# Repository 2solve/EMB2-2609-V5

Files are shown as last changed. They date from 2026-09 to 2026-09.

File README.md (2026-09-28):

# IC2S Extension Board EBM2 V5 — 6 entradas 4-20 mA

Placa de extensão da família IC2S (2Solve), código **IC2S-EBM2-2609-V5.0**. Seis entradas analógicas de 4-20 mA
para a Universal Baseboard; **substituição directa da EBM2 V4.1** (contorno 60 × 60 mm, furação e pinagem de
`P1`/`P2` congelados). Projecto em **KiCad 10**.

## Estado (2026-09-28)

| Fase | Estado |
|---|---|
| F0/F1 — escopo e planeamento | fechadas |
| F2 — esquemático, diagrama, BOM preliminar, mapa de pinos | **Portão 1 aprovado** (pacote congelado em `Portao1_aprovado_2026-09-25`) |
| F3 — layout | contorno e placement inicial feitos (DRC 0, paridade 0); falta o Portão 3 e o roteamento |

**Alteração posterior ao Portão 1 (2026-09-28)**, trazida da revisão da EBM7 V2.3: ramo único de 24 V (saem F1, D3 e
R3), 100 nF a 50 V fora do 24 V e um só MPN de 1 µF. Detalhe em
`Documentos_…/00-Especificações_Técnicas_…/alteracoes_reuniao_2026-09-28.md` e na folha 2, notas 3, 11, 13 e 14. Também a 28-09: **U5 MCP1824ST (SOT-223) → MCP1824T-3302E/OT (SOT-23-5)**, o mesmo MPN do U4; C10 (entrada) 1 µF → 10 µF 1206, o datasheet pede 1-10 µF
(`alteracao_LDO_3V3_lado_PLC_2026-09-28.md`). O
pacote congelado do Portão 1 não foi tocado; a BOM preliminar foi regenerada (42 linhas, 123 peças montadas).

## Organização (modelo de pastas de Produtos)

```
Desenvolvimento_IC2S-EBM2-2609-V5.0/
  Arquivos_Fabricação_IC2S-EBM2-2609-V5.0/
    00-Gerbers_…            (vazio até à F3)
    01-BOM_List_…           BOM preliminar (.md/.csv) e respostas cruas da API Mouser (2026-09-25)
    02-Pick-and-Place_…     (vazio até à F3)
    03-Stencil_…            (vazio até à F3)
  Documentos_IC2S-EBM2-2609-V5.0/
    00-Especificações_Técnicas_…   escopo, intenção, planeamento, relatórios, verificações da F2, Portão 1, F3
    01-Esquemáticos_…              PDF de revisão da F2 (esquemático + diagrama + mapa de pinos), PNG e SVG por folha
    02-Pinout_…                    mapa de pinos de P1/P2/U6/U7 e regras para o firmware
    03-Diagrama_Blocos_…           diagrama de blocos (SVG)
  Projeto_IC2S-EBM2-2609-V5.0/
    IC2S_Extension_Board-EBM2_V5.kicad_pro/.kicad_sch/.kicad_pcb e as 7 folhas
    symbols/, footprints/   bibliotecas próprias do projecto (sym-lib-table e fp-lib-table relativas)
    Ferramentas/            scripts Python de geração e verificação (ERC, netlist contra a intenção, BOM, PDF, F3)
    Documentos_de_Referência-IC2S-EBM2-2609-V5.0/   lista dos datasheets usados (nome e md5)
```

## O que não está neste repositório, e porquê

- **Datasheets dos fabricantes**: não se redistribuem num repositório público. `LISTA_datasheets.md` dá o nome e o
  md5 de cada ficheiro usado.
- Backups intermédios (`.antes_*`), netlists e relatórios ERC de passos intermédios, estado local do KiCad
  (`.kicad_prl`, `.history`).
- Ficheiros da V4.1 (Gerbers de origem usados para conferir o contorno): são de outro produto.

## Notas

- Os ficheiros KiCad mantêm o nome `IC2S_Extension_Board-EBM2_V5`: renomear o projecto partiria as instâncias
  dos símbolos nas folhas.
- Referências R1, R2… desde 2026-09-25; uma referência de três dígitos num documento é da numeração antiga
  (tabela em `tabela_correspondencia_refs_EBM2_V5.md`).
- Os scripts em `Ferramentas/` usam os caminhos locais de desenvolvimento (`C:\hw\hw-ebm2-v5`); a consulta à
  Mouser lê a chave de `MOUSER_API_KEY` e nunca a grava.

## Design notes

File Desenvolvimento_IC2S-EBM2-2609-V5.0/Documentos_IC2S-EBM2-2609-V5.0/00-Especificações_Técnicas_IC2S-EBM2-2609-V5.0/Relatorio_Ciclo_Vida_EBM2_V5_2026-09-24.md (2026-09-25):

# Ciclo de vida dos componentes — EBM2 V5

Data: 2026-09-24 · F2, antes da BOM preliminar · 30 MPN distintos no esquemático (mais 11
posições ainda sem MPN, que se fecham na BOM).

**Fontes, por ordem de uso:**
1. BOM da EBM7 V2.3 de 2026-09-14 (`bom_EBM7_V23_2026-09-14.csv`), com o estado da DigiKey e da
   Mouser: cobre 18 dos 30.
2. Páginas da DigiKey consultadas hoje: cobrem mais 11.
3. Datasheets dos fabricantes, para confirmar que os substitutos são equivalentes.

A ferramenta de stock do servidor KiCad (`jlcsearch`) **não serve para isto**. No controlo
positivo devolveu stock e preço do `LG Q396-PS-35`, que está obsoleto, sem dizer nada do ciclo
de vida.

## 1 · Obsoletos ou sem stock — substituídos

| Peça | Posições | Estado | Substituto | Porque este |
|---|---|---|---|---|
| `LG Q396-PS-35` (LED verde 0603) | `D203`, `D204`, `D630` | **Obsoleto** (DigiKey, última compra 2026-07-02; datasheet ams OSRAM v1.9 «Discontinued») | **`KG EELP41.22-PHRH-35-A8J8-20-R18`** | É o que a EBM7 V2.3 já adoptou (2026-09-15), com o brilho conferido pelo revisor (mínimo +16 % face ao Q396). Datasheet v1.4 de 2026-08-07: 0603, cátodo marcado, −40 a +105 °C, I_F mín. 0,5 mA (usamos ~1,4-1,5 mA). DigiKey «Active», 186 041 em stock. **Mesma pegada `0603LED`, mesmas resistências** |
| `GRM188R71E104KA01D` (100 nF X7R 25 V 0603) | `C401`, `C403`, `C500`, `C502`, `C601`-`C606`, `C700` (11) | **Obsoleto** (DigiKey: «Obsolete and no longer manufactured») | **`GRM188R72A104KA35D`** | Substituto indicado pela DigiKey: 100 nF X7R 0603, 100 V, −55 a +125 °C, «Active», 862 866 em stock. **Atenção:** o `GRM188R71H104KA93D` (50 V), a alternativa óbvia, **também está obsoleto** |
| `BAT46W-E3-08` (Vishay, SOD-123) | `D641`-`D646` | «Active», mas **0 em stock até 2027-01-11** | **`BAT46W-7-F`** (Diodes Inc.) | DS30044 rev. 20 (2023-11): 100 V, V_F máx. 0,25 V a 0,1 mA, 0,45 V a 10 mA e 1,0 V a 250 mA, SOD123 com banda de cátodo. **Os mesmos máximos do Vishay**, que fica como alternativa. DigiKey «Active», em stock |

Nenhuma das três substituições muda pegada, ligação nem valor eléctrico.

## 2 · Activos (verificado)

| MPN | Estado | Stock | Fonte |
|---|---|---|---|
| `TPS7A4001DGNR` | Activo | 1 901 D / 12 228 M | BOM EBM7 2026-09-14 |
| `SPX3819M5-L-3-3/TR` | Activo | — / 258 M | BOM EBM7 |
| `TL431BQDBZR` | Activo | — / 820 M | BOM EBM7 |
| `ISO7141CCDBQR` | Activo | **— / 0 M** | BOM EBM7 · **risco de abastecimento: sem stock na Mouser** |
| `MCP1824ST-3302E/DB` | Activo | 18 061 / 11 937 | BOM EBM7 |
| `MCP3208T-BI/SL` | Activo | 2 748 D | DigiKey 2026-09-24 |
| `AL5809-25P1-7` | Activo | 92 018 D | DigiKey 2026-09-24 |
| `BAV199LT1G` | Activo | 124 710 / 151 885 | BOM EBM7 |
| `MBR1H100SFT3G` | Activo | 453 867 D | DigiKey 2026-09-24 |
| `SMA6J33A-Q` | Activo | 15 395 / 11 149 | BOM EBM7 |
| `824520361` | Activo | **314 / 82** | BOM EBM7 · stock baixo (12 por placa) |
| `CC12H250MA-TR` | Activo | 4 159 D | DigiKey 2026-09-24 |
| `CC12H750MA-TR` | Activo | 6 448 / 5 070 | BOM EBM7 |
| `3413.0002.22` | Activo | 1 492 / 3 536 | BOM EBM7 |
| `BLM18PG471SN1D` | Activo | 575 844 / 164 993 | BOM EBM7 |
| `GRM32EC72A106ME05L` | Activo | 8 929 D | DigiKey 2026-09-24 |
| `ERA8AEB111V` | Activo | 8 398 D | DigiKey 2026-09-24 |
| `ERA3AEB5621V` | Activo | 19 939 D | DigiKey 2026-09-24 (prazo de fábrica 49 semanas) |
| `ERJ-3EKF1472V` | Activo | 49 140 D | DigiKey 2026-09-24 |
| `RC0603FR-072K2L`, `RC0603FR-073K3L`, `RC0603JR-070RL` | Activos | centenas de milhares | BOM EBM7 |
| `RC1206FR-07100RL` | Activo | 400 218 D | DigiKey 2026-09-24 |
| `NTCS0603E3103JLT` | Activo | 26 370 / 11 185 | BOM EBM7 |
| `M20-7822046`, `M20-7821446` | Activos | 2 598 / 1 297 e 815 / 566 | BOM EBM7 |

D = DigiKey, M = Mouser.

## 3 · Não fechado

- **`ADR4525BRZ`** (tubo): a DigiKey só mostrou explicitamente a versão em bobina
  **`ADR4525BRZ-R7`, «Active» e 0 em stock**; a página da Analog Devices deu erro de ligação duas
  vezes. **Estado do `ADR4525BRZ` por confirmar.** É peça única e crítica (a referência do ADC).
- **11 posições sem MPN** (`C200`, `C202`-`C208`, `C400`, `C402`, `C501`, `R201`-`R206`): fecham na
  BOM preliminar.
- Os números de stock são de datas diferentes e mudam: servem para avaliar risco, não como garantia.

## Fontes

- [DigiKey — KG EELP41.22-PHRH-35-A8J8-20-R18](https://www.digikey.com/en/products/detail/ams-osram-ag/KG-EELP41-22-PHRH-35-A8J8-20-R18/24765242)
- [ams OSRAM — KG EELP41.22 datasheet](https://look.ams-osram.com/m/6d0ff21a355ab5c9/original/KG-EELP41-22.pdf)
- [ams OSRAM — LG Q396 datasheet (Discontinued)](https://look.ams-osram.com/m/357e7fcde66d9629/original/LG-Q396.pdf)
- [Diodes Inc. — BAT46W datasheet DS30044](https://www.diodes.com/datasheet/download/BAT46W.pdf)
- [Vishay — BAT46W datasheet 86406](https://www.vishay.com/docs/86406/bat46w.pdf)
- Pesquisas DigiKey (2026-09-24): `GRM188R71E104KA01D`, `GRM188R71H104KA93D`, `GRM188R72A104KA35D`, `BAT46W-E3-08`, `BAT46W-7-F`, `AL5809-25P1-7`, `MCP3208T-BI/SL`, `MBR1H100SFT3G`, `CC12H250MA-TR`, `ERA-8AEB111V`, `ERA-3AEB5621V`, `ERJ-3EKF1472V`, `GRM32EC72A106ME05L`, `RC1206FR-07100RL`, `ADR4525BRZ-R7`.

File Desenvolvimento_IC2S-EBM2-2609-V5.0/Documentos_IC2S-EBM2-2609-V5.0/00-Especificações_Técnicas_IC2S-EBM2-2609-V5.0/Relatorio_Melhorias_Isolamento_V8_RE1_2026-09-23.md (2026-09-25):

# Melhorias propostas — isolamento, transmissor em curto (V8) e exactidão (RE1)

EBM2 V5 · 2026-09-23 · F2, antes do Portão 1

Contas reproduzíveis em `ferramentas/avalia_opcoes_V8_RE1.py`: cada número tem a fonte escrita
no próprio script, e as estimativas estão marcadas. **Nada disto foi medido**: são cálculos
sobre datasheets, a confirmar nas etapas 2.3b e na bancada.

---

## Adenda — envolvente de alimentação corrigido para 18–32 V (mesmo dia)

Os números deste relatório foram calculados com 20–28 V. O painel alimenta-se de rede,
bateria ou painel solar (decisão de 2026-08-31, `escopo_EBM7_respin.md` §7), e o `RA1`
passou a **18–32 V**. Com isso, na rev. 2.2 da intenção: TVS de canal `824520361` (36 V),
`R206` 33 Ω (margem de arranque 12,3× a 32 V) e série `R60x` 100 Ω. Valores actuais, de
`ferramentas/avalia_opcoes_V8_RE1.py`: a **18 V** o transmissor recebe **≥ 10,5 V**; em curto
a **32 V** o limitador dissipa **0,67 W** (Tj ≈ 140 °C com cobre alargado). **A opção 2 da
§2 (5 V / 4,096 V / 180 Ω) deixa só 9,1 V ao transmissor a 18 V e perde interesse.**

## 0 · Duas correcções antes de começar

Ao preparar esta análise encontrei dois erros em documentos que eu próprio escrevi.

1. **A `V8` não é uma regressão face à V4.1.** A intenção diz que os conversores isolados
   da V4.1 limitavam a corrente. O datasheet do `PDM2-S24-S24-S` (CUI, rev. 07/2024) diz
   o contrário: «short circuit protection: **1 s**», «the supply voltage must be discontinued
   at the end of the short circuit duration» e «the output circuit of this product has **no
   protection against overload**». Um transmissor em curto na V4.1 fazia passar ~65 mA
   (83 mA é a corrente nominal do conversor) e punha ~1,1 W numa resistência de 249 Ω 0603.
   **O defeito é herdado**; a V5 apenas o agrava um pouco (74 mA a 28 V, 1,4 W).
2. **Os seis laços da V4.1 não eram dois grupos flutuantes.** Na netlist da V4.1, as saídas
   de 0 V de `U1` e `U8` ligam as duas ao mesmo `GND_ADC`. Havia **um** domínio de campo,
   isolado do 24 V e alimentado por dois conversores. O que a V5 perde é esse isolamento
   entre o campo e a fonte de 24 V, e não um isolamento entre grupos.

Mais dois factos da V4.1 que pesam na decisão:
- o `PDM2-S24-S24-S` está **descontinuado** (histórico de revisões do datasheet, 06/2023);
- a entrada dele aceita **21,6 a 26,4 V**, e o `RA1` pede 20 a 28 V. A V4.1 já estava fora
  de especificação nos dois extremos.

---

## 1 · Transmissor em curto (`V8`) — **recomendação: limitador de corrente por canal**

### O problema, em números (28 V, máximo do `RA1`)

| | Corrente | Na série 249 Ω (0603, 0,1 W) | No burden (0603, 0,1 W) |
|---|---|---|---|
| V4.1 | 65,5 mA | 1,07 W | 0,69 W |
| V5 actual | 74,4 mA | **1,38 W** | **0,61 W** |

Nenhum fusível resolve: um fusível que conduz 22 mA em regime não abre de forma fiável a
65-75 mA. O de 50 mA actual só abre num curto franco à massa, que dá ~2,5 A. Um PTC também
não serve: os mais pequenos seguram 50 mA e disparam acima de 100 mA.

### A solução: um regulador de corrente de dois terminais, em série no retorno de cada canal

```
P2 AINk- --+-- [TVS D60x a GND_ADC] --+-- AL5809-25 (In→Out) --+-- R60x --+-- R61x (burden) -- GND_ADC
                                      |                        |          |
                                      +--|<|-- Schottky -------+          +-- 3,3 kΩ -- ADC
                                          (antiparalelo, protege o -0,3 V do AL5809)
```

- **Peça:** `AL5809-25P1-7` (Diodes, PowerDI123). Garante **23,75 a 26,25 mA de −40 a
  +125 °C**, aguenta 2,5 a 60 V (80 V de máximo absoluto) e tem θJA de 81,4 °C/W com cobre
  alargado (DS36625 rev. 5, pág. 4).
- **Porquê 25 mA:** o conversor satura a 22,7 mA, portanto não se perde nenhuma leitura. O
  alarme alto de 21 mA da NAMUR NE43 lê-se.
- **Porquê no retorno e não no `+`:** em série com o burden **não mexe na medida**, porque
  a corrente é a mesma. No retorno, um curto do `+` à massa não passa por ele: o fusível de
  50 mA abre como hoje. No `+`, esse curto punha os 24 V inteiros no limitador (0,6 W sem
  resistências a partilhar) e o fusível nunca abria. Assim fica também **explicada a razão
  do fusível de 50 mA**, que faltava escrever: abre no curto franco; o curto do transmissor
  é trabalho do limitador.
- **Schottky em antiparalelo:** o AL5809 só aguenta −0,3 V em inversão. Com o TVS
  unidireccional, o terminal pode ir a −0,7/−1 V. O díodo em paralelo não altera a medida
  (liga os mesmos dois nós). **Escolhido: `BAT46W-E3-08`** (Vishay 86406: 100 V; V_F máx.
  0,25 V a 0,1 mA e 0,45 V a 10 mA). A ~3 mA de falha inversa ficam ~0,40 V, acima dos
  −0,3 V do AL5809: **resíduo a confirmar na 2.3b**, com corrente de µA na junção interna.
- **A série de 249 Ω passa a 150 Ω em 1206.** Com o limitador, a função de protecção dela
  deixa de ser essencial, e a queda que sobra compensa a do limitador (ver tabela). O burden
  passa a 1206 (`ERA8AEB111V`: mesma família e tolerância, 47 Ω a 330 kΩ).

### Resultado calculado

| | Corrente de curto | P no limitador | Tj a 85 °C | P série / burden | Tensão para o transmissor (20 V, 20 mA) |
|---|---|---|---|---|---|
| V5 actual | 74,4 mA | — | — | 1,38 / 0,61 W ✗ | 12,04 V |
| **Proposta (A25)** | **26,2 mA** | 0,53 W | **128 °C** | 0,10 / 0,08 W ✓ | **11,52 V** |
| V4.1, para comparar | 65,5 mA | — | — | 1,07 / 0,69 W ✗ | 11,04 V |

**Ressalvas honestas:**
- 128 °C é o pior caso de tudo junto: 85 °C ambiente, 28 V e curto permanente. Fica abaixo
  dos 175 °C absolutos, mas acima dos 125 °C recomendados. Na F3 é preciso cobre (4 camadas,
  vias térmicas) para baixar o θJA para ≤ 75 °C/W.
- A queda do limitador a 20 mA usa o limite conservador de 2,5 V, o mínimo de regulação. O
  valor real a 20 mA, abaixo da corrente de regulação, deve ser menor e está por ler na curva
  ou medir.
- **O escopo não define a tensão mínima que os transmissores precisam.** É um gap. Os
  11,5 V ficam acima da V4.1, mas é preciso saber que transmissores estão instalados.
- Custo: 6 × (limitador + Schottky), ~12 peças pequenas. Não muda `P2` nem o firmware.

**Estudo completo do datasheet (DS36625 rev. 5-2, 16 págs., md5 7e46a75cc76e), 2026-09-23:**
- *Queda a 20 mA* — fig. 15 (25 °C): não conduz abaixo de ~1,4 V; a 20 mA fica em
  ~1,6-1,7 V. As contas usam 2,5 V (mínimo recomendado, págs. 4 e 5) porque a fig. 15 é
  só típica e só a 25 °C. A margem real para o transmissor deve ser ~0,8 V melhor.
- *Corrente em curto* — a tabela garante 23,75-26,25 mA a V_InOut = 3,5 V; a fig. 17
  mostra +1,5 a +2 % a 20 V. Máximo prático em curto ≈ **26,8 mA** (0,08 W no burden e
  0,11 W na série de 150 Ω: dentro de 1206).
- *Térmica* — o calor sai **pela ilha do pino OUT** (pág. 8: «additional vias between the
  pad of the OUT pin»), e `OUT` é a rede `AINk_LIM`, não a massa. Com a ilha mínima e
  10 × 10 mm de cobre (nota 4, θJA 148,6 °C/W), o pior caso (85 °C, 28 V, curto
  permanente, ~0,55 W) daria Tj ≈ 167 °C e o **corte térmico (165 °C, histerese 30 °C,
  fig. 18) entraria em ciclo**. Com cobre alargado (nota 5, 81,4 °C/W), Tj ≈ 130 °C. A
  fig. 10 (placa FR4 de 2 camadas) admite ~30 V a 85 °C para a versão de 25 mA, contra
  os ~20,8 V do nosso curto. **Na F3: cobre e vias na ilha OUT de cada U60x.** Mesmo com
  cobre insuficiente, a peça protege-se: corta, a leitura cai a 0 mA e recupera.
- As figuras térmicas do datasheet não são coerentes entre si (a fig. 10 a 25 °C pede
  1,25 W, mais do que a fig. 9 dá para FR4). Usa-se o caso pior e mede-se na bancada.
- Dois reguladores de corrente em série (o transmissor e o AL5809): abaixo de 23,75 mA
  o AL5809 está fora de regulação e não interage. Perto dos 24 mA os dois tentam
  regular; o ADC já saturou a 22,7 mA. **Ensaio de bancada:** transmissor forçado a
  alarme alto, a ver se há oscilação.

**Alternativa estudada e descartada:** o `NSI45030AZ` (onsemi) tem menos queda, mas a sua
corrente só está garantida a 25 °C (27-33 mA) e, no mesmo pior caso, chega a **152 °C
contra 150 °C de máximo**.

---

## 2 · Exactidão (`RE1`) — **recomendação: confirmar primeiro a rotina de calibração**

### O ponto de partida

| | Pior caso, constante comum |
|---|---|
| V4.1 | **1,43 %** (referência = LDO ±1 %, burden ±1 %, conversor grau -C) |
| V5 actual | **0,237 %** — seis vezes melhor, mas acima dos 0,2 % |

Na V5 domina o conversor: ganho 0,122 %, offset 0,166 %, INL 0,055 %.

### Opção 1 — a rotina de calibração do `RC4` (custo zero de hardware)

O próprio `RC4` diz: «a alteração de escala é absorvida pela **rotina de calibração
existente, executando a calibração de cada canal após a troca**». Duas consequências:

1. **A V5 já depende dessa rotina**, porque muda a escala face à V4.1 (burden de 160 para
   110 Ω, referência de 3,3 para 2,5 V). Sem ela, o firmware actual lê valores errados.
2. **Se a rotina calibra cada canal com uma corrente conhecida na instalação, o offset e o
   ganho desaparecem e o `RE1` fica em 0,055 %** (só o INL), com folga de 3,6×.

**Pergunta a fazer ao firmware:** a rotina mede cada canal contra correntes conhecidas, ou
só aplica um factor introduzido à mão? A resposta decide esta secção inteira.

### Opção 2 — subir o fundo de escala, mantendo o MCP3208 e o protocolo

`VDD` do conversor a 5 V (`+5V_ADC`, que já existe, 4,974 V), referência `ADR4540` de
4,096 V, e burden de 180 Ω.

| | V5 actual | Opção 2 |
|---|---|---|
| Fundo de escala a 20 mA | 2,200 V | 3,600 V |
| Offset (tensão fixa) | 0,166 % | 0,102 % |
| INL | 0,055 % | 0,034 % |
| **Pior caso** | **0,237 %** | **0,192 %** ✓ |
| Saturação | 22,7 mA | 22,8 mA |
| Resolução | 5,55 µA/LSB | 5,56 µA/LSB (igual) |
| Tensão para o transmissor (com o limitador da §1, série 100 Ω) | 11,52 V | 11,12 V |

**Correcção ao planejamento:** este cenário aparece lá como «0,201 %, reprova na mesma».
Esse cálculo usou o INL do grau **-C** (±2 LSB) num cenário que devia ser do grau -B. Com o
grau -B dá **0,192 %: passa**. A frase «não existe escolha de componente que feche `RE1`»
estava duplamente errada.

**Mas a margem é de 4 %**, e o custo é real:
- o `VDD` do ADC e o `VCC2` do isolador passam para `+5V_ADC`;
- os clamps `BAV199` têm de ir para um trilho acima de 4,1 V, com sumidouro (hoje o `TL431`
  grampeia `3V3_REF` a 3,6 V e começaria a cortar o sinal perto do fundo de escala);
- o `SPX3819` e o `3V3_REF` podem deixar de ser precisos;
- a folha 03 é refeita e o `+5V_ADC` precisa de margem para os 4,6 V que o `ADR4540` pede
  (4,974 V dá 0,37 V de folga);
- o divisor do NTC continua ratiométrico: o código lido não muda.

É uma opção sólida **só se a Opção 1 falhar**.

### Opção 3 — `AD7124-8` (o conversor da EBM7)

Cerca de 0,10 % no pior caso, com o burden a dominar, e ainda rejeição de 50/60 Hz e
diagnóstico de fio aberto. **Parte o `RC4`**: outro protocolo, firmware novo.

### Opção 4 — escopo

Declarar os 0,2 % como típico (0,139 %) e registar o pior caso.

---

## 3 · Isolamento — **recomendação: manter a decisão RI1-RI3, com duas salvaguardas baratas**

### O que se perdeu de facto

Na V4.1, o campo inteiro (`GND_ADC`) estava isolado da fonte de 24 V. Na V5, `GND_ADC` liga a
`GND_24V` pelo `R200`. A barreira com a Raspberry continua real: foi verificado que na
MainBoard `GND` e `GND_24V` são redes distintas.

**Quando isto importa:** só com fontes de campo ligadas à terra noutro ponto, tipicamente
transmissores de 4 fios com saída não isolada. Um transmissor de 2 fios alimentado pela placa
é flutuante e não cria laço de massa.

### Opções

| | O que é | Custo | Risco que resolve |
|---|---|---|---|
| **A (recomendada)** | Manter. Escrever no manual: 2 fios, ou 4 fios com saída isolada | Zero | Resolve por regra de instalação |
| A+ | A, mais uma **variante de montagem**: pegada para um módulo isolado e o `R200` como 0 Ω removível | Área de placa; o `RC1` fixa o contorno, mas a V4.1 cabia com três conversores | Permite isolar sem novo layout, se o campo o pedir |
| B | Um conversor isolado **regulado**, entrada 2:1 (cobre 20-28 V), saída 24 V, ≥ 5 W, a alimentar todo o campo; tirar o `R200` | Módulo, eficiência, EMI; o `RA5` (≤ 200 mA) fica justo a 20 V (~190 mA calculados); refazer o arranque e os fusíveis; revisão do RI1-RI3 no Portão 0 | Devolve o nível da V4.1, e com a gama de entrada certa |

**Pergunta a fazer ao campo:** há, nas instalações, transmissores de 4 fios com saída ligada
à terra? Se não houver, A basta. Se houver ou não se souber, A+ é o seguro barato.

---

## 4 · Resumo e ordem sugerida

| # | Acção | Custo | Efeito |
|---|---|---|---|
| 1 | Perguntar ao firmware como funciona a rotina de calibração do `RC4` | Zero | Pode fechar o `RE1` sem hardware |
| 2 | Limitador `AL5809-25` + Schottky por canal; série 150 Ω e burden em 1206 | ~12 peças pequenas | Fecha a `V8` |
| 3 | Perguntar ao campo pelos transmissores de 4 fios e pela tensão mínima deles | Zero | Decide o isolamento e fecha o gap de conformidade |
| 4 | Só se o 1 falhar: 5 V / 4,096 V / 180 Ω | Refazer a folha 03 | `RE1` 0,192 %, margem de 4 % |
| 5 | Só se o 3 o pedir: variante A+ ou opção B | Área / módulo | Isolamento campo ↔ 24 V |

## Fontes

- [CUI PDM2-S datasheet, rev. 07/22/2024](https://www.belfuse.com/media/datasheets/products/power-supplies/PDM2-S.pdf) — protecção de curto de 1 s, sem protecção de sobrecarga, entrada 21,6-26,4 V, modelo descontinuado.
- [Diodes AL5809, DS36625 rev. 5](https://www.diodes.com/assets/Datasheets/AL5809.pdf) — corrente sobre temperatura, 2,5-60 V, θJA, −0,3 V.
- [onsemi NSI45030AZ, rev. 3](https://www.onsemi.com/pdf/datasheet/nsi45030az-d.pdf) — 27-33 mA a 25 °C, 45 V, θJA.
- Microchip DS21298E (MCP3208), pág. 2 e figuras 2-2, 2-15 e 2-18 — na pasta de referência.
- Panasonic AOA0000C307, pág. 2 — gama do `ERA-xAEB`, conforme o planejamento §2.5.
- Netlist da V4.1, exportada em modo só leitura de `C:\hw\hw-ebm2-v4.1`.

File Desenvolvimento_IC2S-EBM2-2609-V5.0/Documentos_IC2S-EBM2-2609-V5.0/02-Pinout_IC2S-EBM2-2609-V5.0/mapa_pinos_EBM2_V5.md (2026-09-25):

# Mapa de pinos — EBM2 V5 (F2, etapa 2.4)

| | |
|---|---|
| Esquemático | intenção **rev. 2.5c**, netlist `EBM2_V5_P1R_final.net` |
| Gerado por | `ferramentas/gera_mapa_pinos.py` — a rede de cada pino **lê-se da netlist**; se discordar da intenção (§4, §8) o script recusa escrever |
| Datasheets | MCP3208 `DS21298E` (Microchip 2008); ISO7141CC `SLLSE83F` rev. F (TI 2015); pastas `Documentos/verificacao_2_3b_rev25/datasheets/` |
| Cruzamento com a 2.3 | Os pinos coincidem com `verificacao_2_3/verificacao_pinagem_EBM2_V5.md` (revisão humana, 16 grupos, sem divergências) |

Âmbito: os componentes de alta pinagem e as interfaces — conversor, isolador e os dois conectores. É também a
base do handoff de firmware (secção final).

## `U7` — MCP3208T-BI/SL — conversor 12 bits, SPI

| Pino | Rede (netlist) | Função | Direcção | Nível activo | Timing / observações |
|---|---|---|---|---|---|
| 1 | `AIN1_ADC` | CH0 — laço 1 (`P2.2`/`P2.3`) | entrada analógica | — | 0 a VREF = 2,5 V; 4 mA = 721, 20 mA = 3604, 22,7 mA = 4095 (110 Ω). Série `R28` 4k7 (rev. 2.5) |
| 2 | `AIN2_ADC` | CH1 — laço 2 | entrada analógica | — | idem, `R29` |
| 3 | `AIN3_ADC` | CH2 — laço 3 | entrada analógica | — | idem, `R30` |
| 4 | `AIN4_ADC` | CH3 — laço 4 | entrada analógica | — | idem, `R31` |
| 5 | `NTC_ADC` | CH4 — termístor da placa | entrada analógica | — | **Não lido pelo software actual** (Rodrigo 2026-09-24). Divisor de `+2V5_REF`, `C35` 100 nF no pino |
| 6 | `3V3_REF` | CH5 — preso ao trilho | entrada analógica | — | Lê sempre 4095 (3,3 V > VREF). Mapa congelado (`RC4`); não lido |
| 7 | `AIN5_ADC` | CH6 — laço 5 | entrada analógica | — | idem, `R32`. **O mapa não é sequencial**: laço 5 = CH6 |
| 8 | `AIN6_ADC` | CH7 — laço 6 | entrada analógica | — | idem, `R33` |
| 9 | `GND_ADC` | DGND | massa | — | Massa de campo |
| 10 | `CS_ADC_ISO` | ~CS/SHDN | entrada digital | **baixo** | Descida → 1.º flanco de subida de CLK ≥ 100 ns (t_SUCS); alto entre conversões ≥ 500 ns (t_CSH). Com CS alto, DOUT em alta impedância (DS21298E pág. 3) |
| 11 | `MOSI_ADC_ISO` | DIN | entrada digital | — | Bit de início (1.º «1» com CS baixo), SGL/DIFF, D2 D1 D0 (§5, pág. 19). Setup/hold ≥ 50 ns |
| 12 | `MISO_ADC_ISO` | DOUT | saída digital | — | Válido ≤ 200 ns após a descida de CLK (t_DO); bit nulo e depois B11…B0, MSB primeiro (pág. 20) |
| 13 | `CLK_ADC_ISO` | CLK | entrada digital | — | **≤ 1 MHz** (garantido a 2,7 V; 2 MHz só a 5 V, pág. 3). **≥ 10 kHz efectivos** (nota 3 pág. 3, §6.2). Real: 20 kHz. Modo SPI 0,0 ou 1,1 (§6.1, pág. 21). Amostra 1,5 ciclos a partir do 4.º flanco após o início (pág. 17) |
| 14 | `GND_ADC` | AGND | massa | — | Percurso próprio no layout, junto ao `DGND` |
| 15 | `+2V5_REF` | VREF | alimentação (referência) | — | ADR4525 2,5 V; `C14` 100 nF no pino, `C5` 2,2 µF na saída do ADR |
| 16 | `VDD_ADC` | VDD | alimentação | — | 3,3 V de `3V3_REF` pela ferrite `FB2`; `C15` 1 µF + `C16` 100 nF |

## `U6` — ISO7141CCDBQR — isolador digital 4 canais (3 → campo, 1 → barramento)

| Pino | Rede (netlist) | Função | Direcção | Nível activo | Timing / observações |
|---|---|---|---|---|---|
| 1 | `+3.3V_DIG` | VCC1 | alimentação | — | Lado do barramento, 3,3 V do `U5` MCP1824S (fecha o gap G2: MISO a 3,3 V para a Pi) |
| 2 | `DGND` | GND1 | massa | — | Massa do barramento |
| 3 | `MOSI` | INA → OUTA (pino 14) | entrada digital | — | Entradas TTL, toleram 5 V a VCC 3,3 V (SLLSE83F pág. 1). Atraso 15-45 ns a 3,3 V (§6.10, pág. 8) |
| 4 | `CLK` | INB → OUTB (pino 13) | entrada digital | — | idem |
| 5 | `CS_ADC` | INC → OUTC (pino 12) | entrada digital | **baixo** (atravessa sem inversão) | Entrada aberta ou lado 1 sem alimentação → OUTC **alto** (versão CC, tabela 3, pág. 19): o ADC fica desseleccionado |
| 6 | `MISO` | OUTD ← IND (pino 11) | saída digital | — | **Sempre activa** (EN1 fixo em VCC1, como na V4.1 e na EBM7 Legacy). Com o ADC desseleccionado, IND fica em alta impedância e OUTD vai a **alto** (tabela 3). Se o MISO da base board for partilhado com outro escravo SPI, há contenção: confirmar na cablagem (`V14`) |
| 7 | `+3.3V_DIG` | EN1 | entrada (fixa) | alto = activo | Fixo: OUTD nunca vai a alta impedância |
| 8 | `DGND` | GND1 | massa | — |  |
| 9 | `GND_ADC` | GND2 | massa | — | Massa de campo |
| 10 | `VCC2_ISO` | EN2 | entrada (fixa) | alto = activo | Fixo em VCC2: OUTA/B/C sempre activas |
| 11 | `MISO_ADC_ISO` | IND | entrada digital | — | De DOUT do `U7` |
| 12 | `CS_ADC_ISO` | OUTC | saída digital | baixo = ADC seleccionado | Para ~CS do `U7` |
| 13 | `CLK_ADC_ISO` | OUTB | saída digital | — | Para CLK do `U7` |
| 14 | `MOSI_ADC_ISO` | OUTA | saída digital | — | Para DIN do `U7` |
| 15 | `GND_ADC` | GND2 | massa | — |  |
| 16 | `VCC2_ISO` | VCC2 | alimentação | — | 3,3 V de `3V3_REF` pela ferrite `FB1`, `C13` 100 nF |

## `P1` — Harwin M20-7822046 — barramento para a base board (pinagem congelada, `RC2`)

| Pino | Rede (netlist) | Função | Direcção | Nível activo | Timing / observações |
|---|---|---|---|---|---|
| 1 | sem ligação | USB1 do barramento | NC | — | Não usado |
| 2 | sem ligação | USB2 do barramento | NC | — | Não usado |
| 3 | `DGND` | GND do barramento (GNDI na base board V2.3) | massa | — | O SPI na MainBoard vai referido a GNDI_3V3: união fora da placa (`V14`) |
| 4 | `MOSI` | MOSI | entrada digital | — | Da Raspberry Pi (mestre), 3,3 V |
| 5 | `CLK` | SCLK | entrada digital | — | 20 kHz no software actual |
| 6 | `MISO` | MISO | saída digital | — | 3,3 V; sempre accionada pelo isolador (ver `U6.6`) |
| 7 | sem ligação | CS_DAC | NC | — | Não há DAC nesta placa |
| 8 | sem ligação | LDAC_DAC | NC | — |  |
| 9 | `CS_ADC` | CS_ADC | entrada digital | **baixo** | Na base board V2.3 o P19.9 não tem cobre: chega por fio no painel (achado da EBM7) |
| 10 | sem ligação | CS4 | NC | — |  |
| 11 | sem ligação | ID1 | NC — **tem de continuar assim** | — | Provável identidade da placa perante a base board [EST]: copiado da V4.1 |
| 12 | `DGND` | GND | massa | — |  |
| 13 | sem ligação | ID3 | NC — **tem de continuar assim** | — | idem |
| 14 | sem ligação | SDA | NC | — |  |
| 15 | sem ligação | SCL | NC | — |  |
| 16 | `DGND` | GND | massa | — |  |
| 17 | `+5V` | +5V do barramento (+5V_IC) | alimentação | — | Para o `U5`. Na base board: borne P21 com TVS D53 (grampo 9,2 V) contra 6,5 V abs. max do MCP1824: **`V13` aberta** |
| 18 | sem ligação | — | NC | — | Não existe na V4.1 |
| 19 | `GND_24V` | 0 V do painel | massa | — | Unido a `GND_ADC` só por `R2` (net-tie). Sem cobre na base board: por fio |
| 20 | `+24V` | 18-32 V do painel | alimentação | — | Rede, bateria ou solar (`RA1`). D2 SMA6J33A-Q na entrada. Por fio |

## `P2` — Harwin M20-7821446 — campo, 6 laços 4-20 mA (pinagem congelada, `RC2`)

| Pino | Rede (netlist) | Função | Direcção | Nível activo | Timing / observações |
|---|---|---|---|---|---|
| 1 | sem ligação | — | NC | — | Como na V4.1 |
| 2 | `LOOP1_V+` | Alimentação do laço 1 | saída (alimentação) | — | `+24V_ADC` → `F3` 50 mA → pino; TVS `D12` 36 V no pino |
| 3 | `AIN1-` | Retorno do laço 1 | entrada (corrente) | — | → `U8` TPS26613 (IN) → burden 110 Ω. TVS `D6` 33 V. Em curto: 25-40 mA 100 ms, corta 800 ms (leitura alterna 4095 / ~0) |
| 4 | `LOOP2_V+` | Alimentação do laço 2 | saída (alimentação) | — | `+24V_ADC` → `F4` 50 mA → pino; TVS `D13` 36 V no pino |
| 5 | `AIN2-` | Retorno do laço 2 | entrada (corrente) | — | → `U9` TPS26613 (IN) → burden 110 Ω. TVS `D7` 33 V. Em curto: 25-40 mA 100 ms, corta 800 ms (leitura alterna 4095 / ~0) |
| 6 | `LOOP3_V+` | Alimentação do laço 3 | saída (alimentação) | — | `+24V_ADC` → `F5` 50 mA → pino; TVS `D14` 36 V no pino |
| 7 | `AIN3-` | Retorno do laço 3 | entrada (corrente) | — | → `U10` TPS26613 (IN) → burden 110 Ω. TVS `D8` 33 V. Em curto: 25-40 mA 100 ms, corta 800 ms (leitura alterna 4095 / ~0) |
| 8 | `LOOP4_V+` | Alimentação do laço 4 | saída (alimentação) | — | `+24V_ADC` → `F6` 50 mA → pino; TVS `D15` 36 V no pino |
| 9 | `AIN4-` | Retorno do laço 4 | entrada (corrente) | — | → `U11` TPS26613 (IN) → burden 110 Ω. TVS `D9` 33 V. Em curto: 25-40 mA 100 ms, corta 800 ms (leitura alterna 4095 / ~0) |
| 10 | `LOOP5_V+` | Alimentação do laço 5 | saída (alimentação) | — | `+24V_ADC` → `F7` 50 mA → pino; TVS `D16` 36 V no pino |
| 11 | `AIN5-` | Retorno do laço 5 | entrada (corrente) | — | → `U12` TPS26613 (IN) → burden 110 Ω. TVS `D10` 33 V. Em curto: 25-40 mA 100 ms, corta 800 ms (leitura alterna 4095 / ~0) |
| 12 | `LOOP6_V+` | Alimentação do laço 6 | saída (alimentação) | — | `+24V_ADC` → `F8` 50 mA → pino; TVS `D17` 36 V no pino |
| 13 | `AIN6-` | Retorno do laço 6 | entrada (corrente) | — | → `U13` TPS26613 (IN) → burden 110 Ω. TVS `D11` 33 V. Em curto: 25-40 mA 100 ms, corta 800 ms (leitura alterna 4095 / ~0) |
| 14 | `GND_ADC` | 0 V de campo | massa | — | Para transmissores de 4 fios / blindagem |

## Para o firmware (DeviceManager, `extensions/EBM2.js`)

| Tema | Regra | Fonte |
|---|---|---|
| Mapa de canais | Laço 1-4 = CH0-CH3; **laço 5 = CH6, laço 6 = CH7**; CH4 = NTC; CH5 = 4095 fixo | `U7` pinos 1-8; `RC4` |
| Escala | 12 bits sobre VREF 2,5 V e burden 110 Ω: **1 LSB = 5,55 µA**; 4 mA = 721; 20 mA = 3604; satura a 22,7 mA | intenção §8-§9 |
| Relógio SPI | **10 kHz ≤ f ≤ 1 MHz** (real: 20 kHz). Pela barreira: 45 ns por sentido (`U6`), 90 ns ida e volta mais t_DO 200 ns; folgado até 1 MHz | DS21298E pág. 3; SLLSE83F pág. 8 |
| Trama | 24 bits **atómicos** por canal (bit de início, SGL/DIFF, D2 D1 D0, bit nulo, B11…B0); CS alto ≥ 500 ns entre tramas | DS21298E págs. 19-20 |
| Curto do transmissor | A leitura **alterna** ~100 ms a 4095 e ~800 ms a ~0 mA (`"null"`). Com a média de 10 amostras / 500 ms vê-se sobretudo `"null"`: **`"null"` intermitente com picos a 4095 = curto, não laço aberto** | TPS26613 SLVSFE3C tabela 8-3 |
| Alarme NAMUR | ≥ 21 mA lê-se (código ≥ 3784) antes da saturação | NE43 |
| Troca de placa | **Recalibrar os seis canais ao instalar** (a V4.1 lia com outra escala: −9,3 %) | escopo `RC4` |
| MISO | Sempre accionado pelo isolador, nunca em alta impedância: não partilhar a linha com outro escravo SPI sem confirmar a cablagem | `U6.6`; `V14` |

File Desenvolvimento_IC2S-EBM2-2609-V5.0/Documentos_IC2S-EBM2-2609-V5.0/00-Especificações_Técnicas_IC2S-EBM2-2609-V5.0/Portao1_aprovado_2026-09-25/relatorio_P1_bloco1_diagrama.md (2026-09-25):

# Portão 1 — verificação independente do BLOCO 1 (diagrama de blocos), EBM2 V5

| | |
|---|---|
| Âmbito | Só o diagrama de blocos (`diagrama_blocos_EBM2_V5.svg`, também pág. 9 do `EBM2_V5_F2_revisao_2026-09-25.pdf`) contra `EBM2_V5.net` e `intencao_EBM2_V5.md` |
| Autor do material | Outro modelo (Claude Opus 5.5) |
| Verificador | Independente, sem participação no F2 |
| Método | SVG e PDF pág. 9 renderizados com PyMuPDF (`fitz`) a 2×, comparados pixel a pixel (idênticos); todo o texto do SVG lido como XML; cada afirmação do diagrama confrontada com `EBM2_V5.net` (grep por `ref`/`net`/`name`) |

## Veredicto do bloco: **APROVADO COM RESSALVAS**

Todas as afirmações verificáveis do diagrama (peças principais, valores, trilhos,
mapa de canais, barreira) batem com a netlist actual, incluindo os valores da
revisão mais recente do próprio dia (2.5c: `R206` 150 Ω, `R204` 4k12). Não há
nada desactualizado nem nenhuma peça ou rede inventada. As ressalvas são de
clareza de rótulo, não de erro eléctrico.

## Achados

| # | Onde | Achado | Evidência | Severidade |
|---|---|---|---|---|
| 1 | Caixas "Alimentacao" e "Seis lacos" | Os rótulos internos usam a tensão genérica ("24 V", "5 V") em vez do nome de rede exacto na entrada de cada regulador | `U200` (`TPS7A4001`, caixa "Alimentacao"): pinos `IN`/`EN` estão na rede `+24V_REG`, não `+24V` (net code 8, `EBM2_V5.net` ~L10413). `U201` (`MCP1824`, mesma caixa): pino `VIN` está em `+5V_ADC`, não `+5V` (net code 4, ~L10137). `U640` (`TPS7A4001`, caixa "Seis lacos", rótulo "+12V_TPS: U640 TPS7A4001 24->12V"): pinos `IN`/`EN` estão em `+24V_ADC`, não `+24V` (net code 7, ~L10336, confirmado nós `U640` pino 5 `EN` e pino 8 `IN`) | Média — é exactamente a confusão que `intencao_EBM2_V5.md` §1.2 já registou como incidente real ("se a folha 01 tivesse um porto `+5V`, as duas redes fundiam-se e a barreira ficava anulada sem mensagem de erro nenhuma"). A netlist em si está correcta (nets `+5V`/`+5V_ADC`/`+24V`/`+24V_ADC`/`+24V_REG` confirmadas distintas, sem merge), mas um diagrama que volta a escrever o rótulo curto reintroduz o mesmo risco de leitura para quem só vê o diagrama |
| 2 | Caixa "P1 Baseboard" e "P2 Campo" | Etiqueta de folha diz "conn" em vez de "01" (a folha 1 é "1 Conectores" na netlist, `Sheetfile` `01_conectores.kicad_sch`, confirmada para `P1`/`P2`) | `EBM2_V5.net`, propriedade `Sheetname`="1 Conectores" nos `comp` de `P1`/`P2` | Baixa — cosmético; inconsistente com a convenção numérica usada nas outras seis caixas (02-07), mas não induz em erro sobre a topologia |
| 3 | Caixa "Seis lacos" | A topologia por canal mostrada ("TVS 33V → TPS26613 → burden 110Ω → 3,3k+100nF → BAV199 → 4,7k") omite o fusível de canal `F60x`, o TVS de trilho `D611`-`D616` (36 V, `SMBJ36A`, no `LOOPk_V+`) e a ilha `R601` (0 Ω) | `intencao_EBM2_V5.md` §9; `EBM2_V5.net` confirma `F601`.. `D611`.. `R601` existentes nas folhas 06, não representados na caixa | Informativo — simplificação aceitável para um diagrama de blocos (o objectivo declarado do diagrama é o fluxo de sinal, não o esquemático completo); não é tratado como defeito |

## O que foi confirmado correcto (evidência)

- **Peças principais**: `U200`/`U640` = `TPS7A4001DGN`; `U201` = `MCP1824T-3302E/OT`; `U202` = `ADR4525WBRZ-R7`; `U203` = `TL431B` (MPN `TL431BQDBZR`); `U400` = `ISO7141CCDBQR`; `U401` = `MCP1824ST-3302E/DB`; `U500` = `MCP3208T-BI/SL`; `U601`-`U606` = `TPS26613DDFR`; `R206` = 150 Ω; TVS de retorno = `SMA6J33A-Q` (entrada) e `SMBJ33A` de 33 V nos laços — todos conferidos por grep directo na netlist.
- **Barreira**: confirmado por varrimento da netlist (nets `DGND` × `GND_ADC`) que **só `U400`** tem pinos nas duas redes de massa — nenhum outro componente atravessa. Bate com o texto do diagrama e com a regra do §3 do documento de intenção.
- **Trilhos**: as 11 redes citadas (`+24V`, `+24V_ADC`, `+24V_REG`, `+5V_ADC`, `+5V`, `3V3_REF`, `+2V5_REF`, `+12V_TPS`, `+3.3V_DIG`, `DGND`, `GND_ADC`) existem todas como redes distintas na netlist, sem fusão — o erro que a rev. 2 corrigiu na folha 03 não voltou.
- **Mapa de canais**: `U500` liga a `+2V5_REF` (VREF), `AIN1..6_ADC` (`CH0,1,2,3,6,7`), `NTC_ADC` (`CH4`) e `3V3_REF` (`CH5`) — exactamente como o diagrama e o §8 do documento de intenção descrevem.
- **`TL431` "grampo 3,52 V"**: valor batido por conta, não só por texto. Netlist confirma a topologia `3V3_REF —R204(4k12)— nó REF —R205(10k)— GND_ADC`, com `REF` no `U203`. Com `V_ref` típico 2,495 V: `2,495 × (1 + 4,12/10) = 3,523 V ≈ 3,52 V`. Bate com a revisão mais recente (2.5b, `R204` 4k12), não com o valor antigo (3,60 V, que usava `R204`=4k42) — prova de que o diagrama foi actualizado no mesmo dia que a última revisão da netlist.
- **Termístor**: `R700` (10k NTC) de `+2V5_REF` a `NTC_ADC`, `R701` (5k62) e `C700` (100 nF, novo) de `NTC_ADC` a `GND_ADC` — confirmado.
- **Conectores**: `P1` = `M20-7822046` (20 pinos, `HDR1X20_FEMALE`), `P2` = `M20-7821446` (14 pinos, `HDR1X14_FEMALE`); `P1.20`=`+24V`, `P1.17`=`+5V` — confirmado.
- **Render SVG vs. PDF pág. 9**: pixel a pixel idênticos (2376×1680 a 2×), sem sobreposição de texto, sem caixas cortadas, sem espaços vazios suspeitos.

## Limites desta verificação

- Não se verificou o esquemático (`.kicad_sch`) directamente, só a netlist exportada (`EBM2_V5.net`) — se a netlist não reflectir o `.kicad_sch` mais recente (ex.: gerada antes de um ERC ainda por limpar nas folhas 01/04/05/06/07, como o cabeçalho do documento de intenção adverte), esta verificação herda essa defasagem.
- Não se conferiu o `.kicad_sch` para a nota do §17 item 11 ("porto `DGND` do `P1.12` deslocado na folha 01... o triângulo tapava o `P1.13`") — é um achado de folha 01, fora do diagrama de blocos.
- Não se avaliaram os valores de engenharia por trás dos rótulos (dimensionamento térmico do `TPS26613`, I²t do fusível, etc.) — isso é âmbito da verificação de aplicação de datasheet (`V8`, `V9`, `V13`, `V14` já em aberto no próprio documento de intenção), não do diagrama de blocos.
- Não foi possível confirmar por netlist a afirmação "TTL" da caixa "Barreira" nem o "INL +-1 LSB" da caixa "Conversor A/D" — são especificações de datasheet, não topologia; aceites por conhecimento do MPN.

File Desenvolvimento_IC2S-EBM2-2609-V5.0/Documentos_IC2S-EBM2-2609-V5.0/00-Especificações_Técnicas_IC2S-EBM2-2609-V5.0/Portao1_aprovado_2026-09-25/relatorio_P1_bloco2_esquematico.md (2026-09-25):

# Relatório — Portão 1, Bloco 2 (esquemático + intenção) — EBM2 V5

**Verificador:** Claude Sonnet 5, sessão independente (sem histórico de autoria). Autor do esquemático: Claude Opus 5.5.
**Âmbito deste relatório:** só o **Bloco 2** (esquemático KiCad + documento de intenção), conforme pedido. Blocos 1 (diagrama) e 3 (BOM/mapa de pinos) **não** foram avaliados aqui.
**Data:** 2026-09-25. Netlist analisada: `EBM2_V5.net` (export 2026-09-25T07:10:38, o mais recente na pasta — inclui a correcção da tanda C do `C200`). ERC analisado: `erc.json` (mesmo timestamp).

## Veredicto do bloco: **APROVADO COM RESSALVAS**

Não encontrei nenhum bloqueante. Encontrei duas ressalvas de higiene/documentação (nenhuma altera um valor eléctrico) e algumas limitações de leitura de curvas que não pude confirmar ao pixel. Ver tabela de achados e limites abaixo.

---

## 1. ERC

**Resultado: 0 erros — confirmado duas vezes de forma independente.**

- `erc.json` do autor: `included_severities: ["error"]`, todas as 8 folhas com `"violations": []`. Erros = 0.
- Reproduzi com a ferramenta MCP do servidor KiCad (`run_erc`), conforme o hábito de dupla verificação. Na primeira tentativa obtive **54 erros falsos** (rótulos hierárquicos "não podem ligar a uma folha pai inexistente", `MOSI`/`CLK`/`CS_ADC`/`MISO`/`LOOPn_V+`/`AINn-`, etc.) — isto era um artefacto da **minha** configuração: o `kicad_set_project` tinha escolhido por omissão `01_conectores.kicad_sch` como ficheiro-raiz, quando a raiz real do projecto é `IC2S_Extension_Board-EBM2_V5.kicad_sch` (confirmado por `grep` nos `.kicad_sch`, que mostra as folhas filhas referenciadas a partir desse ficheiro). Corrigindo o `sch_file` para a raiz real, o `run_erc` do MCP devolveu **VERDICT: WARN, 0 erros, 292 avisos** — concorda com o `erc.json` do autor (que filtra avisos).
- Os 292 avisos são quase todos de resolução de bibliotecas (ver achado #2), não de conectividade.

**Conclusão: ERC limpo confirmado. Este ponto do Portão 1 está cumprido.**

## 2. Polaridade de díodos/TVS/LED e orientação de CI

Verifiquei por **render ampliado (PyMuPDF, 8-12×)** do PDF, símbolo a símbolo, contra a **netlist** (pino 1 = cátodo, convenção documentada na própria folha 02, nota 7: "Diodos: pino 1 = CATODO"):

| Peça(s) | Papel | Orientação esperada (netlist) | Confirmado no render | Nota |
|---|---|---|---|---|
| `D200` (SMA6J33A-Q) | TVS de entrada | K→`+24V`, A→`GND_24V` | ✔ barra no topo (+24V), triângulo para baixo (GND_24V) | grampo verificado, ver §3 |
| `D201`, `D202` (MBR1H100SF) | Schottky série (polaridade inversa) | K→trilho a jusante, A→lado do fusível | ✔ seta aponta fusível→trilho nos dois | consistente com §4/§8 da intenção |
| `D203`, `D204`, `D630` (KG EELP41.22, LED) | Indicadores | A→resistência/trilho, K→GND | ✔ nos três | ligações conferem com §11: `D203`="há entrada", `D204`="F201 e regulador bem", `D630`="F202 inteiro" |
| `D601`-`D606` (SMBJ33A) | TVS retorno (`AINn-`) | K→`AINn-`, A→`GND_ADC` | ✔ amostra `D601` | uniformidade das 6 instâncias confirmada por netlist (todas com o mesmo padrão de pino) |
| `D611`-`D616` (824520361/SMBJ36A) | TVS terminal (`LOOPn_V+`, depois do fusível) | K→`LOOPn_V+`, A→`GND_ADC` | ✔ amostra `D611` | idem; localização "depois do fusível, no lado do terminal" confirmada (D611 está no nó pin2 de `F601`, não em `+24V_ADC`) |
| `D621`-`D626` (BAV199) | Clamp duplo do sinal filtrado | COM(pino3)→sinal, A1(pino1)→`GND_ADC`, K2(pino2)→`3V3_REF` | ✔ amostra `D621` | **Confirmado contra a FIGURA da pág. 1 do datasheet onsemi `BAV199LT1/D`**: pino 1 = Anode, pino 2 = Cathode, pino 3 = nó comum Cathode/Anode. A aplicação usa o nó comum como sinal e os dois terminais como grampos para `GND_ADC` (baixo) e `3V3_REF` (alto) — topologia correcta para grampo duplo |
| `U400` (ISO7141CCDBQR) | Isolador digital | 16 pinos, canal D reverso (MISO) | ✔ | **16/16 pinos conferidos directamente contra a tabela da pág. 4 do datasheet TI `SLLSE83F` (coluna ISO7141)** — nome, direcção (`IND`=campo/entrada, `OUTD`=barramento/saída, é o único canal reverso) e rede batem certo com a netlist e com a intenção §7. A própria folha regista a armadilha do datasheet (pinos 5,6,11,12 trocam entre ISO7131/ISO7140/ISO7141) e usa a coluna certa |
| `U401` (MCP1824ST-3302E/DB) | LDO do lado do barramento | 4 pinos | ✔ | 4/4 pinos conferidos contra a intenção/netlist (VIN=+5V, GND=DGND, VOUT=+3.3V_DIG, patilha=DGND) |
| `U500` (MCP3208T-BI/SL) | ADC | 16 pinos | ✔ | **16/16 pinos conferidos contra a tabela §8 da intenção e a netlist** — mapa de canais não sequencial confirmado (`CH6`=`AIN5_ADC`, `CH7`=`AIN6_ADC`), rótulo "canal N → CHx" também presente no desenho da folha 06 |

Adicionalmente confirmei, por netlist, que **`R200` é a única ligação entre `GND_24V` e `GND_ADC`** (5 nós no total em `GND_24V`: `D200`, `D203`, `P1.19`, `R200.1`, `T202`) e que **`DGND` não tem nenhum nó em comum com `GND_ADC`** a não ser através do isolador `U400` — confirma a nota 6 da folha 02 e a "barreira funcional" desenhada na folha 04.

**Texto sobre símbolo / fora da moldura:** inspeccionei as 8 folhas (renders de página inteira) — nenhuma sobreposição de texto sobre símbolo nem texto fora da moldura em nenhuma das folhas.

**O que NÃO foi feito individualmente:** não renderizei cada uma das 18 instâncias das famílias D60x/D61x/D62x uma a uma — verifiquei uma amostra visual de cada família (`D601`, `D611`, `D621`) e confirmei por netlist que as restantes 15 instâncias têm exactamente o mesmo padrão de ligação por pino. Assumo que a geometria do símbolo (não só a rede) se repete de forma idêntica nas seis colunas — isto é plausível (a folha 06 mostra os seis blocos visualmente idênticos) mas não confirmei geometricamente cada um.

## 3. Tandas — contas refeitas

### `R206` 150 Ω / `RA2` do `F201` (rev. 2.5c)

Conferido contra `Eaton_fusible_lento.pdf` (Technical Data 4309, CC12H):
- **Pág. 2, tabela**: linha `CC12H250mA`: resistência DC a frio típ. **3500 mΩ = 3,5 Ω**; I²t de pré-arco típ. **0,00038 A²s = 3,8×10⁻⁴ A²s**; nota 3 "Typical pre-arcing I²t value is measured at 10In rated current" — **texto e tabela batem exactamente** com o que a intenção cita.
- Refiz a conta: `I_max = 32 V / (150 + 3,5) Ω = 32/153,5 = 0,2084 A` ✔ (bate com "0,21 A" citado).
  `∫I² ≤ I_max × Q_total = 0,2084 × (70+92)×10⁻⁶ = 3,376×10⁻⁵ A²s` ✔ (bate com "3,4×10⁻⁵" citado).
  `Razão = 3,8×10⁻⁴ / 3,4×10⁻⁵ = 11,18×` ✔ **bate exactamente** com o "11,2×" citado no §17.
  A 18 V, 7 mA de carga: `V_R206 = 0,007×150 = 1,05 V` ✔ bate exactamente.
- **Pág. 4, curva I²t vs. tempo**: a leitura da curva a 0,1-0,5 ms (~6×10⁻⁴ a 1,5×10⁻³ A²s) é **plausível pela forma/posição da curva de 250 mA**, mas não medi ao pixel — fica como limitação, não como confirmado.
- **Não reproduzi** de forma independente o cálculo dos 92 µC "a jusante" (soma de cargas de `C202`, trilho `3V3_REF` e `C207` — não abri todos os nós envolvidos) nem o valor "realista" de 14,3×. Fica como limitação.
- **Netlist confirma** o valor final: `R206` = `150R`, MPN `SG73P2ATTD1500F` (KOA), consistente com a decisão 2.5c.

### Grampo do `D200` = 53,3 V

Confirmado **exactamente** contra `SMA6J33A__Bourns_SMA6J33A-Q.pdf`, pág. 2, tabela: linha `SMA6J33A` (unidireccional, marcação `6JM`): `V_RWM` = 33 V, `V_BR` 36,7-40,6 V, **`V_RSM` (grampo máximo) = 53,3 V** a `I_RSM` = 11,3 A. A folha 02 do esquemático regista a auto-correcção (a versão anterior dizia 58,1 V, que era o valor do `SMA6J36A`, não do `33A`) — a versão actual está certa.

### `SG73P` (impulso de `R206`)

`SG73P.pdf` pág. 2 tem a curva "One-Pulse Limiting Electric Power" para o tamanho 0805 (`SG73P 1E-2A`). O valor citado (~26 W a 0,6 ms) é consistente com a ordem de grandeza da curva log-log nessa duração, mas **não medi ao pixel** — limitação.

### `C200` (2,2 µF / 100 V, X7R 1210, `C3225X7R2A225K230AB`)

`C3225X7R2A225K230AB.pdf` pág. 1: capacitância nominal 2,2 µF ±10 %, 100 V, X7R (±15 %) — confirmado. Pág. 2, curva "DC Bias Characteristic": a 30,4 V a curva está claramente na parte descendente inicial, valor lido compatível com a ordem de grandeza de ~1,5 µF citada (não medido ao pixel). A conta `1,54 × 0,90 × 0,85 = 1,178 ≈ 1,18 µF` está aritmeticamente certa e fica acima de 1 µF (mínimo do `TPS7A4001`) com folga. Netlist confirma `C200` = MPN `C3225X7R2A225K230AB`, footprint `C_1210_3225Metric`.

### Folha 01 — porto `DGND` do `P1.12`

Confirmado **legível**: no render ampliado, o triângulo `DGND` do pino 12 está agora deslocado para a direita/baixo e **não** sobrepõe o texto "13 ID3 — manter desligado" — a correcção da tanda "Textos 25c" está aplicada e visível.

## 4. Amostras da netlist contra as tabelas da intenção (§8, §9) — e além

Fiz mais do que as 3-5 amostras pedidas, dado que os pinos de CI de barramento largo (16 pinos) são fáceis de conferir por completo e valem mais do que uma amostra parcial:

1. **`U400` (ISO7141) — 16/16 pinos** conferidos contra §7 e a tabela do datasheet (ver secção 2 acima).
2. **`U500` (MCP3208) — 16/16 pinos** conferidos contra §8 (ver secção 2 acima); mapa de canais não sequencial confirmado.
3. **Canal 1 completo (§9)** conferido nó a nó: `+24V_ADC → F601 → LOOP1_V+` (`P2.2`) e `D611` cátodo no mesmo nó (depois do fusível, como diz a rev. 2.3); retorno `AIN1- → P2.3`, `D601` cátodo aqui, `U601` pino 4 (`IN`) aqui; `U601` pino 5 (`OUT`) → `AIN1_LIM` → `R601` (0 Ω) → `AIN1_MED` → `R611` (110 Ω, burden, a `GND_ADC`) e `R621` (3k3, antialias) → `AIN1_FILT` → `C601` (100 nF a `GND_ADC`) e `D621` (`COM`) → **`R661` (4k7) → `AIN1_ADC`**. Tudo bate, **excepto** que `R661` não está mencionado na prosa do §9 (ver achado #13).
4. **`U401` (MCP1824) — 4/4 pinos** conferidos.
5. Confirmei por netlist que os seis canais (`D601`-`D606`, `D611`-`D616`, `D621`-`D626`, `U601`-`U606`, `R60x`/`R61x`/`R62x`/`R66x`, `C60x`) têm **conectividade uniforme** entre si (mesmo padrão pino-a-rede, só muda o índice do canal) — consistente com a tabela §9 e com o render da folha 06 (seis blocos visualmente idênticos, cada um rotulado "canal N → CHx").

---

## Tabela de achados

| # | Onde | Achado | Evidência | Severidade |
|---|---|---|---|---|
| 1 | `sym-lib-table` do projecto KiCad | Aponta para 10 bibliotecas `EBM7_V23_proyectoN.kicad_sym` em `${KIPRJMOD}/symbols/`, mas **essa pasta não existe** no projecto EBM2_V5 (só existe `footprints/EBM2_V5.pretty`, com `fp-lib-table` correcto e auto-suficiente). Parece um `sym-lib-table` copiado do projecto EBM7 sem limpeza. Não gera erro de ERC porque o KiCad usa o cache de símbolos embebido no `.kicad_sch`, mas **numa sessão MCP limpa gerou 292 avisos de resolução de biblioteca**, e significa que o projecto não é portátil: abrir noutra máquina, ou usar "Update Symbol from Library", pode falhar ou substituir símbolos | `C:\hw\hw-ebm2-v5\KiCad_EBM2_V5\sym-lib-table`; ausência confirmada de `KiCad_EBM2_V5\symbols\`; `run_erc` via MCP (292 avisos, 0 erros) | Ressalva |
| 2 | `intencao_EBM2_V5.md` §5 (linha 185) | A prosa da folha 02 ainda diz "`R206` ... 33 Ω (rev. 2.2)", desactualizada — o valor final (rev. 2.5c, §17 linhas 647-648) é **150 Ω**, e é o que está no esquemático/netlist. Um leitor que só leia §5 fica com o valor errado | `intencao_EBM2_V5.md:185` vs. `:647-648`; netlist `R206`=`150R` | Ressalva (documentação; o esquemático está certo) |
| 3 | `intencao_EBM2_V5.md` §9 | A prosa "o outro terminal de `R621` forma `AIN1_ADC`" omite o resistor série `R661`-`R666` (4k7, introduzido na rev. 2.5, §17 linha 657, com justificação e cálculo próprios) que está realmente entre o nó do filtro e o pino do ADC. O componente está correcto e bem justificado noutro sítio do documento, só a narrativa do §9 não foi actualizada | `intencao_EBM2_V5.md:368` vs. `:657`; netlist confirma `R661`-`R666` presentes | Ressalva (documentação) |
| 4 | Curva pág. 4 do Eaton CC12H; curva pág. 2 do SG73P; curva "DC Bias" pág. 2 do TDK C3225X7R2A225K230AB | Os valores citados nas três curvas (I²t a 0,1-0,5 ms; potência de impulso a 0,6 ms; capacitância a 30,4 V) são plausíveis pela forma/posição das curvas, mas **não foram medidos ao pixel** — não posso confirmar a 2ª casa decimal | PDFs citados, pág. 4/2/2 respectivamente | Nota / limitação |
| 5 | `U202` (`ADR4525WBRZ-R7`), pinos `NIC`/`DNC` | Ligação (`VIN`=`3V3_REF`, `VOUT`=`+2V5_REF`, `GND`=`GND_ADC`, `NIC`/`DNC` sem ligação) é internamente consistente na netlist; **não fui ao datasheet do ADR4525 confirmar a figura de pinagem** nem à tabela 14/nota 2 (grau B vs. W) citada no §17 — isso é matéria de BOM/grau de peça (Bloco 3), fora do âmbito pedido para este relatório | netlist `U202` | Nota / fora de âmbito (Bloco 3) |
| 6 | Geometria dos símbolos `D602`-`D606`, `D612`-`D616`, `D622`-`D626` | Só verifiquei visualmente uma amostra por família (`D601`, `D611`, `D621`); as restantes 15 instâncias foram confirmadas só por netlist (conectividade), não por render individual da geometria do símbolo | render PDF + netlist | Nota / limitação |

**Nenhum achado bloqueante.**

---

## O que foi conferido e o que não foi (limites)

**Conferido:**
- ERC = 0 erros, duas vezes, com fontes independentes (autor + MCP, depois de eu corrigir a raiz do projecto).
- Polaridade de todas as famílias de díodo/TVS/LED por render ampliado + netlist; orientação completa (16/16, 16/16, 4/4 pinos) de `U400`, `U500`, `U401` contra os respectivos datasheets/intenção.
- Coordenação fusível/resistor `F201`/`R206` (rev. 2.5c) recalculada com os números exactos do datasheet Eaton.
- Grampo do `D200` (53,3 V) confirmado exactamente contra a tabela do datasheet Bourns.
- Legibilidade da folha 01 (porto `DGND` do `P1.12`).
- Isolamento de domínios de massa (`GND_24V`↔`GND_ADC` só por `R200`; `DGND` sem ligação directa a `GND_ADC`).
- Ausência de texto sobreposto ou fora da moldura nas 8 folhas.
- Canal 1 completo (§9) nó a nó.

**Não conferido / limitações:**
- Leitura ao pixel das curvas Eaton (I²t-tempo), KOA SG73P (potência de impulso) e TDK C3225 (DC bias) — só validado por ordem de grandeza e forma da curva.
- Cálculo independente completo dos "92 µC a jusante" do `R206`.
- Datasheet do ADR4525 (pinagem/grau) — matéria de BOM, fora do âmbito deste relatório de Bloco 2.
- Geometria de símbolo individual das 15 instâncias de TVS/clamp não amostradas (só a conectividade foi confirmada para todas).
- Blocos 1 e 3 (diagrama, BOM, mapa de pinos) — fora do âmbito pedido.

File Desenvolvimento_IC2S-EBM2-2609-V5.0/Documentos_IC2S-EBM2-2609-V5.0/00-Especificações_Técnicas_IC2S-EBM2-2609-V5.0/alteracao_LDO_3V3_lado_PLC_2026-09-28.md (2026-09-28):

# Regulador de 3,3 V do lado PLC — U5: MCP1824ST-3302E/DB → MCP1824T-3302E/OT (2026-09-28)

Da reunião de 25-09: «esse chip é mais caro… existe regulador menores». O U5 alimenta só o lado 1 do ISO7141 (+5V do P1 → 3,3 V, massa DGND).

## Comparação que decidiu (datasheets locais; preços da API Mouser gravados nos repositórios)

| | MCP1824ST-3302E/DB (saiu) | SPX3819M5-L-3-3/TR | MCP1824T-3302E/OT |
|---|---|---|---|
| Encapsulamento | SOT-223-3 | SOT-23-5 | SOT-23-5 |
| Entrada (operação / máx. absoluto) | 2,1-6,0 V / 6,5 V | 2,5-16 V / 20 V | 2,1-6,0 V / 6,5 V |
| Precisão em temperatura | ±2,5 % | ±2 % | ±2,5 % |
| Estável com cerâmico | sim, «Stable with 1.0 µF Ceramic» (DS22070A p.1) | **não especificado** («bench testing», SPX3819 rev. 2.0.5 p.7); provado em campo na V2.2 | sim (mesmo datasheet) |
| ESD HBM | ≥ 4 kV | 1 kV | ≥ 4 kV |
| Mouser 1 un. | 0,64 USD (25-09) | 0,51 USD (16-09) | 0,56 USD (25-09) |
| Stock Mouser | 11 898 (25-09) | **99** (16-09) | 14 500 (25-09) |

Carga real: só o lado 1 do ISO7141, ≤ 8 mA a 40 Mbps (TI SLLSE83F p.10). O ISO7141 pede VCC1 de 2,7 a 5,5 V
(p.5) e 0,1 µF a ≤ 2 mm do pino (p.22 e p.25): cumprido com qualquer um dos três (C a 1,9 mm).

**Critério da equipa (28-09-2026): menos MPN, mais peças do mesmo tipo.** Na EBM7 o SPX3819 já é o U3/U4 do
+3.3V_ANA; na EBM2 o MCP1824T já é o U4 do 3V3_REF. O MCP1824ST sai das três placas.

## O que mudou

- **U5 = MCP1824T-3302E/OT**, SOT-23-5. Ligações: 1 IN e 3 SHDN a +5V (SHDN alto ≥ 45 % VIN, DS22070A p.9), 2 GND a DGND, 4 PG aberto (dreno aberto), 5 OUT a +3.3V_DIG.
- Condensadores mantidos (os que já estavam na entrada e na saída).
- PCB: pegada EBM2_V5:SOT-23-5 no mesmo sitio (placa ainda sem pistas). Nota 3 da folha 4 actualizada.

## Verificação

- ERC 0 erros; DRC 0 erros, paridade 0; netlist: só mudam os pinos do U5.

## Riscos em aberto

- Nenhum eléctrico novo: mesmo datasheet e comportamento do MCP1824ST; só muda o encapsulamento.
- Preços e stock são das consultas gravadas (16 e 25-09), não de hoje: a web da Mouser bloqueia leitura automática.

## Complemento: circuito típico do datasheet (MCP1824, DS22070A, «Typical Applications — Fixed Output», p.3)

| Elemento | Datasheet | Na placa |
|---|---|---|
| Entrada C1 | 4,7 µF na figura; «1 µF to 10 µF should be sufficient» (p.17) | **C10 era 1 µF/50 V = 0,80 µF efectivos a 5 V (pior caso) ❌ → agora 10 µF/50 V** |
| Saída C2 | 1 µF («Stable with 1.0 µF Ceramic», p.1) | C11 2,2 µF ✅ |
| SHDN | On/Off; alto ≥ 45 % de VIN (p.9) | directo a +5V ✅ |
| PWRGD + R1 100 kΩ | só se o sinal for usado | aberto (dreno aberto) ✅ |

**C10 = C3216X5R1H106K160AB** (10 µF/50 V 1206, o mesmo MPN de C4/C8/C31/C32; curva TDK: 7,0 µF a 5 V no pior caso). PCB: clone da pegada do C4, a 3,5 mm do U5 (o 1206 não cabia no sítio do 0603). ERC 0; DRC 0 erros, paridade 0.

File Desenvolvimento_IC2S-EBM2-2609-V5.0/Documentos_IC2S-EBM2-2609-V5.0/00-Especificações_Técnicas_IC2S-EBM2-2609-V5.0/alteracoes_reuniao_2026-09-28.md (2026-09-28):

# Alterações de 2026-09-28 — decisões da revisão da EBM7 V2.3 trazidas para a EBM2 V5

Na reunião de 28-09 a equipa pediu, para a EBM7 V2.3: um só ramo de 24 V, rever o condensador de entrada da fonte,
baixar a tensão dos condensadores de 100 V do lado analógico e usar o mesmo MPN para a mesma função. Aqui aplicam-se
as mesmas decisões à EBM2 V5. **É uma alteração posterior ao Portão 1**: o pacote `Portao1_aprovado_2026-09-25`
fica como estava, e esta nota regista o desvio.

Notas no esquemático: **folha 2, notas 3, 11, 13 e 14**.

## 1. Ramo único de 24 V

**Antes:** depois do TVS D2 havia dois ramos:
- F1 (CC12H250MA) → D3 → R3 (150 Ω) → +24V_REG, que alimentava só o U1 (TPS7A4001, 5 V);
- F2 (CC12H750MA) → D4 → +24V_ADC, para os laços, o U14 (12 V) e o LED.

**Agora:** saem **F1, D3 e R3**. F2 → D4 → **+24V_ADC** alimenta tudo; o nome +24V_REG deixa de existir.

Na EBM7 ficou o ramo do conversor e saiu o dos laços. Aqui é ao contrário, e isto não é escolha:
- o F1 funde com 3,8e-4 A²s, e o arranque só do C2 (10 µF a 32 V) dá 6,4e-3 A²s (nota 2), ou seja, o F1 abriria ao
  ligar. Só o F2 (0,15 A²s) aguenta a placa inteira;
- o R3 existia apenas para limitar a corrente do F1 (nota 11: «sem R3 seria 1,2×»). Sem F1 perde a função e sai;
- o **C1 (2,2 µF / 100 V) fica**: é o Cin do U1, que o TPS7A4001 pede (> 1 µF, nota 10).

Contas:
- Corrente no F2 (750 mA) e no D4 (MBR1H100SF, 1 A): 125 mA dos laços e LEDs + ~7 mA do U1 = ~132 mA.
- I²t no arranque, a 32 V com R = 0,8 Ω (fórmula da nota 2): ~22 µF nominais a jusante (C2 + C30 + C1 + 100 nF) dão
  1,4e-2 A²s contra 0,15 A²s: **≥ 10× de margem**. A nota 2 dava 23,4× porque contava só o C2. Com a capacidade
  efectiva a 32 V, mais baixa, a margem real é maior. Estimativa, não medida.
- Perde-se a selectividade: um curto no +24V_ADC abre o F2 e desliga a placa toda.
- O requisito **RA2** do planeamento (margem do fusível do regulador, 11,3×) deixa de se aplicar como estava escrito:
  o regulador passa a depender do F2.
- **TP3** fica no mesmo sítio, à entrada do U1, agora em +24V_ADC (valor `TP_+24V_U1`).

PCB (sem pistas ainda): saíram as pegadas de F1, D3 e R3; os pads de C1, TP3 e U1 (5, 8) passaram a +24V_ADC.

## 2. Condensador de entrada da fonte

O U1 é um TPS7A4001, e não o R-78HB da EBM7. O C1 foi verificado na F2 (tanda C) contra o datasheet da TI e contra a
curva TDK: ~1,54 µF a 30,4 V, e 1,18 µF no pior caso, acima de 1 µF. **Sem alteração.**

## 3. Tensão dos 100 nF

Todos os 22 eram GRM188R72A104KA35D (100 V). Só o **C29**, em +24V_ADC (até 53,3 V no clamp), precisa de 100 V.

| Grupo | Tensão máxima | Peça |
|---|---|---|
| C29 em +24V_ADC | 53,3 V | fica GRM188R72A104KA35D, 100 V (`100nF/100V`) |
| C17-C22 (+Vs dos TPS26613) e C34 (VSNS), em +12V_TPS | 12 V; até ~32 V (Vin) se o U14 falhar | **TDK C1608X7R1H104K080AA, 50 V** |
| C3, C6, C9, C12-C14, C16, C23-C28, C35 (3,3 / 5 V, ADC, filtros) | ≤ 5 V | **TDK C1608X7R1H104K080AA, 50 V** |

25 V não serve, porque não cobre o caso do U14 em falha. Fonte: catálogo TDK *MLCC commercial general*, p.34. São 21
peças, com o valor escrito `100nF/50V`. Na intenção do projecto, C17-C22 estavam a 100 V só por herança dos
C26/C29/C31/C32 da EBM7 Legacy, que também passaram a 50 V.

## 4. Mesmo MPN para a mesma função

- **1 µF (C10, C15):** já tinham um só MPN (KEMET C0603C105K4RACTU, 16 V). Passam a **TDK C1608X7R1H105K080AB**
  (50 V, catálogo p.35), o mesmo da EBM7, para as duas placas usarem uma só peça. Valor `1uF/50V`.
- 10 µF / 50 V, 2,2 µF, 10 nF e 10 µF / 100 V: já tinham um MPN cada. Sem alteração.

## Verificação

- Netlist antes/depois: saem F1, D3, R3 e as redes `+24V_FUS_REG` e `+24V_DIO_REG`; C1, TP3 e U1 (pinos 5 e 8)
  passam de +24V_REG a +24V_ADC; 23 condensadores mudam de valor/MPN. Nenhuma outra ligação muda.
- ERC: 0 erros; os avisos são os de antes, menos os das três peças.
- DRC (`--severity-all --schematic-parity`): 0 violações, **paridade 0**; 286 ligações por fazer (placa sem roteamento).
- BOM preliminar regenerada com `Ferramentas/gera_bom_prelim.py` e os mesmos dados Mouser de 25-09: 42 linhas, 123
  peças montadas. Os dois TDK novos aparecem sem preço/stock (N/D), porque não foram consultados na Mouser.
- `01-Esquemáticos/esquematico_EBM2_V5.pdf` regenerado. O PDF de revisão da F2 (`EBM2_V5_F2_revisao_2026-09-25.pdf`)
  é do Portão 1 e não foi refeito.

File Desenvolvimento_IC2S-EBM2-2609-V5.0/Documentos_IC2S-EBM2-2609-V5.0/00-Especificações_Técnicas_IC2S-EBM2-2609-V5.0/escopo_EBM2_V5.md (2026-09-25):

---
documento: Escopo de hardware
projecto: IC2S Extension Board EBM2 V5 (6AI)
fase: F0
data: 2026-09-23
autor: gerado por 2shw-pcb:escopo
estado: APROVADO no Portão 0
portao_0:
  aprovado_por: Javier Rivadineira (projectista responsável)
  data: 2026-09-23
  registado_por: sessão Claude Code (a aprovação é do humano; esta sessão só a regista)
  bloqueantes_por_resolver: 0
  gaps_importantes_abertos: 2   # G5 e G7 fechados em 2026-09-23; G3 fechado na F1; resta G4 e G6
---

> ## ✅ PORTÃO 0 — APROVADO
>
> Aprovado por **Javier Rivadineira** em **2026-09-23**.
>
> **Os critérios de aceite da secção 2 ficam CONGELADOS a partir desta data.**
> Eram 23 na assinatura. `RD3` foi **retirado** em 2026-09-23 por falta de
> desenho do invólucro, e `RA3` foi **reescrito** no mesmo dia para tirar um
> nível de surto que a sessão tinha inventado. **Ficam 22.** Retirar e reescrever
> um critério depois da assinatura é alteração de escopo, e fica aqui à vista.
> É contra eles que a F6 valida a placa, e não se reescrevem.
>
> **Estado dos gaps na assinatura** (ver `escopo_EBM2_V5_gaps.md`):
>
> | | |
> |---|---|
> | Bloqueantes | **0** — G1 e G2 resolvidos em 2026-09-23 |
> | Importantes em aberto | **5** — G3 a G7. Assinado com eles abertos; **cada um precisa de dono e data antes do fim da F1** |
> | Menores em aberto | 5 — G8 a G12 |
> | Por confirmar | 2 — G1b e G1c |
>
> **O que esta assinatura NÃO cobre, e quem a ler tem de saber:**
>
> 1. **Não houve kick-off gravado.** O escopo deriva de material técnico e de
>    cinco respostas directas do projectista, não de uma reunião multidisciplinar.
> 2. **A revisão adversarial correu no mesmo modelo que redigiu o escopo.** A
>    skill pede um segundo modelo. Vale como pré-revisão.
> 3. **O contrato do bus de 14 pinos fica fora de âmbito** por decisão expressa.
>    O risco de plataforma está quantificado em `L3` e no resumo dos gaps, e
>    continua aberto depois desta assinatura.
> 4. **`G1c` fechou em 2026-09-23, e mexeu no orçamento de erro.** A calibração
>    é uma **constante comum a todas as placas**, não por unidade. Uma constante
>    comum não segue a dispersão de peça para peça, portanto a tolerância
>    inicial volta à conta, e os erros do próprio `MCP3208` passam a contar. O
>    orçamento refeito está em `planejamento_pcb_EBM2_V5.md` §2.5b, **em duas
>    contas separadas**, porque é assim que os critérios estão escritos: `RE1`
>    mede a 25 °C e `RE2`/`RB3` medem o erro adicional em temperatura.
>    **Actualizado em 2026-09-23 com o datasheet `DS21298E` do conversor:**
>    a deriva fica em **0,165 %** contra 0,2 % e cumpre, mas `RE1` fica em
>    **0,237 %** e **não cumpre**, porque os erros de offset e linearidade do
>    `MCP3208` são tensões fixas e a nossa referência de 2,5 V duplica-lhes o
>    peso relativo. Nenhuma troca de componente o resolve. Com calibração por
>    unidade de dois pontos, `RE1` cai para 0,055 %. **É a decisão que falta
>    tomar.**

---

# Escopo de hardware — IC2S Extension Board EBM2 V5 (6AI)

> **Este documento substitui** o `escopo_EBM2_V5.md` mínimo escrito à posteriori
> em 2026-09-23. Aquele era um registo de lacunas; este é a F0 a sério.

> **Ressalva de insumos.** Não houve reunião de kick-off gravada. O escopo
> deriva de: o projecto V4.1 convertido e auditado, os Gerbers originais, a
> placa irmã EBM7 V2.3 como referência, 68 datasheets, quatro análises
> anteriores, o histórico de avaria em campo da EBM7 V1.1, e **quatro requisitos
> de produto respondidos directamente pelo projectista em 2026-09-23**. Tudo o
> que não vem dessas fontes está marcado como especificação aberta, nunca como
> escolha implícita.

---

## 1 · Contexto e objectivo

A EBM2 é um shield de quadro PLC da família IC2S com **seis entradas analógicas
de 4-20 mA**. Monta sobre uma base board pelo conector `P1` de 20 pinos e liga ao
campo pelo `P2` de 14 pinos. A revisão em campo é a **V4.1, de 2024**.

**Objectivo da V5:** corrigir defeitos identificados na V4.1 — um deles é o
mesmo mecanismo que já queimou fusíveis em campo na placa irmã — portando a
arquitectura de alimentação e de protecção de entrada da EBM7 V2.3, **sem
quebrar a compatibilidade com os quadros instalados**.

Não é um produto novo. É uma revisão de correcção.

## 2 · Requisitos, com critérios de aceite mensuráveis

Estes critérios **congelam na aprovação do Portão 0** e são contra eles que a
F6 valida a placa. Não se reescrevem depois.

### 2.1 · Compatibilidade — decisão do projectista, 2026-09-23

| ID | Requisito | Critério de aceite |
|---|---|---|
| **RC1** | A V5 é **substituição directa** da V4.1 num quadro instalado | Contorno, furação de fixação e posição dos conectores idênticos aos Gerbers da V4.1, medidos com tolerância de 0,1 mm |
| **RC2** | Pinagem de `P1` (20 pinos) e `P2` (14 pinos) **inalterada** | Comparação nó a nó da netlist da V5 contra a da V4.1: zero diferenças nos pinos de `P1` e `P2` |
| **RC3** | A base board não distingue uma V5 de uma V4.1 | Mesma sequência SPI, mesmos níveis, mesma codificação de ID nos pinos `ID1`/`ID2`/`ID3` |
| **RC4** | O firmware existente continua a funcionar | A placa monta num quadro instalado e é lida pelo firmware actual **sem recompilar**. A alteração de escala é absorvida pela rotina de calibração existente, executando a calibração de cada canal após a troca |

> **RC4 — cumpre-se, com uma condição de processo (2026-09-24).** Não é preciso recompilar: a escala
> nova absorve-se recalibrando cada canal pela tela. **Mas nada obriga a recalibrar ao trocar a
> placa**, e a calibração da V4.1 continua aplicada. Se ninguém recalibrar, a V5 lê **−9,3 %** em
> todos os canais (20 mA → 18,15 mA), e **4 mA lê 3,63 mA, colado ao corte de 3,6 mA**: um
> transmissor a 3,9 mA passa a `"null"` (falso laço aberto). O ajuste em lote que o firmware
> propõe (×0,9074 nos pontos) só corrige a escala nominal: arrasta os erros próprios da V4.1
> (±1 % do LDO usado como referência, ±1 % do burden). **Regra: recalibrar os seis canais ao
> instalar a V5.**

### 2.2 · Medida

| ID | Requisito | Critério de aceite |
|---|---|---|
| **RM1** | Seis canais de entrada 4-20 mA, independentes | Injectar 4,000 e 20,000 mA em cada canal e ler os seis sem diafonia acima de 1 LSB |
| **RM2** | Alcance útil igual ao da EBM7 legacy | Fundo de escala **não inferior a 20,5 mA** |
| **RE1** ⚠ | **Exactidão de 0,1 a 0,2 % do fundo de escala, DEPOIS de calibrada** | Com fonte de corrente rastreável, erro máximo em 4, 12 e 20 mA dentro de ±0,2 % a 25 °C. **EM CONFLITO**: a calibração é uma **constante comum** (confirmado 2026-09-23) e com ela o pior caso calculado é **0,237 %**, típico 0,139 %. Nenhum componente o resolve. **Decisão de escopo pendente no Portão 0**: especificar pelo pior caso ou declarar 0,2 % como típico. Ver `planejamento_pcb_EBM2_V5.md` §2.7c |

> **RE1 — conflito resolvido em 2026-09-24 com a resposta do firmware.** O conflito existia porque
> se assumiu «constante comum». O sistema **calibra cada canal no campo em 6 pontos**: offset e
> ganho do ADC, da referência e do burden saem da calibração. Sobra, a 25 °C: INL residual ≤ 0,055 %
> (limite de 1 LSB do grau -B, sem descontar o efeito dos 5 trechos), ruído da amostra única da
> captura ~0,028 % (±1 LSB, estimativa) e a exactidão da fonte de corrente do campo (**por
> conhecer**). RSS sem a fonte: **~0,062 %**, contra o tecto de 0,2 %. **Cumpre, desde que a
> calibração seja feita e a fonte seja ≤ 0,1 %.** O projectista tinha dito «não calibramos unidade
> por unidade»: não há calibração de fábrica, mas há a de campo, por canal.

> **Resposta do firmware (Rodrigo, 2026-09-24), tirada do código do DeviceManager.** Na EBM2 não
> há firmware à parte: o backend Node (`extensions/EBM2.js`, `extensions/expander.js`) lê o ADC.
> - **Calibração por canal, no campo, em 6 pontos** (0, 4, 8, 12, 16, 20 mA), pela tela
>   Settings → mapa → Calibrar: 5 trechos lineares, ganho e offset por trecho, guardados no MongoDB
>   **ligados à variável, não à placa**. Sem calibração não há conversão para mA.
> - **Ao trocar a placa a calibração antiga continua aplicada** e nada obriga a recalibrar.
> - SPI a **20 kHz** fixos; média móvel de 10 amostras a cada 500 ms; a captura da calibração usa
>   **uma amostra instantânea**.
> - **CH4 (NTC) e CH5 não são lidos.** AI1-AI6 = CH0, CH1, CH2, CH3, CH6, CH7.
> - Acima de 20 mA não há limite nem aviso (satura em silêncio); abaixo de 3,6 mA a variável vira
>   `"null"` (laço aberto), **só com o canal calibrado**.
| **RE2** | **A exactidão mantém-se em toda a gama de `RB1`** | Repetir `RE1` a 0 e +70 °C sem recalibrar. Erro adicional ≤ 0,2 %. **É este o critério que decide as peças**: a calibração remove o erro inicial, não a deriva térmica |
| **RM3** | Filtro anti-aliasing por canal | Frequência de corte medida entre 400 e 550 Hz |

### 2.3 · Alimentação e protecção

| ID | Requisito | Critério de aceite |
|---|---|---|
| **RA1** | Entrada única de 24 V vinda da base board. **Envolvente 18–32 V** (corrigido em 2026-09-23): o painel alimenta-se de rede, bateria ou painel solar, com e sem controlador de carga — decisão do projectista de 2026-08-31, «opção B, alimentação genérica», `escopo_EBM7_respin.md` §7, cenários S1-S4. A primeira versão deste escopo tomou a DRC-100B como única fonte e escreveu 20–28 V | Funciona de **18 a 32 V** sem degradação de medida acima de 1 LSB. Dimensionamento: arranque e dissipação a **32 V**, tensão ao transmissor a **18 V** |
| **RA2** | **Os fusíveis não abrem no arranque** | Ligar e desligar a alimentação 100 vezes seguidas sem abrir nenhum fusível. Margem calculada de I²t do arranque contra o I²t de fusão ≥ 10× |
| **RA3** | TVS na entrada de 24 V | **REESCRITO em 2026-09-23, fecha `G5`.** Não existe requisito de imunidade escrito, confirmado pelo projectista. O nível de 1 kV que aqui constava foi inventado pela sessão e retira-se. O critério passa a ser de projecto: existe TVS na entrada, a sua tensão de grampeamento fica abaixo do menor absoluto máximo de todas as peças do trilho, e essa margem está calculada e documentada. Sem nível de ensaio declarado, não há ensaio de surto |
| **RA4** | Todo o caminho de clamp termina num sumidouro real | Injectar 30 V numa entrada de campo e medir `3V3_REF`: não pode subir acima de 3,7 V |
| **RA5** | Consumo total na entrada de 24 V | ≤ 200 mA com os seis canais a 20 mA |

### 2.4 · Ambiente — decisão do projectista, 2026-09-23

| ID | Requisito | Critério de aceite |
|---|---|---|
| **RB1** | Gama de operação **declarada e certificada: 0 a +65 °C**; **dimensionamento a +70 °C** (margem de projecto pedida pelo projectista, 2026-09-24). **Corrigido em 2026-09-24 pelo projectista: 0 a +70 °C.** O −40 a +85 °C anterior foi proposto pela sessão na F0 como «o habitual em quadro de PLC» e escolhido nessa pergunta; não corresponde a nenhum painel instalado. | Todos os critérios de medida cumpridos em câmara a 0, +25 e **+70 °C** (ensaiar no limite de projecto cobre os 65 °C certificados) |
| **RB2** | Todos os componentes especificados para a gama, sem excepção | Auditoria da BOM: zero peças com gama inferior. Electrolíticos com gama e vida declaradas, ou substituídos por cerâmicos |
| **RB3** | Deriva térmica dentro do orçamento de erro | Erro adicional entre 0 e +70 °C ≤ 0,2 % do fundo de escala, **medido em relação à temperatura a que se calibrou** (no campo não é 25 °C) |

### 2.5 · Isolamento — decisão do projectista, 2026-09-23

| ID | Requisito | Critério de aceite |
|---|---|---|
| **RI1** | **Nenhuma certificação formal de isolamento.** A barreira é funcional | Declarado no dossier. **Não se invoca IEC 60664-1 nem se declara tensão de isolamento** |
| **RI2** | Separação funcional entre o barramento digital e o campo | O `ISO7141` é a única barreira. Nenhum condutor a atravessa no esquemático nem no layout |
| **RI3** | União de massas num ponto único | Existe exactamente **um** caminho entre `GND_24V` e `GND_ADC`, e é uma resistência de 0 Ω identificável |

### 2.6 · DFT

| ID | Requisito | Critério de aceite |
|---|---|---|
| **RD1** | Ponto de prova em cada trilho de alimentação | `+24V`, `+24V_ADC`, `+24V_REG`, `+5V`, `3V3_REF`, referência, `GND_24V`, `GND_ADC`, `DGND` — todos acessíveis com ponta de prova |
| **RD2** | Fiduciais para montagem automática | ≥ 3 fiduciais na face com SMD |
| ~~**RD3**~~ | ~~Acesso mecânico aos pontos de prova com a placa montada no quadro~~ | **RETIRADO em 2026-09-23, fecha `G7`.** Não existe desenho do invólucro nem do quadro, confirmado pelo projectista. Um critério que ninguém consegue verificar não se congela. Volta ao escopo no dia em que houver desenho |

## 3 · Componentes críticos já decididos

Só entram aqui os que a equipa já decidiu. Todos vêm da EBM7 V2.3, já montados
e portanto sem qualificação nova.

| Função | Peça | Origem da decisão |
|---|---|---|
| Aislador digital | `ISO7141` | Herdado da V4.1, mantém-se |
| Conversor A/D | **`MCP3208T-BI/SL`** | Herdado da V4.1, que monta o grau `-CI`. **Muda para `-BI` em 2026-09-23**: mesmo encapsulamento, mesma pinagem, mesmo protocolo, INL de ±1 LSB em vez de ±2. `RC4` intacto |
| TVS de entrada | `SMA6J33A-Q` | EBM7 V2.3, `D200` |
| Fusíveis retardados | família Eaton `CC12H` | EBM7 V2.3. **MPN do valor baixo por fixar — ver G4** |
| Díodo de bloqueio | `MBR1H100SF` | EBM7 V2.3 |
| Regulador de entrada alta | `TPS7A4001` | EBM7 V2.3, `U12` |
| LDO de 3,3 V | `SPX3819M5-L-3-3` | Já na V4.1 como `U11` |
| Grampo activo | `TL431B` | EBM7 V2.3, `U4` |
| Clamps de baixa fuga | `BAV199` | EBM7 V2.3 |
| Conectores | `M20-7822046` e `M20-7821446` (Harwin) | Herdados da V4.1, congelados por RC2 |

## 4 · Especificações abertas — decidem-se na F1

1. **Referência de tensão do ADC. FECHADA em 2026-09-23 — e a premissa mudou.**
   O `G1c` fechou com «constante comum a todas», o que inverte o raciocínio
   anterior: uma constante comum não acompanha a dispersão de peça para peça,
   logo **a tolerância inicial NÃO é removida pela calibração**. O texto que
   aqui estava, dando-a por removida, estava errado. Especificação corrigida:
   coeficiente **≤ 5 ppm/°C** *e* tolerância inicial **≤ 0,1 %**. Peça escolhida
   **`ADR4525BRZ`**, que cumpre as duas com folga larga: 0,02 % inicial e
   **4 ppm/°C pelo método bowtie** — o datasheet dá também 2 ppm/°C pelo método
   box, mas o bowtie é o que responde ao afastamento a partir do ponto de
   calibração e é esse que entra na conta.
2. **Valor e tecnologia do burden. FECHADA em 2026-09-23.** O **valor** continua
   livre, porque a constante comum absorve o nominal. A **dispersão** não:
   tolerância inicial e deriva entram as duas na conta e juntas fazem do burden
   o termo dominante do orçamento. Alvo **≤ 25 ppm/°C** e tolerância **≤ 0,1 %**.
   Valor fixado em **110 Ω**, que coloca o fundo de escala em 22,7 mA e cumpre
   `RM2` com folga. Peça **`ERA3AEB111V`**. **Se o orçamento de `RE1` não
   fechar, o problema não tem solução dentro desta família.** A tabela de
   *Ratings* do datasheet Panasonic `AOA0000C307`, pág. 2, mostra que em 0603 o
   grau de ±10 ppm/°C só desce a 1 kΩ e o de ±15 ppm a 470 Ω. **A 110 Ω,
   `ERA3AEB` é o melhor que existe**, e apertar mais obriga a mudar de
   fabricante. O part number correcto é `ERA3AEB111V`: 110 Ω é valor E24 e a
   nota `*5` do datasheet impõe a codificação de três dígitos.
3. **MPN e valor exacto dos passivos** do bloco de alimentação.
4. ~~**Número de camadas e empilhamento.**~~ **FECHADA em 2026-09-23**: quatro
   camadas, igual à V4.1. Confirmado pelo projectista e coerente com a medição
   feita nos Gerbers originais.
5. **Estratégia de retorno de massa** com os seis laços a partilharem
   `GND_ADC`. Decide-se com o layout, mas a restrição fixa-se na F1: a
   resistência entre as massas dos burden e o `AGND` do ADC tem de ser
   **< 5 mΩ** para que a queda IR fique abaixo de 1 LSB com 120 mA.

## 5 · Restrições

**Mecânicas.** Contorno, furação e posição de conectores congelados pela V4.1
(RC1). Os Gerbers originais são a referência dimensional.

**Ambientais.** 0 a +65 °C certificado, dimensionado a +70 °C (RB1, corrigido em 2026-09-24). Sem requisito de IP declarado para a placa:
a protecção é do quadro. Vibração não declarada.

**Regulatórias.** **Nenhuma.** Sem rádio, logo sem Anatel. Sem área
classificada, logo sem ATEX. Sem certificação de isolamento (RI1).

**Custo.** Não declarado. Registado como lacuna menor: todas as peças que entram
já estão em BOM de outra placa da casa.

## 6 · Orçamento de energia

~~Não aplicável: a placa é alimentada pelo quadro, não por bateria.~~ **Corrigido em
2026-09-23:** o quadro pode estar em bateria ou painel solar (`RA1`, 18–32 V). A placa não
gere a bateria, mas o consumo pesa na autonomia do painel; está coberto por RA5.

| Consumidor | Corrente a 24 V |
|---|---|
| Seis laços a 20 mA | 120 mA |
| Três LED indicadores | 4,5 mA |
| Electrónica (ADC, isolador, referência, NTC) | ~5 mA |
| **Total** | **~130 mA** |

## 7 · Interfaces externas

| Interface | Descrição | Estado |
|---|---|---|
| `P1`, 20 pinos | Barramento à base board: SPI, IDs, I2C, +5 V, 24 V e retornos | **Congelado** por RC2 |
| `P2`, 14 pinos | Campo: seis pares de alimentação e retorno de laço, mais `GND_ADC` | **Congelado** por RC2 |

**Aviso de plataforma.** O mesmo conector físico de 14 pinos tem **três
definições mutuamente incompatíveis** entre a MainBoard V5.1, a EBM2 e a EBM7
(fonte: `EBM2_vs_EBM7_Comparacion.md`, 2026-08-11). Escrever o contrato do bus
ficou **fora do âmbito** desta revisão por decisão do projectista em
2026-09-23. Regista-se como **risco de plataforma aberto**: cada modelo novo de
extensão vai continuar a chocar de maneira diferente.

## 8 · Fora de escopo, explicitamente

- Escrever ou auditar o contrato do bus de 14 pinos (decisão de 2026-09-23).
- Alterar o conversor A/D, o aislador ou os conectores.
- Alterar a pinagem de `P1` ou `P2`.
- Certificação de isolamento de qualquer tipo.
- Firmware. Esta placa não traz MCU; o firmware vive na base board.
- Invólucro novo.

## 9 · Defeitos da V4.1 que esta revisão corrige

Medidos nesta sessão, com a conta à vista. São a justificação da revisão.

| # | Defeito | Medida |
|---|---|---|
| D1 | **Mecanismo de avaria de fusíveis presente** | `F7`/`F9` são `3413.0008.22`, I²t de fusão **0,0015 A²s** (datasheet Schurter, confirmado na F1). Arranque dos 10 µF a 24 V = 0,00565 A²s com R=0,51 Ω, ou 0,00169 A²s com R=1,7 Ω. **Acima nos dois casos, em três ramas.** As unidades foram corrigidas de mA²s para A²s em 2026-09-23; os rácios e a conclusão não mudam |
| D2 | **Sem sumidouro em `3V3_REF`** | Seis clamps injectam ~4,5 mA cada num rail com um LDO que não absorve e 2,3 µF |
| D3 | **Zener de 2,45 V classe µA em série na entrada** | A conduzir os ~130 mA de toda a placa |
| D4 | **Sem TVS na entrada de 24 V** | A rede `+24V` tem só o zener e três fusíveis |
| D5 | **Díodo de bloqueio de 60 V** | Contra o grampo do TVS: ~~58,1 V, 1,9 V de margem~~ **53,3 V, 6,7 V de margem** (SMA6J33A, Bourns pág. 2; corrigido 2026-09-25). Resolvido com o MBR1H100SF de 100 V |
| D6 | **Bulk de 50 V** | ~~8,1 V abaixo do clamp de 58,1 V~~ **3,3 V abaixo do grampo de 53,3 V** (corrigido 2026-09-25): continua a não servir. Resolvido com cerâmico de 100 V |
| D7 | **Referência do ADC = saída do LDO** | ±1 % de tolerância vira erro de ganho directo |
| D8 | **Satura a 20,4 mA** | Não lê o alarme alto de 21 mA da NAMUR NE43 |
| D9 | **Zero pontos de prova e zero fiduciais** | |
| D10 | **`R34` com pinos trocados** entre esquemático e placa | No projecto original; inócuo mas prova dessincronização |

```yaml
evidencia:
  skill: 2shw-pcb:escopo
  artefatos: [escopo_EBM2_V5.md, escopo_EBM2_V5_gaps.md, plano_teste_EBM2_V5_esqueleto.md]
  criterios_aceite_definidos: 22   # 23 na assinatura; RD3 retirado em 2026-09-23
  gaps_bloqueantes: 1
  gaps_resolvidos: 1
  kick_off_gravado: nao
  requisitos_respondidos_pelo_projectista: 5
  avanco_escopo_pct: 85
  blocos_biblioteca_usados: []
```

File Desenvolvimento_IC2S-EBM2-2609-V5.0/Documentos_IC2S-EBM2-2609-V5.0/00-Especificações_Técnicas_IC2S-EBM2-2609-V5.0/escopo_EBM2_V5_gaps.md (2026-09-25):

---
documento: Revisão adversarial do escopo
projecto: IC2S Extension Board EBM2 V5 (6AI)
fase: F0, etapa 2
data: 2026-09-23
alvo: escopo_EBM2_V5.md
---

# Revisão adversarial — escopo da EBM2 V5

> **Limitação declarada.** A skill pede que esta revisão corra num **segundo
> modelo**. Não correu: foi feita em passada separada pelo mesmo modelo que
> redigiu o escopo. Vale como pré-revisão. Antes do Portão 0 devia correr uma
> passada independente — é a única forma de apanhar o que o autor não vê por ser
> autor.

Cada achado é uma **pergunta directa ao responsável**, não uma afirmação.

---

## ✅ RESOLVIDO

### G1 — RESOLVIDO em 2026-09-23 pelo projectista, e o raciocínio muda

**Resposta:** *"el firmware hace la conversion para calibrar primeramente, pero
no lo realiza en las células de carga"*.

O firmware **calibra** os canais de 4-20 mA. Logo `RC4` e `RE1` **não estão em
conflito**: mudar `VREF` e o burden é absorvido pela calibração, e o firmware
existente continua a funcionar sem recompilar.

Mas a resposta obriga a refazer a justificação da referência, e o resultado é
melhor do que o anterior:

> **A calibração remove o erro INICIAL. Não remove a deriva térmica.**

Com `RB1` fixado em **−40 a +85 °C**, o que decide `RE1` deixa de ser a
tolerância de fábrica e passa a ser o **coeficiente de temperatura**. Excursão
máxima a partir dos 25 °C de calibração: 60 °C.

| Configuração | Deriva da referência | Deriva do burden | Total (RSS) | Cumpre `RE1`? |
|---|---|---|---|---|
| Actual: `SPX3819` + `CRCW` 1 % | 57 ppm/°C × 60 = 0,342 % | 100 ppm/°C × 60 = 0,600 % | **0,69 %** | **Não**, 3,5× acima |
| Só apertar o burden a `ERA-3AEB` | 0,342 % | 25 ppm/°C × 60 = 0,150 % | 0,37 % | **Não** |
| `ADR4525` + `ERA-3AEB` | 2 ppm/°C × 60 = 0,012 % | 0,150 % | **0,15 %** | **Sim** |

**Conclusões que mudam a selecção de peças:**

1. A referência de precisão **continua a ser necessária**, mas o critério de
   escolha é o **coeficiente de temperatura**, não a exactidão inicial. Isto
   abre a porta a referências de tolerância inicial folgada e bom TC, que são
   mais baratas. Mantém-se o `ADR4525` porque já está em BOM da casa, mas a
   razão escrita tem de ser 2 ppm/°C e não ±0,02 %.
2. O **burden domina** o orçamento depois da calibração. Passar de `CRCW`
   (100 ppm/°C) a `ERA-3AEB` (25 ppm/°C) vale mais do que qualquer outra
   alteração isolada.
3. O **valor** do burden fica livre: a calibração absorve-o. Logo 110 Ω passa a
   ser escolha livre, e resolve `RM2` sem custo.

> **Duas correcções a esta secção, feitas na F1 de 2026-09-23.** A tabela acima
> e as três conclusões continuam a apontar para as mesmas peças, mas duas
> premissas mudaram:
>
> - A excursão correcta a partir dos 25 °C é **65 °C**, não 60, porque o extremo
>   frio de `RB1` está a −40 °C. Os números da tabela sobem cerca de 8 %, e
>   nenhuma linha muda de veredito.
> - A conclusão 3 dizia que o valor do burden era livre «porque a calibração o
>   absorve». Com **constante comum**, a calibração absorve o nominal mas **não**
>   a dispersão. O valor continua livre; a tolerância inicial deixou de estar.
>   Ver `planejamento_pcb_EBM2_V5.md` §2.5b.

**Ressalva por confirmar (G1b):** o coeficiente de 57 ppm/°C do `SPX3819` foi
lido de uma linha de tabela que a extracção de texto devolveu **desordenada**
(`1016_SPX3819.pdf`, tabela de características eléctricas). Confirmar a olho no
PDF antes de congelar. Não muda a conclusão — muda só quanto se falha na opção
que se rejeita.

**Ressalva por confirmar (G1c):** a calibração é **por unidade**, feita em
produção a cada placa, ou é uma constante de fábrica igual para todas? Só a
primeira remove a tolerância de fábrica. Se for constante comum, o erro inicial
do LDO volta ao orçamento e o `ADR4525` passa a ser necessário também pela
exactidão inicial, não só pelo TC.

**Nota do projectista sobre a EBM7:** *"creo que por eso no lo tomamos en cuenta
en la ebm7"*. Faz sentido: a EBM7 tem célula de carga, e uma ponte é
intrinsecamente **ratiométrica** — o sinal é proporcional à excitação, portanto
o erro da referência cancela-se sozinho se a mesma referência alimentar as duas
coisas. Nos canais de 4-20 mA isso não acontece: ali a referência entra directa
no erro de ganho.

---

## 🔴 BLOQUEANTE

### G1-histórico — o conflito, tal como foi levantado (mantido como registo)

**`RC4` diz que o firmware existente continua a funcionar. `RE1` diz que a
exactidão absoluta passa a 0,1-0,2 %. São incompatíveis.**

O firmware converte contagens do ADC em miliamperes com a referência e o burden:

```
I = (contagem / 4096) x VREF / R_burden
```

Hoje: `VREF` = 3,3 V (saída do LDO) e `R_burden` = 160 Ω. Chegar a 0,1-0,2 %
obriga a uma referência de precisão, e **nenhum caminho mantém a constante**:

| Caminho | Constante muda? | Porquê não serve |
|---|---|---|
| Referência de 2,5 V | **Sim** | `VREF` passa de 3,3 para 2,5 V |
| Referência de 3,0 V | **Sim** | Idem |
| Referência de 3,3 V | Não | **Não cabe**: o `MCP3208` exige `VREF ≤ VDD`, e `VDD` vem do `SPX3819` a ±1 %, ou seja pode estar em 3,267 V |
| Só apertar o burden a 0,1 % | Não | Fica em **~±1,0 %**, porque o ±1 % do LDO continua lá. Não cumpre `RE1` |

E há uma terceira perna: `RM2` pede fundo de escala ≥ 20,5 mA. Com 160 Ω e
`VREF` de 3,3 V a −1 %, o fundo de escala é **20,42 mA**. Também não cumpre.

**Pergunta ao responsável, e é a que desbloqueia tudo:**
o firmware da base board converte com uma **constante compilada** ou com um
**parâmetro de calibração** que se pode alterar por configuração? Se for
parâmetro, `RC4` sobrevive com uma nova constante e não há conflito. Se for
constante compilada, é preciso escolher: **ou `RC4` ou `RE1`**, e o escopo tem
de dizer qual cai.

**Não se avança para a F1 sem esta resposta.** Toda a secção de medida depende
dela, e o trabalho já feito nas folhas `02_entrada` e `03_alimentacao` assumiu
`RE1`.

### G2 — RESOLVIDO em 2026-09-23 lendo os projectos da Base Board e da MainBoard

**Evidência.** O projectista deu acesso a `Main_Board-Hachacthon` e
`Base_Board-Hachathon`. Traçou-se o caminho completo pelas netlists das duas.

**O mestre SPI é uma Raspberry Pi, ligada directamente.** Na MainBoard, `J1` é um
conector de 200 posições a 0,6 mm (`1565917-4`) para módulo Raspberry. O SPI sai
dos seus GPIO e vai ao conector de extensão **sem nenhum adaptador de nível**:

| Sinal | Pino da Pi | Vai a |
|---|---|---|
| MOSI | `J1.33` GPIO10 / SPI0_MOSI | `J2B.18` |
| CLK | `J1.35` GPIO11 / SPI0_SCLK | `J2B.19` |
| MISO | `J1.29` GPIO9 / SPI0_MISO | `J2B.20` |
| CS_ADC | `J1.23` GPIO7 / SPI0_CE1_N | `J2B.23` |

O GPIO de uma Raspberry trabalha a **3,3 V** e não é tolerante a 5 V.

**Sentido de ida (Pi → isolador): NÃO há problema. O achado anterior era falso.**

O `ISO7141` tem **limiares TTL**, não CMOS: *"have TTL input thresholds"*
(`TI_ISO7141CC.pdf`, pág. 1), com **VIH mínimo de 2,0 V** independente do `VCC`.
Os 3,3 V da Pi entram com 1,3 V de margem mesmo com `VCC1` a 5 V.

> **Correcção a um documento anterior.** O `EBM2_vs_EBM7_Comparacion.md` de
> 2026-08-11 dá isto como achado crítico, calculando *"V_IH = 3,5 V não
> atingido"*. Esses 3,5 V vêm de assumir limiar CMOS de 0,7 × VCC. **O ISO7141 é
> TTL.** O achado é um falso positivo e deve ser retirado desse documento.

**Sentido de volta (isolador → Pi): É AQUI que está o problema, e é real.**

O `OUTD` do `ISO7141` está do lado 1, alimentado por `VCC1` = 5 V. O datasheet
dá `VOH` = `VCCO` − 0,1 a IOH = −4 mA, ou seja **~4,9 V**. Esse nível sai por
`P1.6` em direcção ao GPIO9 da Pi.

A Base Board tem protecção: `D54`, um díodo duplo de comutação com ânodo em
`GNDI_3V3` e cátodo em `+3.3V_IC`, com o ponto comum em `MISO`. É um grampo de
duplo rail a 3,3 V, e existe igual em todas as linhas do bus (`D55` MOSI, `D57`
SCK, `D56` CS, `D29` SDA, `D30` SCL).

Mas o grampo fixa a linha em **3,3 + 0,7 ≈ 4,0 V**, e:

1. O absoluto máximo de um GPIO da Pi é ~3,8 V. **4,0 V fica acima.**
2. Não há resistência em série: o `ISO7141` a 5 V empurra contra o grampo
   **em cada bit alto**, com os seus 4 mA de capacidade.
3. A 4,0 V os díodos de ESD internos da própria Pi também começam a conduzir.

Ou seja: não é um circuito que não funciona — funciona, e está instalado. É um
circuito que **opera fora de especificação de forma contínua**, a stressar o
grampo da Base Board e as protecções da Pi em cada transacção SPI.

**A EBM7 já resolveu isto**, e é o que se porta: acrescentou um LDO de 3,3 V
dedicado ao lado 1 do isolador (`U8`, `MCP1824ST-3302E`). Com `VCC1` a 3,3 V o
`VOH` passa a ~3,2 V e o problema desaparece por inteiro, nos dois sentidos.

**Acção para a V5:** portar o LDO de 3,3 V para alimentar `VCC1` e `EN1` do
`ISO7141`, em vez dos +5 V do barramento. Custo: um LDO e dois condensadores,
peça já em BOM da casa. **Isto entra no âmbito da revisão.**

### G2-histórico — como a questão foi levantada (mantido como registo)

O `ISO7141` tem `VCC1` alimentado pelos **+5 V** do barramento (`P1.17`), e os
sinais `MOSI`, `CLK` e `CS_ADC` entram da base board. Se o mestre trabalha a
**3,3 V**, o limiar de entrada de um isolador alimentado a 5 V pode não ser
atingido.

Isto vem da V4.1 e **nunca foi medido**. O documento
`EBM2_vs_EBM7_Comparacion.md` de 2026-08-11 já o levantava, e a EBM7 resolveu-o
acrescentando um LDO de 3,3 V dedicado ao lado 1 do isolador (`U8`,
`MCP1824ST-3302E`). **A EBM2 não tem esse LDO.**

**Perguntas:** qual é a tensão de alimentação do mestre SPI na base board? E se
for 3,3 V, porta-se também o LDO da EBM7 para o lado 1 do isolador, ou fica como
desvio declarado?

Nota: se a placa funciona hoje em campo, isso é evidência de que o limiar se
atinge — mas evidência de funcionamento não é margem. Pode estar a funcionar
sem margem nenhuma e a falhar em temperatura.

---

## 🟠 IMPORTANTE

### G3 — `RB1` (−40 a +85 °C) contra os electrolíticos da V4.1

A V4.1 monta `C12` e `C28`, `ESL107M050AGMAA`, electrolíticos de 100 µF/50 V.
A −40 °C um electrolítico perde capacidade e a sua ESR sobe muito. `RB2` exige
gama declarada ou substituição.

**Pergunta:** confirma-se a substituição por cerâmicos de 100 V, que já era
necessária por `D6` (a tensão de clamp), e que resolve a gama de uma vez?

> **FECHADO na F1, 2026-09-23.** Sim. Os electrolíticos saem e entram cerâmicos
> `GRM32EC72A106ME05L` de 10 µF/100 V em 1210, X7R, gama −55 a +125 °C.
> Consequência secundária: depois desta troca as **únicas peças THT da placa são
> os dois conectores**, o que fecha também o `G9`. Dono: projectista.

### G4 — O critério `RA2` não se pode verificar: falta o datasheet do fusível

`RA2` exige margem de I²t ≥ 10×. Para a rama dos laços há o número
(`CC12H750MA-TR`, 0,15 A²s, confirmado no datasheet na F1). Para a rama do regulador,
onde se propôs **100 mA retardado**, não há: a tabela de selecção Eaton `CC12H`
**não está na pasta de referência**, e o ficheiro que tem esse nome contém, no
conteúdo, o datasheet do `ADR4525`.

**Pergunta:** consegue-se o datasheet da série? Sem ele, ou se mantém 750 mA nas
duas ramas — que não protege a rama de 5 mA — ou o critério `RA2` fica sem
verificação nessa rama.

> **FECHADO na F1, 2026-09-23 — e a premissa deste gap era FALSA.**
>
> A tabela Eaton **está na pasta desde sempre**, com o nome
> `Eaton_fusible_lento.pdf`. Este gap nasceu de procurar por nome de ficheiro e
> ler o silêncio como ausência. O erro e o seu custo estão em
> `planejamento_pcb_EBM2_V5.md` §9.
>
> O que a tabela diz, e que muda o projecto:
>
> 1. **A série `CC12H` não tem 100 mA.** Começa em 250 mA. O `F1` que se tinha
>    especificado não é encomendável.
> 2. Com `CC12H250mA` (I²t de fusão 0,000 38 A²s, 3 500 mΩ a frio) e os 2,2 µF
>    de `C1`, a margem de arranque é **2,1×**, e `RA2` exige 10×. **Reprovava.**
> 3. Nenhuma outra peça da série resolve: 375 mA dá os mesmos 2,1× e 500 mA dá
>    2,9×, porque o I²t e a resistência movem-se em sentidos opostos.
> 4. **Resolve-se com uma peça nova**, a resistência `R3` de 22 Ω em 0805 em
>    série na rama, que leva a margem a **15,3×** ao custo de 0,26 V de queda e
>    3,2 mW. Dimensionamento completo em `planejamento_pcb_EBM2_V5.md` §2.6.
>
> **Sem abrir este ficheiro, a placa teria ido para fabrico com um part number
> inexistente e, depois de o corrigir para o mais próximo, com um fusível que
> abre no arranque** — exactamente a avaria que esta revisão existe para curar.

### G5 — `RA3` inventa um nível de surto que ninguém especificou

Escrevi *"surto de 1 kV segundo IEC 61000-4-5"*. **Esse número é meu, não vem de
nenhum requisito nem de nenhum documento.** O TVS escolhido é o mesmo da EBM7,
mas o nível de imunidade exigido ao produto nunca foi declarado.

**Pergunta:** existe requisito de imunidade a surto para esta família? Se não
existe, `RA3` tem de ser reescrito como *"o TVS existe e está dimensionado para
o rail"*, sem número, ou o número tem de vir de alguém.

> **FECHADO na F1, 2026-09-23.** Resposta do projectista: **não há requisito
> escrito**. O número saiu do escopo e `RA3` foi reescrito como critério de
> projecto, sem nível de ensaio. Sem nível declarado não há ensaio de surto, e o
> item `T11` do plano de teste fica sem objecto. Dono: projectista.

### G6 — `RA4` fixa 3,7 V sem derivar o limite das peças

`RA4` diz que `3V3_REF` não pode passar de 3,7 V. Esse valor sai do ponto de
grampeamento do `TL431` (3,60 V) mais margem, não de um absoluto máximo. O
correcto é derivá-lo: listar **todos** os pinos ligados a `3V3_REF` e o seu
absoluto máximo **com as notas de rodapé**, e fixar o critério pelo mais
restritivo.

**Pergunta:** aceita-se que este critério fique provisório até à etapa 2.3b, que
é onde a tabela de aplicação se faz?

> **ADIADO por decisão, não por esquecimento. Dono: esta sessão. Data-limite:
> etapa 2.3b da F2.** A tabela de aplicação é o artefacto que deriva o limite, e
> derivá-lo antes de a tabela existir seria repetir exactamente o erro que o
> `G5` acabou de expor: escrever um número sem fonte.

### G7 — `RD3` não é verificável com o que existe

`RD3` exige acesso mecânico aos pontos de prova com a placa montada no quadro.
Não há desenho de invólucro nem descrição do quadro no material disponível.

**Pergunta:** existe desenho do quadro ou fotografia da placa instalada? Sem
isso o critério não se pode fechar e devia sair do escopo ou passar a
especificação aberta.

> **FECHADO na F1, 2026-09-23.** Resposta do projectista: **não há plano**. O
> critério `RD3` foi retirado do escopo e o item `T22` do plano de teste fica
> sem objecto. Volta no dia em que houver desenho. Dono: projectista.

---

## 🟡 MENOR

### G8 — Custo-alvo não declarado
Nenhuma peça nova entra: todas já estão em BOM de outra placa da casa. Mas o
escopo devia dizer "sem custo-alvo declarado" em vez de omitir.

### G9 — Vibração e choque não declarados
Quadro industrial. Provavelmente irrelevante para SMD pequeno, mas os dois
electrolíticos THT de 8×11 mm são a peça com mais massa da placa. Se se passarem
a cerâmicos por G3, o ponto desaparece sozinho.

### G10 — `RM3` pode mover-se se o burden mudar
O corte de 482 Hz sai de 3,3 kΩ com 100 nF. Se G1 se resolver a favor de mudar o
burden, o corte quase não se move, mas a impedância de fonte vista pelo ADC sim.
Revisitar na 2.3b.

> **FECHADO na F1, 2026-09-23.** O burden ficou nos 110 Ω, portanto o corte não
> se move. E a impedância de fonte ficou quantificada contra o datasheet do
> conversor em `planejamento_pcb_EBM2_V5.md` §2.7d: os 3,3 kΩ custam menos de
> 1 LSB abaixo de 4 kHz por canal, **desde que o condensador de 100 nF fique
> encostado ao pino**. Essa condição passou a requisito de layout da F3.

### G11 — Os três LED indicadores não foram reavaliados
Na V4.1 penduram dos rails de laço com 14,7 kΩ. Ao fundirem-se os dois rails de
laço num só, a contagem de LED e a sua corrente devem ser reconfirmadas. Entram
nos 4,5 mA de `RA5` mas ninguém verificou a queda directa a −40 °C.

### G12 — Número de camadas assumido, não confirmado
O escopo assume 4 camadas por `RC1`. A V4.1 é de 4 camadas, medido nos Gerbers.
Mas `RC1` congela o contorno, não o empilhamento. Confirmar na F1.

> **FECHADO na F1, 2026-09-23.** Quatro camadas, confirmado pelo projectista.
> A medição nos Gerbers e a resposta coincidem.

### G13 — NOVO, aberto na F1: falta o datasheet do `MCP3208`

Levantado em 2026-09-23, depois de o `G1c` fechar com «constante comum a todas».

O `MCP3208` é o componente central da placa e **o seu datasheet não existe em
nenhuma pasta do projecto**. Procurou-se em todo o OneDrive, em `C:\hw` e nas
Descargas: aparecem o `MCP3201` e o `mcp3202`, da mesma família, mas **não são a
mesma peça** e nenhum serve como substituto.

Enquanto se pensou que a calibração era por unidade, isto não incomodava: a
calibração removeria os erros de ganho e offset do conversor. **Com constante
comum, não remove.** Os erros próprios do `MCP3208` entram no orçamento de
`RE1`, e os termos já conhecidos somam **0,182 %** contra um tecto de 0,2 %.
Sobram 0,018 % para o conversor, e um erro de ganho de ±1,5 LSB num ADC de
12 bits vale sozinho 0,037 %.

**Pergunta:** fornece-se o PDF, ou autoriza-se a busca na internet? A F1 só
procura datasheets online com autorização explícita, por isso a sessão **não
procurou**.

> ## FECHADO em 2026-09-23: o datasheet chegou, e o resultado é pior do que o alarme
>
> O projectista forneceu o `DS21298E`. **As duas estimativas anteriores desta
> secção estavam erradas, em sentidos opostos**, e a verdade está em
> `planejamento_pcb_EBM2_V5.md` §2.7.
>
> O que o datasheet mostra, e que nenhuma estimativa podia adivinhar: **os erros
> de offset e de linearidade do `MCP3208` são tensões fixas, não fracções.**
> As figuras 2-18 e 2-2 mostram o erro em LSB a duplicar quando `VREF` desce de
> 5 V para 2,5 V, ou seja a tensão de erro fica igual. Como a nossa referência é
> de 2,5 V, o sinal é metade e o erro relativo é o dobro.
>
> | Cenário, limites máximos | `RE1` | Veredito |
> |---|---|---|
> | Grau `-C` (o que estava desenhado), constante comum | 0,256 % | reprova |
> | Grau `-B`, constante comum | 0,237 % | reprova |
> | Trilho de 5 V, referência 4,096 V, burden 180 Ω, constante comum | 0,201 % | reprova |
> | **Grau `-B`, calibração por unidade de dois pontos** | **0,055 %** | **cumpre** |
>
> **Com constante comum não há escolha de componente que feche `RE1`.** Isto
> deixa de ser um gap e passa a ser uma decisão de produto, registada como tal
> no planeamento. O gap fecha-se porque a incerteza acabou.
>
> Três achados adicionais do mesmo datasheet, todos sobre coisas **herdadas da
> V4.1 e nunca verificadas**: o mapa de canais não é sequencial (campo em
> `CH0`-`CH3`, `CH6`, `CH7`), o divisor do termístor saturaria a 70 °C com a
> referência nova, e o desacoplamento do `VDD` é de 100 nF quando a §6.4 pede
> 1 µF.
>
> ---
>
> **Registo da estimativa anterior, que ficou por baixo do valor real.** O
> parágrafo acima somava num só número as tolerâncias iniciais e as derivas. **São dois
> orçamentos separados**, porque o escopo os separa: `RE1` mede a 25 °C, onde só
> contam as tolerâncias iniciais, e `RE2`/`RB3` medem o erro **adicional** em
> temperatura, onde só contam as derivas. Refeita a conta:
>
> | Critério | Termos conhecidos | Tecto | Espaço para o `MCP3208` |
> |---|---|---|---|
> | `RE1`, a 25 °C | 0,102 % | 0,2 % | **0,172 %** |
> | `RE2` e `RB3`, em temperatura | 0,163 % | 0,2 % | **0,116 %** |
>
> Os dois passam. O datasheet continua a fazer falta, mas para **confirmar** um
> termo com folga, não para descobrir se a placa cumpre.
>
> **E o travão que este gap propunha não existe.** A tabela de *Ratings* do
> datasheet Panasonic `AOA0000C307`, pág. 2, mostra que em 0603 o grau de
> ±10 ppm/°C só começa em **1 kΩ** e o de ±15 ppm em **470 Ω**. A 110 Ω, o
> `ERA3AEB` de ±0,1 % e ±25 ppm/°C **é o melhor que a família oferece**. Se
> algum dia for preciso apertar, terá de ser noutro fabricante, e isso é uma
> decisão de sourcing, não uma troca de sufixo.

---
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

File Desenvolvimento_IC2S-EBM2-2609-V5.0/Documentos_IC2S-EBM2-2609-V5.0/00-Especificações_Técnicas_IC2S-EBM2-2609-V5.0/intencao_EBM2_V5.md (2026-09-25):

# Documento de intenção — IC2S Extension Board EBM2 V5 (6AI)

| | |
|---|---|
| Projecto | IC2S Extension Board EBM2, 6 entradas 4-20 mA |
| Revisão do documento | **2** — reescrita em 2026-09-23 depois da F0, da F1 e do datasheet do `MCP3208`. **Rev. 2.4 (2026-09-24): limitador `AL5809` → `TPS26613`, copiado da EBM7 V2.3 Legacy (§9)**. **Rev. 2.5 (2026-09-24): correcções da 2.3b rev. 2.4 (§17)** |
| Fase | F2, etapa 2.2a |
| Autoridade | **Este documento manda até ao primeiro ERC limpo.** A partir daí manda o `.kicad_sch` e este texto congela como registo de intenção. O ERC ainda não está limpo: faltam as folhas 01, 04, 05, 06 e 07 |
| Base | `planejamento_pcb_EBM2_V5.md` rev. 3 e a V4.1 convertida e auditada, copiada antes de inventar |
| Histórico | A revisão 1 está em `intencao_EBM2_V5_rev1_historico.md`. Ficou superada em oito pontos |

> ## ✅ APROVADO pelo projectista em 2026-09-23
>
> Javier Rivadineira aprovou esta revisão 2 em 2026-09-23 («documento aprobado»).
> A aprovação cobre a especificação das folhas 01, 04, 05, 06 e 07, a proposta de
> LED da §11 e o diagrama de blocos da etapa 2.1. **Não cobre**, porque são
> decisões à parte e continuam abertas: a `V8` (transmissor em curto, antes do
> Portão 1) e o critério `RE1` (pior caso ou típico, Portão 0). A 2.2b desenha-se
> com o que está especificado; se a `V8` pedir peças novas, entram depois.

> **Para o projectista rever antes de se desenhar qualquer folha nova.** A
> skill exige esta aprovação entre a 2.2a e a 2.2b. As folhas 02 e 03 já estão
> desenhadas e verificadas; as secções delas descrevem o que está no CAD. As
> folhas 01, 04, 05, 06 e 07 **ainda não existem**, e é sobre elas que esta
> revisão pede aprovação.

---

## 1 · O que este documento decide, em poucas linhas
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

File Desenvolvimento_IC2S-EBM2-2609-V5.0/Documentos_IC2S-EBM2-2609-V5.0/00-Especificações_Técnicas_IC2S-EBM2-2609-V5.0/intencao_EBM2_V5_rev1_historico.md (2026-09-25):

# Documento de intenção — IC2S Extension Board EBM2 V5 (6AI)

> # ⚠ SUPERADO EM OITO PONTOS — 2026-09-23
>
> Este texto foi escrito **antes** de existir F0 e F1. As duas fases correram
> depois, no mesmo dia, e **`planejamento_pcb_EBM2_V5.md` manda sobre este
> documento** em tudo o que se contradiga. Os quatro pontos conhecidos:
>
> 1. **O fusível da rama do regulador não pode ser de 100 mA.** A série Eaton
>    `CC12H` não tem essa corrente: começa em 250 mA. Passa a `CC12H250MA-TR`.
> 2. **Falta uma peça:** a resistência `R206` de 22 Ω em 0805, em série na rama
>    do regulador. Sem ela a margem de I²t é 2,1× e o critério `RA2`, que exige
>    10×, reprova. Com ela são 15,3×.
> 3. **As unidades de I²t deste documento estão erradas por um factor de 10⁶.**
>    Onde se lê mA²s deve ler-se A²s. Os rácios e as conclusões não mudam.
> 4. **A calibração é uma constante comum a todas as placas**, não por unidade.
>    A tolerância inicial de cada peça, por isso, **não** se calibra. O orçamento
>    de erro refez-se em duas contas separadas, a de 25 °C e a de temperatura, e
>    ambas passam.
>
> **Mais quatro pontos, depois de o datasheet `DS21298E` do conversor chegar:**
>
> 5. **O mapa de canais do ADC não é sequencial.** Os seis canais de campo estão
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

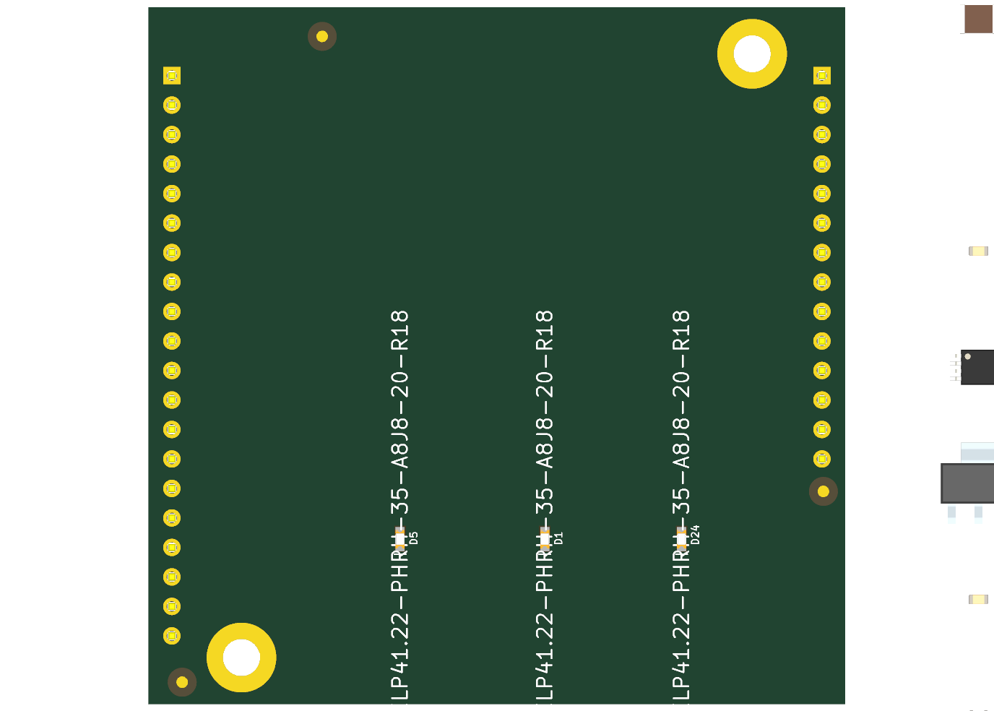
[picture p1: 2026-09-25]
Desenvolvimento_IC2S-EBM2-2609-V5.0/Documentos_IC2S-EBM2-2609-V5.0/00-Especificações_Técnicas_IC2S-EBM2-2609-V5.0/F3_Layout/F3_contorno_top.png

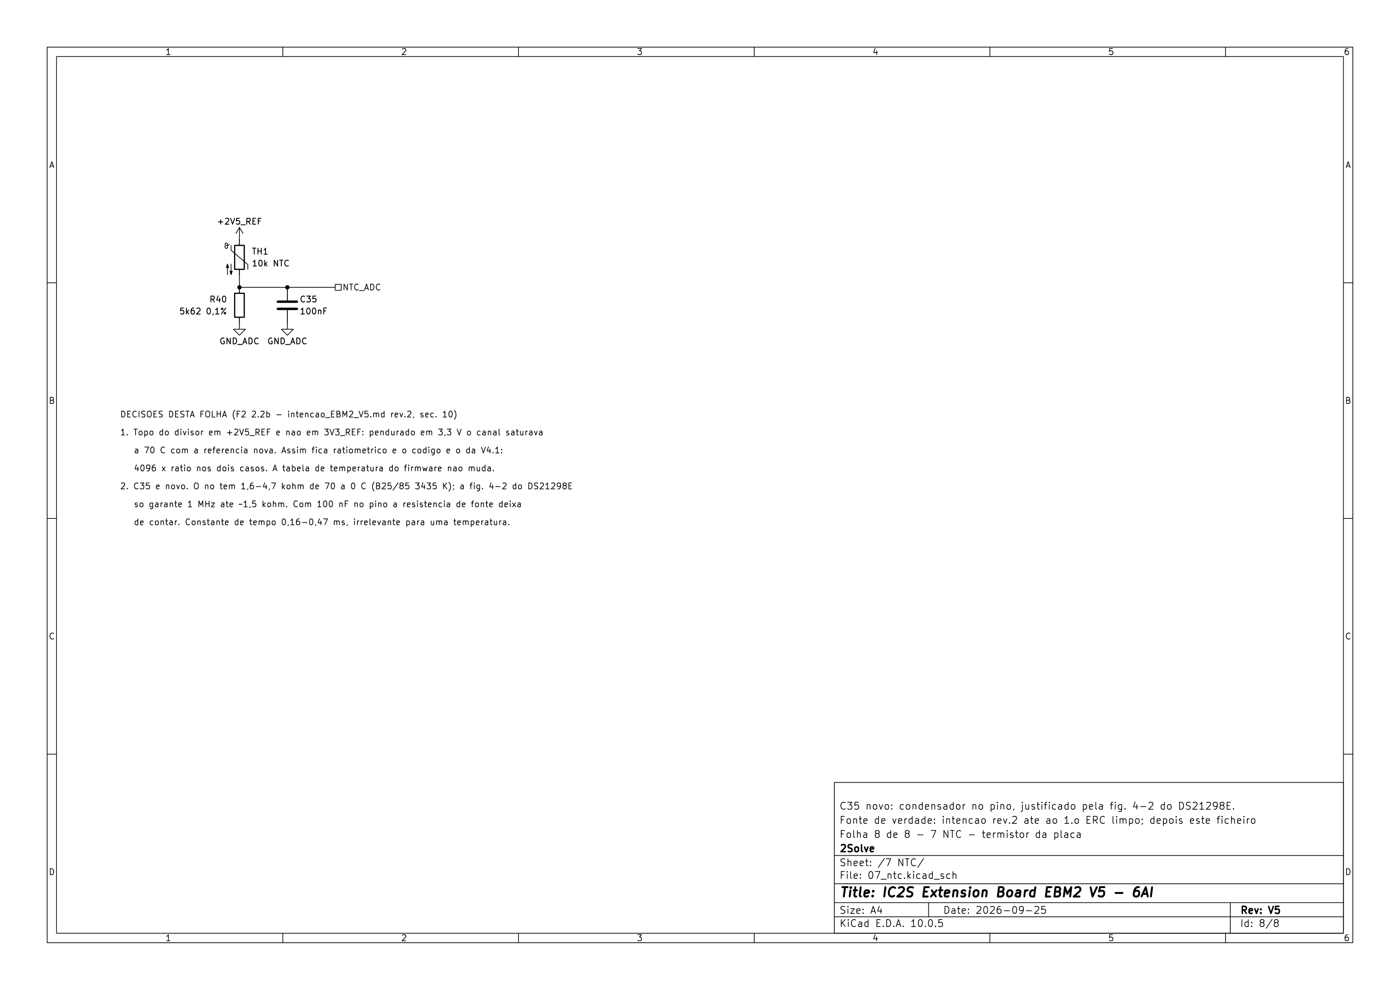
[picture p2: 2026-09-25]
Desenvolvimento_IC2S-EBM2-2609-V5.0/Documentos_IC2S-EBM2-2609-V5.0/01-Esquemáticos_IC2S-EBM2-2609-V5.0/png/IC2S_Extension_Board-EBM2_V5-7 NTC.png

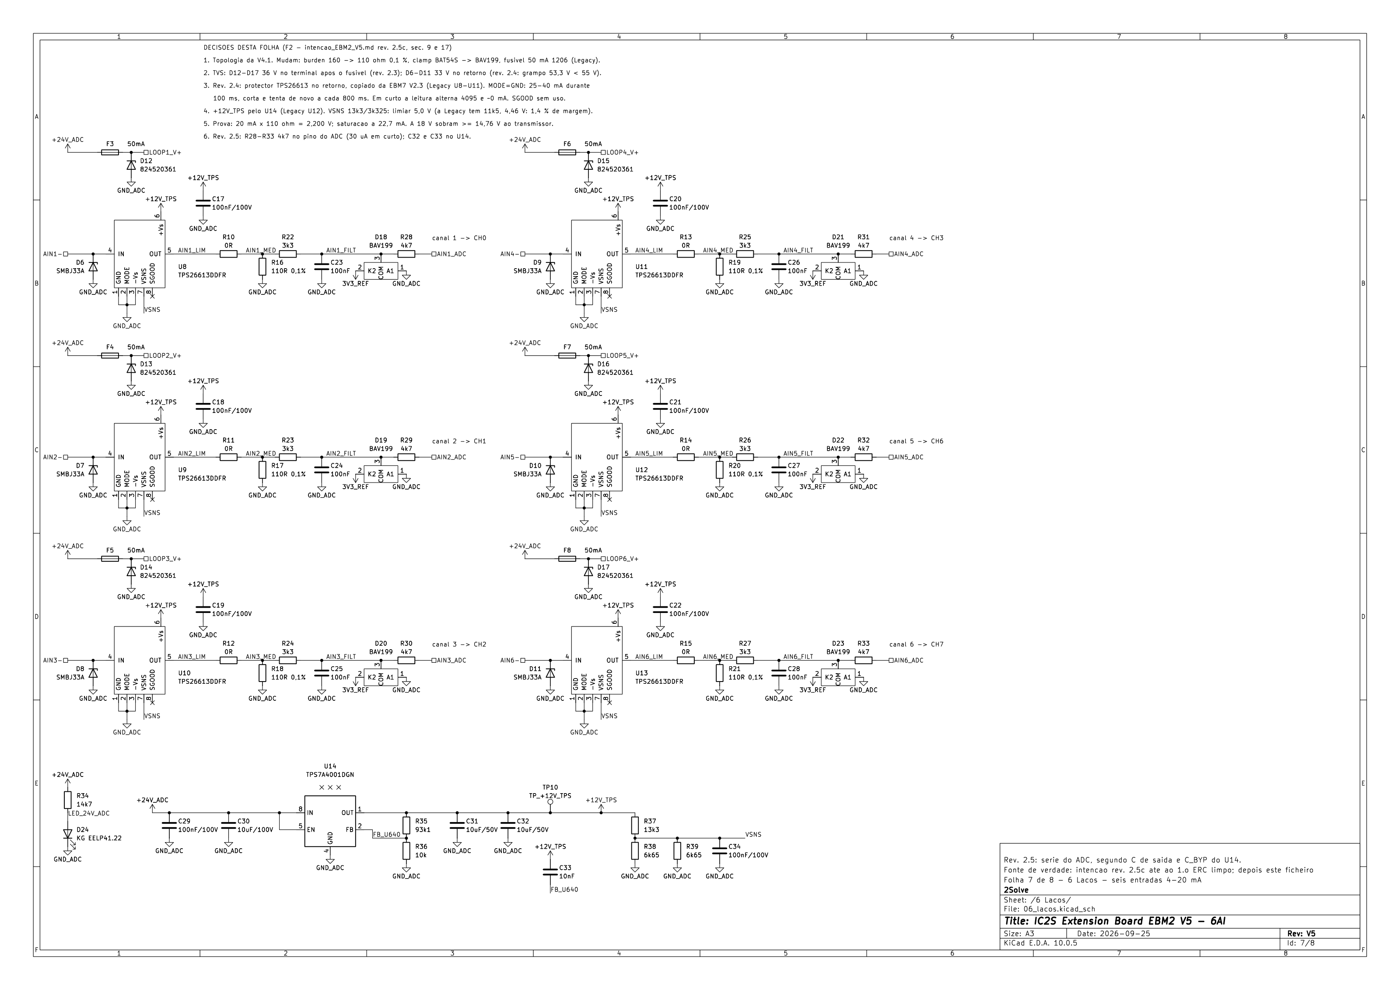
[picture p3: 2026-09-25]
Desenvolvimento_IC2S-EBM2-2609-V5.0/Documentos_IC2S-EBM2-2609-V5.0/01-Esquemáticos_IC2S-EBM2-2609-V5.0/png/IC2S_Extension_Board-EBM2_V5-6 Lacos.png

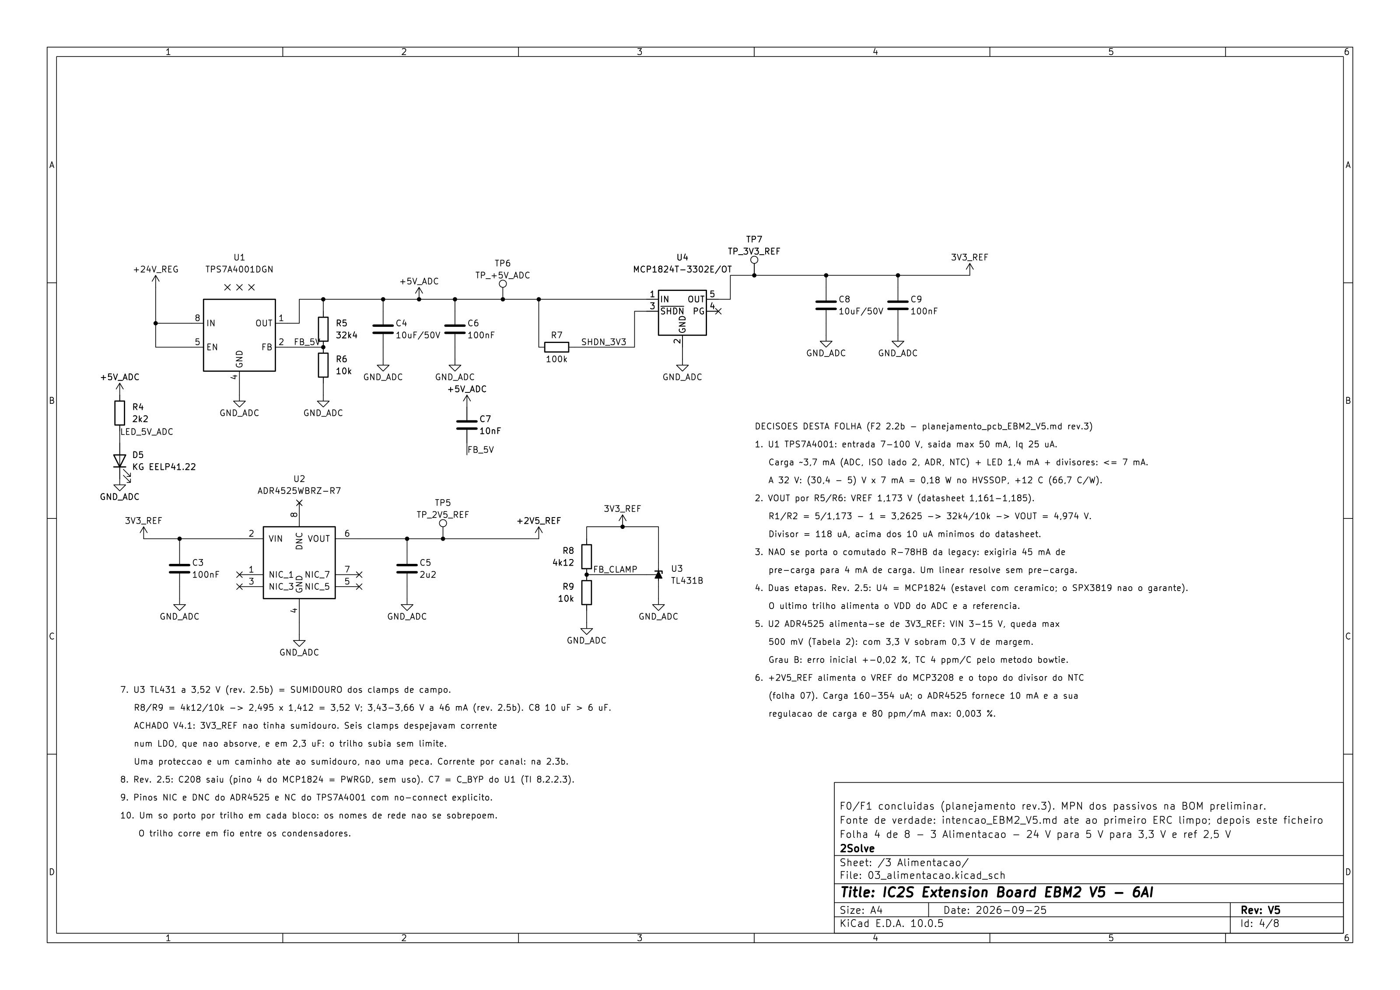
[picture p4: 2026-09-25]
Desenvolvimento_IC2S-EBM2-2609-V5.0/Documentos_IC2S-EBM2-2609-V5.0/01-Esquemáticos_IC2S-EBM2-2609-V5.0/png/IC2S_Extension_Board-EBM2_V5-3 Alimentacao.png

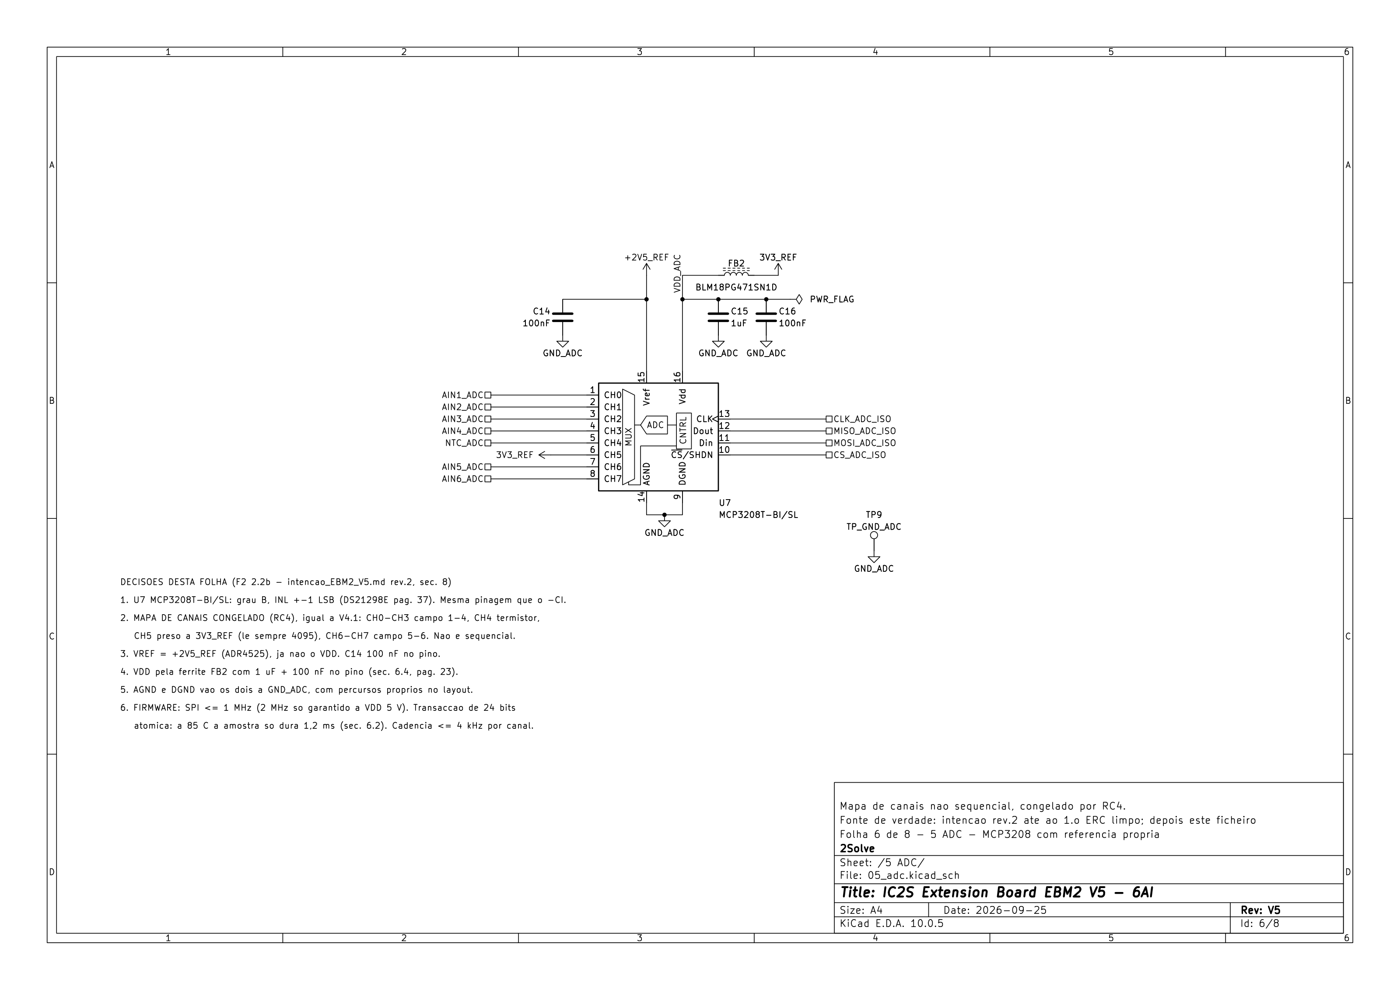
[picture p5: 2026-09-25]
Desenvolvimento_IC2S-EBM2-2609-V5.0/Documentos_IC2S-EBM2-2609-V5.0/01-Esquemáticos_IC2S-EBM2-2609-V5.0/png/IC2S_Extension_Board-EBM2_V5-5 ADC.png

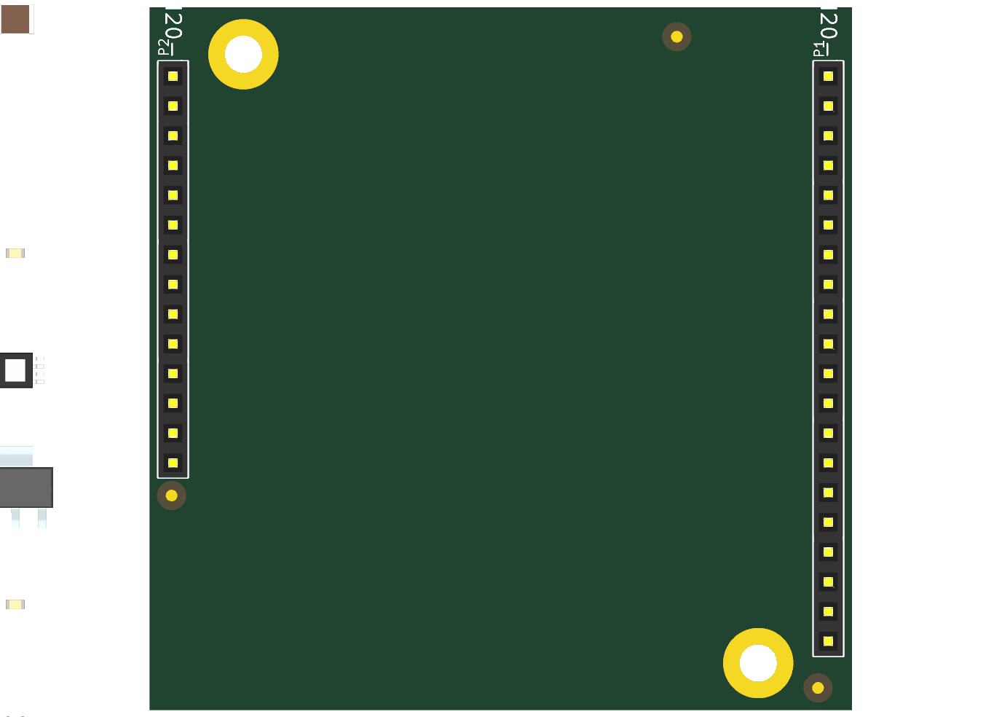
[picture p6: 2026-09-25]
Desenvolvimento_IC2S-EBM2-2609-V5.0/Documentos_IC2S-EBM2-2609-V5.0/00-Especificações_Técnicas_IC2S-EBM2-2609-V5.0/F3_Layout/F3_contorno_bottom.png

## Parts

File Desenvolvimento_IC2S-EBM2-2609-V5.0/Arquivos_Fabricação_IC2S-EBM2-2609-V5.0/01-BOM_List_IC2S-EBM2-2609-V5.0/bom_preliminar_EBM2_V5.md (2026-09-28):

---
projeto: IC2S Extension Board EBM2 V5 (6AI 4-20 mA)
etapa: BOM preliminar (2shw-pcb:bom, modo preliminar)
netlist: EBM2_V5_2026-09-28.net
fonte_dados: Mouser Search API, consulta de 2026-09-25T06:09 + reconsulta 2026-09-25T06:10 + reconsulta 2026-09-25T06:38 + reconsulta 2026-09-25T07:09
moeda: USD
---

# BOM preliminar — EBM2 V5

**Só se liberta a Suprimentos com o Portão 1 assinado. Hardware não compra.**

Fonte dos dados comerciais: Mouser Search API, consulta de 2026-09-25T06:09 + reconsulta 2026-09-25T06:10 + reconsulta 2026-09-25T06:38 + reconsulta 2026-09-25T07:09. Ciclo de vida só com fonte e data; sem fonte é `N/D`, nunca «activo» por omissão.

## 1 · Alertas

- **Ciclo de vida fora de «activo»:** ADR4525WBRZ-R7 — Restricted Availability (Mouser 2026-09-25)
- **Sem dado Mouser:** 2 MPN.
- **Stock Mouser abaixo de 10 placas:**
  - KG EELP41.22-PHRH-35-A8J8-20-R18 (D1, D5, D24): 0 em stock para 3 por placa; alternativa verificada Q65113A7469: 15898 em stock
  - 3413.0002.22 (F3, F4, F5, F6, F7, F8): 0 em stock para 6 por placa; alternativa verificada 3413.0002.11: 8838 em stock
  - ISO7141CCDBQR (U6): 0 em stock para 1 por placa; alternativa verificada ISO7141CCDBQ: 0 em stock

### Alternativas verificadas (mesma peça eléctrica, conferida no datasheet)

| Principal | Alternativa | Stock Mouser | Evidência |
|---|---|---:|---|
| `ADR4525WBRZ-R7` | `ADR4525BRZ` | N/D | O MPN original: mesmo grau B em tubo de 98; na Mouser sem preço nem stock e «Restricted Availability» (2026-09-25). A WBRZ-R7 entrou na tanda B por isso (ADR45xx Rev. G, tabela 14 pág. 40, nota 2 pág. 41) |
| `3413.0002.22` | `3413.0002.11` | 8838 | Mesma linha eléctrica (50 mA, 63 VDC, 9200 mΩ, 0,0002 A²s); só muda a embalagem: 100 un. em fita (Schurter USFF, págs. 3-4) |
| `KG EELP41.22-PHRH-35-A8J8-20-R18` | `Q65113A7469` | 15898 | Código de encomenda OSRAM do mesmo tipo e bin, KG EELP41.22-PHRH-35-A8J8 (datasheet v1.4 pág. 3) |
| `ISO7141CCDBQR` | `ISO7141CCDBQ` | 0 | Mesma peça, tubo de 75 em vez de bobina de 2500 (TI, package option addendum pág. 27) |

## 2 · Linhas (41, 123 componentes montados)

| Refs | Qtd | Valor | Pegada | Fabricante | MPN | Mouser | Stock | Unit. lote 1 | Unit. lote 10 | Unit. lote 100 | Ciclo de vida | Origem | Notas |
|---|---:|---|---|---|---|---|---|---:|---:|---:|---|---|---|
| C1 | 1 | 2u2/100V | C_1210_3225Metric | N/D | `C3225X7R2A225K230AB` | 810-C3225X7R2A225K | 30005 | 0.7800 | 0.4880 | 0.3380 | Production (ficha TDK 2026-09-25) | NOVO | C1: curva TDK ~1,54 uF a 30,4 V; pior caso 1,18 uF > 1 uF (TPS7A4001); RA2 11,3x. X7S 1206 descartado (0,89 uF) |
| C2, C30 | 2 | 10uF/100V | C_1210_3225Metric | Murata | `GRM32EC72A106ME05L` | 81-GRM32EC72A106ME5L | 35196 | 1.1800 | 0.7580 | 0.5420 | Activo (DigiKey 2026-09-24) | biblioteca 2Solve |  |
| C3, C6, C9, C12, C13, C14, C16, C17, C18, C19, C20, C21, C22, C23, C24, C25, C26, C27, C28, C34, C35 | 21 | 100nF/50V | 0603C | TDK | `C1608X7R1H104K080AA` | N/D | N/D | N/D | N/D | N/D | N/D | biblioteca 2Solve |  |
| C4, C8, C10, C31, C32 | 5 | 10uF/50V | C_1206_3216Metric | TDK | `C3216X5R1H106K160AB` | 810-C3216X5R1H106K | 124920 | 1.8500 | 0.9910 | 0.7820 | Production (ficha TDK 2026-09-24) | biblioteca 2Solve | Curva TDK conferida: C4 7,0 µF a 5 V, C8 7,2 µF a 3,3 V, C31+C32 8,9 µF a 12,6 V (pior caso) |
| C5, C11 | 2 | 2u2 | 0603C | TDK | `C1608X5R1E225K080AB` | 810-C1608X5R1E225K | 15300 | 0.2700 | 0.1610 | 0.0980 | Production (ficha TDK 2026-09-24) | biblioteca 2Solve | Curva TDK conferida (ficha 2026-09-24): pior caso 1,44 µF a 2,5 V (C5) e 1,26 µF a 3,3 V (C11), ≥ 1 µF |
| C7, C33 | 2 | 10nF | 0603C | Murata | `GCM188R71H103KA37J` | 81-GCM188R71H103KA7J | 3509127 | 0.1200 | 0.0680 | 0.0410 | N/D | biblioteca 2Solve |  |
| C15 | 1 | 1uF/50V | 0603C | TDK | `C1608X7R1H105K080AB` | N/D | N/D | N/D | N/D | N/D | N/D | biblioteca 2Solve |  |
| C29 | 1 | 100nF/100V | 0603C | Murata | `GRM188R72A104KA35D` | 81-GRM188R72A104KA35 | 1344731 | 0.1600 | 0.0870 | 0.0540 | Activo (substituto do GRM188R71E104KA01D obsoleto, relatório 2026-09-24) | biblioteca 2Solve |  |
| D1, D5, D24 | 3 | KG EELP41.22 | 0603LED | ams OSRAM | `KG EELP41.22-PHRH-35-A8J8-20-R18` | 720-P4122PHRH35A8J82 | 0 | 0.1600 | 0.1090 | 0.0760 | Activo (substituto do LG Q396 obsoleto, relatório 2026-09-24) | biblioteca 2Solve |  |
| D2 | 1 | SMA6J33A-Q | DO-214 | Bourns | `SMA6J33A-Q` | 652-SMA6J33A-Q | 11149 | 0.5800 | 0.2760 | 0.2270 | Activo (BOM EBM7 2026-09-14) | biblioteca 2Solve |  |
| D4 | 1 | MBR1H100SF | SOD123 | onsemi | `MBR1H100SFT3G` | 863-MBR1H100SFT3G | 106816 | 0.6600 | 0.2970 | 0.2610 | Activo (DigiKey 2026-09-24) | biblioteca 2Solve |  |
| D6, D7, D8, D9, D10, D11 | 6 | SMBJ33A | DO-214AA | Diodes Inc. | `SMBJ33A-13-F` | 621-SMBJ33A-13-F | 89868 | 0.5700 | 0.2710 | 0.1900 | N/D | NOVO | Novo na rev. 2.4 (DS19002 conferido) |
| D12, D13, D14, D15, D16, D17 | 6 | 824520361 | DO-214AA | Würth Elektronik | `824520361` | 710-824520361 | 82 | 0.3500 | 0.3200 | 0.2370 | Activo (BOM EBM7 2026-09-14) | biblioteca 2Solve | Stock baixo (314 D / 82 M) para 6 por placa |
| D18, D19, D20, D21, D22, D23 | 6 | BAV199 | SOT23-3 | onsemi | `BAV199LT1G` | 863-BAV199LT1G | 136104 | 0.1600 | 0.0720 | 0.0450 | Activo (BOM EBM7 2026-09-14) | biblioteca 2Solve |  |
| F2 | 1 | CC12H750MA-TR | 1206F | Eaton | `CC12H750MA-TR` | 504-CC12H750MA-TR | 5070 | 1.1600 | 1.0700 | 0.8160 | Activo (BOM EBM7 2026-09-14) | biblioteca 2Solve |  |
| F3, F4, F5, F6, F7, F8 | 6 | 50mA | 1206F | Schurter | `3413.0002.22` | 693-3413.0002.22 | 0 | 2.4100 | 1.8200 | 1.3700 | Activo (BOM EBM7 2026-09-14) | biblioteca 2Solve |  |
| FB1, FB2 | 2 | BLM18PG471SN1D | 0603FB | Murata | `BLM18PG471SN1D` | 81-BLM18PG471SN1D | 443559 | 0.1000 | 0.0620 | 0.0440 | Activo (BOM EBM7 2026-09-14) | biblioteca 2Solve |  |
| P1 | 1 | M20-7822046 | HDR1X20_FEMALE | Harwin | `M20-7822046` | 855-M20-7822046 | 1287 | 2.2400 | 2.2400 | 1.8600 | Activo (BOM EBM7 2026-09-14) | biblioteca 2Solve |  |
| P2 | 1 | M20-7821446 | HDR1X14_FEMALE | Harwin | `M20-7821446` | 855-M20-7821446 | 562 | 1.7500 | 1.4400 | 1.4300 | Activo (BOM EBM7 2026-09-14) | biblioteca 2Solve |  |
| R1, R34 | 2 | 14k7 | 0603R | Panasonic | `ERJ-3EKF1472V` | 667-ERJ-3EKF1472V | 66735 | 0.1000 | 0.0240 | 0.0200 | Activo (DigiKey 2026-09-24) | NOVO |  |
| R2, R10, R11, R12, R13, R14, R15 | 7 | 0R | 0603R | Yageo | `RC0603JR-070RL` | 603-RC0603JR-070RL | 5980483 | 0.1000 | 0.0080 | 0.0050 | Activo (BOM EBM7 2026-09-14) | biblioteca 2Solve |  |
| R4 | 1 | 2k2 | 0603R | Yageo | `RC0603FR-072K2L` | 603-RC0603FR-072K2L | 557666 | 0.1000 | 0.0140 | 0.0080 | Activo (BOM EBM7 2026-09-14) | biblioteca 2Solve |  |
| R5 | 1 | 32k4 | 0603R | Yageo | `RC0603FR-0732K4L` | 603-RC0603FR-0732K4L | 221 | 0.1100 | 0.0140 | 0.0090 | N/D | NOVO |  |
| R6, R9, R36 | 3 | 10k | 0603R | Yageo | `RC0603FR-0710KL` | 603-RC0603FR-0710KL | 2811281 | 0.1000 | 0.0140 | 0.0080 | N/D | biblioteca 2Solve |  |
| R7 | 1 | 100k | 0603R | Yageo | `RC0603FR-07100KL` | 603-RC0603FR-07100KL | 5080704 | 0.1000 | 0.0140 | 0.0080 | N/D | biblioteca 2Solve |  |
| R8 | 1 | 4k12 | 0603R | Yageo | `RC0603FR-074K12L` | 603-RC0603FR-074K12L | 16714 | 0.1000 | 0.0140 | 0.0080 | N/D | NOVO |  |
| R16, R17, R18, R19, R20, R21 | 6 | 110R 0,1% | 1206R | Panasonic | `ERA8AEB111V` | 667-ERA-8AEB111V | 7280 | 0.2700 | 0.1970 | 0.1640 | Activo (DigiKey 2026-09-24) | NOVO |  |
| R22, R23, R24, R25, R26, R27 | 6 | 3k3 | 0603R | Yageo | `RC0603FR-073K3L` | 603-RC0603FR-073K3L | 588651 | 0.1200 | 0.0140 | 0.0100 | Activo (BOM EBM7 2026-09-14) | biblioteca 2Solve |  |
| R28, R29, R30, R31, R32, R33 | 6 | 4k7 | 0603R | Yageo | `RC0603FR-074K7L` | 603-RC0603FR-074K7L | 2124140 | 0.1000 | 0.0140 | 0.0080 | N/D | NOVO |  |
| R35 | 1 | 93k1 | 0603R | Stackpole | `RMCF0603FT93K1` | 708-RMCF0603FT93K1 | 87588 | 0.1000 | 0.0120 | 0.0100 | N/D | biblioteca 2Solve |  |
| R37 | 1 | 13k3 | 0603R | Yageo | `RC0603FR-0713K3L` | 603-RC0603FR-0713K3L | 420840 | 0.1000 | 0.0140 | 0.0080 | N/D | NOVO |  |
| R38, R39 | 2 | 6k65 | 0603R | Yageo | `RC0603FR-076K65L` | 603-RC0603FR-076K65L | 879514 | 0.1000 | 0.0140 | 0.0080 | N/D | biblioteca 2Solve |  |
| R40 | 1 | 5k62 0,1% | 0603R | Panasonic | `ERA3AEB5621V` | 667-ERA-3AEB5621V | 8540 | 0.1000 | 0.0640 | 0.0610 | Activo (DigiKey 2026-09-24) | NOVO | Prazo de fábrica 49 semanas (DigiKey 2026-09-24) |
| TH1 | 1 | 10k NTC | 0603R | Vishay | `NTCS0603E3103JLT` | 594-NTCS0603E3103JLT | 11185 | 0.2300 | 0.2140 | 0.1750 | Activo (BOM EBM7 2026-09-14) | biblioteca 2Solve |  |
| U1, U14 | 2 | TPS7A4001DGN | HVSSOP-8-1EP | Texas Instruments | `TPS7A4001DGNR` | 595-TPS7A4001DGNR | 11204 | 3.5300 | 2.6500 | 2.1800 | Activo (BOM EBM7 2026-09-14) | biblioteca 2Solve |  |
| U2 | 1 | ADR4525WBRZ-R7 | SOIC8 | Analog Devices | `ADR4525WBRZ-R7` | 584-ADR4525WBRZ-R7 | 2147 | 14.8000 | 11.5900 | 9.9100 | Restricted Availability (Mouser 2026-09-25) | NOVO | Família «Restricted Availability» na Mouser: comprar cedo |
| U3 | 1 | TL431B | SOT23-3 | Texas Instruments | `TL431BQDBZR` | 595-TL431BQDBZR | 820 | 0.4400 | 0.3060 | 0.2360 | Activo (BOM EBM7 2026-09-14) | biblioteca 2Solve |  |
| U4, U5 | 2 | MCP1824T-3302E/OT | SOT-23-5 | Microchip | `MCP1824T-3302E/OT` | 579-MCP1824T-3302EOT | 14500 | 0.5600 | 0.5600 | 0.4750 | N/D | NOVO | Novo na rev. 2.5 (U4) |
| U6 | 1 | ISO7141CCDBQR | SSOP16-4.9x3.9mm | Texas Instruments | `ISO7141CCDBQR` | 595-ISO7141CCDBQR | 0 | 10.9400 | 8.5600 | 7.3000 | Activo (BOM EBM7 2026-09-14) | biblioteca 2Solve | **0 em stock na Mouser** (BOM EBM7 2026-09-14): risco de abastecimento |
| U7 | 1 | MCP3208T-BI/SL | SOIC16 | Microchip | `MCP3208T-BI/SL` | 579-MCP3208T-BI/SL | 3893 | 5.7600 | 5.7600 | 4.6400 | Activo (DigiKey 2026-09-24) | NOVO |  |
| U8, U9, U10, U11, U12, U13 | 6 | TPS26613DDFR | SOT-23-8 | Texas Instruments | `TPS26613DDFR` | 595-TPS26613DDFR | 3238 | 1.8000 | 1.2100 | 0.9720 | N/D | biblioteca 2Solve | Novo na rev. 2.4 (protector de laço) |

## 3 · Totais da placa (USD)

| Lote | Total | Por placa |
|---:|---:|---:|
| 1 | parcial 97.54 (faltam 2 linhas) | parcial 97.54 |
| 10 | parcial 699.56 (faltam 2 linhas) | parcial 69.96 |
| 100 | parcial 5634.80 (faltam 2 linhas) | parcial 56.35 |

Linhas sem preço (fora do parcial): C3, C6, C9, C12, C13, C14, C16, C17, C18, C19, C20, C21, C22, C23, C24, C25, C26, C27, C28, C34, C35; C15.

Preço no escalão que a quantidade do lote atinge (qtd por placa × placas); mínimos e múltiplos de embalagem não somados — Suprimentos confirma no carrinho.

### Cenário comprável hoje na Mouser

Principal quando há stock para o lote; senão a alternativa verificada com stock. As linhas em «sem stock» entram a preço de lista mas **não se compram hoje** na Mouser.

| Lote | Total | Por placa | Sem stock para o lote |
|---:|---:|---:|---|
| 1 | 102.13 | 102.13 | `C1608X7R1H104K080AA`, `C1608X7R1H105K080AB`, `ISO7141CCDBQR` |
| 10 | 732.08 | 73.21 | `C1608X7R1H104K080AA`, `C1608X7R1H105K080AB`, `ISO7141CCDBQR` |
| 100 | 5823.80 | 58.24 | `824520361`, `C1608X7R1H104K080AA`, `C1608X7R1H105K080AB`, `ISO7141CCDBQR` |

## 4 · Compra antecipada (críticos / long-lead) e acções

| Peça | Porquê | Acção sugerida |
|---|---|---|
| `ISO7141CCDBQR` (U6) | **0 em stock na Mouser em todas as variantes** (DBQR, DBQ, DBQRG4; 2026-09-25); prazo 112 dias (DBQR) / 63 dias (DBQ, tubo). Única peça que atravessa a barreira; a versão F (saída por defeito baixa) **não serve**: deixava o ADC seleccionado com o barramento desligado | Encomendar `ISO7141CCDBQ` à fábrica logo após o Portão 1, ou outro distribuidor autorizado |
| `3413.0002.22` (F3-F8, 6 por placa) | 0 em stock, **prazo 269 dias** | Protótipo com `3413.0002.11` (mesma peça, 100 un. em fita; 8838 em stock) |
| `ADR4525WBRZ-R7` (U2) | Família inteira **«Restricted Availability»** na Mouser (a BRZ original sem preço nem stock; trocada na tanda B) | Comprar com o protótipo (2147 em stock). Grau A **não** serve: 8 ppm/°C bowtie contra 4 |
| `ADR4525WBRZ-R7` (U2): grau W | A pág. 41 do ADR45xx Rev. G avisa que o modelo automóvel «may have specifications that differ from the commercial models». Conferido (2026-09-25): as tabelas 1-2 (págs. 3-5) só têm os graus A, B, C e D, **sem coluna W**; a guia de encomenda (pág. 40) dá o WBRZ-R7 como grau B, −40…+125 °C, SOIC-8. O datasheet **não publica** nenhuma especificação própria do W; se existir, só a ADI a dá | Decisão mantida (U2 = WBRZ-R7, fechada pelo projectista). Pedir à ADI, com a compra, a confirmação de que o WBRZ cumpre a tabela 2 do grau B (ou o relatório Automotive Reliability) |
| LED `KG EELP41.22` (3) | 0 em stock pelo código comprido | Pedir por `Q65113A7469` (mesmo tipo e bin; 15898 em stock) |
| `824520361` (D12-D17, 6 por placa) | 82 em stock: chega para 13 placas; prazo 154 dias | Reservar para o protótipo |
| `ERA3AEB5621V`, `ERA8AEB111V` | Prazo de fábrica 343 dias (Mouser); stock 8540 / 7280 | Comprar com o protótipo |
| `C1` | **Fechado na tanda C:** TDK `C3225X7R2A225K230AB` em 1210 (pior caso 1,18 µF a 30,4 V). Descartados: TDK X7S 1206 (0,89 µF) e Murata GRM31CR72A225KA73L / GRM32ER72A225KA35L (obsoleto / fim de vida) | Land pattern TDK (PA 2,0-2,4 mm) contra a pegada IPC do projecto (1,8 mm): conferir na F3 |
| `R3` | **Fechado na tanda B:** KOA `SG73P2ATTD1500F`, pulso conferido (~4x) | — |
| `C5`, `C11` | **Conferido:** curva TDK dá ≥ 1,26 µF no pior caso | — |

```yaml
evidencia:
  skill: 2shw-pcb:bom
  modo: preliminar
  artefatos: [bom_preliminar_EBM2_V5.md, bom_preliminar_EBM2_V5.csv]
  itens: 41
  alertas_ciclo_vida: 1
  itens_nd: 2
  total_1un: N/D
  total_100un: N/D
  fonte_dados: wrapper(2026-09-25T06:09 + reconsulta 2026-09-25T06:10 + reconsulta 2026-09-25T06:38 + reconsulta 2026-09-25T07:09)
```

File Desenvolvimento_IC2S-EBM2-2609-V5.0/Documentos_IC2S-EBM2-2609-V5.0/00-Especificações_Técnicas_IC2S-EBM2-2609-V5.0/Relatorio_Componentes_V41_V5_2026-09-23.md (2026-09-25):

# Componentes: V4.1 → V5 — EBM2 V5 (6AI 4-20 mA)

Data: 2026-09-23. Estado: esquemático da F2, etapa 2.2b.

Gerado por `ferramentas/gera_lista_componentes.py` a partir das duas netlists exportadas pelo
KiCad: a da V4.1 (`C:\hw\hw-ebm2-v4.1`, só leitura) e a da V5 actual. A correspondência
entre designadores é a da `intencao_EBM2_V5.md` rev. 2, §2; as justificações citam o
`planejamento_pcb_EBM2_V5.md` rev. 3 e a intenção. Os part numbers não foram escritos à mão.

## 1 · Peças que continuam, com o designador novo

| Função | V4.1 | V5 | Muda? | Porquê |
|---|---|---|---|---|
| Conector do barramento | `M20-7822046` P1 | `M20-7822046` P1 | não | Pinagem congelada (RC2). |
| Conector de campo | `M20-7821446` P2 | `M20-7821446` P2 | não | Pinagem congelada (RC2). |
| Isolador digital | `ISO7141CCDBQR` U4 | `ISO7141CCDBQR` U400 | não | Mesma peça. VCC1 passa a 3,3 V pelo U401 novo (fecha G2). Símbolo da EBM7 Legacy. |
| Conversor A/D | `MCP3208T-CI/SL` U5 | `MCP3208T-BI/SL` U500 | **sim** | Grau -CI → -BI: mesmo encapsulamento e pinagem, INL ±1 LSB em vez de ±2 (planejamento 2.1, 2.7b). |
| LDO 3,3 V do ADC | `SPX3819-3.3` U11 | `SPX3819M5-L-3-3/TR` U201 | não | Mesma peça; o MPN completo passa a constar. |
| Ferrite do VCC2 do isolador | `BLM18PG471SN1D` FB2 | `BLM18PG471SN1D` FB400 | não | — |
| Ferrite do VDD do conversor | `BLM18PG471SN1D` FB3 | `BLM18PG471SN1D` FB500 | não | — |
| Desacoplamento VCC1 do isolador | `GRM188R71E104KA01D` C7 | `GRM188R72A104KA35D` C401 | **sim** | — |
| Desacoplamento VCC2 do isolador | `GRM188R71E104KA01D` C8 | `GRM188R72A104KA35D` C403 | **sim** | — |
| Desacoplamento VDD do conversor | `GRM188R71E104KA01D` C10 | `GRM188R72A104KA35D` C502 | **sim** | Mantém-se; acresce o C501 de 1 µF que o datasheet pede (§ 6.4, pág. 23). |
| Termístor de placa | `NTCS0603E3103JLT` R5 | `NTCS0603E3103JLT` R700 | não | Mesma peça. Topo em +2V5_REF em vez de 3V3_REF (planejamento 2.7e); símbolo de NTC. |
| Divisor do termistor | `ERA-3AEB5621V` R8 | `ERA3AEB5621V` R701 | não | — |
| Pull-up do EN do SPX3819 | `CRCW0603100KFKEA` R34 | 100k *(sem MPN)* R203 | MPN por fixar | — |
| Canais 1-6: fusível | `F0603G0R10FNTR` F1, F2, F3, F4, F5, F6 | `3413.0002.22` F601, F602, F603, F604, F605, F606 | **sim** | 100 mA 0603 → 50 mA 1206, a peça da EBM7 Legacy. Rev. 2.1: abre só no curto franco à massa (~2,5 A); o curto do transmissor é do limitador U60x. |
| Canais 1-6: TVS no retorno | `824500301` D4, D7, D13, D22, D2, D12 | `824520361` D601, D602, D603, D604, D605, D606 | **sim** | 30 V SMA → 36 V SMB 600 W (rev. 2.2): envolvente 18–32 V; em curto o retorno sobe ao trilho (31,4 V). |
| Canais 1-6: TVS no trilho | `824500301` D3, D6, D10, D1, D11, D21 | `824520361` D611, D612, D613, D614, D615, D616 | **sim** | Mantidos os seis, num trilho único (+24V_ADC). 30 V → 36 V (rev. 2.2): a 32 V o trilho chega a 31,4 V. É o da EBM7. |
| Canais 1-6: série de protecção | `RC0603FR-07249RL` R6, R11, R18, R15, R1, R4 | `RC1206FR-07100RL` R601, R602, R603, R604, R605, R606 | **sim** | 249 Ω 0603 → 100 Ω 1206 (rev. 2.1/2.2): o curto passa a ser do limitador; 100 Ω para a tensão ao transmissor a 18 V. |
| Canais 1-6: burden | `CRCW0603160RFKEA` R9, R13, R21, R17, R3, R14 | `ERA8AEB111V` R611, R612, R613, R614, R615, R616 | **sim** | 160 Ω 1 % → 110 Ω 0,1 % 25 ppm/°C: com VREF 2,5 V, 20 mA x 110 Ω = 2,2 V (planejamento 2.5). Em 1206 desde a rev. 2.1. |
| Canais 1-6: antialias 3,3 kΩ | `RC0603FR-073K3L` R7, R12, R19, R16, R2, R10 | `RC0603FR-073K3L` R621, R622, R623, R624, R625, R626 | não | — |
| Canais 1-6: condensador do filtro | `GRM188R71E104KA01D` C9, C13, C18, C3, C1, C2 | `GRM188R72A104KA35D` C601, C602, C603, C604, C605, C606 | **sim** | — |
| Canais 1-6: clamp | `BAT54S` D5, D8, D14, D23, D9, D20 | `BAV199LT1G` D621, D622, D623, D624, D625, D626 | **sim** | BAT54S → BAV199 (EBM7): fuga de 5 nA a 25 °C contra µA do Schottky (planejamento 2.1). |
| LED do 5 V | `LG Q396-PS-35` D18 | `KG EELP41.22-PHRH-35-A8J8-20-R18` D204 | **sim** | Passa a indicar +5V_ADC (intenção § 11). |
| LED de trilho de laço | `LG Q396-PS-35` D19 | `KG EELP41.22-PHRH-35-A8J8-20-R18` D630 | **sim** | Passa a indicar +24V_ADC, o F202 inteiro. |
| LED de trilho de laço | `LG Q396-PS-35` D25 | `KG EELP41.22-PHRH-35-A8J8-20-R18` D203 | **sim** | Passa a indicar a entrada de +24V. |
| Resistência do LED do 5 V | `RC0603FR-072K2L` R24 | `RC0603FR-072K2L` R208 | não | — |
| Resistência do LED | `ERJ-3EKF1472V` R25 | `ERJ-3EKF1472V` R630 | não | — |
| Resistência do LED | `ERJ-3EKF1472V` R26 | `ERJ-3EKF1472V` R207 | não | — |

## 2 · Peças da V4.1 que saem

| V4.1 | Porquê |
|---|---|
| `PDM2-S24-S24-S` U1, U8<br>`CRE1S2405SC` U7 | Conversores isolados: a V5 alimenta o campo a partir do 24 V, sem isolamento de potência (folhas 02 e 03). |
| `PMEG6010CEH,115` D15, D16, D24 | PMEG6010CEH de 60 V: curto contra o grampo de 58,1 V do D200; substituídos pelo MBR1H100SF de 100 V. |
| `ZMM5234B` D17 | Sai (lista da intenção § 2). **Motivo individual não escrito.** |
| `BZT52H-B2V4,115` D26 | Zener de 2,45 V em serie na entrada: conduzia ~130 mA de uma peça de classe µA (notas da folha 02). |
| `3413.0008.22` F7, F9 | I²t de fusão 1,5e-3 A²s contra 5,65e-3 A²s de arranque dos 10 µF: avaria medida na V4.1 (notas da folha 02). Substituidos por CC12H (Eaton). |
| `0466.125NR` F8 | Sai com a entrada antiga (lista da intenção § 2). **Motivo individual não escrito.** |
| `ESL107M050AGMAA` C12, C28 | Electrolíticos de 50 V ficavam 8,1 V abaixo do grampo; substituídos pelo cerâmico C201 de 100 V. |
| `BLM18PG471SN1D` FB4 | Sai (lista da intenção § 2). **Motivo individual não escrito.** |
| `C1206C102KGRACTU` C4, C16, C19, C21, C31, C32<br>`C1206C104M5RAC` C5, C22<br>`UMK316BBJ106ML-T` C11, C15, C27, C29, C30<br>`GRM188R71E104KA01D` C20, C53, C54<br>`GRM188R61C106KAALD` C25<br>`GRM32ER61A107ME20K` C26<br>`GRM188R61C225KE15J` C51, C52 | Condensadores sem correspondente na V5: a intenção (§2) di-los ao serviço dos conversores que saem. **Não se conferiu um a um.** |

## 3 · Peças novas na V5

| V5 | Porquê |
|---|---|
| 2u2/100V *(sem MPN)* C200 | Entrada do regulador 2,2 µF/100 V 1206. **MPN por fixar (V6).** |
| `GRM32EC72A106ME05L` C201 | Bulk dos laços 10 µF/100 V, no lugar dos electrolíticos. |
| 10uF/25V *(sem MPN)* C202 | Saída do U200. |
| 100nF *(sem MPN)* C203 | Saída do U200. |
| 2u2 *(sem MPN)* C204 | Saída do SPX3819. |
| 100nF *(sem MPN)* C205 | Saída do SPX3819. |
| 100nF *(sem MPN)* C206 | Entrada do ADR4525. |
| 1uF *(sem MPN)* C207 | Saída do ADR4525. |
| 10nF *(sem MPN)* C208 | BP do SPX3819: baixo ruído. |
| 1uF *(sem MPN)* C400 | Entrada do U401. |
| 1uF *(sem MPN)* C402 | Saída do U401. |
| `GRM188R72A104KA35D` C500 | VREF no pino do ADC. |
| 1uF *(sem MPN)* C501 | 1 µF no VDD, pedido pelo datasheet. |
| `GRM188R72A104KA35D` C700 | 100 nF no canal do NTC (fig. 4-2 do DS21298E). |
| `SMA6J33A-Q` D200 | TVS de entrada 33 V: a V4.1 não tem nenhum (planejamento 2.2). |
| `MBR1H100SFT3G` D201 | Bloqueio 100 V da rama do regulador. |
| `MBR1H100SFT3G` D202 | Bloqueio 100 V da rama dos laços. |
| `BAT46W-7-F` D641 | Schottky antiparalelo ao U601: o AL5809 só aguenta −0,3 V em inversão. |
| `BAT46W-7-F` D642 | Idem, canal 2. |
| `BAT46W-7-F` D643 | Idem, canal 3. |
| `BAT46W-7-F` D644 | Idem, canal 4. |
| `BAT46W-7-F` D645 | Idem, canal 5. |
| `BAT46W-7-F` D646 | Idem, canal 6. |
| `CC12H250MA-TR` F201 | Fusível da rama do regulador, CC12H 250 mA (a série não tem 100 mA). |
| `CC12H750MA-TR` F202 | Fusível da rama dos laços, CC12H 750 mA: margem de arranque 41,7× (planejamento 2.6). |
| `RC0603JR-070RL` R200 | Net-tie 0 Ω, único caminho GND_24V ↔ GND_ADC. |
| 32k4 *(sem MPN)* R201 | Divisor do U200. |
| 10k *(sem MPN)* R202 | Divisor do U200. |
| 4k42 *(sem MPN)* R204 | Divisor do TL431. |
| 10k *(sem MPN)* R205 | Divisor do TL431. |
| 33R *(sem MPN)* R206 | Limitador de arranque 33 Ω (rev. 2.2, margem 12,3× a 32 V): sem ele o F201 não cumpre RA2. **MPN por fixar (V5).** |
| `TPS7A4001DGNR` U200 | Regulador 24 → 4,974 V (EBM7). |
| `ADR4525BRZ` U202 | Referência 2,5 V ±0,02 % (EBM7): VREF deixa de ser o VDD. |
| `TL431BQDBZR` U203 | TL431 a 3,6 V: sumidouro dos clamps; a V4.1 não tem nenhum. |
| `MCP1824ST-3302E/DB` U401 | LDO 3,3 V para o VCC1 do isolador: fecha G2. |
| `AL5809-25P1-7` U601 | Limitador de corrente 23,75-26,25 mA no retorno (rev. 2.1): fecha a V8, herdada da V4.1. |
| `AL5809-25P1-7` U602 | Idem, canal 2. |
| `AL5809-25P1-7` U603 | Idem, canal 3. |
| `AL5809-25P1-7` U604 | Idem, canal 4. |
| `AL5809-25P1-7` U605 | Idem, canal 5. |
| `AL5809-25P1-7` U606 | Idem, canal 6. |
| `T201`, `T202`, `T203`, `T204`, `T205`, `T206`, `T207`, `T400`, `T500` | Pontos de prova: a V4.1 tem zero (RD1). |
| `FID101`, `FID102`, `FID103` | Fiduciais: a V4.1 tem zero (RD2). |

## 4 · Contagem

| | Peças |
|---|---|
| V4.1 | 101 |
| V5 | 120 |
| Continuam (§1) | 67 na V4.1 → 67 na V5, em 27 linhas: 12 iguais, 14 mudam de peça, 1 com MPN por fixar na V5 |
| Peças da V5 ainda sem MPN no esquemático | 17: C200, C202, C203, C204, C205, C206, C207, C208, C400, C402, C501, R201, R202, R203, R204, R205, R206 |
| Saem (§2) | 34 |
| Novas (§3) | 53 |

Em aberto: os MPN em falta (fecham na BOM preliminar da F2; `R206` é a `V5` e `C200` a `V6`
da intenção) e três saídas sem motivo individual escrito (`D17`, `F8`, `FB4`).

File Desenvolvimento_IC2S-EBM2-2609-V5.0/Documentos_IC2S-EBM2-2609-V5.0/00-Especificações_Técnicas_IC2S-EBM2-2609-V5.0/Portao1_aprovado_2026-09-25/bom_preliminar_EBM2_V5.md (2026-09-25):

---
projeto: IC2S Extension Board EBM2 V5 (6AI 4-20 mA)
etapa: BOM preliminar (2shw-pcb:bom, modo preliminar)
netlist: EBM2_V5_P1R_final.net
fonte_dados: Mouser Search API, consulta de 2026-09-25T06:09 + reconsulta 2026-09-25T06:10 + reconsulta 2026-09-25T06:38 + reconsulta 2026-09-25T07:09
moeda: USD
---

# BOM preliminar — EBM2 V5

**Só se liberta a Suprimentos com o Portão 1 assinado. Hardware não compra.**

Fonte dos dados comerciais: Mouser Search API, consulta de 2026-09-25T06:09 + reconsulta 2026-09-25T06:10 + reconsulta 2026-09-25T06:38 + reconsulta 2026-09-25T07:09. Ciclo de vida só com fonte e data; sem fonte é `N/D`, nunca «activo» por omissão.

## 1 · Alertas

- **Ciclo de vida fora de «activo»:** ADR4525WBRZ-R7 — Restricted Availability (Mouser 2026-09-25)
- **Stock Mouser abaixo de 10 placas:**
  - KG EELP41.22-PHRH-35-A8J8-20-R18 (D1, D5, D24): 0 em stock para 3 por placa; alternativa verificada Q65113A7469: 15898 em stock
  - 3413.0002.22 (F3, F4, F5, F6, F7, F8): 0 em stock para 6 por placa; alternativa verificada 3413.0002.11: 8838 em stock
  - ISO7141CCDBQR (U6): 0 em stock para 1 por placa; alternativa verificada ISO7141CCDBQ: 0 em stock

### Alternativas verificadas (mesma peça eléctrica, conferida no datasheet)

| Principal | Alternativa | Stock Mouser | Evidência |
|---|---|---:|---|
| `ADR4525WBRZ-R7` | `ADR4525BRZ` | N/D | O MPN original: mesmo grau B em tubo de 98; na Mouser sem preço nem stock e «Restricted Availability» (2026-09-25). A WBRZ-R7 entrou na tanda B por isso (ADR45xx Rev. G, tabela 14 pág. 40, nota 2 pág. 41) |
| `3413.0002.22` | `3413.0002.11` | 8838 | Mesma linha eléctrica (50 mA, 63 VDC, 9200 mΩ, 0,0002 A²s); só muda a embalagem: 100 un. em fita (Schurter USFF, págs. 3-4) |
| `KG EELP41.22-PHRH-35-A8J8-20-R18` | `Q65113A7469` | 15898 | Código de encomenda OSRAM do mesmo tipo e bin, KG EELP41.22-PHRH-35-A8J8 (datasheet v1.4 pág. 3) |
| `ISO7141CCDBQR` | `ISO7141CCDBQ` | 0 | Mesma peça, tubo de 75 em vez de bobina de 2500 (TI, package option addendum pág. 27) |

## 2 · Linhas (43, 126 componentes montados)

| Refs | Qtd | Valor | Pegada | Fabricante | MPN | Mouser | Stock | Unit. lote 1 | Unit. lote 10 | Unit. lote 100 | Ciclo de vida | Origem | Notas |
|---|---:|---|---|---|---|---|---|---:|---:|---:|---|---|---|
| C1 | 1 | 2u2/100V | C_1210_3225Metric | N/D | `C3225X7R2A225K230AB` | 810-C3225X7R2A225K | 30005 | 0.7800 | 0.4880 | 0.3380 | Production (ficha TDK 2026-09-25) | NOVO | C1: curva TDK ~1,54 uF a 30,4 V; pior caso 1,18 uF > 1 uF (TPS7A4001); RA2 11,3x. X7S 1206 descartado (0,89 uF) |
| C2, C30 | 2 | 10uF/100V | C_1210_3225Metric | Murata | `GRM32EC72A106ME05L` | 81-GRM32EC72A106ME5L | 35196 | 1.1800 | 0.7580 | 0.5420 | Activo (DigiKey 2026-09-24) | biblioteca 2Solve |  |
| C3, C6, C9, C12, C13, C14, C16, C17, C18, C19, C20, C21, C22, C23, C24, C25, C26, C27, C28, C29, C34, C35 | 22 | 100nF / 100nF/100V | 0603C | Murata | `GRM188R72A104KA35D` | 81-GRM188R72A104KA35 | 1344731 | 0.0870 | 0.0540 | 0.0400 | Activo (substituto do GRM188R71E104KA01D obsoleto, relatório 2026-09-24) | biblioteca 2Solve |  |
| C4, C8, C31, C32 | 4 | 10uF/50V | C_1206_3216Metric | TDK | `C3216X5R1H106K160AB` | 810-C3216X5R1H106K | 124920 | 1.8500 | 1.2500 | 0.9130 | Production (ficha TDK 2026-09-24) | biblioteca 2Solve | Curva TDK conferida: C4 7,0 µF a 5 V, C8 7,2 µF a 3,3 V, C31+C32 8,9 µF a 12,6 V (pior caso) |
| C5, C11 | 2 | 2u2 | 0603C | TDK | `C1608X5R1E225K080AB` | 810-C1608X5R1E225K | 15300 | 0.2700 | 0.1610 | 0.0980 | Production (ficha TDK 2026-09-24) | biblioteca 2Solve | Curva TDK conferida (ficha 2026-09-24): pior caso 1,44 µF a 2,5 V (C5) e 1,26 µF a 3,3 V (C11), ≥ 1 µF |
| C7, C33 | 2 | 10nF | 0603C | Murata | `GCM188R71H103KA37J` | 81-GCM188R71H103KA7J | 3509127 | 0.1200 | 0.0680 | 0.0410 | N/D | biblioteca 2Solve |  |
| C10, C15 | 2 | 1uF | 0603C | KEMET | `C0603C105K4RACTU` | 80-C0603C105K4R | 185891 | 0.1400 | 0.0780 | 0.0450 | N/D | biblioteca 2Solve |  |
| D1, D5, D24 | 3 | KG EELP41.22 | 0603LED | ams OSRAM | `KG EELP41.22-PHRH-35-A8J8-20-R18` | 720-P4122PHRH35A8J82 | 0 | 0.1600 | 0.1090 | 0.0760 | Activo (substituto do LG Q396 obsoleto, relatório 2026-09-24) | biblioteca 2Solve |  |
| D2 | 1 | SMA6J33A-Q | DO-214 | Bourns | `SMA6J33A-Q` | 652-SMA6J33A-Q | 11149 | 0.5800 | 0.2760 | 0.2270 | Activo (BOM EBM7 2026-09-14) | biblioteca 2Solve |  |
| D3, D4 | 2 | MBR1H100SF | SOD123 | onsemi | `MBR1H100SFT3G` | 863-MBR1H100SFT3G | 106816 | 0.6600 | 0.2970 | 0.2610 | Activo (DigiKey 2026-09-24) | biblioteca 2Solve |  |
| D6, D7, D8, D9, D10, D11 | 6 | SMBJ33A | DO-214AA | Diodes Inc. | `SMBJ33A-13-F` | 621-SMBJ33A-13-F | 89868 | 0.5700 | 0.2710 | 0.1900 | N/D | NOVO | Novo na rev. 2.4 (DS19002 conferido) |
| D12, D13, D14, D15, D16, D17 | 6 | 824520361 | DO-214AA | Würth Elektronik | `824520361` | 710-824520361 | 82 | 0.3500 | 0.3200 | 0.2370 | Activo (BOM EBM7 2026-09-14) | biblioteca 2Solve | Stock baixo (314 D / 82 M) para 6 por placa |
| D18, D19, D20, D21, D22, D23 | 6 | BAV199 | SOT23-3 | onsemi | `BAV199LT1G` | 863-BAV199LT1G | 136104 | 0.1600 | 0.0720 | 0.0450 | Activo (BOM EBM7 2026-09-14) | biblioteca 2Solve |  |
| F1 | 1 | CC12H250MA-TR | 1206F | Eaton | `CC12H250MA-TR` | 504-CC12H250MA-TR | 151 | 1.0300 | 0.9440 | 0.7230 | Activo (DigiKey 2026-09-24) | NOVO |  |
| F2 | 1 | CC12H750MA-TR | 1206F | Eaton | `CC12H750MA-TR` | 504-CC12H750MA-TR | 5070 | 1.1600 | 1.0700 | 0.8160 | Activo (BOM EBM7 2026-09-14) | biblioteca 2Solve |  |
| F3, F4, F5, F6, F7, F8 | 6 | 50mA | 1206F | Schurter | `3413.0002.22` | 693-3413.0002.22 | 0 | 2.4100 | 1.8200 | 1.3700 | Activo (BOM EBM7 2026-09-14) | biblioteca 2Solve |  |
| FB1, FB2 | 2 | BLM18PG471SN1D | 0603FB | Murata | `BLM18PG471SN1D` | 81-BLM18PG471SN1D | 443559 | 0.1000 | 0.0620 | 0.0440 | Activo (BOM EBM7 2026-09-14) | biblioteca 2Solve |  |
| P1 | 1 | M20-7822046 | HDR1X20_FEMALE | Harwin | `M20-7822046` | 855-M20-7822046 | 1287 | 2.2400 | 2.2400 | 1.8600 | Activo (BOM EBM7 2026-09-14) | biblioteca 2Solve |  |
| P2 | 1 | M20-7821446 | HDR1X14_FEMALE | Harwin | `M20-7821446` | 855-M20-7821446 | 562 | 1.7500 | 1.4400 | 1.4300 | Activo (BOM EBM7 2026-09-14) | biblioteca 2Solve |  |
| R1, R34 | 2 | 14k7 | 0603R | Panasonic | `ERJ-3EKF1472V` | 667-ERJ-3EKF1472V | 66735 | 0.1000 | 0.0240 | 0.0200 | Activo (DigiKey 2026-09-24) | NOVO |  |
| R2, R10, R11, R12, R13, R14, R15 | 7 | 0R | 0603R | Yageo | `RC0603JR-070RL` | 603-RC0603JR-070RL | 5980483 | 0.1000 | 0.0080 | 0.0050 | Activo (BOM EBM7 2026-09-14) | biblioteca 2Solve |  |
| R3 | 1 | 150R | 0805R | N/D | `SG73P2ATTD1500F` | 660-SG73P2ATTD1500F | 14366 | 0.1700 | 0.0540 | 0.0400 | N/D | NOVO | R3: pulso de arranque 6,6 W / 0,6 ms contra ~26 W da curva 2A (KOA SG73P pág. 2): ~4x |
| R4 | 1 | 2k2 | 0603R | Yageo | `RC0603FR-072K2L` | 603-RC0603FR-072K2L | 557666 | 0.1000 | 0.0140 | 0.0080 | Activo (BOM EBM7 2026-09-14) | biblioteca 2Solve |  |
| R5 | 1 | 32k4 | 0603R | Yageo | `RC0603FR-0732K4L` | 603-RC0603FR-0732K4L | 221 | 0.1100 | 0.0140 | 0.0090 | N/D | NOVO |  |
| R6, R9, R36 | 3 | 10k | 0603R | Yageo | `RC0603FR-0710KL` | 603-RC0603FR-0710KL | 2811281 | 0.1000 | 0.0140 | 0.0080 | N/D | biblioteca 2Solve |  |
| R7 | 1 | 100k | 0603R | Yageo | `RC0603FR-07100KL` | 603-RC0603FR-07100KL | 5080704 | 0.1000 | 0.0140 | 0.0080 | N/D | biblioteca 2Solve |  |
| R8 | 1 | 4k12 | 0603R | Yageo | `RC0603FR-074K12L` | 603-RC0603FR-074K12L | 16714 | 0.1000 | 0.0140 | 0.0080 | N/D | NOVO |  |
| R16, R17, R18, R19, R20, R21 | 6 | 110R 0,1% | 1206R | Panasonic | `ERA8AEB111V` | 667-ERA-8AEB111V | 7280 | 0.2700 | 0.1970 | 0.1640 | Activo (DigiKey 2026-09-24) | NOVO |  |
| R22, R23, R24, R25, R26, R27 | 6 | 3k3 | 0603R | Yageo | `RC0603FR-073K3L` | 603-RC0603FR-073K3L | 588651 | 0.1200 | 0.0140 | 0.0100 | Activo (BOM EBM7 2026-09-14) | biblioteca 2Solve |  |
| R28, R29, R30, R31, R32, R33 | 6 | 4k7 | 0603R | Yageo | `RC0603FR-074K7L` | 603-RC0603FR-074K7L | 2124140 | 0.1000 | 0.0140 | 0.0080 | N/D | NOVO |  |
| R35 | 1 | 93k1 | 0603R | Stackpole | `RMCF0603FT93K1` | 708-RMCF0603FT93K1 | 87588 | 0.1000 | 0.0120 | 0.0100 | N/D | biblioteca 2Solve |  |
| R37 | 1 | 13k3 | 0603R | Yageo | `RC0603FR-0713K3L` | 603-RC0603FR-0713K3L | 420840 | 0.1000 | 0.0140 | 0.0080 | N/D | NOVO |  |
| R38, R39 | 2 | 6k65 | 0603R | Yageo | `RC0603FR-076K65L` | 603-RC0603FR-076K65L | 879514 | 0.1000 | 0.0140 | 0.0080 | N/D | biblioteca 2Solve |  |
| R40 | 1 | 5k62 0,1% | 0603R | Panasonic | `ERA3AEB5621V` | 667-ERA-3AEB5621V | 8540 | 0.1000 | 0.0640 | 0.0610 | Activo (DigiKey 2026-09-24) | NOVO | Prazo de fábrica 49 semanas (DigiKey 2026-09-24) |
| TH1 | 1 | 10k NTC | 0603R | Vishay | `NTCS0603E3103JLT` | 594-NTCS0603E3103JLT | 11185 | 0.2300 | 0.2140 | 0.1750 | Activo (BOM EBM7 2026-09-14) | biblioteca 2Solve |  |
| U1, U14 | 2 | TPS7A4001DGN | HVSSOP-8-1EP | Texas Instruments | `TPS7A4001DGNR` | 595-TPS7A4001DGNR | 11204 | 3.5300 | 2.6500 | 2.1800 | Activo (BOM EBM7 2026-09-14) | biblioteca 2Solve |  |
| U2 | 1 | ADR4525WBRZ-R7 | SOIC8 | Analog Devices | `ADR4525WBRZ-R7` | 584-ADR4525WBRZ-R7 | 2147 | 14.8000 | 11.5900 | 9.9100 | Restricted Availability (Mouser 2026-09-25) | NOVO | Família «Restricted Availability» na Mouser: comprar cedo |
| U3 | 1 | TL431B | SOT23-3 | Texas Instruments | `TL431BQDBZR` | 595-TL431BQDBZR | 820 | 0.4400 | 0.3060 | 0.2360 | Activo (BOM EBM7 2026-09-14) | biblioteca 2Solve |  |
| U4 | 1 | MCP1824T-3302E/OT | SOT-23-5 | Microchip | `MCP1824T-3302E/OT` | 579-MCP1824T-3302EOT | 14500 | 0.5600 | 0.5600 | 0.4750 | N/D | NOVO | Novo na rev. 2.5 (U4) |
| U5 | 1 | MCP1824ST-3302E/DB | SOT-223-3 | Microchip | `MCP1824ST-3302E/DB` | 579-MCP1824ST3302EDB | 11898 | 0.6400 | 0.6400 | 0.5400 | Activo (BOM EBM7 2026-09-14) | biblioteca 2Solve |  |
| U6 | 1 | ISO7141CCDBQR | SSOP16-4.9x3.9mm | Texas Instruments | `ISO7141CCDBQR` | 595-ISO7141CCDBQR | 0 | 10.9400 | 8.5600 | 7.3000 | Activo (BOM EBM7 2026-09-14) | biblioteca 2Solve | **0 em stock na Mouser** (BOM EBM7 2026-09-14): risco de abastecimento |
| U7 | 1 | MCP3208T-BI/SL | SOIC16 | Microchip | `MCP3208T-BI/SL` | 579-MCP3208T-BI/SL | 3893 | 5.7600 | 5.7600 | 4.6400 | Activo (DigiKey 2026-09-24) | NOVO |  |
| U8, U9, U10, U11, U12, U13 | 6 | TPS26613DDFR | SOT-23-8 | Texas Instruments | `TPS26613DDFR` | 595-TPS26613DDFR | 3238 | 1.8000 | 1.2100 | 0.9720 | N/D | biblioteca 2Solve | Novo na rev. 2.4 (protector de laço) |

## 3 · Totais da placa (USD)

| Lote | Total | Por placa |
|---:|---:|---:|
| 1 | 99.66 | 99.66 |
| 10 | 726.33 | 72.63 |
| 100 | 5809.50 | 58.10 |

Preço no escalão que a quantidade do lote atinge (qtd por placa × placas); mínimos e múltiplos de embalagem não somados — Suprimentos confirma no carrinho.

### Cenário comprável hoje na Mouser

Principal quando há stock para o lote; senão a alternativa verificada com stock. As linhas em «sem stock» entram a preço de lista mas **não se compram hoje** na Mouser.

| Lote | Total | Por placa | Sem stock para o lote |
|---:|---:|---:|---|
| 1 | 104.25 | 104.25 | `ISO7141CCDBQR` |
| 10 | 758.85 | 75.88 | `ISO7141CCDBQR` |
| 100 | 5998.50 | 59.99 | `824520361`, `ISO7141CCDBQR` |

## 4 · Compra antecipada (críticos / long-lead) e acções

| Peça | Porquê | Acção sugerida |
|---|---|---|
| `ISO7141CCDBQR` (U6) | **0 em stock na Mouser em todas as variantes** (DBQR, DBQ, DBQRG4; 2026-09-25); prazo 112 dias (DBQR) / 63 dias (DBQ, tubo). Única peça que atravessa a barreira; a versão F (saída por defeito baixa) **não serve**: deixava o ADC seleccionado com o barramento desligado | Encomendar `ISO7141CCDBQ` à fábrica logo após o Portão 1, ou outro distribuidor autorizado |
| `3413.0002.22` (F3-F8, 6 por placa) | 0 em stock, **prazo 269 dias** | Protótipo com `3413.0002.11` (mesma peça, 100 un. em fita; 8838 em stock) |
| `ADR4525WBRZ-R7` (U2) | Família inteira **«Restricted Availability»** na Mouser (a BRZ original sem preço nem stock; trocada na tanda B) | Comprar com o protótipo (2147 em stock). Grau A **não** serve: 8 ppm/°C bowtie contra 4 |
| `ADR4525WBRZ-R7` (U2): grau W | A pág. 41 do ADR45xx Rev. G avisa que o modelo automóvel «may have specifications that differ from the commercial models». Conferido (2026-09-25): as tabelas 1-2 (págs. 3-5) só têm os graus A, B, C e D, **sem coluna W**; a guia de encomenda (pág. 40) dá o WBRZ-R7 como grau B, −40…+125 °C, SOIC-8. O datasheet **não publica** nenhuma especificação própria do W; se existir, só a ADI a dá | Decisão mantida (U2 = WBRZ-R7, fechada pelo projectista). Pedir à ADI, com a compra, a confirmação de que o WBRZ cumpre a tabela 2 do grau B (ou o relatório Automotive Reliability) |
| LED `KG EELP41.22` (3) | 0 em stock pelo código comprido | Pedir por `Q65113A7469` (mesmo tipo e bin; 15898 em stock) |
| `824520361` (D12-D17, 6 por placa) | 82 em stock: chega para 13 placas; prazo 154 dias | Reservar para o protótipo |
| `ERA3AEB5621V`, `ERA8AEB111V` | Prazo de fábrica 343 dias (Mouser); stock 8540 / 7280 | Comprar com o protótipo |
| `C1` | **Fechado na tanda C:** TDK `C3225X7R2A225K230AB` em 1210 (pior caso 1,18 µF a 30,4 V). Descartados: TDK X7S 1206 (0,89 µF) e Murata GRM31CR72A225KA73L / GRM32ER72A225KA35L (obsoleto / fim de vida) | Land pattern TDK (PA 2,0-2,4 mm) contra a pegada IPC do projecto (1,8 mm): conferir na F3 |
| `R3` | **Fechado na tanda B:** KOA `SG73P2ATTD1500F`, pulso conferido (~4x) | — |
| `C5`, `C11` | **Conferido:** curva TDK dá ≥ 1,26 µF no pior caso | — |

```yaml
evidencia:
  skill: 2shw-pcb:bom
  modo: preliminar
  artefatos: [bom_preliminar_EBM2_V5.md, bom_preliminar_EBM2_V5.csv]
  itens: 43
  alertas_ciclo_vida: 1
  itens_nd: 0
  total_1un: 99.66
  total_100un: 5809.50
  fonte_dados: wrapper(2026-09-25T06:09 + reconsulta 2026-09-25T06:10 + reconsulta 2026-09-25T06:38 + reconsulta 2026-09-25T07:09)
```

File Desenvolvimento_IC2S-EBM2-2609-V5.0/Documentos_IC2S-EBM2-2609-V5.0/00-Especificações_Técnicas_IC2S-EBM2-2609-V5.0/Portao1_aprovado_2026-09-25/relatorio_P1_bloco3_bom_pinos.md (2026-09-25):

---
verificador: agente independente (Claude Sonnet 5), Portão 1 — Bloco 3 (BOM preliminar + mapa de pinos)
autor_original: outro modelo (Claude Opus 5.5)
data: 2026-09-25
âmbito: só o Bloco 3 — não cobre esquemático, layout, ERC/DRC nem os outros blocos do Portão 1
método: recálculo independente (parsing próprio da netlist kicadsexpr, não confio nas ferramentas do autor), render pixel-a-pixel das curvas dos datasheets (PyMuPDF a 6-8x, calibração dos eixos por gridline/rótulo, leitura do traço), comparação directa com os JSON crus da Mouser
---

# Relatório de verificação — Portão 1, Bloco 3 (BOM preliminar e mapa de pinos) — EBM2 V5

## Veredicto do bloco

**Aprovado, sem bloqueadores.** Não encontrei nenhuma divergência entre BOM, netlist e mapa de pinos, nem nenhum valor comercial fabricado. As contas de pior caso dos condensadores e a curva de impulso do R206 foram re-obtidas de forma independente (leitura de pixel sobre o datasheet renderizado, não confiando na leitura do autor) e batem com o que a BOM/intenção afirmam, dentro da precisão de leitura de uma curva. Há **2 achados de severidade baixa/média**, nenhum impede a assinatura, mas o achado #1 merece uma nota no processo antes de travar o `ADR4525WBRZ-R7` como peça de produção.

## 1 · BOM vs netlist (referências, quantidade, valor, pegada, MPN)

Parsing próprio do `EBM2_V5.net` (formato kicadsexpr, `Value`/`Footprint`/`MPN` em blocos multi-linha — parsing por profundidade de parênteses, não por regex de uma linha).

- Netlist: 139 `(comp ...)` no total; 13 têm a propriedade `exclude_from_bom` (3 `FID10x` fiduciais + 10 `Txxx` pontos de teste) → **126 componentes elegíveis para BOM**.
- BOM preliminar (csv+md): 43 linhas, refs expandidas = **126, todas únicas** (zero duplicados).
- Conjunto de referências: **netlist == BOM, exactamente** — 0 em falta, 0 a mais.
- Por cada uma das 126 referências: **Pegada, MPN e Valor da BOM == netlist**, sem excepção (comparação campo a campo, não amostragem).
- Quantidade por linha (`Qtd` vs contagem de refs expandidas): 0 divergências nas 43 linhas.
- As 13 posições `exclude_from_bom` (fiduciais + `T2xx`/`T4xx`/`T5xx`/`T640`) ficam fora da BOM correctamente — nenhuma aparece nela.

**Conclusão do item 1: match perfeito, 126/126.**

## 2 · Peças mudadas nas tandas — MPN contra datasheet e contas de pior caso

Refeitas de forma independente, sem usar os números do autor como ponto de partida — render do datasheet a 6-8x, calibração dos eixos pelos próprios gridlines/rótulos (não pela legenda), leitura do traço vermelho por varrimento de pixels.

### C200 — TDK `C3225X7R2A225K230AB` (2,2 µF/100 V, X7R ±15 %, 1210)
- Datasheet pág. 1: 2,2 µF ±10 %, 100 VDC, X7R(±15 %) — confirmado texto.
- Curva DC Bias (pág. 2, figura "DC Bias Characteristic"): leitura própria por pixel a 30,4 V → **1,543 µF** (a BOM diz "~1,54 µF"; bate).
- Pior caso = 1,543 × 0,90 (tolerância −10 %) × 0,85 (X7R −15 %) = **1,178 µF**. A BOM diz 1,18 µF — bate.
- Requisito: C200 está no net `+24V_REG`, que confirmei no netlist ser o **pino 8 (IN, power_in) do U200/U640 (TPS7A4001)** — é o capacitor de **entrada**. TI TPS7A4001 datasheet (SBVS162B, secção 8.2.2.2, pág. 11): *"...achieves stability with a minimum output capacitance of 4.7 µF and **input capacitance of 1 µF**"*. 1,178 µF > 1 µF do requisito de **entrada** — correcto, a BOM não confundiu entrada com saída.
- Alternativa X7S 1206 (`C3216X7S2A225K160AB`) descartada: reli a curva a 30,4 V → 1,277 µF × 0,90 × 0,78 (X7S −22 %) = **0,896 µF** (BOM diz 0,89 µF — bate) — correctamente abaixo de 1 µF, correctamente descartada.

### C202/C204/C642/C644 — TDK `C3216X5R1H106K160AB` (10 µF/50 V, X5R ±15 %, 1206)
- Datasheet pág. 1: 10 µF ±10 %, 50 VDC, X5R(±15 %) — confirmado.
- Releitura própria da curva DC Bias (pág. 2): a 5 V → 9,20 µF; a 3,3 V → 9,74 µF; a 12,6 V → 5,78 µF.
- Pior caso (×0,90×0,85): **C202 a 5 V → 7,03 µF** (BOM: 7,0 — bate); **C204 a 3,3 V → 7,45 µF** (BOM: 7,2 — diferença de leitura ~3 %, na direcção conservadora: o valor real é *melhor* que o citado, não pior); **C642 ou C644 sozinho a 12,6 V → 4,42 µF**, os dois em paralelo → **8,84 µF** (BOM: 8,9 — bate).
- Requisito: confirmei no netlist que C202 está no net `+5V_ADC` = **pino 1 (OUT) do U200**, e C642+C644 no net `+12V_TPS` = **pino 1 (OUT) do U640** — são capacitores de **saída** do mesmo TPS7A4001, cujo mínimo de estabilidade é **4,7 µF** (não 1 µF). C202 (7,03) e a dupla C642+C644 (8,84) folgam esse limite. **Um só** dos dois capacitores de U640 (4,42 µF) ficaria *abaixo* dos 4,7 µF — mas isto já está documentado pelo próprio autor em `intencao_EBM2_V5.md` linha 656 ("uma peça dá 4,4 µF < 4,7 µF... Duas: 8,9 µF"), não é um achado novo, é redundância por desenho.
- C204 está no net `3V3_REF`, alimentado pelo **U201 (MCP1824)**, não pelo TPS7A4001 — a BOM não afirma um limiar numérico para C204 (só reporta a leitura da curva), o que está correcto.

### C207/C402 — TDK `C1608X5R1E225K080AB` (2,2 µF/25 V, X5R ±15 %, 0603)
- Releitura própria: a 2,5 V → 1,833 µF; a 3,3 V → 1,617 µF.
- Pior caso: **C207 a 2,5 V → 1,40 µF** (BOM: 1,44 — próximo); **C402 a 3,3 V → 1,24 µF** (BOM: 1,26 — próximo). Ambos ≥ 1 µF (entrada do ADR4525 / MCP1824).

### R206 — KOA `SG73P2ATTD1500F` (150 Ω, 0805, série anti-surto "2A")
- Confirmei no datasheet (pág. 2, tabela "applications and ratings") que a designação de tamanho da peça é **"2A"** (0,75 W) — usei o gráfico certo ("SG73P 1E-2A", curva rotulada "2A", não a "2B-2E" que é para outro tamanho).
- Releitura própria da curva "One-Pulse Limiting Electric Power" por calibração de eixos log-log (gridlines/rótulos "1000/100/10/1/0,1 W" e "0,001…1000 ms") e varrimento de pixel a 0,6 ms: **26,3 W**. A BOM diz "~26 W" — bate.
- Contra o pulso citado de 6,6 W/0,6 ms: margem = 26,3/6,6 = **3,98×** ≈ "~4×" da BOM — bate.
- **Limitação:** não re-derivei o próprio valor do pulso (6,6 W / 0,6 ms); essa conta pertence à análise do transiente de arranque (F2/esquemático), documentada em `intencao_EBM2_V5.md` linha 648, fora do âmbito deste Bloco 3.

### U202 — Analog Devices `ADR4525WBRZ-R7` (referência 2,5 V, SOIC-8)
- Tabela 14 (Ordering Guide, pág. 40): `ADR4525WBRZ-R7` existe, -40 a +125 °C, SOIC 8-lead, pacote R-8, reel 1000 — confirmado texto e tabela.
- Nomenclatura confirmada: "W" = automóvel, "B" = grau (nota 2, pág. 41); logo `ADR4525WBRZ-R7` é grau **B**, o mesmo grau da `ADR4525BRZ` original (descontinuada/Restricted Availability) — a afirmação "mesmo grau B" está correcta.
- Tabela 2 (Electrical Characteristics, pág. 4): Grau B, TCV −40…+125 °C = 2 ppm/°C (box) / **4 ppm/°C (bowtie)**; Grau A = 4/**8 ppm/°C (bowtie)** — confirma "grau A não serve: 8 ppm/°C bowtie contra 4".
- **Achado #1 (severidade média):** a pág. 41 traz a nota "AUTOMOTIVE PRODUCTS": *"...this automotive model **may have specifications that differ** from the commercial models; therefore, designers should **review the Specifications section... carefully**"*. A BOM e a intenção citam a nota 2 (que só define "W = automóvel") mas não respondem a este aviso explícito. Verifiquei eu mesmo as págs. 3-4 (tabelas 1-2) e **não há uma coluna/tabela separada para o grau W-automóvel** — os números publicados são os mesmos da tabela de graus A/B/C/D comercial, o que sustenta a substituição. Mas a documentação do Portão 1 devia registar esta verificação explicitamente (ou o contacto recomendado à Analog Devices), em vez de citar só a definição de "W" sem tratar o aviso.

## 3 · Dados comerciais (preço/stock com fonte e data; alternativas verificadas)

- Todas as 43 linhas da BOM têm `Ciclo_vida` ou "N/D" ou uma fonte+data entre parênteses — **nenhuma célula com valor "estimado"** (busca de texto no CSV: 0 ocorrências).
- Verifiquei os JSON crus da Mouser (`bom_dados_mouser_2026-09-25.json`, consulta 2026-09-25T06:09-07:09) contra a BOM, por amostragem dirigida às peças críticas: `ADR4525WBRZ-R7` (14,80/11,59/9,91 USD, stock 2147, "Restricted Availability"), `TPS7A4001DGNR` (3,53/2,65/2,18), `MCP3208T-BI/SL` (5,76/5,76/4,64 — sem quebra de preço em 10, correctamente usa o preço da quebra de 1), `ISO7141CCDBQR` (10,94/8,56/7,30, stock 0) — **todos batem exactamente** com o JSON, nenhum valor fabricado.
- `ADR4525BRZ` (peça original, citada como alternativa/motivo da troca): confirmei no JSON principal (não no ficheiro de alternativas) — stock `null`, `PriceBreaks: []`, `LifecycleStatus: "Restricted Availability"` — bate exactamente com a afirmação da BOM.
- **Schurter `3413.0002.11` vs `.22`** (`Schurter_USFF1206_3413.pdf`, págs. 3-4): confirmado — mesma linha eléctrica (0,05 A / 63 VDC / 9200 mΩ / I²t 0,0002 A²s / marcação "e"), os códigos `.11/.22/.24/.26` só diferem na embalagem (100 un. saco ESD / 1000 un. bobina 18 cm / 5000 / 10000). **Correcto.**
- **LED `Q65113A7469`** (datasheet OSRAM `KG_EELP41.22`, pág. 3, "Ordering Information"): a linha `KG EELP41.22-PHRH-35-A8J8` lista o código de encomenda **`Q65113A7469`** — correspondência exacta ao MPN original (sem o sufixo de embalagem `-20-R18`). **Correcto.**
- **`ISO7141CCDBQ` vs `ISO7141CCDBQR`** (TI, "Package Option Addendum", pág. 27): ambos "Active"/"Production", SSOP (DBQ) 16 pinos, mesma marcação "7141CC", mesmo MSL/acabamento; só mudam `75 | TUBE` vs `2500 | LARGE T&R`. **Correcto.**

## 4 · Mapa de pinos vs netlist

Pedido: amostragem de 5-10 pinos. Fiz a verificação **completa** dos 4 componentes de maior pinagem do mapa (66 pinos no total), comparando `mapa_pinos_EBM2_V5.md` contra o net-para-pino extraído por mim da `EBM2_V5.net` final (a mesma usada na BOM, `tandaC`, 2026-09-25T07:10:38):

- `U500` (MCP3208, 16 pinos): 16/16 batem.
- `U400` (ISO7141CCDBQR, 16 pinos): 16/16 batem.
- `P1` (Harwin M20-7822046, 20 pinos, incl. os "sem ligação"): 20/20 batem — os pinos NC do mapa correspondem exactamente às redes `unconnected-(P1-Pin_N-PadN)` do netlist.
- `P2` (Harwin M20-7821446, 14 pinos): 14/14 batem.

**Zero divergências em 66/66 pinos.**

- **Achado #2 (severidade baixa):** o cabeçalho de `mapa_pinos_EBM2_V5.md` cita a netlist `EBM2_V5_rev25c.net`, mas a BOM/Portão 1 final usa `EBM2_V5.net` (tanda C, gerada depois, 07:10). Verifiquei que isto **não causou nenhuma divergência real** — as rondas B/C só mudaram MPN/pegada de componentes (C200, C202, R206, U202), nenhuma rede foi alterada entre essas revisões. É uma nota de higiene documental (referência desactualizada no cabeçalho), não um erro de conteúdo.
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

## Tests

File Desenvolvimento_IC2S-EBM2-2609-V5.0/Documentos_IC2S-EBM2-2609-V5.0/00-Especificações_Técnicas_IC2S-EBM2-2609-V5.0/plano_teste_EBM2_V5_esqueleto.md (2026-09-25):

---
documento: Esqueleto do plano de teste
projecto: IC2S Extension Board EBM2 V5 (6AI)
fase: F0, etapa 3
data: 2026-09-23
dono: **Testes e Qualidade**
origem: derivado de escopo_EBM2_V5.md
---

# Esqueleto do plano de teste — EBM2 V5

> **A partir daqui este documento pertence a Testes e Qualidade.** A F0 entrega
> o esqueleto: um item por critério de aceite, com método sugerido de bancada.
> Quem o completa, valida e assina é a T&Q.

> **Aviso, actualizado em 2026-09-23 no fim da F1.** Os dois gaps bloqueantes
> `G1` e `G2` fecharam, e com eles `T4` e `T7` deixaram de estar travados.
> Em contrapartida **`T11` e `T22` ficaram sem objecto**: os critérios que
> verificavam foram reescrito e retirado do escopo. E `T7` ganhou uma condição
> nova que não tinha: ver a nota abaixo da tabela da secção 2.

---

## 1 · Compatibilidade

| # | Critério | Método sugerido | Equipamento |
|---|---|---|---|
| T1 | `RC1` contorno e furação idênticos | Sobrepor os Gerbers da V5 aos da V4.1 e medir o desvio máximo | Comparação de Gerber por script; paquímetro na placa física |
| T2 | `RC2` pinagem de `P1` e `P2` inalterada | Comparação nó a nó das duas netlists | Script; **já disponível** e usado nesta sessão |
| T3 | `RC3` a base board não distingue as duas | Montar V4.1 e V5 no mesmo quadro e comparar leituras da base board | Quadro de ensaio com base board |
| T4 | `RC4` firmware existente funciona | **DESTRAVADO.** Montar a V5 num quadro com firmware actual, correr a calibração de fábrica e comparar leituras contra padrão em 4, 12 e 20 mA | Quadro de ensaio, fonte de corrente calibrada |
| **T4b** | `RC4` troca de placa (2026-09-24) | (a) Instalar a V5 num quadro com a calibração da V4.1 ainda activa e registar o erro (esperado ≈ −9,3 %) e os `"null"` perto de 4 mA; (b) recalibrar os seis canais pela tela (6 pontos) e repetir T7. Confirma a regra «recalibrar ao instalar» | Quadro de ensaio, fonte de corrente rastreável |

## 2 · Medida

| # | Critério | Método sugerido | Equipamento |
|---|---|---|---|
| T5 | `RM1` seis canais independentes | Injectar 4,000 e 20,000 mA num canal de cada vez e ler os seis. Diafonia < 1 LSB | Fonte de corrente calibrada, 4 dígitos e meio |
| T6 | `RM2` fundo de escala ≥ 20,5 mA | Rampa de corrente até saturação e registar o ponto onde a leitura deixa de subir | Fonte de corrente programável |
| T7 | `RE1` exactidão de 0,1 a 0,2 % | Três pontos (4, 12, 20 mA) em cada canal, contra padrão rastreável, **com a constante de calibração comum de fábrica, nunca uma por unidade** | Fonte de corrente rastreável |
| | *Nota 2026-09-24* | A calibração real é por canal, em campo, em 6 pontos (resposta do firmware). **T7 faz-se depois dessa calibração**, com uma fonte diferente da usada para calibrar, em pontos intermédios (6, 10, 14, 18 mA) além de 4, 12 e 20. Registar a exactidão da fonte | |
| T8 | `RM3` corte entre 400 e 550 Hz | Injectar corrente com componente alterna e varrer a frequência; achar o ponto de −3 dB | Gerador de corrente alterna sobre a média |

## 3 · Alimentação e protecção

| # | Critério | Método sugerido | Equipamento |
|---|---|---|---|
| T9 | `RA1` funciona de **18 a 32 V** (corrigido em 2026-09-23) | Varrer a alimentação e verificar que a medida não desvia mais de 1 LSB | Fonte de bancada |
| T10 | `RA2` **os fusíveis não abrem no arranque** | **100 ciclos de ligar e desligar** com os seis canais carregados. Nenhum fusível abre. Margens de I²t **a 32 V** (rev. 2.2) contra a tabela Eaton: **23,4×** na rama dos laços e **12,3×** na do regulador, com `R3` de **33 Ω**. **Com os 22 Ω anteriores eram 8,6× a 32 V e o critério reprovava; sem `R3`, 1,2×.** Fazer os 100 ciclos a 32 V | Comutador temporizado; osciloscópio na corrente de entrada com pinça |
| ~~T11~~ | ~~`RA3` surto na entrada~~ | **SEM OBJECTO a partir de 2026-09-23.** Não há requisito de imunidade escrito, e o nível de 1 kV que o escopo citava tinha sido inventado. `RA3` passou a critério de projecto e verifica-se na revisão documental, não em bancada | — |
| T12 | `RA4` clamp com sumidouro real | Injectar 30 V numa entrada de campo com a placa alimentada e medir `3V3_REF` com osciloscópio | Fonte de bancada, osciloscópio, ponta no ponto de prova de `3V3_REF` |
| T13 | `RA5` consumo ≤ 200 mA | Medir a corrente em `P1.20` com os seis canais a 20 mA | Multímetro em série, ou shunt no ponto de prova de `+24V` |
| **T26** | `V8` transmissor em curto (rev. 2.1) | Curto franco entre `LOOPk_V+` e `AINk-`, alimentação a **32 V**, câmara a **+70 °C**, **1 h** por canal e depois os seis ao mesmo tempo. Corrente entre 23,75 e 26,8 mA; limitador a ~25,5 V e ~0,68 W; nenhuma resistência acima da nominal (termografia); se o `U8-U13` entrar em corte térmico, registar o ciclo e recuperar sem dano. Repetir a −40 °C | Câmara, fonte de bancada, câmara térmica, multímetro em série |
| **T27** | Limitador não interfere com a medida nem oscila (rev. 2.1) | (a) T7 com e sem o `U8-U13` em ponte: diferença < 1 LSB. (b) Transmissor real forçado a alarme alto (≥ 22,5 mA) e a 3,6 mA: osciloscópio no nó `AINk_LIM`, sem oscilação. (c) Tensão em `U8-U13` a 20 mA a −40, +25 e +85 °C (a fig. 15 do datasheet só dá 25 °C) | Fonte de corrente, transmissor 2 fios, osciloscópio, câmara |

**T10 e T12 são os dois ensaios que fecham os defeitos que motivaram a
revisão.** Se algum deles falhar, a revisão não cumpriu o seu objectivo.

## 4 · Ambiente

| # | Critério | Método sugerido | Equipamento |
|---|---|---|---|
| T14 | `RB1` medida correcta a 0, +25 e +70 °C | Repetir T5, T6 e T7 dentro da câmara, com estabilização de 30 min por patamar | Câmara climática |
| T15 | `RB2` BOM sem peças fora de gama | Auditoria documental da BOM contra os datasheets | Revisão de documentos, não bancada |
| T16 | `RB3` deriva ≤ 0,2 % entre 0 e +70 °C (calibrar a 0 °C e medir a +70 °C, o pior caso) | Diferença entre os extremos de T14 | Câmara climática |

## 5 · Isolamento

| # | Critério | Método sugerido | Equipamento |
|---|---|---|---|
| T17 | `RI1` nada se declara | Verificação documental: o dossier **não** invoca IEC 60664-1 nem declara tensão de isolamento | Revisão de documentos |
| T18 | `RI2` nenhum condutor atravessa a barreira | Medição segmento a segmento da distância mínima entre os dois domínios, em todas as camadas, incluindo ilhas e vias | Script sobre o `.kicad_pcb`; **já existe**, usado nesta sessão na EBM7 |
| T19 | `RI3` união de massas num ponto único | Continuidade entre `GND_24V` e `GND_ADC` com o 0 Ω montado e com ele removido | Multímetro; e o mesmo script de T18 |

**T18 não é opcional.** Na placa irmã este ensaio destapou uma barreira de
0,3005 mm onde o relatório anunciava 1,2 mm, porque a medição original só tinha
olhado para o cobre roteado e não para o enchimento das zonas.

## 6 · DFT

| # | Critério | Método sugerido |
|---|---|---|
| T20 | `RD1` ponto de prova em cada trilho | Contagem e acesso com ponta de prova em cada um dos nove |
| T21 | `RD2` ≥ 3 fiduciais | Inspecção visual da face SMD |
| ~~T22~~ | ~~`RD3` acesso mecânico no quadro~~ | **SEM OBJECTO a partir de 2026-09-23**: `RD3` saiu do escopo por não haver desenho do quadro |

---

## Requisitos de DFT que a placa TEM de incorporar

Isto não é ensaio: é o que o esquemático tem de desenhar para que os ensaios
acima sejam possíveis. Vai para a F2 como requisito, não como sugestão.

1. **Ponto de prova em cada trilho de alimentação**, nove ao todo: `+24V`,
   `+24V_ADC`, `+24V_REG`, `+5V`, `3V3_REF`, a referência do ADC, `GND_24V`,
   `GND_ADC` e `DGND`.
2. **Ponto de prova do lado seguro da barreira.** O ponto de `DGND` fica no lado
   do barramento. Sonda no lado de campo com a placa ligada atravessa a
   separação pela massa do osciloscópio.
3. **Provisão para medir a corrente de entrada** sem cortar pista: o ponto de
   prova de `+24V` mais o retorno permitem pinça, ou prevê-se um shunt.
4. **Consolidar pontos no mesmo nó eléctrico.** Dois pads na mesma rede não
   medem nada diferente e custam área.
5. **≥ 3 fiduciais** na face com SMD.
6. ~~**Acesso mecânico** aos pontos com a placa montada~~ — **retirado** com o `RD3`.

## Cobertura

| | |
|---|---|
| Critérios de aceite no escopo, depois da F1 | 22 |
| Itens de teste derivados | 22 |
| Itens sem objecto, critério retirado ou reescrito | 2 — `T11` e `T22` |
| Itens destravados na F1 | 2 — `T4` e `T7` |
| Itens novos, abertos pelo datasheet do conversor | 3 — `T23`, `T24`, `T25` |
| **Itens prontos a escrever** | **23** |
| Itens que o cálculo já reprova | 1 — `T7`, se a calibração ficar comum |

**O Portão 0 foi assinado em 2026-09-23** e os critérios congelaram nesse
momento. É contra eles que a F6 valida, e a T&Q pode começar a escrever.

**Duas ressalvas que a T&Q tem de conhecer antes de começar:**

1. **`T10` e `T12` continuam a ser os dois ensaios que justificam esta revisão.**
   Se algum falhar, a V5 não corrigiu o que se propôs corrigir.
2. **`T7` reprova por cálculo no pior caso.** A calibração é uma **constante
   comum** (confirmado pelo projectista em 2026-09-23) e com ela o pior caso de
   `RE1` é **0,237 %** contra 0,2 %; o típico é 0,139 %. Enquanto o escopo não
   decidir se `RE1` é pior caso ou típico, **o critério de aprovação de `T7` não
   está definido**, e a T&Q não o deve escrever.
3. Uma nota para quando `T7` se escrever: a medição em 4, 12 e 20 mA contra
   padrão rastreável é a mesma que serviria para calibrar por unidade. A decisão
   de não o fazer é do produto; o custo de ensaio seria zero.
4. **`T14` e `T16` cumprem, mas com 83 % do orçamento gasto**, e quase tudo no
   burden. Se reprovarem não há troca fácil: a 110 Ω o grau de ±25 ppm/°C é o
   melhor que a família Panasonic ERA oferece, porque os graus finos só começam
   em 470 Ω e 1 kΩ. Apertar exige mudar de fabricante.
5. **Três ensaios novos que o datasheet do conversor obriga a acrescentar**, e
   que a T&Q tem de escrever:
   - **`T23`** — o canal 4 (termístor) lê correctamente a **+70 °C**. Com o
     divisor herdado da V4.1 saturaria a 70 °C. Corre dentro da câmara, junto
     com `T14`.
   - **`T24`** — mapa de canais. Injectar uma corrente distinta em cada um dos
     seis canais de campo e confirmar que o firmware os lê em `CH0`, `CH1`,
     `CH2`, `CH3`, `CH6` e `CH7`. **Uma troca aqui não dá erro nenhum**, só dois
     valores errados.
   - **`T25`** — integridade da transacção SPI. Com a placa a +70 °C, confirmar
     que a leitura não degrada sob carga do sistema operativo do mestre. O
     conversor só garante a carga do condensador de amostra durante 1,2 ms
     depois do fim da amostragem, e uma transacção partida pelo escalonador dá
     erro de linearidade sem qualquer indicação.

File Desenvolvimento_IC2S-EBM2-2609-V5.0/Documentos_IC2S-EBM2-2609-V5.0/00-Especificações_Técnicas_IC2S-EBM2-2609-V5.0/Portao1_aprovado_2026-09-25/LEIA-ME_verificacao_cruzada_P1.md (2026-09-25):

# Portão 1 — verificação cruzada · EBM2 V5 (6AI 4-20 mA)

**Quem desenhou não valida.** O autor é o Claude Opus 5.5. Esta verificação corre numa **sessão nova, com modelo
diferente**, sem o histórico da conversa de autoria. O objectivo é **encontrar o que impede a assinatura**, não
confirmar o que o autor escreveu.

## O que o Portão 1 aprova (skill `2shw-pcb:fluxo`, portão P1)

Os **três blocos da F2**: (1) diagrama de blocos; (2) **esquemático KiCad com ERC limpo** + documento de intenção;
(3) **BOM preliminar e mapa de pinos**. Assinado o P1 liberta-se a compra antecipada (Suprimentos) e a F3 (layout).

## Material (nesta pasta; só leitura fora dela)

| Ficheiro | Bloco |
|---|---|
| `diagrama_blocos_EBM2_V5.svg` | 1 |
| `EBM2_V5_F2_revisao_2026-09-25.pdf` (esquemático do KiCad + diagrama + mapa de pinos) | 1, 2, 3 |
| `EBM2_V5.net` (netlist exportada agora), `erc.json` | 2 |
| `intencao_EBM2_V5.md` (ver §9, §17), `escopo_EBM2_V5.md` (critérios `RA`, `RB`, `RC`, `RE`) | 2 |
| `LEIA-ME_F2_2.5.md` (portas e achados da etapa 2.5) | 2 |
| `bom_preliminar_EBM2_V5.md/.csv`, `bom_dados_mouser_*.json` (resposta crua da Mouser, 2026-09-25) | 3 |
| `mapa_pinos_EBM2_V5.md` | 3 |
| `datasheets/` (`LISTA.md` com md5) | todos |

O projecto KiCad (`C:\hw\hw-ebm2-v5\KiCad_EBM2_V5\`) e as verificações anteriores
(`C:\hw\hw-ebm2-v5\Documentos\verificacao_2_3b*`) podem ser **lidos, nunca editados**.

## Onde está o risco (prioridade da revisão)

A última revisão independente foi a 2.3b da rev. 2.5b. **Depois dela entraram tandas que só passaram portas
automáticas** — e a skill `2shw-pcb:esquematico` diz que uma tanda é esquemático novo e precisa de revisão
independente (na EBM7, dez correcções passaram todas as portas e criaram dois bloqueantes novos):

| Tanda | O que mudou | O que conferir |
|---|---|---|
| rev. 2.5c | `R3` 68 → **150 Ω** | `RA2` do `F1` (Eaton 4309 pág. 2 e curva pág. 4); arranque a 18 V (VIN mín. do `U1`); o `R3` num curto de `+24V_REG` |
| Textos 25c | Notas de 5 folhas; grampo do `D2` corrigido para 53,3 V | Que o novo número está certo (Bourns SMA6J33A pág. 2) e que nenhuma decisão dependia do antigo |
| BOM tanda A | 14 MPN; **`C4` em 1206** `C3216X5R1H106K160AB`; pontos de prova fora da BOM | Cada MPN contra o valor, a tensão e a pegada da netlist; a pegada nova do `C4` |
| BOM tanda B | `U2` → **`ADR4525WBRZ-R7`**; `R3` = **KOA `SG73P2ATTD1500F`**; porto DGND do `P1.12` na folha 01 | Equivalência de grau e pinagem do ADR (tabela 14 pág. 40); curva de impulso do SG73P (pág. 2); a folha 01 ampliada |
| `C1` | (ver `intencao` §17 linha 11) | ≥ 1 µF efectivo a 32 V e ≤ 2,2 µF (`RA2`) |

## O que fazer

1. **Bloco 2 — esquemático.** ERC (erros = 0, sem ignorar avisos que sejam achados). Netlist contra as tabelas da
   intenção (§4, §8, §9, §17). **Polaridade de cada díodo, TVS, LED e CI por render ampliado**, peça a peça, contra
   a netlist — a skill diz que nenhuma ferramenta substitui isto. Texto sobre símbolo ou fora da moldura.
2. **Bloco 3 — BOM e pinos.** Cada linha da BOM contra a netlist (refs, quantidades, MPN, pegada); cada MPN contra
   o seu datasheet (valor, tensão, dieléctrico, encapsulamento); dados comerciais com data e fonte (nada estimado);
   alternativas «verificadas» realmente equivalentes. O mapa de pinos contra a netlist.
3. **Bloco 1 — diagrama.** Coerente com o esquemático actual (peças, trilhos, barreira).
4. **As tandas da tabela acima**, uma a uma, com a conta refeita e a página citada (texto E figura).
5. Tudo o que a revisão não conseguiu verificar entra como limitação, não como «ok».

## Saída pedida

`relatorio_verificacao_cruzada_P1_EBM2_V5.md` nesta pasta, em **português**, com:
- veredicto por bloco: **aprovado / aprovado com ressalvas / reprovado**, e o veredicto do portão;
- tabela de achados: `# | bloco | onde | achado | evidência (ficheiro, página) | severidade (bloqueante / ressalva / nota)`;
- o que foi conferido e o que não foi (limites).

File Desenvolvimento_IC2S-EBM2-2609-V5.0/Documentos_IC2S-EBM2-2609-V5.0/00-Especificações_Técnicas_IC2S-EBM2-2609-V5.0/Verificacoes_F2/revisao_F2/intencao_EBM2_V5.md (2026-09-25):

# Documento de intenção — IC2S Extension Board EBM2 V5 (6AI)

| | |
|---|---|
| Projecto | IC2S Extension Board EBM2, 6 entradas 4-20 mA |
| Revisão do documento | **2** — reescrita em 2026-09-23 depois da F0, da F1 e do datasheet do `MCP3208` |
| Fase | F2, etapa 2.2a |
| Autoridade | **Este documento manda até ao primeiro ERC limpo.** A partir daí manda o `.kicad_sch` e este texto congela como registo de intenção. O ERC ainda não está limpo: faltam as folhas 01, 04, 05, 06 e 07 |
| Base | `planejamento_pcb_EBM2_V5.md` rev. 3 e a V4.1 convertida e auditada, copiada antes de inventar |
| Histórico | A revisão 1 está em `intencao_EBM2_V5_rev1_historico.md`. Ficou superada em oito pontos |

> ## ✅ APROVADO pelo projectista em 2026-09-23
>
> Javier Rivadineira aprovou esta revisão 2 em 2026-09-23 («documento aprobado»).
> A aprovação cobre a especificação das folhas 01, 04, 05, 06 e 07, a proposta de
> LED da §11 e o diagrama de blocos da etapa 2.1. **Não cobre**, porque são
> decisões à parte e continuam abertas: a `V8` (transmissor em curto, antes do
> Portão 1) e o critério `RE1` (pior caso ou típico, Portão 0). A 2.2b desenha-se
> com o que está especificado; se a `V8` pedir peças novas, entram depois.

> **Para o projectista rever antes de se desenhar qualquer folha nova.** A
> skill exige esta aprovação entre a 2.2a e a 2.2b. As folhas 02 e 03 já estão
> desenhadas e verificadas; as secções delas descrevem o que está no CAD. As
> folhas 01, 04, 05, 06 e 07 **ainda não existem**, e é sobre elas que esta
> revisão pede aprovação.

---

## 1 · O que este documento decide, em poucas linhas

1. **O mapa de canais do conversor fica congelado como na V4.1**: campo em
   `CH0`-`CH3`, `CH6` e `CH7`; `CH4` é o termístor; `CH5` fica preso ao trilho.
2. **O 5 V do barramento chama-se `+5V` e o 5 V de campo chama-se `+5V_ADC`**,
   como na V4.1. Já se corrigiu a folha 03, que chamava `+5V` ao trilho de
   campo: se a folha 01 tivesse um porto `+5V`, as duas redes fundiam-se e a
   barreira ficava anulada sem mensagem de erro nenhuma.
3. **O isolador passa a ter `VCC1` a 3,3 V** por um `MCP1824S`, que fecha o gap
   `G2`: o pino `MISO` deixa de levar 5 V à Raspberry Pi.
4. **O termístor ganha um condensador de 100 nF no pino**, que a V4.1 não tinha.
   Sem ele, a figura 4-2 do `DS21298E` põe o canal fora de especificação a
   1 MHz de relógio.
5. **Duas verificações novas que não são pormenor**: com os 24 V sem isolamento
   e sem limite de corrente, um transmissor em curto deixa passar ~64 mA
   sustentados, que o fusível de 50 mA não abre e que queimam a resistência
   série de 249 Ω. ~~É uma regressão face à V4.1~~ **Correcção de 2026-09-23: não é
   regressão.** O `PDM2-S24-S24-S` da V4.1 só aguenta curto durante 1 s e não tem
   protecção de sobrecarga (datasheet CUI); a V4.1 fazia passar ~65 mA no mesmo caso.
   O defeito é herdado e precisa de decisão (`V8`); proposta no
   `Relatorio_Melhorias_Isolamento_V8_RE1_2026-09-23.md`.
   E a tensão que sobra ao transmissor a 20 V de entrada é ~11 V (`V9`).

## 2 · Estrutura de folhas e designadores

| Folha | Bloco | Designadores | Estado |
|---|---|---|---|
| 01 | Conectores `P1`, `P2`, fiduciais | `P1`, `P2`, `FID101`-`FID103` | **por desenhar** |
| 02 | Entrada de 24 V e protecção | série 200 | desenhada e verificada |
| 03 | Alimentação | série 200, portos `#PWR3xx` | desenhada e verificada |
| 04 | Barreira: `ISO7141` e o seu LDO | série 400 | **por desenhar** |
| 05 | Conversor `MCP3208` | série 500 | **por desenhar** |
| 06 | Seis laços 4-20 mA | série 600 | **por desenhar** |
| 07 | Termístor da placa | série 700 | **por desenhar** |

**Regra de designador**: prefixo mais número, sem sufixos de letra. As folhas
02 e 03 partilham a série 200 porque foram desenhadas antes desta regra; não se
renumeram, porque renumerar parte a rastreabilidade com a netlist já conferida.
A partir daqui, cada folha nova usa a sua centena.

### Correspondência V4.1 → V5 das peças herdadas

A comparação final nó a nó contra a V4.1 é por topologia, não por nome. Esta
tabela é o que permite lê-la.

| Função | V4.1 | V5 |
|---|---|---|
| Isolador | `U4` | `U400` |
| Conversor | `U5` | `U500` |
| LDO 3,3 V | `U11` | `U201` |
| Ferrite do `VCC2` do isolador | `FB2` | `FB400` |
| Ferrite do `VDD` do conversor | `FB3` | `FB500` |
| Desacoplamento `VCC1` / `VCC2` | `C7` / `C8` | `C401` / `C403` |
| Desacoplamento `VDD` do conversor | `C10` | `C502`, mais `C501` novo |
| Termístor e o seu divisor | `R5` / `R8` | `R700` / `R701` |
| Pull-up do `EN` do SPX3819 | `R34` | `R203` |
| Canais 1 a 6: fusível | `F1`-`F6` | `F601`-`F606` |
| Canais 1 a 6: TVS no retorno | `D4`,`D7`,`D13`,`D22`,`D2`,`D12` | `D601`-`D606` |
| Canais 1 a 6: TVS no trilho | `D3`,`D6`,`D10`,`D1`,`D11`,`D21` | `D611`-`D616` |
| Canais 1 a 6: série 249 Ω | `R6`,`R11`,`R18`,`R15`,`R1`,`R4` | `R601`-`R606` |
| Canais 1 a 6: burden | `R9`,`R13`,`R21`,`R17`,`R3`,`R14` | `R611`-`R616` |
| Canais 1 a 6: antialias 3,3 kΩ | `R7`,`R12`,`R19`,`R16`,`R2`,`R10` | `R621`-`R626` |
| Canais 1 a 6: condensador do filtro | `C9`,`C13`,`C18`,`C3`,`C1`,`C2` | `C601`-`C606` |
| Canais 1 a 6: clamp | `D5`,`D8`,`D14`,`D23`,`D9`,`D20` | `D621`-`D626` |
| LED | `D18` / `D19` / `D25` | `D204` / `D630` / `D203` |
| Resistência do LED | `R24` / `R25` / `R26` | `R208` / `R630` / `R207` |

**Saem da V4.1, e é essa a revisão**: os conversores isolados `U1`, `U7`, `U8`;
os díodos `D15`, `D16`, `D24`, `D17` e o zener em série `D26`; os fusíveis `F7`,
`F8`, `F9`; os electrolíticos `C12`, `C28`; a ferrite `FB4`; e os condensadores
que só serviam os conversores. O que os substitui está nas folhas 02 e 03.

## 3 · Trilhos e domínios

| Rede | Domínio | Origem | Quem a usa |
|---|---|---|---|
| `+24V` | campo, sem isolamento | `P1.20` | folha 02 |
| `GND_24V` | campo | `P1.19` | folha 02, unida a `GND_ADC` por `R200` |
| `+24V_ADC` | campo | `F202` → `D202` | folha 06, laços |
| `+24V_REG` | campo | `F201` → `D201` → `R206` | folha 03 |
| `+5V_ADC` | campo | `TPS7A4001` | folha 03 |
| `3V3_REF` | campo | `SPX3819`, grampo `TL431` | folhas 03, 04 (`VCC2`), 05, 06 (clamps) |
| `+2V5_REF` | campo | `ADR4525` | folhas 05 (`VREF`) e 07 (topo do divisor) |
| `GND_ADC` | campo | — | todas as de campo |
| `+5V` | **barramento** | `P1.17` | folha 04, entrada do `MCP1824S` |
| `+3.3V_DIG` | **barramento** | `MCP1824S` | folha 04, `VCC1` e `EN1` do isolador |
| `DGND` | **barramento** | `P1.3`, `P1.12`, `P1.16` | folha 04 |

**Só o `ISO7141` atravessa a barreira.** Nenhuma rede do barramento pode ter
pinos do lado de campo, nem o contrário. Depois de desenhar as folhas 01 e 04,
isso confere-se na netlist: nenhuma rede pode conter pinos de `DGND` e de
`GND_ADC` ao mesmo tempo, nem os dois lados do isolador.

## 4 · Folha 01 — conectores

### Ligações, como especificação

`P1` é o `Harwin M20-7822046`, 20 pinos, pegada `HDR1X20_FEMALE`. `P2` é o
`M20-7821446`, 14 pinos, `HDR1X14_FEMALE`. **A pinagem das duas está congelada
por `RC2` e copia-se da V4.1 pino a pino.**

| `P1` | Rede | Nota |
|---|---|---|
| 1, 2 | não ligado | `USB1`, `USB2` do barramento: esta placa não os usa |
| 3, 12, 16 | `DGND` | |
| 4 | `MOSI` | para o isolador, folha 04 |
| 5 | `CLK` | idem |
| 6 | `MISO` | do isolador |
| 7, 8 | não ligado | `CS_DAC`, `LDAC_DAC`: não há DAC nesta placa |
| 9 | `CS_ADC` | para o isolador, activo baixo |
| 10 | não ligado | `CS4` |
| 11, 13 | **não ligado, e tem de continuar assim** | `ID1`, `ID3`: ver abaixo |
| 14, 15 | não ligado | `SDA`, `SCL` |
| 17 | `+5V` | barramento, para o `MCP1824S` |
| 18 | não ligado | não existe na V4.1 |
| 19 | `GND_24V` | |
| 20 | `+24V` | |

| `P2` | Rede | Nota |
|---|---|---|
| 1 | não ligado | como na V4.1 |
| 2, 4, 6, 8, 10, 12 | `LOOP1_V+` … `LOOP6_V+` | alimentação de cada laço, saída do seu fusível na folha 06 |
| 3, 5, 7, 9, 11, 13 | `AIN1-` … `AIN6-` | retorno de cada laço, para a folha 06 |
| 14 | `GND_ADC` | |

As redes de sinal saem da folha por rótulo hierárquico. Os trilhos saem por
porto global com o nome exacto da tabela da §3.

### Porquê

- **Os pinos não usados levam no-connect explícito**, com a função do barramento
  escrita numa nota ao lado. Na V4.1 levavam rótulos soltos de um só pino; um
  no-connect diz o mesmo sem deixar ao ERC a dúvida de ser um fio esquecido.
- **`ID1` e `ID3` ficam desligados porque são, muito provavelmente, a identidade
  da placa perante a base board.** Na V4.1 estão desligados; se a V5 os ligasse,
  o firmware poderia deixar de a reconhecer, e isso parte `RC4`. `[EST]`: a
  função dos pinos ID não está documentada nos projectos da base board que se
  estudaram, por isso a regra é a mais segura — copiar o original.
- **`PWR_FLAG` em `+24V` e `GND_24V` é legítimo aqui**: o conector é uma fonte
  real e passiva. É isto que fecha os dois erros estruturais de ERC que ficaram
  pendentes desde a folha 02.

### DFT

Três fiduciais `FID101`-`FID103`, pegada `Fiducial_Point_Top-Bot`, como na
Legacy. São símbolos sem rede; vivem nesta folha porque são mecânicos.

## 5 · Folha 02 — entrada de 24 V *(desenhada)*

Está no CAD e verificada: netlist conferida nó a nó, ERC, zero sobreposições no
PDF. O dimensionamento completo está em `planejamento_pcb_EBM2_V5.md` §2.6 e nas
notas da própria folha. Resumo das ligações:

`+24V` → `T201` e TVS `D200` a `GND_24V`. Dois ramos: `F202` → `D202` →
`+24V_ADC` com `C201` 10 µF/100 V; e `F201` → `D201` → `+24V_DIO_REG` → `R206`
~~22 Ω~~ **33 Ω (rev. 2.2: margem de arranque a 32 V)** → `+24V_REG` com `C200` 2,2 µF/100 V. `GND_24V` → `R200` 0 Ω → `GND_ADC`.

**Acrescenta-se nesta folha**, por DFT e por LED (§11):

| Peça | Ligação | Porquê |
|---|---|---|
| `T206` | ponto de prova em `+24V_ADC` | `RD1` pede-o e ainda não existe |
| `T207` | ponto de prova em `+24V_REG` | idem |
| `D203` + `R207` 14,7 kΩ | LED de `+24V` a `GND_24V` | substitui `D25`; diz que há entrada |

**Desenhado em 2026-09-23** (`ferramentas/aplica_leds_tps_F2.py`): netlist idêntica ao diff
declarado (4 peças, 6 pinos). MPN `R207` = `ERJ-3EKF1472V` e LED `LG Q396-PS-35`, os da V4.1.

## 6 · Folha 03 — alimentação *(desenhada)*

Está no CAD, redesenhada em 2026-09-23 porque a primeira versão tinha dezenas de
textos encimados que nunca se tinham medido no PDF. Netlist conferida idêntica
antes e depois do redesenho. Ligações:

`+24V_REG` → `TPS7A4001` (`IN` e `EN` juntos) → `+5V_ADC` 4,974 V pelo divisor
32k4/10k → `SPX3819` (`EN` por `R203` 100 kΩ, `BP` com `C208` 10 nF) →
`3V3_REF` → `ADR4525` → `+2V5_REF`. `TL431` com `R204`/`R205` grampeia
`3V3_REF` a 3,60 V: é o sumidouro dos clamps de campo.

**Acrescenta-se nesta folha**: `D204` + `R208` 2,2 kΩ, LED de `+5V_ADC` a
`GND_ADC`, que substitui `D18` (§11).

**Desenhado em 2026-09-23**: netlist idêntica ao diff declarado (2 peças, 4 pinos).
MPN `R208` = `RC0603FR-072K2L`, o da V4.1 (`R24`).

## 7 · Folha 04 — barreira

### Ligações, como especificação

**Isolador `U400`, `ISO7141CCDBQR`**, pegada `SSOP16-4.9x3.9mm`. Pinagem
`[HERDADO]` da V4.1 auditada, a conferir contra o datasheet na etapa 2.3:

| Pino | Função | Lado | Rede |
|---|---|---|---|
| 1 | `VCC1` | barramento | `+3.3V_DIG` |
| 2, 8 | `GND1` | barramento | `DGND` |
| 3 | `INA` | barramento | `MOSI` |
| 4 | `INB` | barramento | `CLK` |
| 5 | `INC` | barramento | `CS_ADC` |
| 6 | `OUTD` | barramento | `MISO` |
| 7 | `EN1` | barramento | `+3.3V_DIG` |
| 9, 15 | `GND2` | campo | `GND_ADC` |
| 10 | `EN2` | campo | `VCC2_ISO` |
| 11 | `IND` | campo | `MISO_ADC_ISO` |
| 12 | `OUTC` | campo | `CS_ADC_ISO` |
| 13 | `OUTB` | campo | `CLK_ADC_ISO` |
| 14 | `OUTA` | campo | `MOSI_ADC_ISO` |
| 16 | `VCC2` | campo | `VCC2_ISO` |

`VCC2_ISO` vem de `3V3_REF` pela ferrite `FB400` (`BLM18PG471SN1D`), como na
V4.1, com `C403` 100 nF a `GND_ADC` no pino. `VCC1` leva `C401` 100 nF a `DGND`
no pino.

**LDO `U401`, `MCP1824ST-3302E/DB`**, pegada SOT-223-3 copiada da Legacy.
Pinagem lida na **figura** da pág. 2 do `DS22070A`: 1 `VIN`, 2 `GND`, 3 `VOUT`,
4 (patilha) `GND`. `VIN` em `+5V` com `C400` 1 µF a `DGND`; `VOUT` forma
`+3.3V_DIG` com `C402` 1 µF a `DGND`.

`T400`, ponto de prova em `DGND`, **deste lado da barreira**.

A barreira desenha-se como linha tracejada vertical que atravessa o `U400`, com
o texto «BARREIRA FUNCIONAL — DGND | GND_ADC». Nenhum fio a cruza.

### Porquê

- **`VCC1` a 3,3 V e não a 5 V fecha o `G2`.** Com `VCC1` a 5 V, o `OUTD` põe
  ~4,9 V no `GPIO9` da Raspberry Pi, e o clamp da base board a +3,3V_IC deixa-o
  em ~4,0 V, acima do máximo da Pi, sem resistência série. A 3,3 V o problema
  desaparece na origem. As entradas continuam a ser atacadas pela Pi a 3,3 V.
- **Não há pino de enable no `MCP1824S`**: o S de SOT-223-3 não tem `SHDN`.
  O «EN1» do planeamento é o pino de enable do isolador, ligado ao seu `VCC1`.
- **`VCC2` fica pela ferrite a partir de `3V3_REF`**, como na V4.1: é a única
  carga digital do lado de campo e a ferrite impede que o seu ruído de comutação
  chegue ao trilho da referência.

### Dimensionamento

- `MCP1824S`: entrada 2,1-6,0 V (pág. 1), portanto os 5 V do barramento cabem
  com folga de 1 V. Estável com 1,0 µF cerâmico à saída (pág. 1). Carga: o lado 1
  do isolador, alguns mA contra 300 mA de capacidade.
- Desacoplamento do isolador: 100 nF por lado, no pino, como na V4.1. A nota de
  layout do datasheet do isolador confere-se na etapa 2.3b.

### Lógica activa

`CS_ADC` activo baixo. `EN1` e `EN2` presos a alto: o isolador está sempre
activo. Modo SPI 0,0 ou 1,1 (`DS21298E` §6.1).

## 8 · Folha 05 — conversor

### Ligações, como especificação

**`U500`, `MCP3208T-BI/SL`**, SOIC-16. Pinagem lida na figura da pág. 1 do
`DS21298E`:

| Pino | Função | Rede |
|---|---|---|
| 1 | `CH0` | `AIN1_ADC` |
| 2 | `CH1` | `AIN2_ADC` |
| 3 | `CH2` | `AIN3_ADC` |
| 4 | `CH3` | `AIN4_ADC` |
| 5 | `CH4` | `NTC_ADC` |
| 6 | `CH5` | `3V3_REF`, antes da ferrite, como na V4.1 |
| 7 | `CH6` | `AIN5_ADC` |
| 8 | `CH7` | `AIN6_ADC` |
| 9 | `DGND` | `GND_ADC` |
| 10 | `CS/SHDN` | `CS_ADC_ISO` |
| 11 | `DIN` | `MOSI_ADC_ISO` |
| 12 | `DOUT` | `MISO_ADC_ISO` |
| 13 | `CLK` | `CLK_ADC_ISO` |
| 14 | `AGND` | `GND_ADC` |
| 15 | `VREF` | `+2V5_REF`, com `C500` 100 nF no pino |
| 16 | `VDD` | `VDD_ADC`, de `3V3_REF` pela ferrite `FB500` |

`VDD_ADC` leva `C501` 1 µF **e** `C502` 100 nF a `GND_ADC`, os dois no pino.
`T500`, ponto de prova em `GND_ADC`.

### Porquê

- **O mapa de canais não é sequencial e fica congelado** (`RC4`). Pôr os seis
  canais em sequência faria o firmware ler o termístor como canal 5 e um valor
  saturado como canal 6, sem erro nenhum.
- **`CH5` preso a `3V3_REF` lê sempre 4095.** Não traz informação, mas o firmware
  existente pode verificá-lo; mudá-lo arriscaria `RC4`. Fica como está.
- **1 µF no `VDD` e não 100 nF**: é o que a §6.4, pág. 23, recomenda. A V4.1 tinha
  só 100 nF.
- **100 nF no pino de `VREF`** para o desacoplamento de alta frequência junto ao
  conversor. O 1 µF da figura 6-3 já existe como `C207`, à saída do `ADR4525`.
- **`AGND` e `DGND` são pinos distintos e vão os dois a `GND_ADC`**, com
  percursos próprios no layout.

### Restrições que o firmware tem de cumprir

1. Relógio SPI **≤ 1 MHz**: os 2 MHz só estão garantidos a `VDD` = 5 V.
2. Transacção de 24 bits **atómica** por canal: a 85 °C a carga do condensador de
   amostra só se garante 1,2 ms depois da amostragem (§6.2). Partida pelo
   escalonador do Linux, dá erro de linearidade sem aviso.
3. Cadência por canal **abaixo de 4 kHz**, para os 3,3 kΩ custarem menos de 1 LSB.
4. **Estado real (Rodrigo, 2026-09-24):** SPI a **20 kHz**. Os 12-13 bits levam ~0,65 ms, dentro
   dos 1,2 ms da §6.2 (relógio efectivo mínimo de 10 kHz), com margem de ~1,8×: **não baixar mais**.
   A amostragem dura 1,5 ciclos = 75 µs, bem acima do que a fig. 4-2 pede para a fonte de 3,3 kΩ.
5. **O CH4 (NTC) e o CH5 não são lidos pelo software actual.** O divisor do termístor (`R700`,
   `R701`, `C700`) fica montado: são três peças baratas, mantêm o mapa de canais da V4.1 e deixam a
   compensação de temperatura possível no futuro. **Não se justifica nenhuma decisão de projecto
   com «o firmware lê o NTC».**
6. **Satura em silêncio acima de 20 mA.** Com o limitador (`V8`), um transmissor em curto dá o
   código 4095 (~22,7 mA). Pedido ao firmware: tratar 4095 como falha (curto ou alarme alto NE43).

> **Resposta do firmware (Rodrigo, 2026-09-24), tirada do código do DeviceManager.** Na EBM2 não
> há firmware à parte: o backend Node (`extensions/EBM2.js`, `extensions/expander.js`) lê o ADC.
> - **Calibração por canal, no campo, em 6 pontos** (0, 4, 8, 12, 16, 20 mA), pela tela
>   Settings → mapa → Calibrar: 5 trechos lineares, ganho e offset por trecho, guardados no MongoDB
>   **ligados à variável, não à placa**. Sem calibração não há conversão para mA.
> - **Ao trocar a placa a calibração antiga continua aplicada** e nada obriga a recalibrar.
> - SPI a **20 kHz** fixos; média móvel de 10 amostras a cada 500 ms; a captura da calibração usa
>   **uma amostra instantânea**.
> - **CH4 (NTC) e CH5 não são lidos.** AI1-AI6 = CH0, CH1, CH2, CH3, CH6, CH7.
> - Acima de 20 mA não há limite nem aviso (satura em silêncio); abaixo de 3,6 mA a variável vira
>   `"null"` (laço aberto), **só com o canal calibrado**.

## 9 · Folha 06 — seis laços

### Ligações, como especificação

Por canal *k*, de 1 a 6. Exemplo do canal 1:

`+24V_ADC` → fusível `F601` → `LOOP1_V+`, que vai ao pino 2 de `P2` e alimenta o
transmissor. O retorno chega por `AIN1-`, pino 3 de `P2`. Desse nó sai o TVS
`D601` (cátodo no nó, ânodo a `GND_ADC`) e o **limitador de corrente `U601`
`AL5809-25P1-7`** (pino 1 `In` no nó `AIN1-`, pino 2 `Out` em `AIN1_LIM`), com o
Schottky **`D641` `BAT46W`** em antiparalelo (cátodo em `AIN1-`, ânodo em
`AIN1_LIM`). De `AIN1_LIM` sai a série `R601` **100 Ω 1206** (rev. 2.2). O outro terminal
de `R601` é o nó de medida: burden `R611` 110 Ω a `GND_ADC` e antialias `R621`
3,3 kΩ. O outro terminal de `R621` forma `AIN1_ADC`, com `C601` 100 nF a
`GND_ADC` e o clamp `D621` `BAV199`: pino 3 no sinal, pino 1 a `GND_ADC`, pino 2
a `3V3_REF` (figura da pág. 1 do `BAV199LT1/D`). O TVS `D611` fica entre
~~`+24V_ADC`~~ **`LOOP1_V+`, depois do fusível `F601`, no lado do terminal** (rev. 2.3), e `GND_ADC`.

| Canal | Alimentação | Retorno | Rede no ADC | Canal ADC |
|---|---|---|---|---|
| 1 | `P2.2` | `P2.3` | `AIN1_ADC` | `CH0` |
| 2 | `P2.4` | `P2.5` | `AIN2_ADC` | `CH1` |
| 3 | `P2.6` | `P2.7` | `AIN3_ADC` | `CH2` |
| 4 | `P2.8` | `P2.9` | `AIN4_ADC` | `CH3` |
| 5 | `P2.10` | `P2.11` | `AIN5_ADC` | `CH6` |
| 6 | `P2.12` | `P2.13` | `AIN6_ADC` | `CH7` |

| Peça | Valor | Part number | Pegada | Origem |
|---|---|---|---|---|
| Fusível | 50 mA | `3413.0002.22` | 1206 | Legacy |
| TVS retorno e trilho | ~~30 V~~ **36 V** | ~~`824500301`~~ **`824520361`** (SMBJ36A, 600 W) | **DO-214AA** | **rev. 2.2**: a 32 V o trilho chega a 31,4 V, acima dos 30 V de standoff do anterior. É o da EBM7 |
| Limitador de corrente | 23,75-26,25 mA | `AL5809-25P1-7` | PowerDI123 Type B | **rev. 2.1, fecha `V8`** |
| Schottky antiparalelo | 100 V | `BAT46W-E3-08` | SOD-123 | **rev. 2.1** |
| Série | ~~249 Ω 0603~~ ~~150 Ω~~ **100 Ω** | `RC1206FR-07100RL` | **1206** | **rev. 2.2**: tensão ao transmissor a 18 V |
| Burden | 110 Ω 0,1 % 25 ppm | ~~`ERA3AEB111V`~~ **`ERA8AEB111V`** | **1206** | F1 §2.5; **rev. 2.1** |
| Antialias | 3,3 kΩ | `RC0603FR-073K3L` | 0603 | V4.1 |
| Filtro | 100 nF | como V4.1 | 0603 | V4.1 |
| Clamp | — | `BAV199LT1G` | SOT23-3 | Legacy |

`D630` + `R630` 14,7 kΩ: LED de `+24V_ADC` a `GND_ADC`, substitui `D19` (§11).

### Porquê

- **Topologia copiada da V4.1**, com três valores mudados e já justificados na
  F1: burden 110 Ω, clamp `BAV199`, fusível de 50 mA.
- **Rev. 2.3 (2026-09-23): os seis TVS de laço passam para depois do fusível de canal, no
  terminal `LOOPk_V+`** — como na EBM7 Legacy (`D9`/`D10`/`D12`/`D13` em `+24V_AINk`). Um TVS em
  curto abre só o fusível do seu canal, em vez do `F202` e dos seis canais; um surto do campo
  descarrega no terminal sem atravessar o fusível (resta ~2,9 A de pico entre o grampo de
  58 V e o trilho de 31 V: aguenta 8/20 µs, pode abrir em 10/1000 µs); os surtos da fonte
  ficam só com o `D200` (simplifica a `V7`). Custo: uma fonte externa > 36 V ligada a um
  `LOOPk_V+` leva o TVS desse canal, e só desse. Sem efeito na medida.
- ~~**Os seis TVS de trilho ficam, agora num trilho só.**~~ *(texto da rev. 2, ultrapassado)* Na V4.1 havia dois
  trilhos isolados com três TVS cada. Com um trilho, seis é redundante, mas
  mantém um TVS junto de cada par de pinos de `P2`, que é onde a sobretensão
  entra. A interacção com o `D200` analisa-se na 2.3b (`V7`).
- **O fusível de canal passa a 1206**, porque a peça da Legacy é 1206. O da V4.1
  era 0603. O layout desta zona muda de qualquer forma.
- **Rev. 2.1 (2026-09-23, decidida pelo projectista): limitador por canal, fecha a
  `V8`.** Um transmissor em curto fazia passar 74 mA a 28 V e punha 1,4 W na série
  0603 — defeito herdado da V4.1, cujos `PDM2` não limitavam (curto 1 s, sem
  protecção de sobrecarga). O `AL5809-25` garante 23,75-26,25 mA de −40 a +125 °C
  (DS36625 rev. 5, pág. 4): acima dos 22,7 mA de saturação, logo não se perde
  leitura, e o alarme de 21 mA da NE43 lê-se. **No retorno**, em série com o burden,
  não altera a medida; um curto do `+` à massa não passa por ele e continua a abrir
  o fusível de 50 mA (é essa a razão do fusível, que faltava escrever). O `BAT46W`
  (100 V; V_F máx. 0,25 V a 0,1 mA e 0,45 V a 10 mA, Vishay 86406) protege o −0,3 V
  do `AL5809`; a ~3 mA de falha inversa ficam ~0,40 V, **acima dos −0,3 V: resíduo
  a confirmar na 2.3b**. Série a 150 Ω e burden em 1206 para aguentarem os 26 mA.
  Contas em `ferramentas/avalia_opcoes_V8_RE1.py` e no
  `Relatorio_Melhorias_Isolamento_V8_RE1_2026-09-23.md`. **Pegada do AL5809: Type B,
  duas ilhas iguais — não o PowerDI-123 do KiCad.**

  **Estudo completo do datasheet (DS36625 rev. 5-2, 16 págs., md5 7e46a75cc76e), 2026-09-23:**
  - *Queda a 20 mA* — fig. 15 (25 °C): não conduz abaixo de ~1,4 V; a 20 mA fica em
    ~1,6-1,7 V. As contas usam 2,5 V (mínimo recomendado, págs. 4 e 5) porque a fig. 15 é
    só típica e só a 25 °C. A margem real para o transmissor deve ser ~0,8 V melhor.
  - *Corrente em curto* — a tabela garante 23,75-26,25 mA a V_InOut = 3,5 V; a fig. 17
    mostra +1,5 a +2 % a 20 V. Máximo prático em curto ≈ **26,8 mA** (0,08 W no burden e
    0,11 W na série de 150 Ω: dentro de 1206).
  - *Térmica* — o calor sai **pela ilha do pino OUT** (pág. 8: «additional vias between the
    pad of the OUT pin»), e `OUT` é a rede `AINk_LIM`, não a massa. Com a ilha mínima e
    *[2026-09-24: `RB1` passou a 0-70 °C. A 70 °C, 32 V e curto permanente (0,68 W): Tj ≈ 125 °C com
    cobre alargado (nota 5), no limite recomendado; ≈ 171 °C com a ilha mínima (nota 4), em corte térmico.
    O cobre na ilha OUT continua obrigatório. Texto original abaixo:]*
    10 × 10 mm de cobre (nota 4, θJA 148,6 °C/W), o pior caso (85 °C, 28 V, curto
    permanente, ~0,55 W) daria Tj ≈ 167 °C e o **corte térmico (165 °C, histerese 30 °C,
    fig. 18) entraria em ciclo**. Com cobre alargado (nota 5, 81,4 °C/W), Tj ≈ 130 °C. A
    fig. 10 (placa FR4 de 2 camadas) admite ~30 V a 85 °C para a versão de 25 mA, contra
    os ~20,8 V do nosso curto. **Na F3: cobre e vias na ilha OUT de cada U60x.** Mesmo com
    cobre insuficiente, a peça protege-se: corta, a leitura cai a 0 mA e recupera.
  - As figuras térmicas do datasheet não são coerentes entre si (a fig. 10 a 25 °C pede
    1,25 W, mais do que a fig. 9 dá para FR4). Usa-se o caso pior e mede-se na bancada.
  - Dois reguladores de corrente em série (o transmissor e o AL5809): abaixo de 23,75 mA
    o AL5809 está fora de regulação e não interage. Perto dos 24 mA os dois tentam
    regular; o ADC já saturou a 22,7 mA. **Ensaio de bancada:** transmissor forçado a
    alarme alto, a ver se há oscilação.
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

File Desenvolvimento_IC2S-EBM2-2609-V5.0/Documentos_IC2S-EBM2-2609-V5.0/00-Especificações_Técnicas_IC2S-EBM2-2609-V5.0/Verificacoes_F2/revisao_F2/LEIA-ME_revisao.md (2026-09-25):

# Pacote de revisão — EBM2 V5, F2

Data: 2026-09-23. Projecto KiCad: `C:\hw\hw-ebm2-v5\KiCad_EBM2_V5\`.

## O que se pede a quem revê

**Quem escreveu não valida.** Este pacote é para uma revisão independente, noutra
sessão, sem o histórico de autoria.

| # | Revisar | Ficheiro | Contra o quê |
|---|---|---|---|
| 1 | Diagrama de blocos, etapa 2.1 | `diagrama_blocos_EBM2_V5.svg` | `planejamento_pcb_EBM2_V5.md` rev. 3 |
| 2 | Esquemático completo, etapa 2.2b: as 8 páginas | `esquematico_EBM2_V5_2026-09-23_folhas_completas.pdf` | `intencao_EBM2_V5.md` rev. 2 (aprovada em 2026-09-23), V4.1 auditada e datasheets da pasta de referência |

Páginas do PDF: 1 raiz, 2 conectores, 3 entrada, 4 alimentação, 5 barreira digital,
6 ADC, 7 laços, 8 NTC. Cada folha traz em azul as decisões que tomou e a fonte.

## Onde olhar primeiro
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

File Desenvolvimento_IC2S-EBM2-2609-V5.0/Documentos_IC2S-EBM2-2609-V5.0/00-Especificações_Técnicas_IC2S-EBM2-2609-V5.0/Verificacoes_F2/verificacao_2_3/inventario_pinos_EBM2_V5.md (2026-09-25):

# Inventário de pinagem — EBM2 V5 (entrada da etapa 2.3)

Gerado por `ferramentas/prepara_pacote_2_3.py` a partir da netlist exportada agora (`EBM2_V5.net`),
das pegadas do projecto e dos datasheets desta pasta. **Não contém conclusões da sessão que desenhou.**

Colunas por pino: número no símbolo → nome do pino no símbolo → tipo → rede. A verificação é conferir
cada linha contra o datasheet (número, nome, função, direcção, nível) e a pegada contra o desenho do
encapsulamento (ilha 1, marca de polaridade).
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

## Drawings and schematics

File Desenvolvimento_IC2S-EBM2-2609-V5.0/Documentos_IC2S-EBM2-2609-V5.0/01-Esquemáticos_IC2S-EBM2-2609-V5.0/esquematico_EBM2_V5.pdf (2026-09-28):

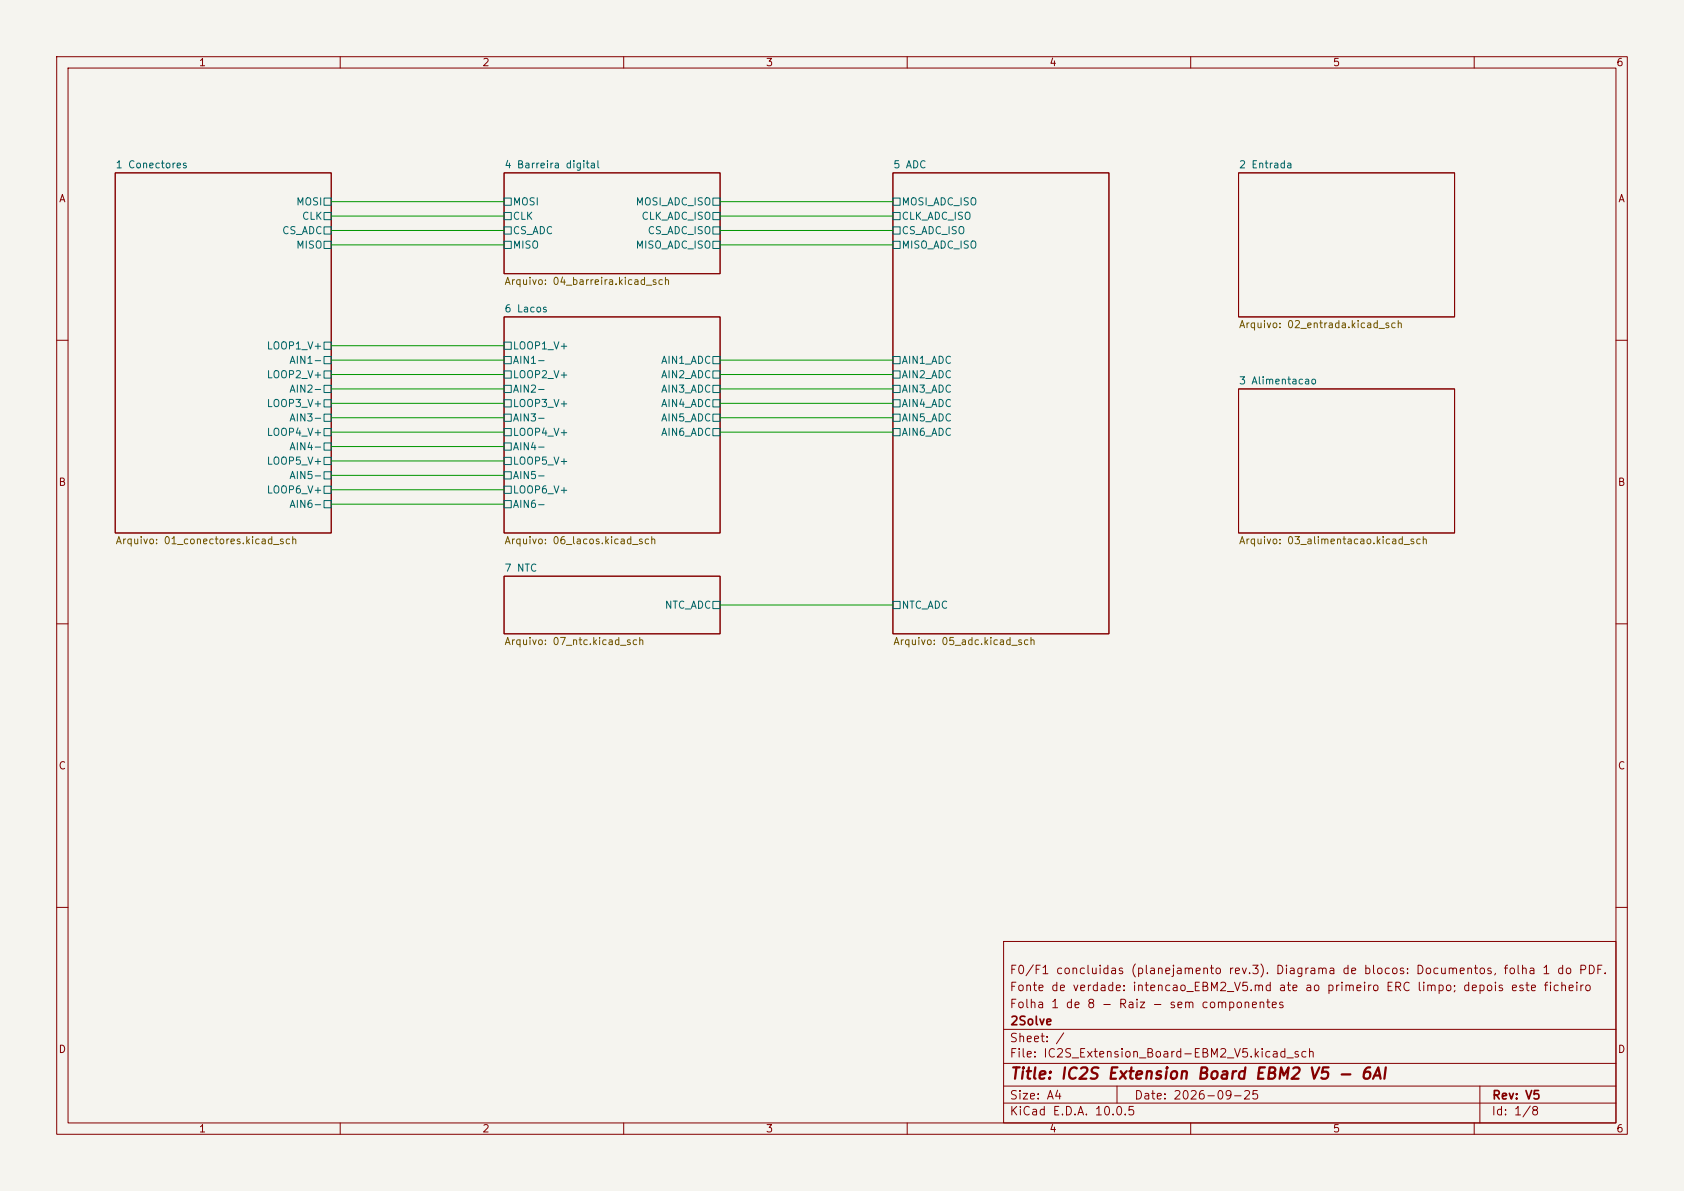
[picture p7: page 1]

1 Conectores Arquivo: 01_conectores.kicad_sch
6 Lacos Arquivo: 06_lacos.kicad_sch MOSI CLK

F0/F1 concluidas (planejamento rev.3). Diagrama de blocos: Documentos, folha 1 do PDF. NTC_ADC

Fonte de verdade: intencao_EBM2_V5.md ate ao primeiro ERC limpo; depois este ficheiro
Folha 1 de 8 - Raiz - sem componentes
2Solve
Sheet: /
File: IC2S_Extension_Board-EBM2_V5.kicad_sch
Title: IC2S Extension Board EBM2 V5 - 6AI

Size: A4 | Rev: V5
KiCad E.D.A. 10.0.5 | Id: 1/8

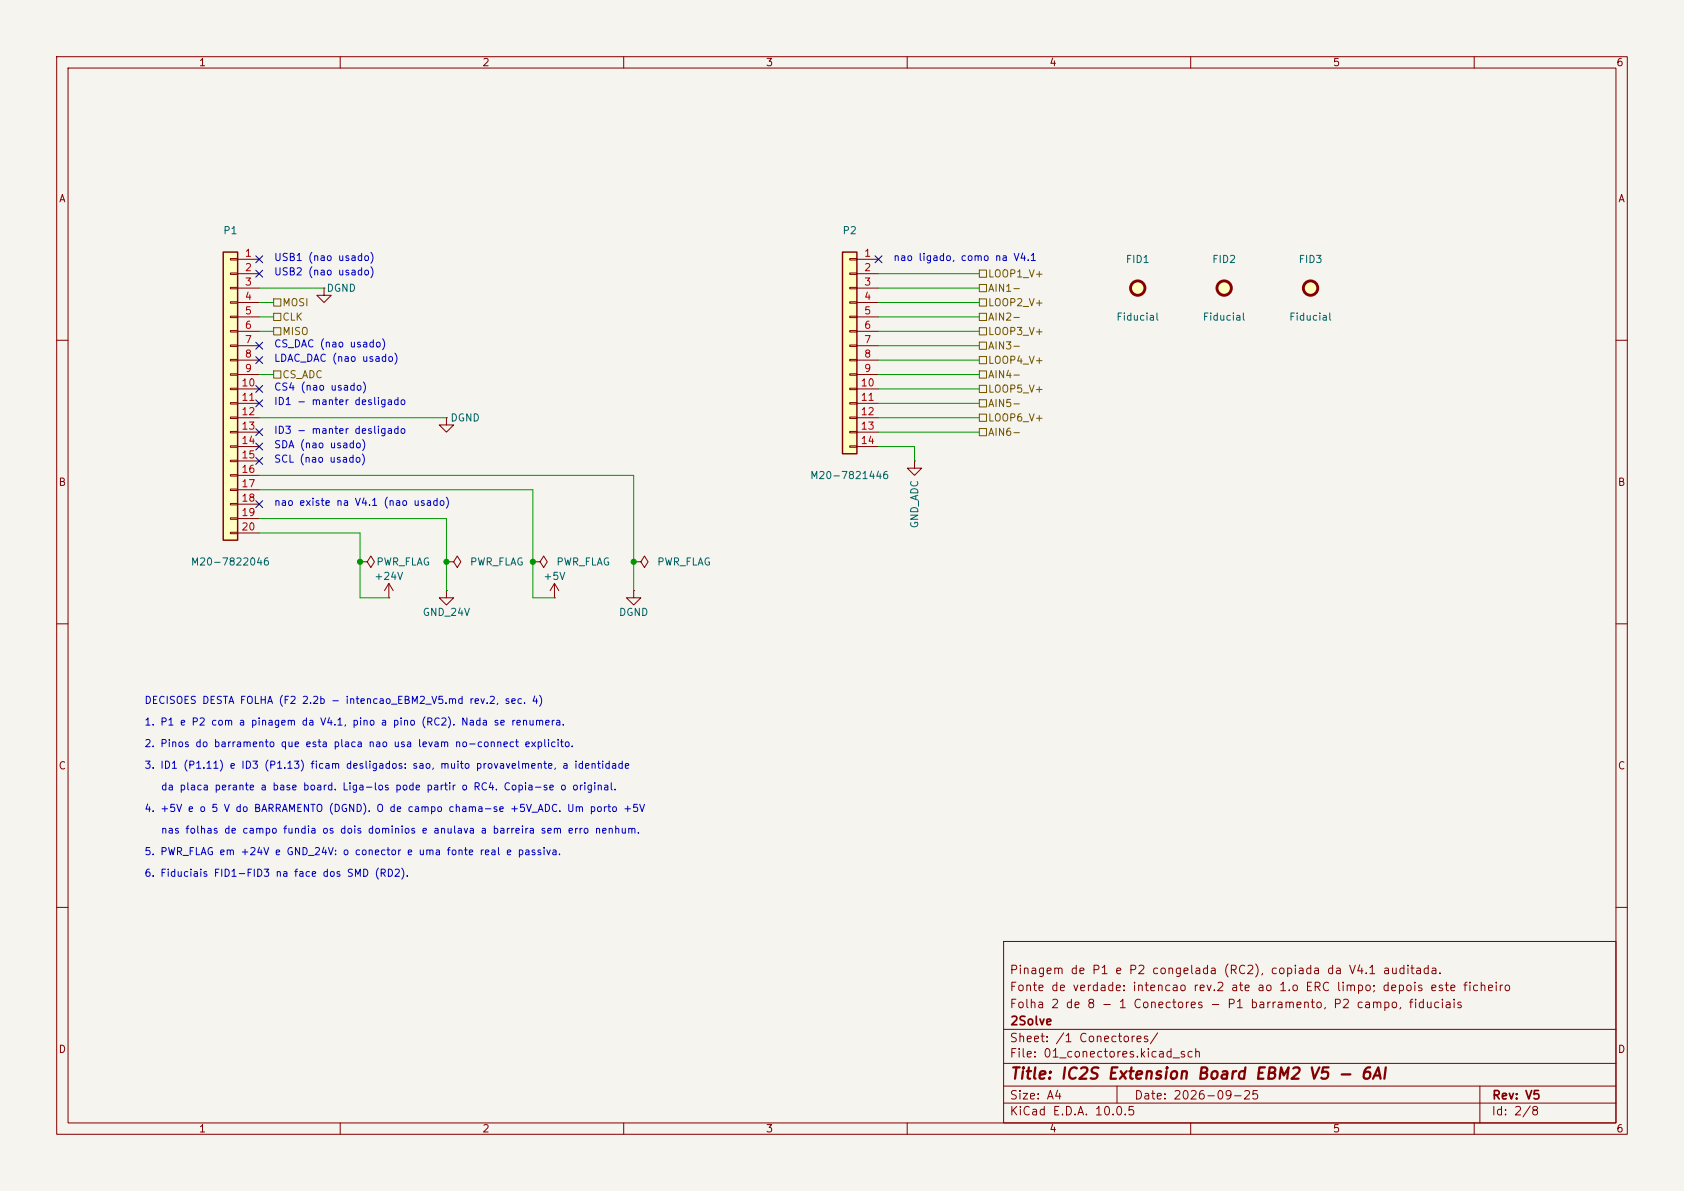
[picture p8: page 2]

ID3 - manter desligado 3. ID1 (P1.11) e ID3 (P1.13) ficam desligados: sao, muito provavelmente, a identidade DECISOES DESTA FOLHA (F2 2.2b - intencao_EBM2_V5.md rev.2, sec. 4) 1. P1 e P2 com a pinagem da V4.1, pino a pino (RC2). Nada se renumera. 2. Pinos do barramento que esta placa nao usa levam no-connect explicito. 6. Fiduciais FID1-FID3 na face dos SMD (RD2). 4. +5V e o 5 V do BARRAMENTO (DGND). O de campo chama-se +5V_ADC. Um porto +5V

5. PWR_FLAG em +24V e GND_24V: o conector e uma fonte real e passiva. da placa perante a base board. Liga-los pode partir o RC4. Copia-se o original. nas folhas de campo fundia os dois dominios e anulava a barreira sem erro nenhum.

Pinagem de P1 e P2 congelada (RC2), copiada da V4.1 auditada.
Fonte de verdade: intencao rev.2 ate ao 1.o ERC limpo; depois este ficheiro
Folha 2 de 8 - 1 Conectores - P1 barramento, P2 campo, fiduciais
2Solve
Sheet: /1 Conectores/
File: 01_conectores.kicad_sch
Title: IC2S Extension Board EBM2 V5 - 6AI

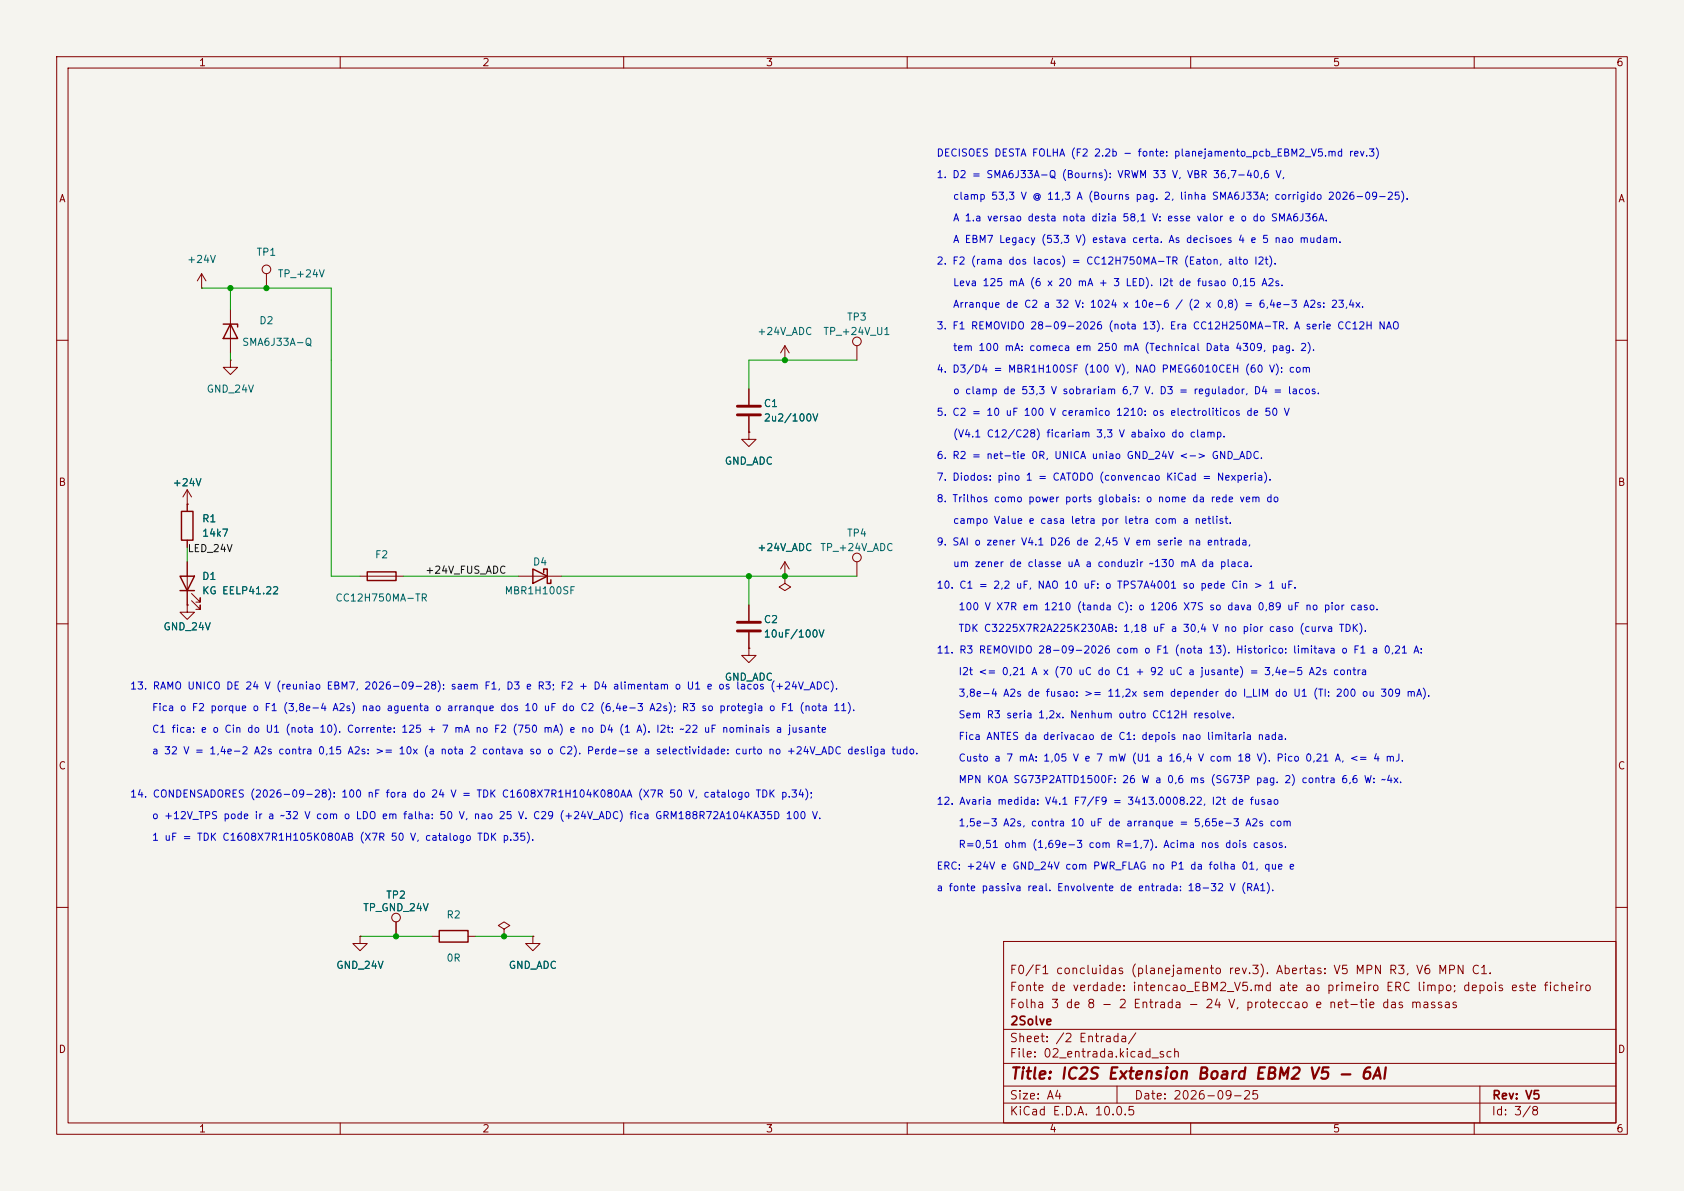
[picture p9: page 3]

DECISOES DESTA FOLHA (F2 2.2b - fonte: planejamento_pcb_EBM2_V5.md rev.3) 3. F1 REMOVIDO 28-09-2026 (nota 13). Era CC12H250MA-TR. A serie CC12H NAO

clamp 53,3 V @ 11,3 A (Bourns pag. 2, linha SMA6J33A; corrigido 2026-09-25). a 32 V = 1,4e-2 A2s contra 0,15 A2s: >= 10x (a nota 2 contava so o C2). Perde-se a selectividade: curto no +24V_ADC desliga tudo. 14. CONDENSADORES (2026-09-28): 100 nF fora do 24 V = TDK C1608X7R1H104K080AA (X7R 50 V, catalogo TDK p.34); o +12V_TPS pode ir a ~32 V com o LDO em falha: 50 V, nao 25 V. C29 (+24V_ADC) fica GRM188R72A104KA35D 100 V. 1 uF = TDK C1608X7R1H105K080AB (X7R 50 V, catalogo TDK p.35).

A 1.a versao desta nota dizia 58,1 V: esse valor e o do SMA6J36A. 2. F2 (rama dos lacos) = CC12H750MA-TR (Eaton, alto I2t). C1 fica: e o Cin do U1 (nota 10). Corrente: 125 + 7 mA no F2 (750 mA) e no D4 (1 A). I2t: ~22 uF nominais a jusante

A EBM7 Legacy (53,3 V) estava certa. As decisoes 4 e 5 nao mudam. Arranque de C2 a 32 V: 1024 x 10e-6 / (2 x 0,8) = 6,4e-3 A2s: 23,4x. tem 100 mA: comeca em 250 mA (Technical Data 4309, pag. 2). 4. D3/D4 = MBR1H100SF (100 V), NAO PMEG6010CEH (60 V): com

o clamp de 53,3 V sobrariam 6,7 V. D3 = regulador, D4 = lacos. 13. RAMO UNICO DE 24 V (reuniao EBM7, 2026-09-28): saem F1, D3 e R3; F2 + D4 alimentam o U1 e os lacos (+24V_ADC). Fica o F2 porque o F1 (3,8e-4 A2s) nao aguenta o arranque dos 10 uF do C2 (6,4e-3 A2s); R3 so protegia o F1 (nota 11).
14k7 GND_24V +24V

Fica ANTES da derivacao de C1: depois nao limitaria nada. TDK C3225X7R2A225K230AB: 1,18 uF a 30,4 V no pior caso (curva TDK). 100 V X7R em 1210 (tanda C): o 1206 X7S so dava 0,89 uF no pior caso. 10. C1 = 2,2 uF, NAO 10 uF: o TPS7A4001 so pede Cin > 1 uF. 9. SAI o zener V4.1 D26 de 2,45 V em serie na entrada, 5. C2 = 10 uF 100 V ceramico 1210: os electroliticos de 50 V 8. Trilhos como power ports globais: o nome da rede vem do 7. Diodos: pino 1 = CATODO (convencao KiCad = Nexperia).
(V4.1 C12/C28) ficariam 3,3 V abaixo do clamp. 6. R2 = net-tie 0R, UNICA uniao GND_24V <-> GND_ADC. campo Value e casa letra por letra com a netlist. um zener de classe uA a conduzir ~130 mA da placa.

I2t <= 0,21 A x (70 uC do C1 + 92 uC a jusante) = 3,4e-5 A2s contra 1,5e-3 A2s, contra 10 uF de arranque = 5,65e-3 A2s com

Sem R3 seria 1,2x. Nenhum outro CC12H resolve. a fonte passiva real. Envolvente de entrada: 18-32 V (RA1). 12. Avaria medida: V4.1 F7/F9 = 3413.0008.22, I2t de fusao

R=0,51 ohm (1,69e-3 com R=1,7). Acima nos dois casos.

ERC: +24V e GND_24V com PWR_FLAG no P1 da folha 01, que e

F0/F1 concluidas (planejamento rev.3). Abertas: V5 MPN R3, V6 MPN C1.
Folha 3 de 8 - 2 Entrada - 24 V, proteccao e net-tie das massas Fonte de verdade: intencao_EBM2_V5.md ate ao primeiro ERC limpo; depois este ficheiro

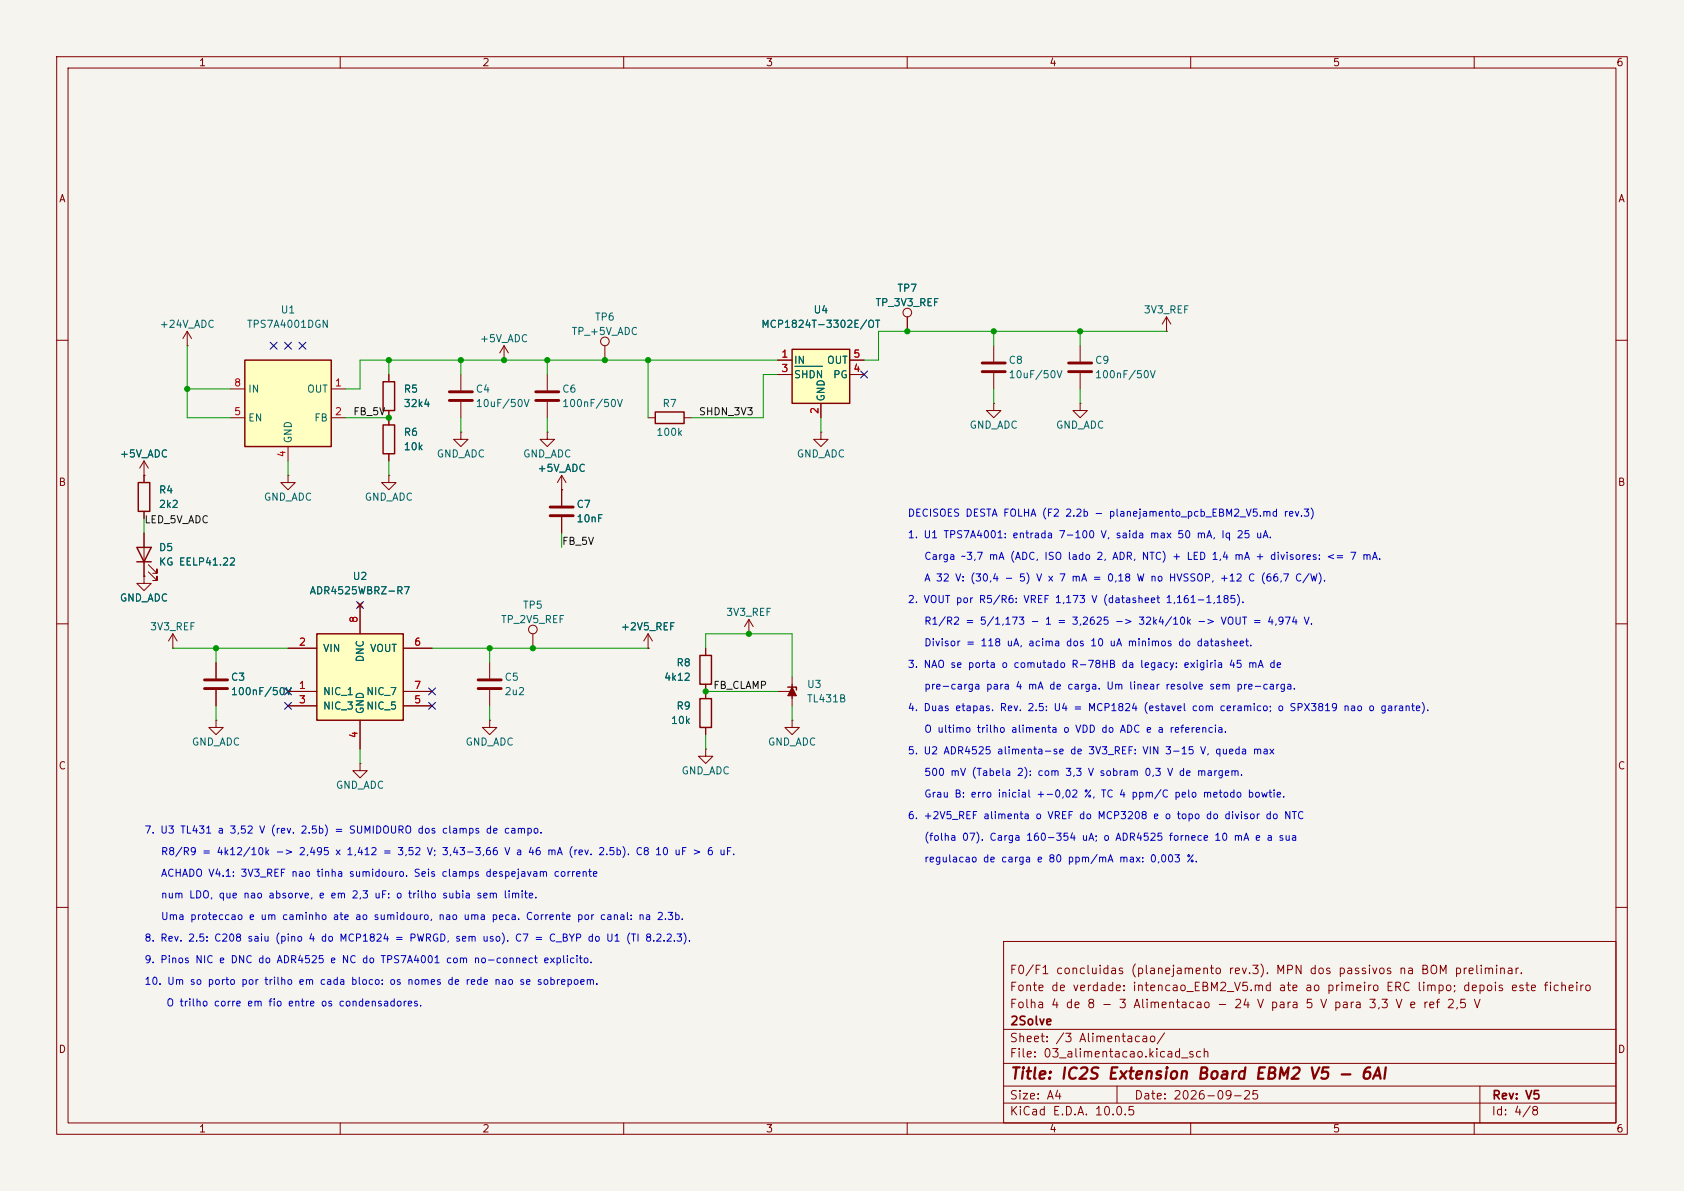
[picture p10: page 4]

regulacao de carga e 80 ppm/mA max: 0,003 %. 6. +2V5_REF alimenta o VREF do MCP3208 e o topo do divisor do NTC
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

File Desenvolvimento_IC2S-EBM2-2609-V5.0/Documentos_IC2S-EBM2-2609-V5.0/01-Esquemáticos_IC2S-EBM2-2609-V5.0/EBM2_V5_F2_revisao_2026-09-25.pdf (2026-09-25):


1 Conectores Arquivo: 01_conectores.kicad_sch
6 Lacos Arquivo: 06_lacos.kicad_sch MOSI CLK

F0/F1 concluidas (planejamento rev.3). Diagrama de blocos: Documentos, folha 1 do PDF. NTC_ADC

Fonte de verdade: intencao_EBM2_V5.md ate ao primeiro ERC limpo; depois este ficheiro
Folha 1 de 8 - Raiz - sem componentes
2Solve
Sheet: /
File: IC2S_Extension_Board-EBM2_V5.kicad_sch
Title: IC2S Extension Board EBM2 V5 - 6AI

Size: A4 | Rev: V5
KiCad E.D.A. 10.0.5 | Id: 1/8


ID3 - manter desligado 3. ID1 (P1.11) e ID3 (P1.13) ficam desligados: sao, muito provavelmente, a identidade DECISOES DESTA FOLHA (F2 2.2b - intencao_EBM2_V5.md rev.2, sec. 4) 1. P1 e P2 com a pinagem da V4.1, pino a pino (RC2). Nada se renumera. 2. Pinos do barramento que esta placa nao usa levam no-connect explicito. 6. Fiduciais FID1-FID3 na face dos SMD (RD2). 4. +5V e o 5 V do BARRAMENTO (DGND). O de campo chama-se +5V_ADC. Um porto +5V

5. PWR_FLAG em +24V e GND_24V: o conector e uma fonte real e passiva. da placa perante a base board. Liga-los pode partir o RC4. Copia-se o original. nas folhas de campo fundia os dois dominios e anulava a barreira sem erro nenhum.

Pinagem de P1 e P2 congelada (RC2), copiada da V4.1 auditada.
Fonte de verdade: intencao rev.2 ate ao 1.o ERC limpo; depois este ficheiro
Folha 2 de 8 - 1 Conectores - P1 barramento, P2 campo, fiduciais
2Solve
Sheet: /1 Conectores/
File: 01_conectores.kicad_sch
Title: IC2S Extension Board EBM2 V5 - 6AI

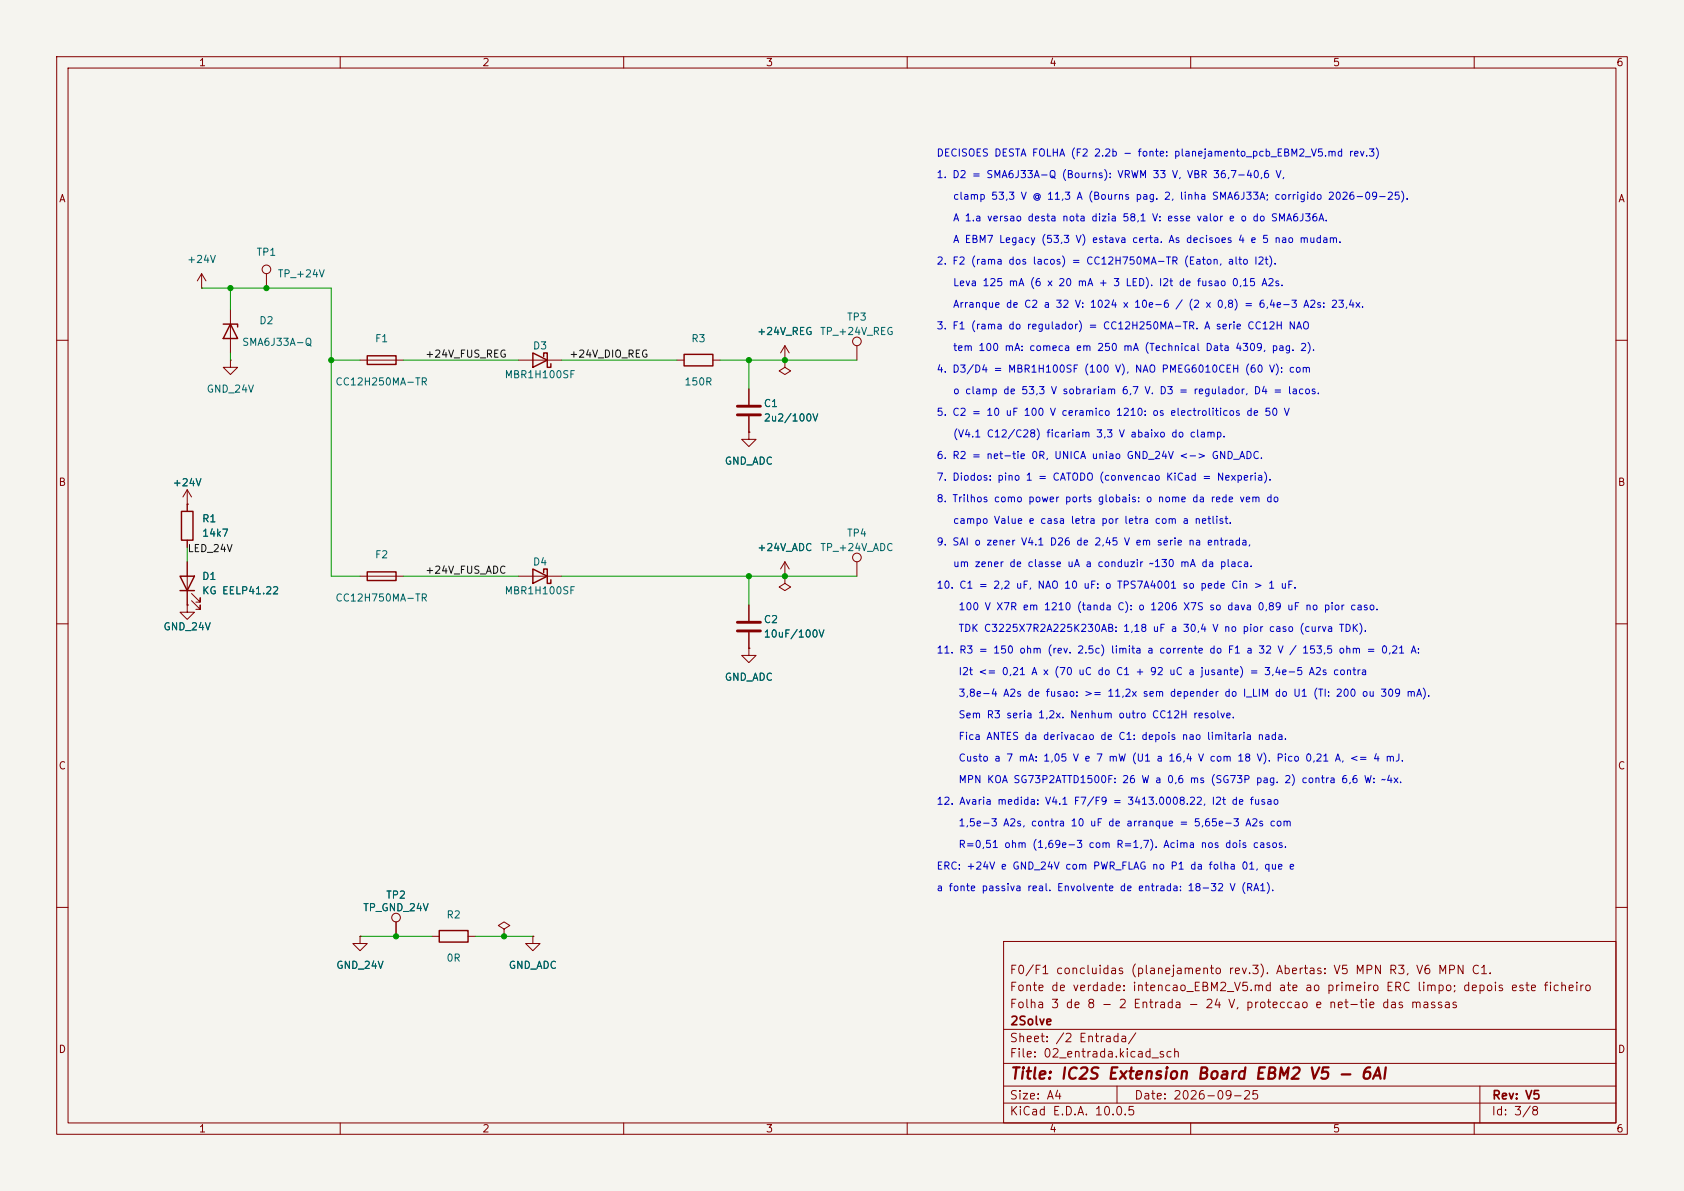
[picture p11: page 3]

DECISOES DESTA FOLHA (F2 2.2b - fonte: planejamento_pcb_EBM2_V5.md rev.3)

A 1.a versao desta nota dizia 58,1 V: esse valor e o do SMA6J36A. 2. F2 (rama dos lacos) = CC12H750MA-TR (Eaton, alto I2t). 1. D2 = SMA6J33A-Q (Bourns): VRWM 33 V, VBR 36,7-40,6 V, Leva 125 mA (6 x 20 mA + 3 LED). I2t de fusao 0,15 A2s. MPN KOA SG73P2ATTD1500F: 26 W a 0,6 ms (SG73P pag. 2) contra 6,6 W: ~4x. Custo a 7 mA: 1,05 V e 7 mW (U1 a 16,4 V com 18 V). Pico 0,21 A, <= 4 mJ. TDK C3225X7R2A225K230AB: 1,18 uF a 30,4 V no pior caso (curva TDK). Fica ANTES da derivacao de C1: depois nao limitaria nada. 6. R2 = net-tie 0R, UNICA uniao GND_24V <-> GND_ADC. (V4.1 C12/C28) ficariam 3,3 V abaixo do clamp. 3. F1 (rama do regulador) = CC12H250MA-TR. A serie CC12H NAO

clamp 53,3 V @ 11,3 A (Bourns pag. 2, linha SMA6J33A; corrigido 2026-09-25). 7. Diodos: pino 1 = CATODO (convencao KiCad = Nexperia). 8. Trilhos como power ports globais: o nome da rede vem do 9. SAI o zener V4.1 D26 de 2,45 V em serie na entrada, Sem R3 seria 1,2x. Nenhum outro CC12H resolve. o clamp de 53,3 V sobrariam 6,7 V. D3 = regulador, D4 = lacos. 4. D3/D4 = MBR1H100SF (100 V), NAO PMEG6010CEH (60 V): com

Arranque de C2 a 32 V: 1024 x 10e-6 / (2 x 0,8) = 6,4e-3 A2s: 23,4x. A EBM7 Legacy (53,3 V) estava certa. As decisoes 4 e 5 nao mudam. ERC: +24V e GND_24V com PWR_FLAG no P1 da folha 01, que e R=0,51 ohm (1,69e-3 com R=1,7). Acima nos dois casos. 5. C2 = 10 uF 100 V ceramico 1210: os electroliticos de 50 V 10. C1 = 2,2 uF, NAO 10 uF: o TPS7A4001 so pede Cin > 1 uF. 100 V X7R em 1210 (tanda C): o 1206 X7S so dava 0,89 uF no pior caso. 12. Avaria medida: V4.1 F7/F9 = 3413.0008.22, I2t de fusao

tem 100 mA: comeca em 250 mA (Technical Data 4309, pag. 2).

I2t <= 0,21 A x (70 uC do C1 + 92 uC a jusante) = 3,4e-5 A2s contra 3,8e-4 A2s de fusao: >= 11,2x sem depender do I_LIM do U1 (TI: 200 ou 309 mA). 11. R3 = 150 ohm (rev. 2.5c) limita a corrente do F1 a 32 V / 153,5 ohm = 0,21 A: campo Value e casa letra por letra com a netlist. C2

a fonte passiva real. Envolvente de entrada: 18-32 V (RA1). um zener de classe uA a conduzir ~130 mA da placa.

1,5e-3 A2s, contra 10 uF de arranque = 5,65e-3 A2s com

F0/F1 concluidas (planejamento rev.3). Abertas: V5 MPN R3, V6 MPN C1.
Folha 3 de 8 - 2 Entrada - 24 V, proteccao e net-tie das massas Fonte de verdade: intencao_EBM2_V5.md ate ao primeiro ERC limpo; depois este ficheiro

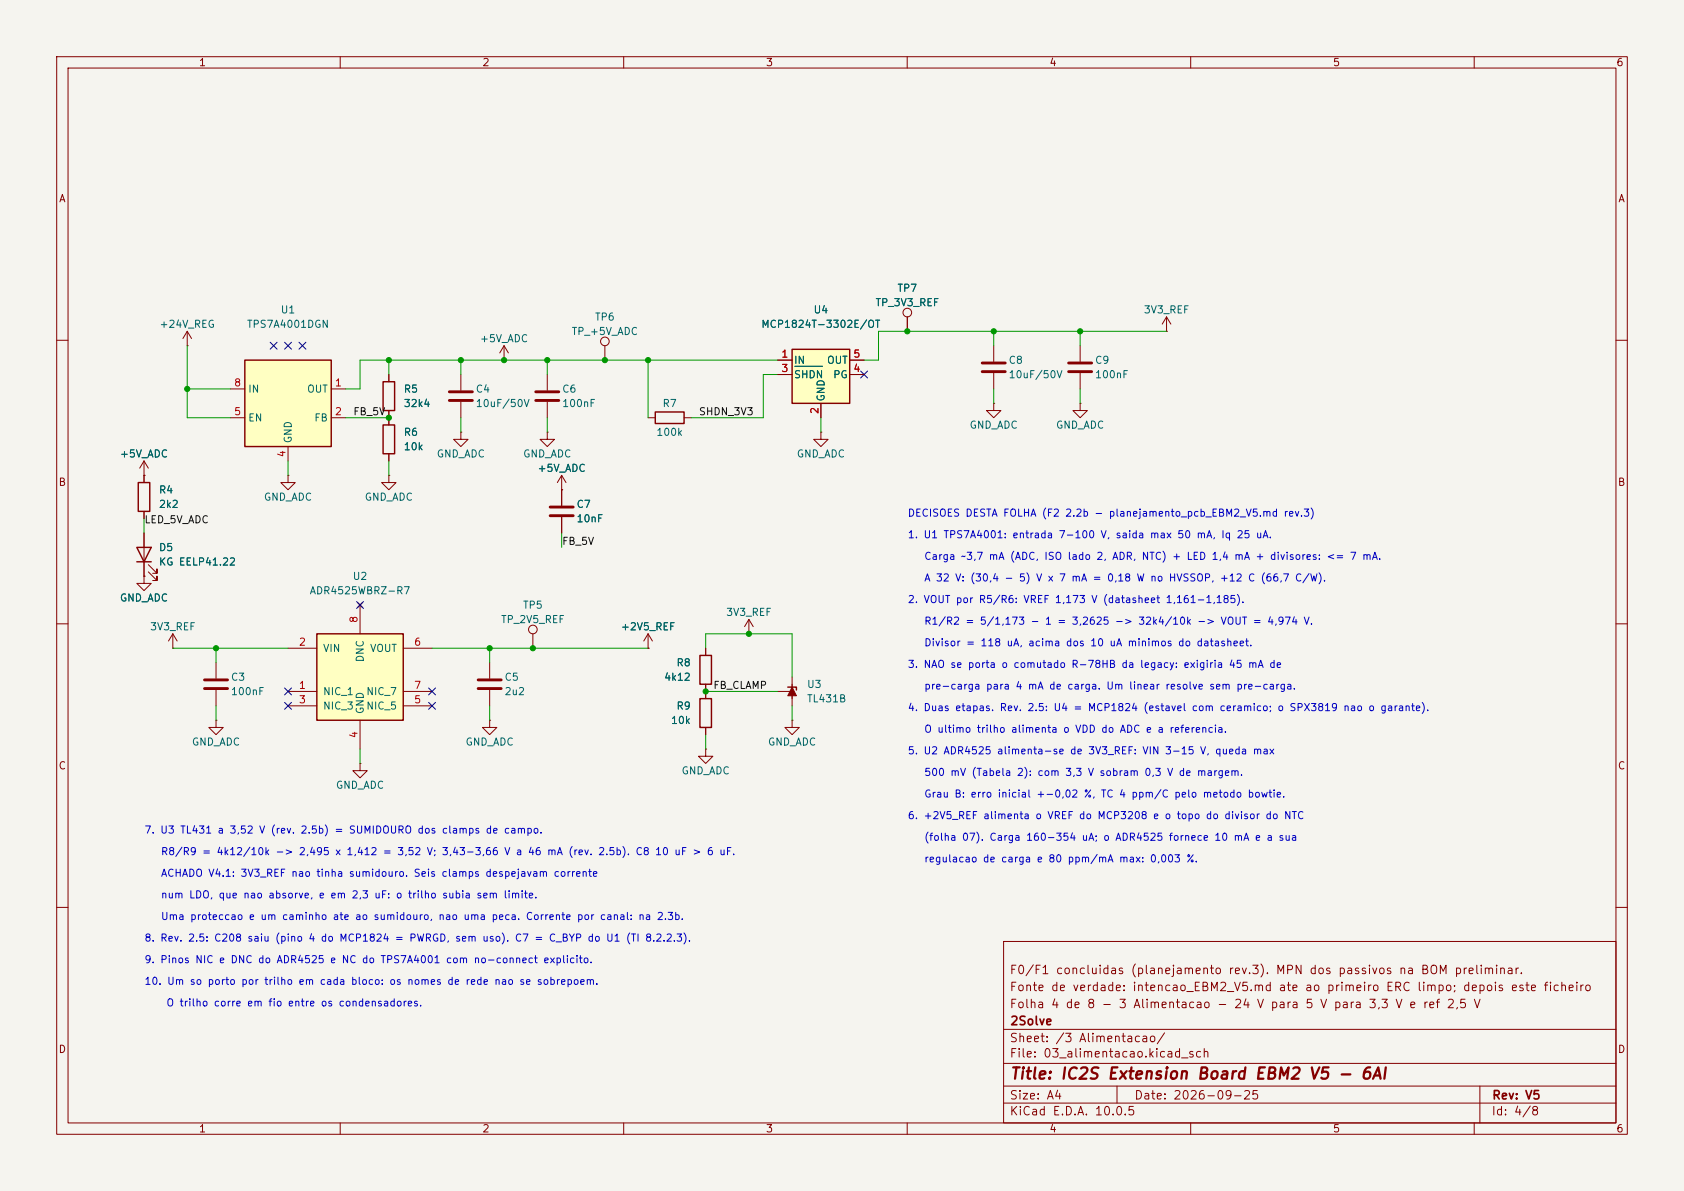
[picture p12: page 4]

Carga ~3,7 mA (ADC, ISO lado 2, ADR, NTC) + LED 1,4 mA + divisores: <= 7 mA. R8

F0/F1 concluidas (planejamento rev.3). MPN dos passivos na BOM preliminar.
Fonte de verdade: intencao_EBM2_V5.md ate ao primeiro ERC limpo; depois este ficheiro
Folha 4 de 8 - 3 Alimentacao - 24 V para 5 V para 3,3 V e ref 2,5 V
2Solve
Sheet: /3 Alimentacao/
File: 03_alimentacao.kicad_sch
Title: IC2S Extension Board EBM2 V5 - 6AI

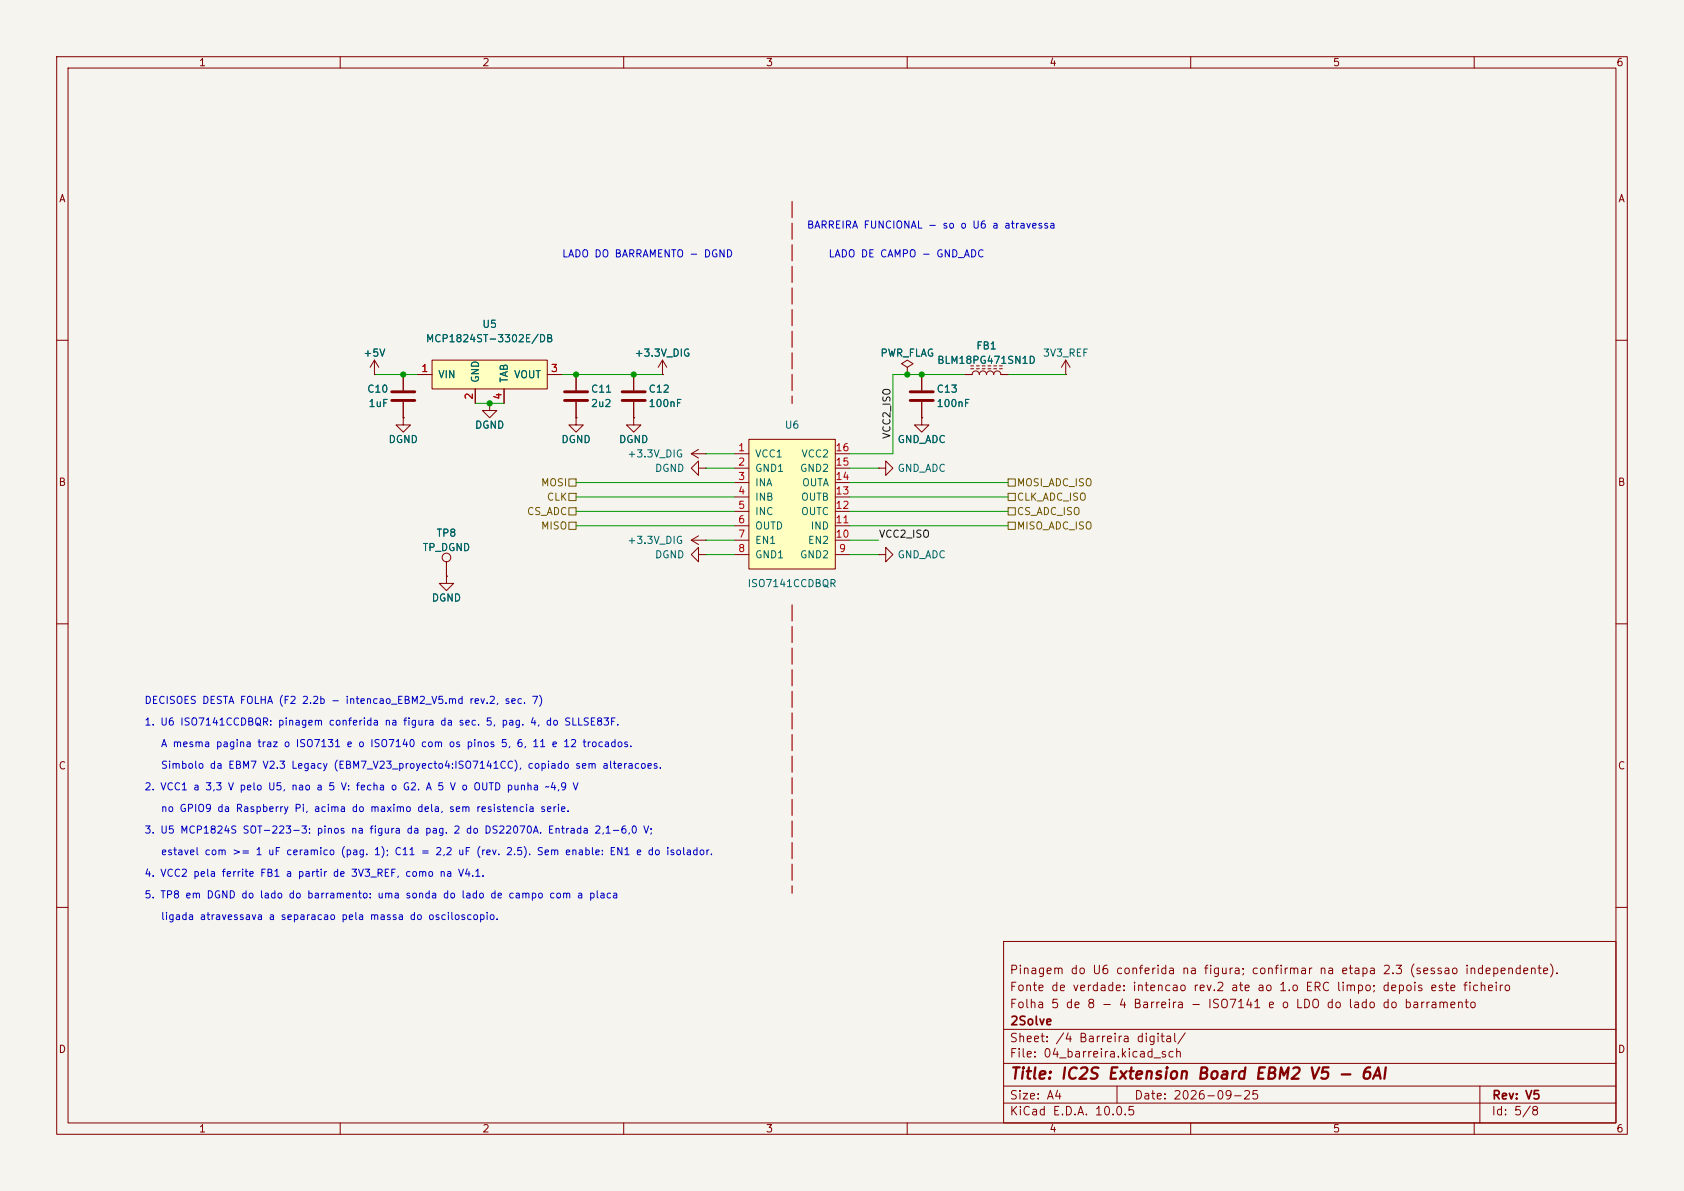
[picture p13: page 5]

BARREIRA FUNCIONAL - so o U6 a atravessa

LADO DO BARRAMENTO - DGND
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

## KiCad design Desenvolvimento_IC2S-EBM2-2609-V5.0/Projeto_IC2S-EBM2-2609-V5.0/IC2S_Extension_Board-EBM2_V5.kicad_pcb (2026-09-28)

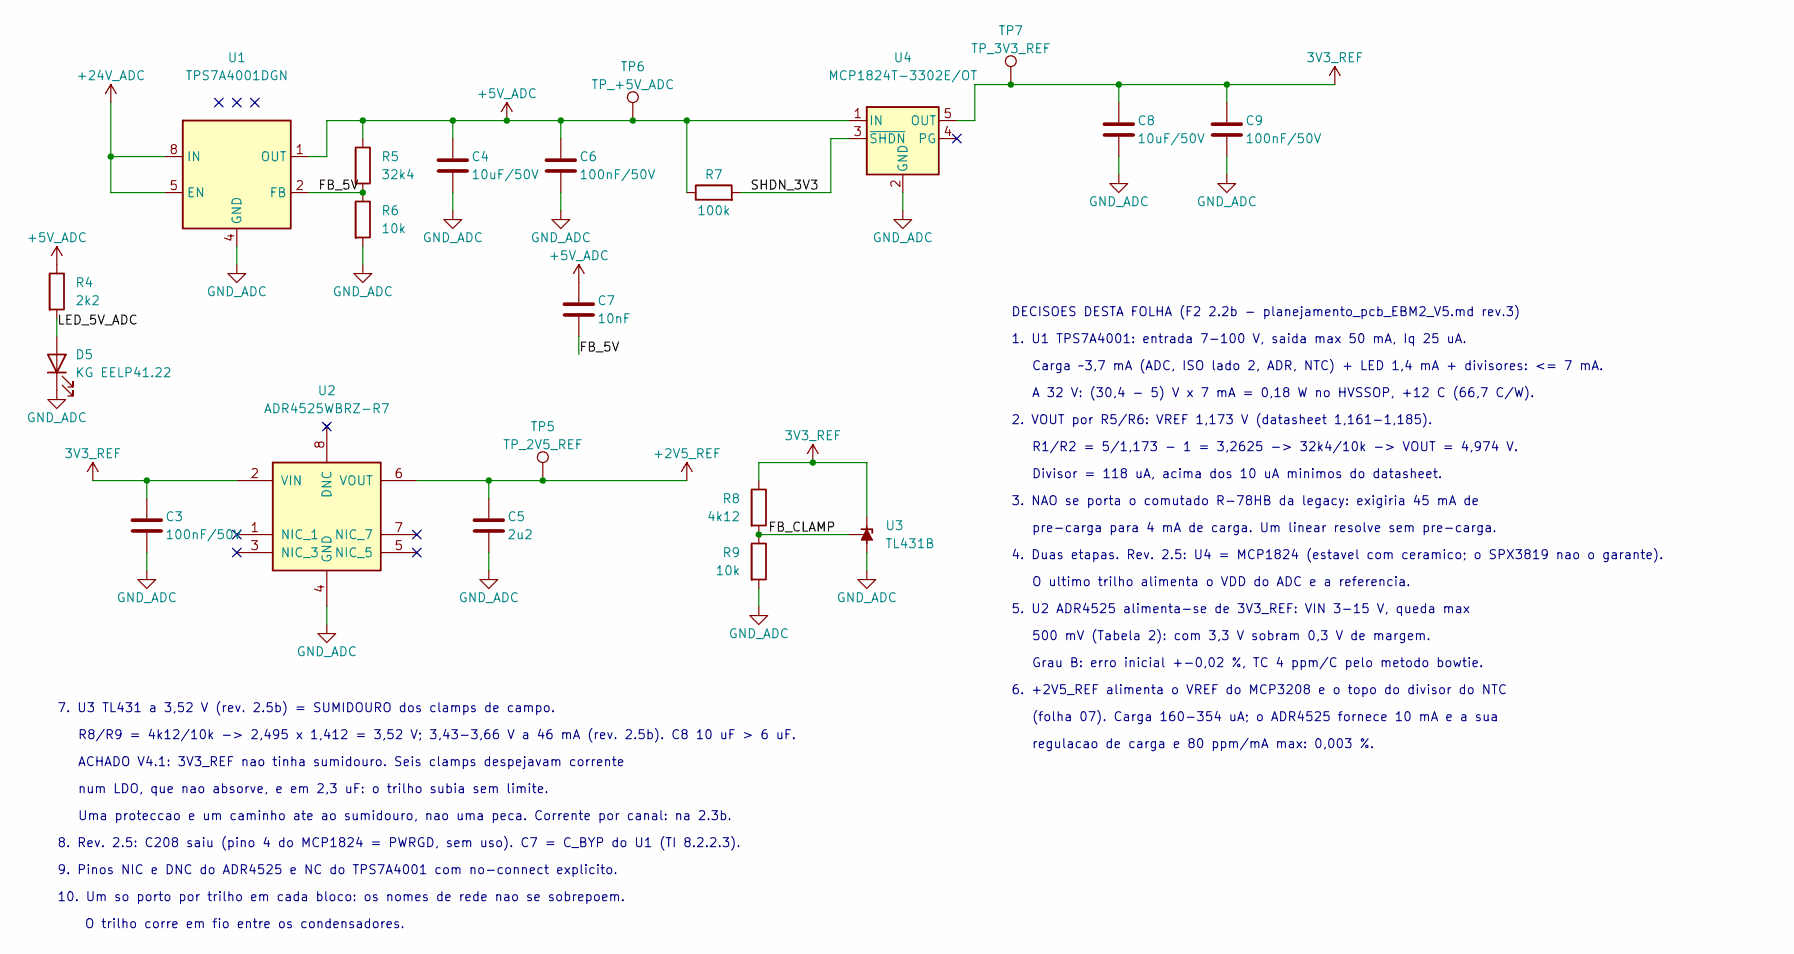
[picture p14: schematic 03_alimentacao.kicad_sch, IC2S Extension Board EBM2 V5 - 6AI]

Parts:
C3, C6, C9: 100nF/50V; 0603C; MPN C1608X7R1H104K080AA
C4, C8: 10uF/50V; C_1206_3216Metric; MPN C3216X5R1H106K160AB
C5: 2u2; 0603C; MPN C1608X5R1E225K080AB
C7: 10nF; 0603C; MPN GCM188R71H103KA37J
D5: KG EELP41.22; 0603LED; MPN KG EELP41.22-PHRH-35-A8J8-20-R18
R4: 2k2; 0603R; MPN RC0603FR-072K2L
R5: 32k4; 0603R; MPN RC0603FR-0732K4L
R6, R9: 10k; 0603R; MPN RC0603FR-0710KL
R7: 100k; 0603R; MPN RC0603FR-07100KL
R8: 4k12; 0603R; MPN RC0603FR-074K12L
TP5: TP_2V5_REF; TestPad_Via
TP6: TP_+5V_ADC; TestPad_Via
TP7: TP_3V3_REF; TestPad_Via
U1: TPS7A4001DGN; HVSSOP-8-1EP; MPN TPS7A4001DGNR
U2: ADR4525WBRZ-R7; SOIC8; MPN ADR4525WBRZ-R7
U3: TL431B; SOT23-3; MPN TL431BQDBZR
U4: MCP1824T-3302E/OT; SOT-23-5; MPN MCP1824T-3302E/OT

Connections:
3V3_REF: C3.1, C8.1, C9.1, R8.1, TP7.1, U2.2 (VIN), U3.1 (K), U4.5 (OUT); also elsewhere on the board
+2V5_REF: C5.1, TP5.1, U2.6 (VOUT); also elsewhere on the board
+5V_ADC: C4.1, C6.1, C7.1, R4.1, R5.1, R7.1, TP6.1, U1.1 (OUT), U4.1 (IN)
+24V_ADC: U1.5 (EN), U1.8 (IN); also elsewhere on the board
/3 Alimentacao/FB_5V: C7.2, R5.2, R6.1, U1.2 (FB)
/3 Alimentacao/FB_CLAMP: R8.2, R9.1, U3.2 (REF)
/3 Alimentacao/LED_5V_ADC: D5.2 (A), R4.2
/3 Alimentacao/SHDN_3V3: R7.2, U4.3 (~SHDN)
GND_ADC: C3.2, C4.2, C5.2, C6.2, C8.2, C9.2, D5.1 (K), R6.2, R9.2, U1.4 (GND), U1.9 (PAD), U2.4 (GND), U3.3 (A), U4.2 (GND); also elsewhere on the board

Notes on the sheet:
5. U2 ADR4525 alimenta-se de 3V3_REF: VIN 3-15 V, queda max
R1/R2 = 5/1,173 - 1 = 3,2625 -> 32k4/10k -> VOUT = 4,974 V.
1. U1 TPS7A4001: entrada 7-100 V, saida max 50 mA, Iq 25 uA.
Carga ~3,7 mA (ADC, ISO lado 2, ADR, NTC) + LED 1,4 mA + divisores: <= 7 mA.
Divisor = 118 uA, acima dos 10 uA minimos do datasheet.
10. Um so porto por trilho em cada bloco: os nomes de rede nao se sobrepoem.
7. U3 TL431 a 3,52 V (rev. 2.5b) = SUMIDOURO dos clamps de campo.
A 32 V: (30,4 - 5) V x 7 mA = 0,18 W no HVSSOP, +12 C (66,7 C/W).
regulacao de carga e 80 ppm/mA max: 0,003 %.
4. Duas etapas. Rev. 2.5: U4 = MCP1824 (estavel com ceramico; o SPX3819 nao o garante).
(folha 07). Carga 160-354 uA; o ADR4525 fornece 10 mA e a sua
pre-carga para 4 mA de carga. Um linear resolve sem pre-carga.
num LDO, que nao absorve, e em 2,3 uF: o trilho subia sem limite.
6. +2V5_REF alimenta o VREF do MCP3208 e o topo do divisor do NTC
Grau B: erro inicial +-0,02 %, TC 4 ppm/C pelo metodo bowtie.
O trilho corre em fio entre os condensadores.
Uma proteccao e um caminho ate ao sumidouro, nao uma peca. Corrente por canal: na 2.3b.
9. Pinos NIC e DNC do ADR4525 e NC do TPS7A4001 com no-connect explicito.
ACHADO V4.1: 3V3_REF nao tinha sumidouro. Seis clamps despejavam corrente
3. NAO se porta o comutado R-78HB da legacy: exigiria 45 mA de
R8/R9 = 4k12/10k -> 2,495 x 1,412 = 3,52 V; 3,43-3,66 V a 46 mA (rev. 2.5b). C8 10 uF > 6 uF.
500 mV (Tabela 2): com 3,3 V sobram 0,3 V de margem.
O ultimo trilho alimenta o VDD do ADC e a referencia.
2. VOUT por R5/R6: VREF 1,173 V (datasheet 1,161-1,185).
DECISOES DESTA FOLHA (F2 2.2b - planejamento_pcb_EBM2_V5.md rev.3)
8. Rev. 2.5: C208 saiu (pino 4 do MCP1824 = PWRGD, sem uso). C7 = C_BYP do U1 (TI 8.2.2.3).

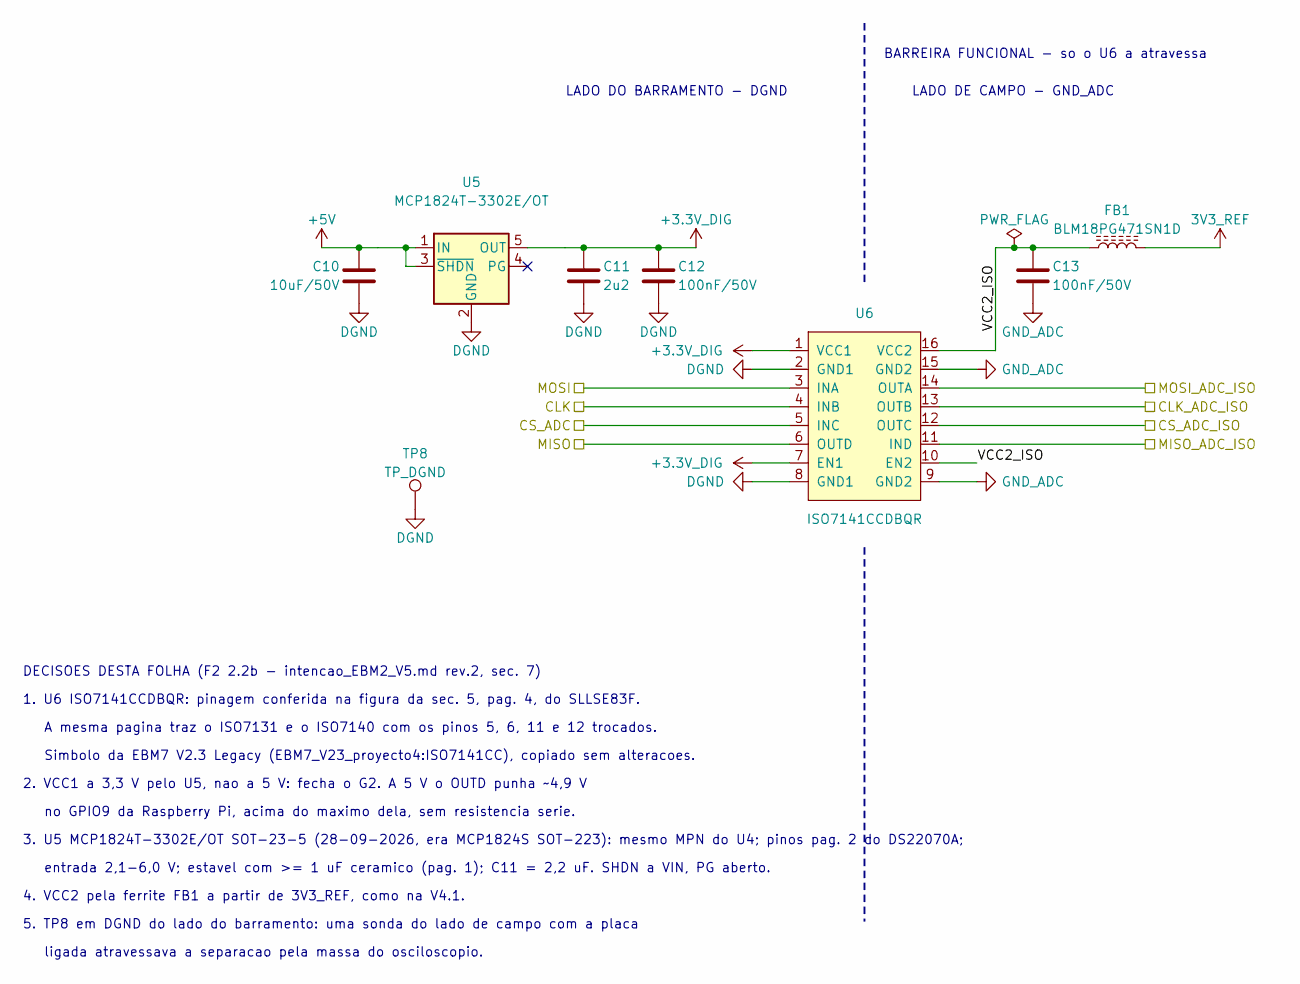
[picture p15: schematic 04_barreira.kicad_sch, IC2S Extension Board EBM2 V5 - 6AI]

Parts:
C10: 10uF/50V; C_1206_3216Metric; MPN C3216X5R1H106K160AB
C11: 2u2; 0603C; MPN C1608X5R1E225K080AB
C12, C13: 100nF/50V; 0603C; MPN C1608X7R1H104K080AA
FB1: BLM18PG471SN1D; 0603FB; MPN BLM18PG471SN1D
TP8: TP_DGND; TestPad_Via
U5: MCP1824T-3302E/OT; SOT-23-5; MPN MCP1824T-3302E/OT
U6: ISO7141CCDBQR; SSOP16-4.9x3.9mm; MPN ISO7141CCDBQR

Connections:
3V3_REF: FB1.2; also elsewhere on the board
+3.3V_DIG: C11.1, C12.1, U5.5 (OUT), U6.1 (VCC1), U6.7 (EN1)
+5V: C10.1, U5.1 (IN), U5.3 (~SHDN); also elsewhere on the board
/1 Conectores/CLK: U6.4 (INB); also elsewhere on the board
/1 Conectores/CS_ADC: U6.5 (INC); also elsewhere on the board
/1 Conectores/MISO: U6.6 (OUTD); also elsewhere on the board
/1 Conectores/MOSI: U6.3 (INA); also elsewhere on the board
/4 Barreira digital/CLK_ADC_ISO: U6.13 (OUTB); also elsewhere on the board
/4 Barreira digital/CS_ADC_ISO: U6.12 (OUTC); also elsewhere on the board
/4 Barreira digital/MISO_ADC_ISO: U6.11 (IND); also elsewhere on the board
/4 Barreira digital/MOSI_ADC_ISO: U6.14 (OUTA); also elsewhere on the board
/4 Barreira digital/VCC2_ISO: C13.1, FB1.1, U6.10 (EN2), U6.16 (VCC2)
DGND: C10.2, C11.2, C12.2, TP8.1, U5.2 (GND), U6.2 (GND1), U6.8 (GND1); also elsewhere on the board
GND_ADC: C13.2, U6.9 (GND2), U6.15 (GND2); also elsewhere on the board

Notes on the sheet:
BARREIRA FUNCIONAL - so o U6 a atravessa
LADO DO BARRAMENTO - DGND
LADO DE CAMPO - GND_ADC
DECISOES DESTA FOLHA (F2 2.2b - intencao_EBM2_V5.md rev.2, sec. 7)
1. U6 ISO7141CCDBQR: pinagem conferida na figura da sec. 5, pag. 4, do SLLSE83F.
A mesma pagina traz o ISO7131 e o ISO7140 com os pinos 5, 6, 11 e 12 trocados.
Simbolo da EBM7 V2.3 Legacy (EBM7_V23_proyecto4:ISO7141CC), copiado sem alteracoes.
2. VCC1 a 3,3 V pelo U5, nao a 5 V: fecha o G2. A 5 V o OUTD punha ~4,9 V
no GPIO9 da Raspberry Pi, acima do maximo dela, sem resistencia serie.
3. U5 MCP1824T-3302E/OT SOT-23-5 (28-09-2026, era MCP1824S SOT-223): mesmo MPN do U4; pinos pag. 2 do DS22070A;
entrada 2,1-6,0 V; estavel com >= 1 uF ceramico (pag. 1); C11 = 2,2 uF. SHDN a VIN, PG aberto.
4. VCC2 pela ferrite FB1 a partir de 3V3_REF, como na V4.1.
5. TP8 em DGND do lado do barramento: uma sonda do lado de campo com a placa
ligada atravessava a separacao pela massa do osciloscopio.

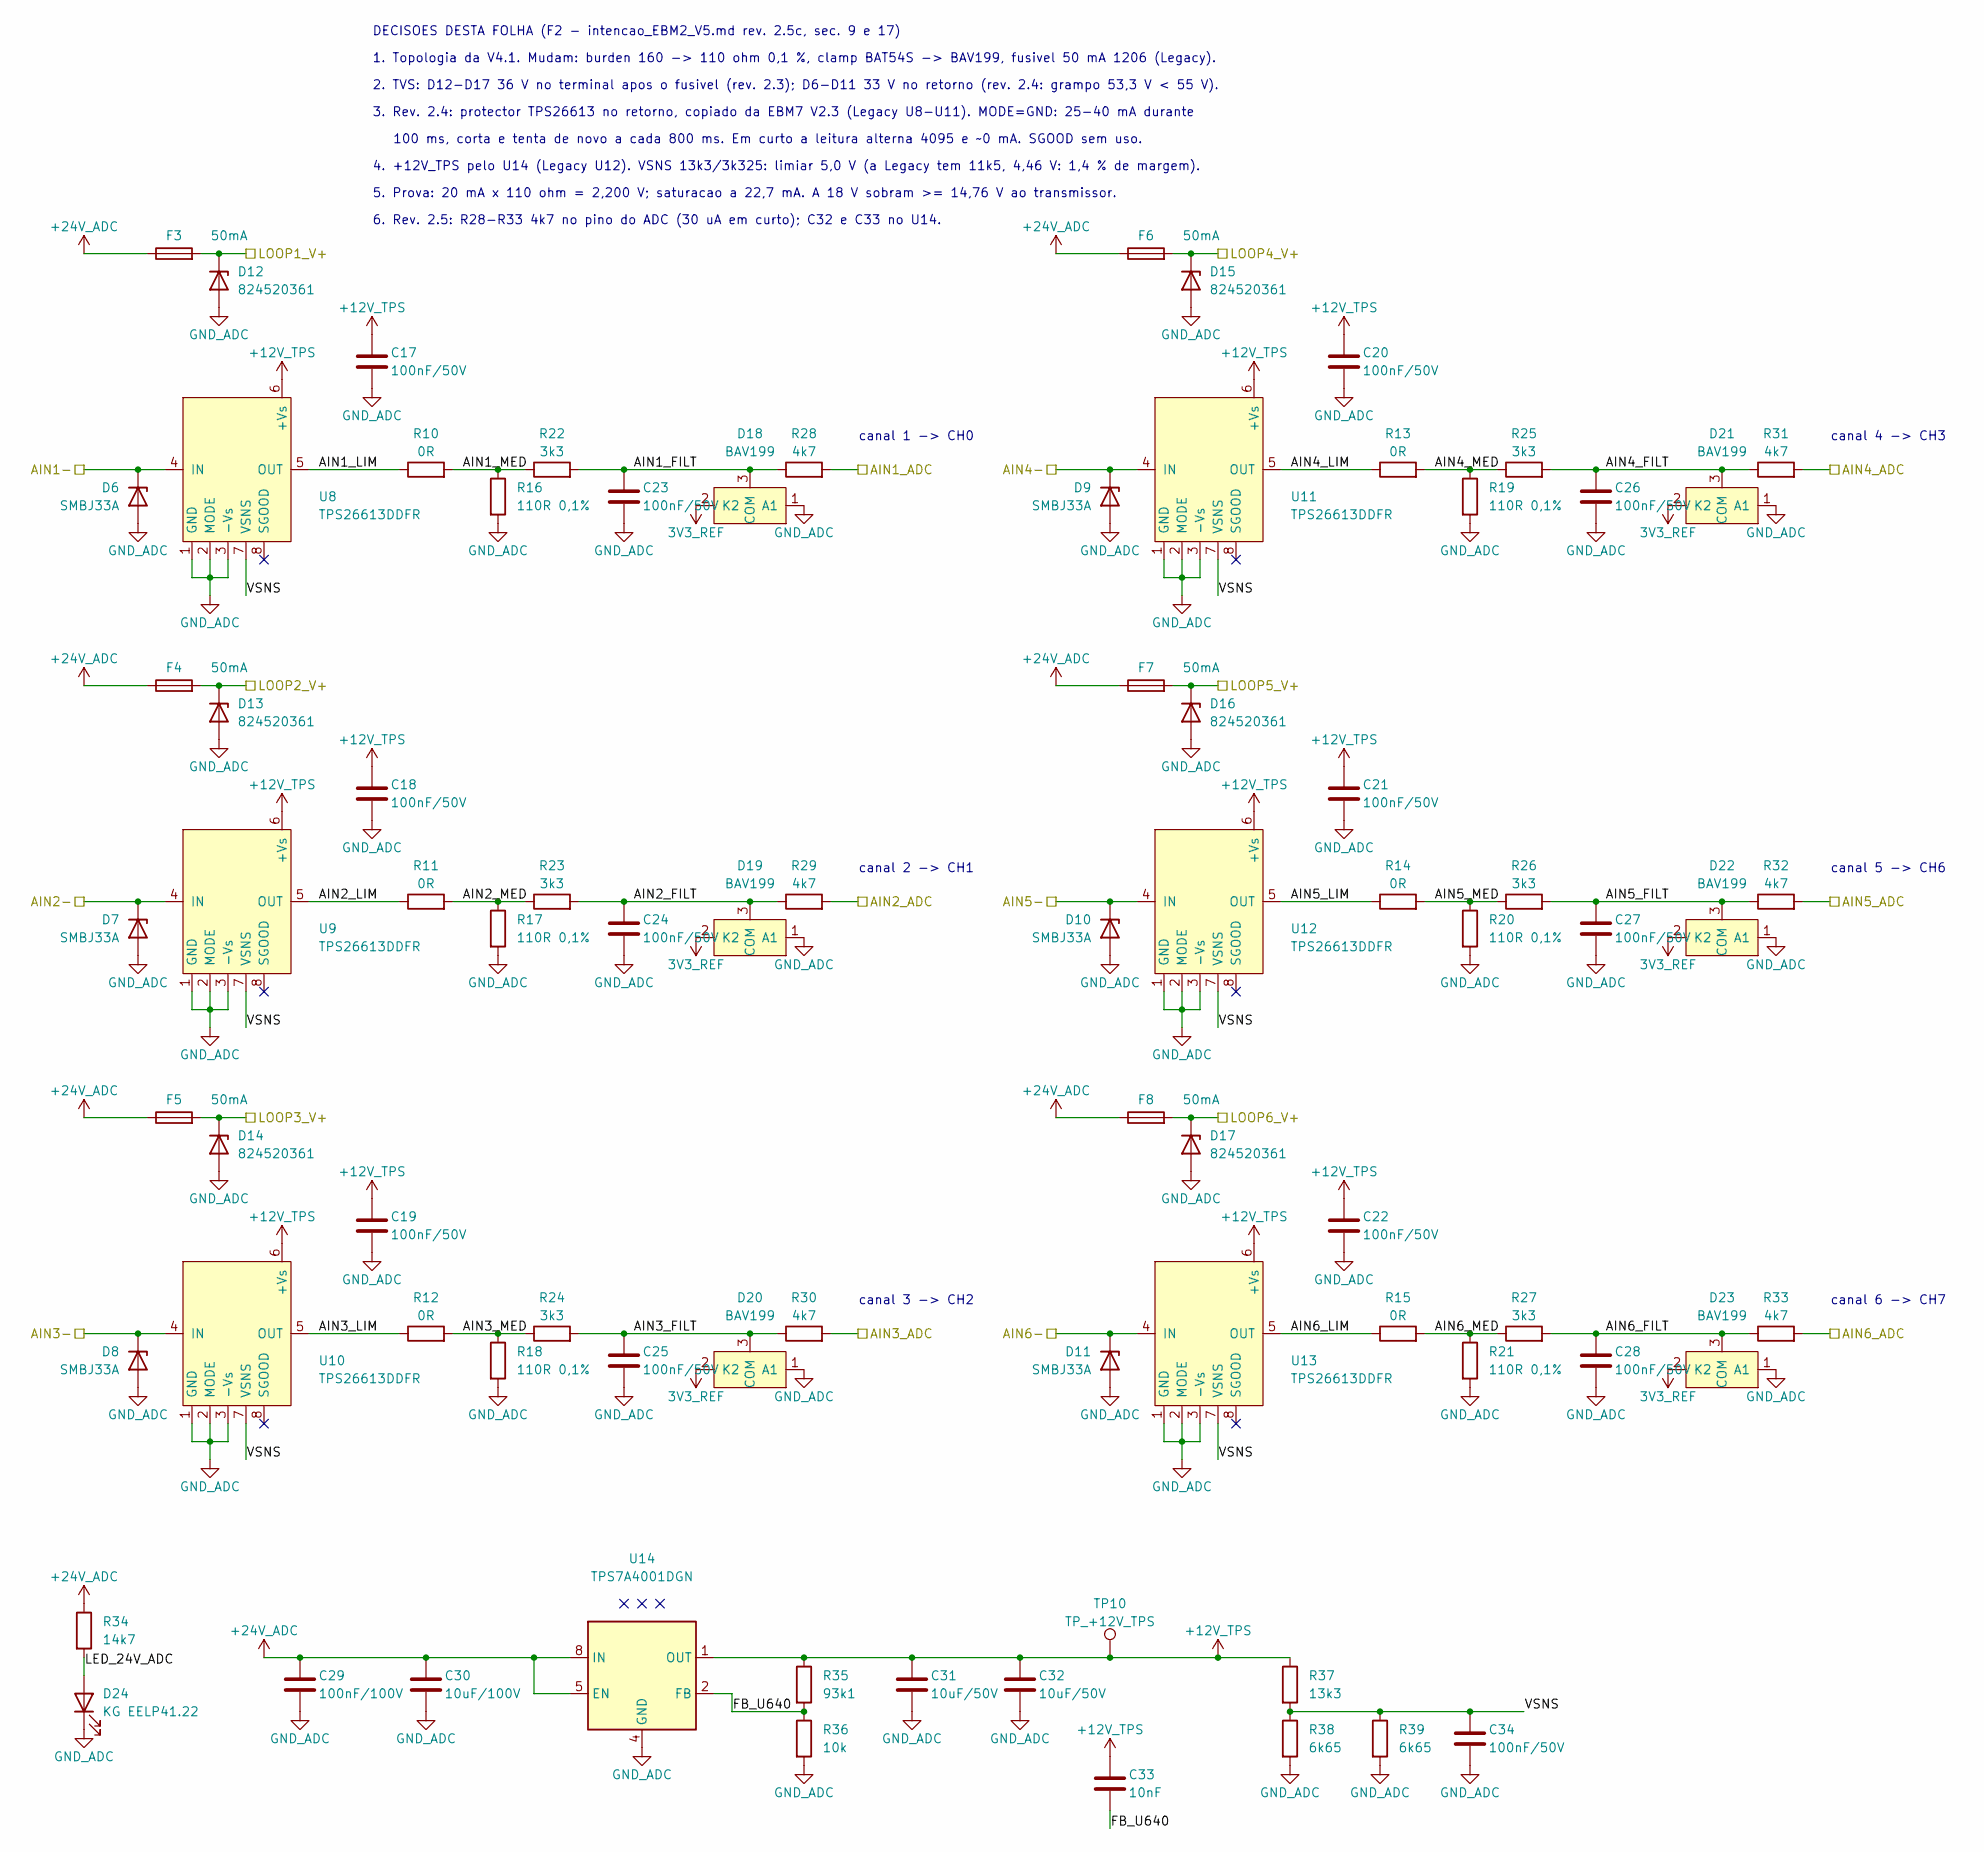
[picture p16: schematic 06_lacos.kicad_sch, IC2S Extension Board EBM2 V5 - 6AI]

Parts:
C17, C18, C19, C20, C21, C22, C23, C24, C25, C26, C27, C28, C34: 100nF/50V; 0603C; MPN C1608X7R1H104K080AA
C29: 100nF/100V; 0603C; MPN GRM188R72A104KA35D
C30: 10uF/100V; C_1210_3225Metric; MPN GRM32EC72A106ME05L
C31, C32: 10uF/50V; C_1206_3216Metric; MPN C3216X5R1H106K160AB
C33: 10nF; 0603C; MPN GCM188R71H103KA37J
D6, D7, D8, D9, D10, D11: SMBJ33A; DO-214AA; MPN SMBJ33A-13-F
D12, D13, D14, D15, D16, D17: 824520361; DO-214AA; MPN 824520361
D18, D19, D20, D21, D22, D23: BAV199; SOT23-3; MPN BAV199LT1G
D24: KG EELP41.22; 0603LED; MPN KG EELP41.22-PHRH-35-A8J8-20-R18
F3, F4, F5, F6, F7, F8: 50mA; 1206F; MPN 3413.0002.22
R10, R11, R12, R13, R14, R15: 0R; 0603R; MPN RC0603JR-070RL
R16, R17, R18, R19, R20, R21: 110R 0,1%; 1206R; MPN ERA8AEB111V
R22, R23, R24, R25, R26, R27: 3k3; 0603R; MPN RC0603FR-073K3L
R28, R29, R30, R31, R32, R33: 4k7; 0603R; MPN RC0603FR-074K7L
R34: 14k7; 0603R; MPN ERJ-3EKF1472V
R35: 93k1; 0603R; MPN RMCF0603FT93K1
R36: 10k; 0603R; MPN RC0603FR-0710KL
R37: 13k3; 0603R; MPN RC0603FR-0713K3L
R38, R39: 6k65; 0603R; MPN RC0603FR-076K65L
TP10: TP_+12V_TPS; TestPad_Via
U8, U9, U10, U11, U12, U13: TPS26613DDFR; SOT-23-8; MPN TPS26613DDFR
U14: TPS7A4001DGN; HVSSOP-8-1EP; MPN TPS7A4001DGNR

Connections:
3V3_REF: D18.2 (K2), D19.2 (K2), D20.2 (K2), D21.2 (K2), D22.2 (K2), D23.2 (K2); also elsewhere on the board
+12V_TPS: C17.1, C18.1, C19.1, C20.1, C21.1, C22.1, C31.1, C32.1, C33.1, R35.1, R37.1, TP10.1, U8.6 (+Vs), U9.6 (+Vs), U10.6 (+Vs), U11.6 (+Vs), U12.6 (+Vs), U13.6 (+Vs), U14.1 (OUT)
+24V_ADC: C29.1, C30.1, F3.1, F4.1, F5.1, F6.1, F7.1, F8.1, R34.1, U14.5 (EN), U14.8 (IN); also elsewhere on the board
/1 Conectores/AIN1-: D6.1 (K), U8.4 (IN); also elsewhere on the board
/1 Conectores/AIN2-: D7.1 (K), U9.4 (IN); also elsewhere on the board
/1 Conectores/AIN3-: D8.1 (K), U10.4 (IN); also elsewhere on the board
/1 Conectores/AIN4-: D9.1 (K), U11.4 (IN); also elsewhere on the board
/1 Conectores/AIN5-: D10.1 (K), U12.4 (IN); also elsewhere on the board
/1 Conectores/AIN6-: D11.1 (K), U13.4 (IN); also elsewhere on the board
/1 Conectores/LOOP1_V+: D12.1 (K), F3.2; also elsewhere on the board
/1 Conectores/LOOP2_V+: D13.1 (K), F4.2; also elsewhere on the board
/1 Conectores/LOOP3_V+: D14.1 (K), F5.2; also elsewhere on the board
/1 Conectores/LOOP4_V+: D15.1 (K), F6.2; also elsewhere on the board
/1 Conectores/LOOP5_V+: D16.1 (K), F7.2; also elsewhere on the board
/1 Conectores/LOOP6_V+: D17.1 (K), F8.2; also elsewhere on the board
/5 ADC/AIN1_ADC: R28.2; also elsewhere on the board
/5 ADC/AIN2_ADC: R29.2; also elsewhere on the board
/5 ADC/AIN3_ADC: R30.2; also elsewhere on the board
/5 ADC/AIN4_ADC: R31.2; also elsewhere on the board
/5 ADC/AIN5_ADC: R32.2; also elsewhere on the board
/5 ADC/AIN6_ADC: R33.2; also elsewhere on the board
/6 Lacos/AIN1_FILT: C23.1, D18.3 (COM), R22.2, R28.1
/6 Lacos/AIN1_LIM: R10.1, U8.5 (OUT)
/6 Lacos/AIN1_MED: R10.2, R16.1, R22.1
/6 Lacos/AIN2_FILT: C24.1, D19.3 (COM), R23.2, R29.1
/6 Lacos/AIN2_LIM: R11.1, U9.5 (OUT)
/6 Lacos/AIN2_MED: R11.2, R17.1, R23.1
/6 Lacos/AIN3_FILT: C25.1, D20.3 (COM), R24.2, R30.1
/6 Lacos/AIN3_LIM: R12.1, U10.5 (OUT)
/6 Lacos/AIN3_MED: R12.2, R18.1, R24.1
/6 Lacos/AIN4_FILT: C26.1, D21.3 (COM), R25.2, R31.1
/6 Lacos/AIN4_LIM: R13.1, U11.5 (OUT)
/6 Lacos/AIN4_MED: R13.2, R19.1, R25.1
/6 Lacos/AIN5_FILT: C27.1, D22.3 (COM), R26.2, R32.1
/6 Lacos/AIN5_LIM: R14.1, U12.5 (OUT)
/6 Lacos/AIN5_MED: R14.2, R20.1, R26.1
/6 Lacos/AIN6_FILT: C28.1, D23.3 (COM), R27.2, R33.1
/6 Lacos/AIN6_LIM: R15.1, U13.5 (OUT)
/6 Lacos/AIN6_MED: R15.2, R21.1, R27.1
/6 Lacos/FB_U640: C33.2, R35.2, R36.1, U14.2 (FB)
/6 Lacos/LED_24V_ADC: D24.2 (A), R34.2
/6 Lacos/VSNS: C34.1, R37.2, R38.1, R39.1, U8.7 (VSNS), U9.7 (VSNS), U10.7 (VSNS), U11.7 (VSNS), U12.7 (VSNS), U13.7 (VSNS)
GND_ADC: C17.2, C18.2, C19.2, C20.2, C21.2, C22.2, C23.2, C24.2, C25.2, C26.2, C27.2, C28.2, C29.2, C30.2, C31.2, C32.2, C34.2, D6.2 (A), D7.2 (A), D8.2 (A), D9.2 (A), D10.2 (A), D11.2 (A), D12.2 (A), D13.2 (A), D14.2 (A), D15.2 (A), D16.2 (A), D17.2 (A), D18.1 (A1), D19.1 (A1), D20.1 (A1), D21.1 (A1), D22.1 (A1), D23.1 (A1), D24.1 (K), R16.2, R17.2, R18.2, R19.2, R20.2, R21.2, R36.2, R38.2, R39.2, U8.1 (GND), U8.2 (MODE), U8.3 (-Vs), U9.1 (GND), U9.2 (MODE), U9.3 (-Vs), U10.1 (GND), U10.2 (MODE), U10.3 (-Vs), U11.1 (GND), U11.2 (MODE), U11.3 (-Vs), U12.1 (GND), U12.2 (MODE), U12.3 (-Vs), U13.1 (GND), U13.2 (MODE), U13.3 (-Vs), U14.4 (GND), U14.9 (PAD); also elsewhere on the board

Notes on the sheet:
canal 1 -> CH0
canal 2 -> CH1
canal 3 -> CH2
canal 4 -> CH3
canal 5 -> CH6
canal 6 -> CH7
DECISOES DESTA FOLHA (F2 - intencao_EBM2_V5.md rev. 2.5c, sec. 9 e 17)
1. Topologia da V4.1. Mudam: burden 160 -> 110 ohm 0,1 %, clamp BAT54S -> BAV199, fusivel 50 mA 1206 (Legacy).
2. TVS: D12-D17 36 V no terminal apos o fusivel (rev. 2.3); D6-D11 33 V no retorno (rev. 2.4: grampo 53,3 V < 55 V).
3. Rev. 2.4: protector TPS26613 no retorno, copiado da EBM7 V2.3 (Legacy U8-U11). MODE=GND: 25-40 mA durante
100 ms, corta e tenta de novo a cada 800 ms. Em curto a leitura alterna 4095 e ~0 mA. SGOOD sem uso.
4. +12V_TPS pelo U14 (Legacy U12). VSNS 13k3/3k325: limiar 5,0 V (a Legacy tem 11k5, 4,46 V: 1,4 % de margem).
5. Prova: 20 mA x 110 ohm = 2,200 V; saturacao a 22,7 mA. A 18 V sobram >= 14,76 V ao transmissor.
6. Rev. 2.5: R28-R33 4k7 no pino do ADC (30 uA em curto); C32 e C33 no U14.

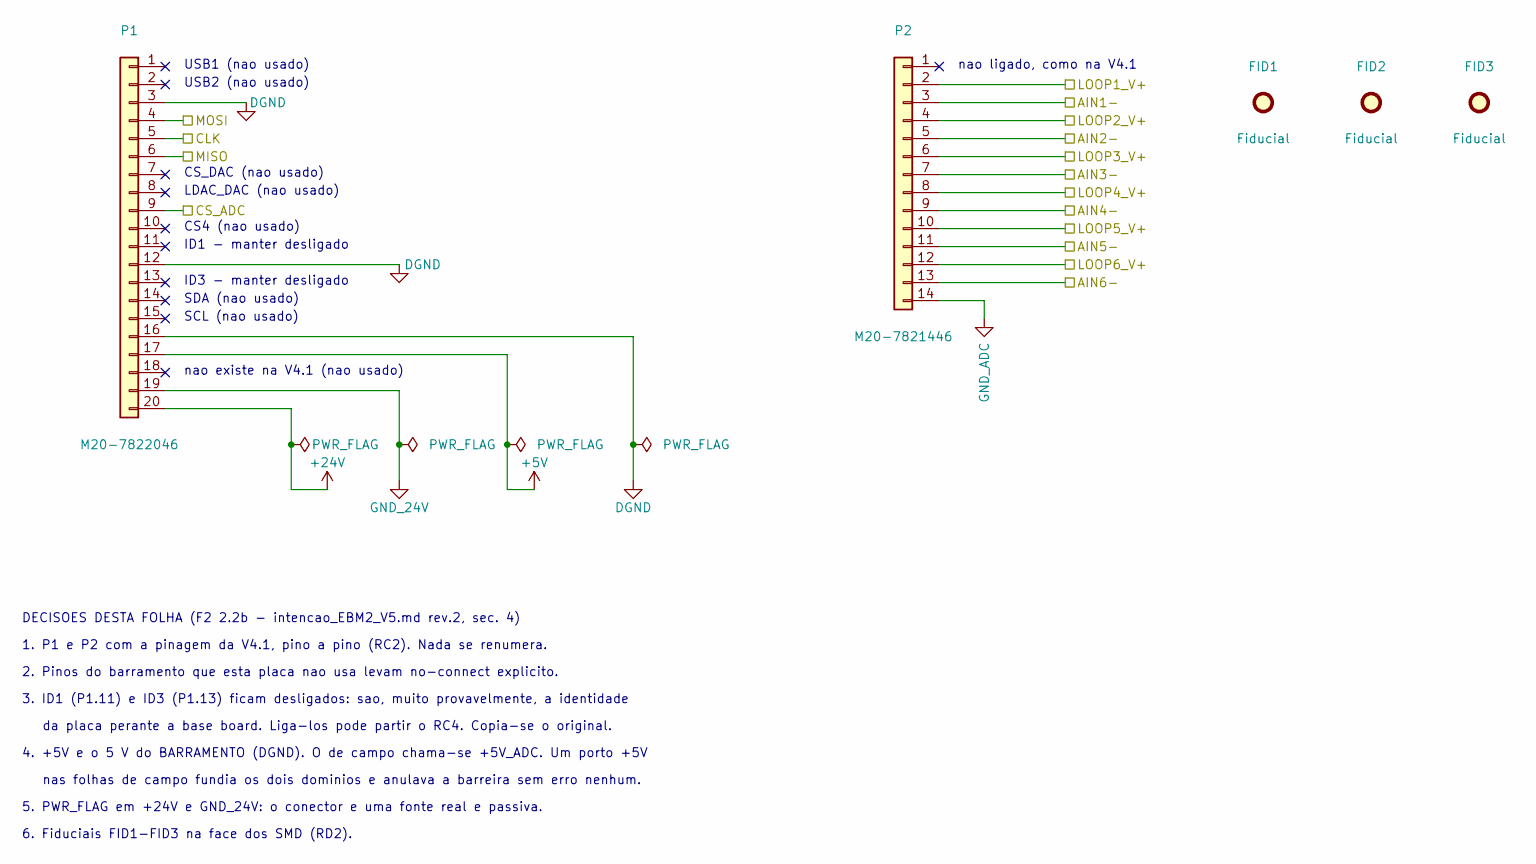
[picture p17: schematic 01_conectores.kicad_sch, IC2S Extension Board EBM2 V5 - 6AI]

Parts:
FID1, FID2, FID3: Fiducial; Fiducial_Point_Top-Bot
P1: M20-7822046; HDR1X20_FEMALE; MPN M20-7822046
P2: M20-7821446; HDR1X14_FEMALE; MPN M20-7821446

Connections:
+5V: P1.17; also elsewhere on the board
+24V: P1.20; also elsewhere on the board
/1 Conectores/AIN1-: P2.3; also elsewhere on the board
/1 Conectores/AIN2-: P2.5; also elsewhere on the board
/1 Conectores/AIN3-: P2.7; also elsewhere on the board
/1 Conectores/AIN4-: P2.9; also elsewhere on the board
/1 Conectores/AIN5-: P2.11; also elsewhere on the board
/1 Conectores/AIN6-: P2.13; also elsewhere on the board
/1 Conectores/CLK: P1.5; also elsewhere on the board
/1 Conectores/CS_ADC: P1.9; also elsewhere on the board
/1 Conectores/LOOP1_V+: P2.2; also elsewhere on the board
/1 Conectores/LOOP2_V+: P2.4; also elsewhere on the board
/1 Conectores/LOOP3_V+: P2.6; also elsewhere on the board
/1 Conectores/LOOP4_V+: P2.8; also elsewhere on the board
/1 Conectores/LOOP5_V+: P2.10; also elsewhere on the board
/1 Conectores/LOOP6_V+: P2.12; also elsewhere on the board
/1 Conectores/MISO: P1.6; also elsewhere on the board
/1 Conectores/MOSI: P1.4; also elsewhere on the board
DGND: P1.3, P1.12, P1.16; also elsewhere on the board
GND_24V: P1.19; also elsewhere on the board
GND_ADC: P2.14; also elsewhere on the board

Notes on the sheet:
nao ligado, como na V4.1
6. Fiduciais FID1-FID3 na face dos SMD (RD2).
USB2 (nao usado)
4. +5V e o 5 V do BARRAMENTO (DGND). O de campo chama-se +5V_ADC. Um porto +5V
SCL (nao usado)
CS_DAC (nao usado)
nao existe na V4.1 (nao usado)
5. PWR_FLAG em +24V e GND_24V: o conector e uma fonte real e passiva.
3. ID1 (P1.11) e ID3 (P1.13) ficam desligados: sao, muito provavelmente, a identidade
USB1 (nao usado)
LDAC_DAC (nao usado)
ID1 - manter desligado
da placa perante a base board. Liga-los pode partir o RC4. Copia-se o original.
ID3 - manter desligado
DECISOES DESTA FOLHA (F2 2.2b - intencao_EBM2_V5.md rev.2, sec. 4)
nas folhas de campo fundia os dois dominios e anulava a barreira sem erro nenhum.
1. P1 e P2 com a pinagem da V4.1, pino a pino (RC2). Nada se renumera.
CS4 (nao usado)
SDA (nao usado)
2. Pinos do barramento que esta placa nao usa levam no-connect explicito.

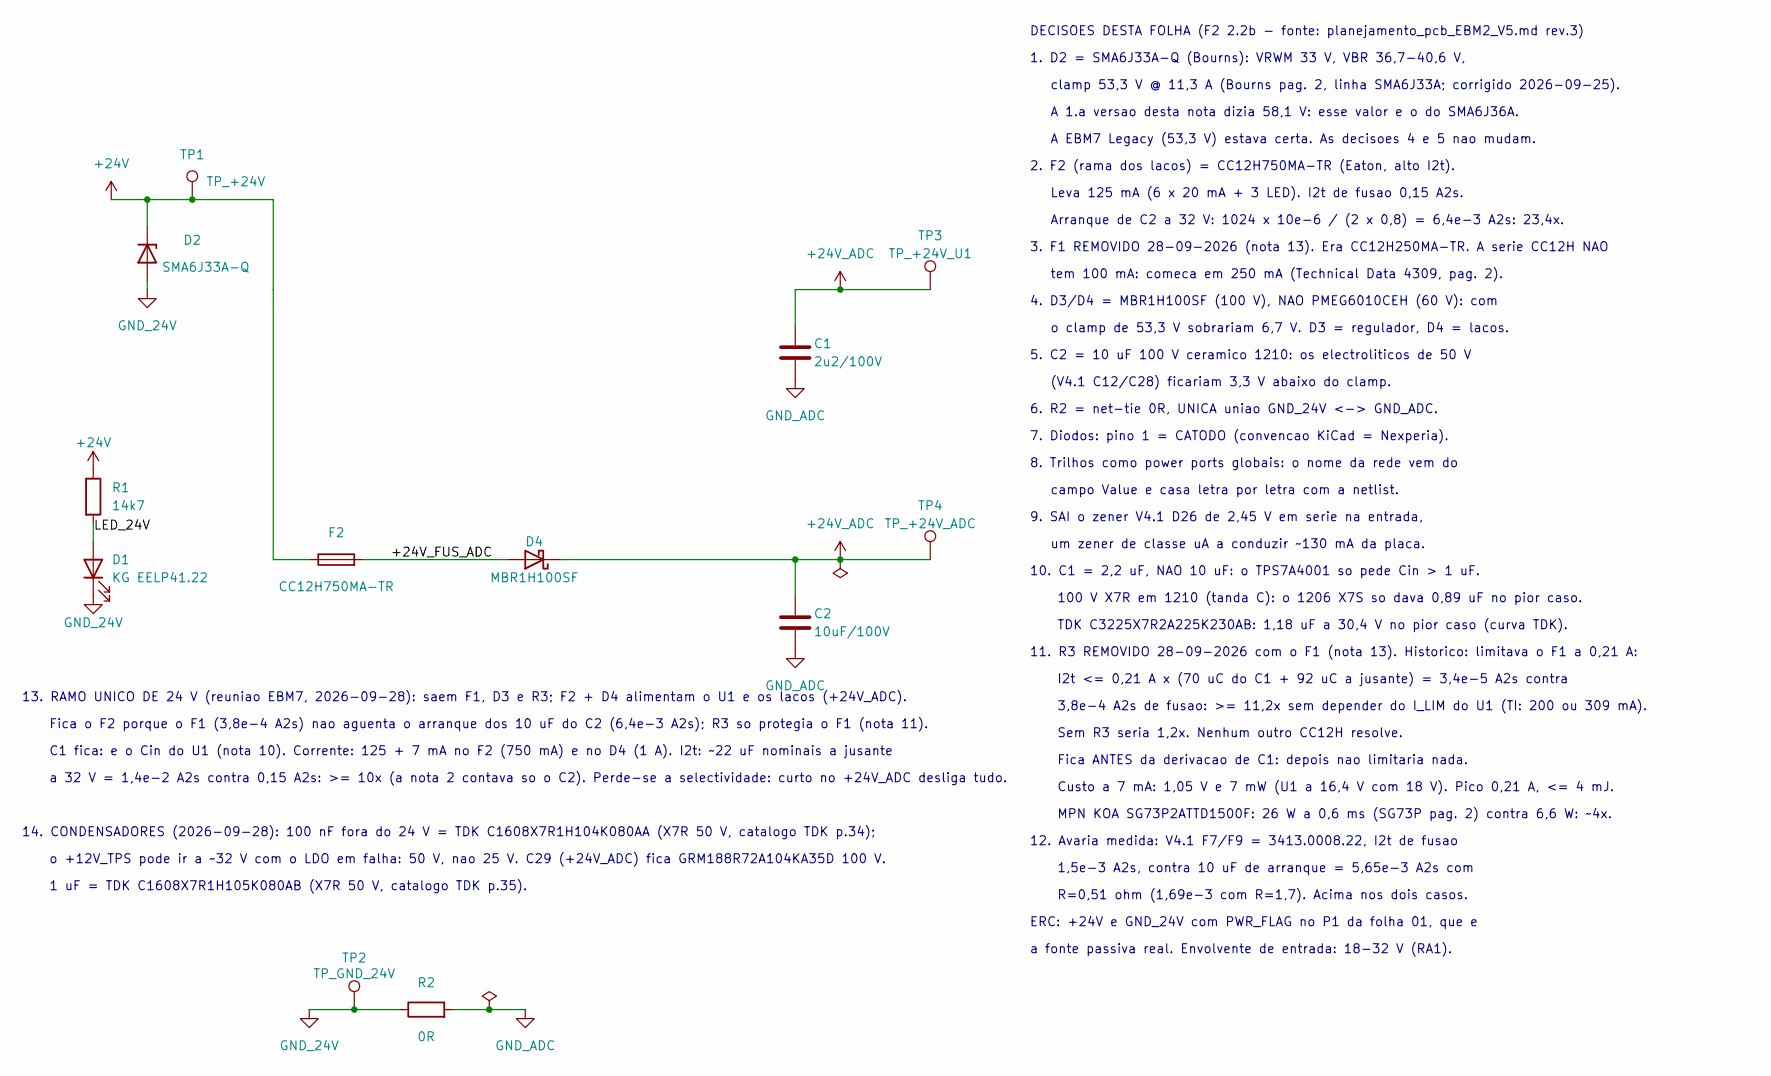
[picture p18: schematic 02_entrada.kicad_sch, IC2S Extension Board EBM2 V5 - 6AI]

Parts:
C1: 2u2/100V; C_1210_3225Metric; MPN C3225X7R2A225K230AB
C2: 10uF/100V; C_1210_3225Metric; MPN GRM32EC72A106ME05L
D1: KG EELP41.22; 0603LED; MPN KG EELP41.22-PHRH-35-A8J8-20-R18
D2: SMA6J33A-Q; DO-214; MPN SMA6J33A-Q
D4: MBR1H100SF; SOD123; MPN MBR1H100SFT3G
F2: CC12H750MA-TR; 1206F; MPN CC12H750MA-TR
R1: 14k7; 0603R; MPN ERJ-3EKF1472V
R2: 0R; 0603R; MPN RC0603JR-070RL
TP1: TP_+24V; TestPad_Via
TP2: TP_GND_24V; TestPad_Via
TP3: TP_+24V_U1; TestPad_Via
TP4: TP_+24V_ADC; TestPad_Via

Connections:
+24V: D2.1 (K), F2.1, R1.1, TP1.1; also elsewhere on the board
+24V_ADC: C1.1, C2.1, D4.1 (K), TP3.1, TP4.1; also elsewhere on the board
/2 Entrada/+24V_FUS_ADC: D4.2 (A), F2.2
/2 Entrada/LED_24V: D1.2 (A), R1.2
GND_24V: D1.1 (K), D2.2 (A), R2.1, TP2.1; also elsewhere on the board
GND_ADC: C1.2, C2.2, R2.2; also elsewhere on the board

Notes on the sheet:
Fica ANTES da derivacao de C1: depois nao limitaria nada.
TDK C3225X7R2A225K230AB: 1,18 uF a 30,4 V no pior caso (curva TDK).
Sem R3 seria 1,2x. Nenhum outro CC12H resolve.
5. C2 = 10 uF 100 V ceramico 1210: os electroliticos de 50 V
8. Trilhos como power ports globais: o nome da rede vem do
MPN KOA SG73P2ATTD1500F: 26 W a 0,6 ms (SG73P pag. 2) contra 6,6 W: ~4x.
A EBM7 Legacy (53,3 V) estava certa. As decisoes 4 e 5 nao mudam.
1,5e-3 A2s, contra 10 uF de arranque = 5,65e-3 A2s com
7. Diodos: pino 1 = CATODO (convencao KiCad = Nexperia).
A 1.a versao desta nota dizia 58,1 V: esse valor e o do SMA6J36A.
campo Value e casa letra por letra com a netlist.
Custo a 7 mA: 1,05 V e 7 mW (U1 a 16,4 V com 18 V). Pico 0,21 A, <= 4 mJ.
2. F2 (rama dos lacos) = CC12H750MA-TR (Eaton, alto I2t).
100 V X7R em 1210 (tanda C): o 1206 X7S so dava 0,89 uF no pior caso.
Arranque de C2 a 32 V: 1024 x 10e-6 / (2 x 0,8) = 6,4e-3 A2s: 23,4x.
a fonte passiva real. Envolvente de entrada: 18-32 V (RA1).
(V4.1 C12/C28) ficariam 3,3 V abaixo do clamp.
1. D2 = SMA6J33A-Q (Bourns): VRWM 33 V, VBR 36,7-40,6 V,
tem 100 mA: comeca em 250 mA (Technical Data 4309, pag. 2).
R=0,51 ohm (1,69e-3 com R=1,7). Acima nos dois casos.
um zener de classe uA a conduzir ~130 mA da placa.
12. Avaria medida: V4.1 F7/F9 = 3413.0008.22, I2t de fusao
11. R3 REMOVIDO 28-09-2026 com o F1 (nota 13). Historico: limitava o F1 a 0,21 A:
4. D3/D4 = MBR1H100SF (100 V), NAO PMEG6010CEH (60 V): com
ERC: +24V e GND_24V com PWR_FLAG no P1 da folha 01, que e
9. SAI o zener V4.1 D26 de 2,45 V em serie na entrada,
3,8e-4 A2s de fusao: >= 11,2x sem depender do I_LIM do U1 (TI: 200 ou 309 mA).
Leva 125 mA (6 x 20 mA + 3 LED). I2t de fusao 0,15 A2s.
o clamp de 53,3 V sobrariam 6,7 V. D3 = regulador, D4 = lacos.
clamp 53,3 V @ 11,3 A (Bourns pag. 2, linha SMA6J33A; corrigido 2026-09-25).
DECISOES DESTA FOLHA (F2 2.2b - fonte: planejamento_pcb_EBM2_V5.md rev.3)
I2t <= 0,21 A x (70 uC do C1 + 92 uC a jusante) = 3,4e-5 A2s contra
3. F1 REMOVIDO 28-09-2026 (nota 13). Era CC12H250MA-TR. A serie CC12H NAO
6. R2 = net-tie 0R, UNICA uniao GND_24V <-> GND_ADC.
10. C1 = 2,2 uF, NAO 10 uF: o TPS7A4001 so pede Cin > 1 uF.
13. RAMO UNICO DE 24 V (reuniao EBM7, 2026-09-28): saem F1, D3 e R3; F2 + D4 alimentam o U1 e os lacos (+24V_ADC).
Fica o F2 porque o F1 (3,8e-4 A2s) nao aguenta o arranque dos 10 uF do C2 (6,4e-3 A2s); R3 so protegia o F1 (nota 11).
C1 fica: e o Cin do U1 (nota 10). Corrente: 125 + 7 mA no F2 (750 mA) e no D4 (1 A). I2t: ~22 uF nominais a jusante
a 32 V = 1,4e-2 A2s contra 0,15 A2s: >= 10x (a nota 2 contava so o C2). Perde-se a selectividade: curto no +24V_ADC desliga tudo.
14. CONDENSADORES (2026-09-28): 100 nF fora do 24 V = TDK C1608X7R1H104K080AA (X7R 50 V, catalogo TDK p.34);

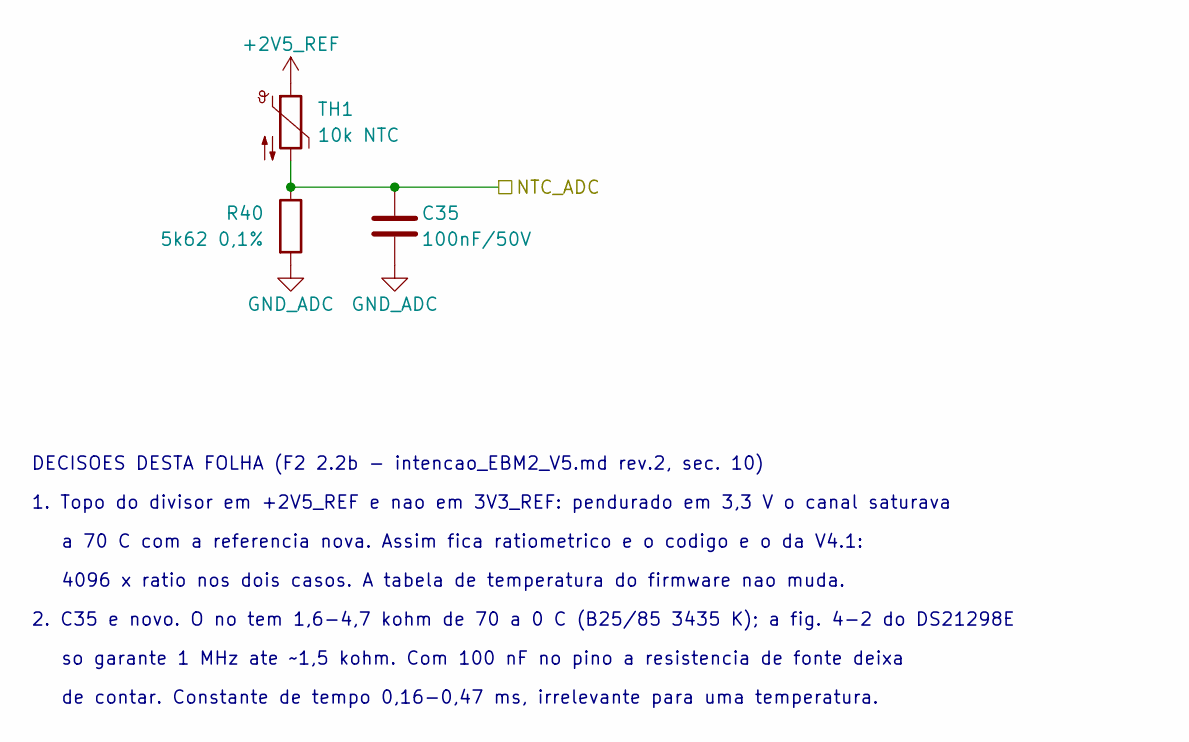
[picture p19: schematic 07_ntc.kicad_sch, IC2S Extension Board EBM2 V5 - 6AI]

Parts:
C35: 100nF/50V; 0603C; MPN C1608X7R1H104K080AA
R40: 5k62 0,1%; 0603R; MPN ERA3AEB5621V
TH1: 10k NTC; 0603R; MPN NTCS0603E3103JLT

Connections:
+2V5_REF: TH1.1; also elsewhere on the board
/5 ADC/NTC_ADC: C35.1, R40.1, TH1.2; also elsewhere on the board
GND_ADC: C35.2, R40.2; also elsewhere on the board

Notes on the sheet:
DECISOES DESTA FOLHA (F2 2.2b - intencao_EBM2_V5.md rev.2, sec. 10)
1. Topo do divisor em +2V5_REF e nao em 3V3_REF: pendurado em 3,3 V o canal saturava
a 70 C com a referencia nova. Assim fica ratiometrico e o codigo e o da V4.1:
4096 x ratio nos dois casos. A tabela de temperatura do firmware nao muda.
2. C35 e novo. O no tem 1,6-4,7 kohm de 70 a 0 C (B25/85 3435 K); a fig. 4-2 do DS21298E
so garante 1 MHz ate ~1,5 kohm. Com 100 nF no pino a resistencia de fonte deixa
de contar. Constante de tempo 0,16-0,47 ms, irrelevante para uma temperatura.

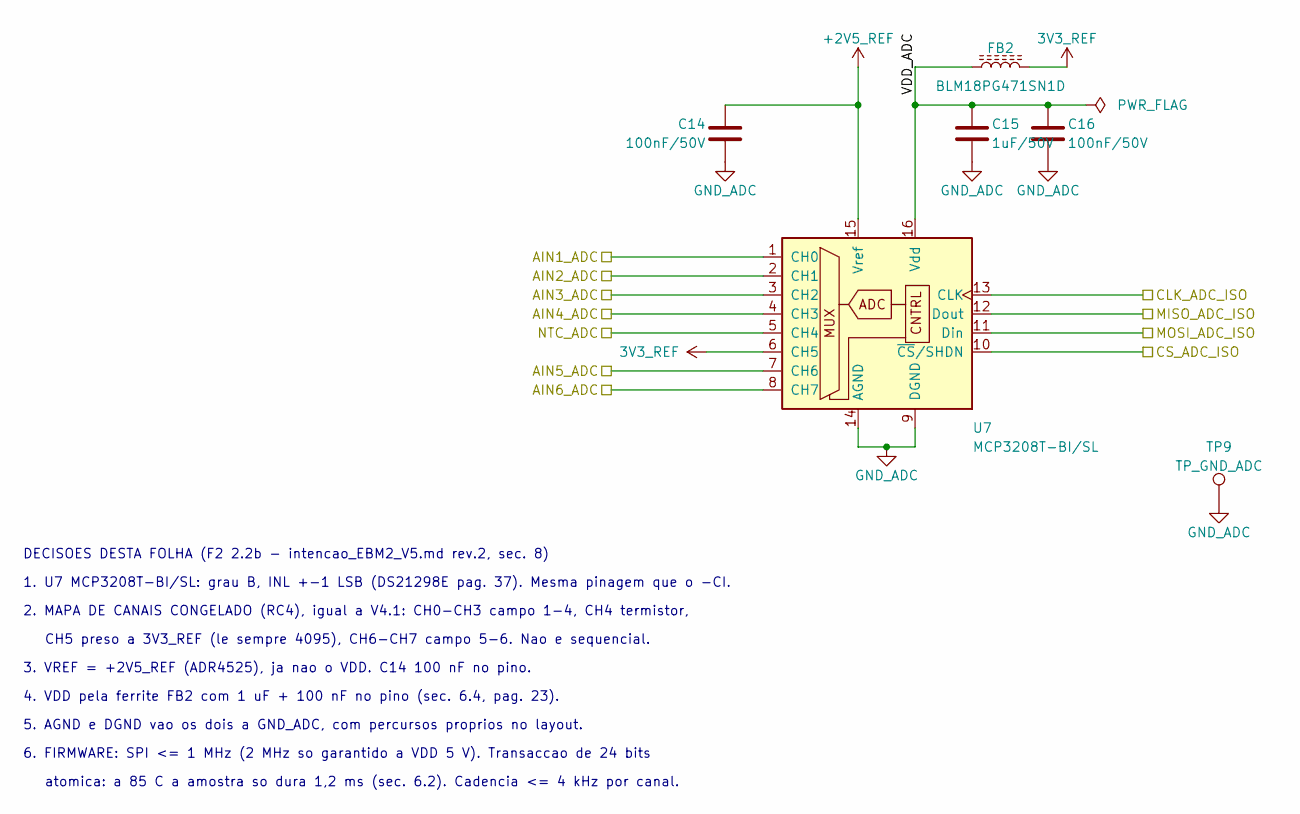
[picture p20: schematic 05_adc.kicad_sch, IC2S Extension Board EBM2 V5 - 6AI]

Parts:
C14, C16: 100nF/50V; 0603C; MPN C1608X7R1H104K080AA
C15: 1uF/50V; 0603C; MPN C1608X7R1H105K080AB
FB2: BLM18PG471SN1D; 0603FB; MPN BLM18PG471SN1D
TP9: TP_GND_ADC; TestPad_Via
U7: MCP3208T-BI/SL; SOIC16; MPN MCP3208T-BI/SL

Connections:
3V3_REF: FB2.2, U7.6 (CH5); also elsewhere on the board
+2V5_REF: C14.1, U7.15 (Vref); also elsewhere on the board
/4 Barreira digital/CLK_ADC_ISO: U7.13 (CLK); also elsewhere on the board
/4 Barreira digital/CS_ADC_ISO: U7.10 (~CS/SHDN); also elsewhere on the board
/4 Barreira digital/MISO_ADC_ISO: U7.12 (Dout); also elsewhere on the board
/4 Barreira digital/MOSI_ADC_ISO: U7.11 (Din); also elsewhere on the board
/5 ADC/AIN1_ADC: U7.1 (CH0); also elsewhere on the board
/5 ADC/AIN2_ADC: U7.2 (CH1); also elsewhere on the board
/5 ADC/AIN3_ADC: U7.3 (CH2); also elsewhere on the board
/5 ADC/AIN4_ADC: U7.4 (CH3); also elsewhere on the board
/5 ADC/AIN5_ADC: U7.7 (CH6); also elsewhere on the board
/5 ADC/AIN6_ADC: U7.8 (CH7); also elsewhere on the board
/5 ADC/NTC_ADC: U7.5 (CH4); also elsewhere on the board
/5 ADC/VDD_ADC: C15.1, C16.1, FB2.1, U7.16 (Vdd)
GND_ADC: C14.2, C15.2, C16.2, TP9.1, U7.9 (DGND), U7.14 (AGND); also elsewhere on the board

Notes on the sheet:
DECISOES DESTA FOLHA (F2 2.2b - intencao_EBM2_V5.md rev.2, sec. 8)
1. U7 MCP3208T-BI/SL: grau B, INL +-1 LSB (DS21298E pag. 37). Mesma pinagem que o -CI.
2. MAPA DE CANAIS CONGELADO (RC4), igual a V4.1: CH0-CH3 campo 1-4, CH4 termistor,
CH5 preso a 3V3_REF (le sempre 4095), CH6-CH7 campo 5-6. Nao e sequencial.
3. VREF = +2V5_REF (ADR4525), ja nao o VDD. C14 100 nF no pino.
4. VDD pela ferrite FB2 com 1 uF + 100 nF no pino (sec. 6.4, pag. 23).
5. AGND e DGND vao os dois a GND_ADC, com percursos proprios no layout.
6. FIRMWARE: SPI <= 1 MHz (2 MHz so garantido a VDD 5 V). Transaccao de 24 bits
atomica: a 85 C a amostra so dura 1,2 ms (sec. 6.2). Cadencia <= 4 kHz por canal.

Board: 4 copper layers, 138 parts (2 on the bottom side), 67 nets, no tracks yet.

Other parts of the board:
H1, H2: MountingHole_3.2mm_Pad6.0

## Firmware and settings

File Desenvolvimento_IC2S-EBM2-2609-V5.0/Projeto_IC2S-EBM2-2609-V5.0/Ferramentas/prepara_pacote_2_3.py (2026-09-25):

# -*- coding: utf-8 -*-
"""Prepara o pacote da etapa 2.3 (verificacao de pinagem, sessao independente).

Tudo sai dos ficheiros: a netlist exportada agora (com o nome de cada pino no simbolo), os
.kicad_sch (lib_id e folha), as pegadas do projecto (ilhas) e datasheets escolhidos PELO
CONTEUDO (localiza_datasheets.py + revisao manual). Nada de conclusoes da sessao de autoria:
o pacote diz o que conferir, nao o que se espera encontrar.

Uso: python prepara_pacote_2_3.py
"""
import glob, hashlib, io, os, re, shutil, subprocess, sys
from netlist_diff import parse, filhos, val

RAIZ = r"C:\hw\hw-ebm2-v5"
KI = os.path.join(RAIZ, "KiCad_EBM2_V5")
OUT = os.path.join(RAIZ, "Documentos", "verificacao_2_3")
CLI = r"C:\Program Files\KiCad\10.0\bin\kicad-cli.exe"
SCR = os.path.expanduser(r"~\.claude\projects\C--Users-Javier-Rivadineira\18536fc6-f453-4a6a-97aa-db52eff44a3a\tool-results")
EBM7REF = glob.glob(r"C:\hw\hw-ebm7-v2.2\Desenvolvimento_IC2S-EBM7-2608-V2.2\Projeto_IC2S-EBM7-2608-V2.2\Documentos_de_Refer*")[0]
DOWN = os.path.expanduser(r"~\Downloads")
DS_TMP = r"C:\Users\JAVIER~1\AppData\Local\Temp\claude\C--Users-Javier-Rivadineira\18536fc6-f453-4a6a-97aa-db52eff44a3a\scratchpad\ds"

# datasheet escolhido para cada familia: (ficheiro de origem, texto que TEM de estar na 1.a pagina)
DS = {
    "TPS7A4001": (os.path.join(EBM7REF, "TI_TPS7A4001.pdf"), "TPS7A4001"),
    "SPX3819": (None, "SPX3819"),                      # procurado abaixo (1016_SPX3819.pdf)
    "ADR4525": (os.path.join(DOWN, "adr4520_4525_4530_4533_4540_4550.pdf"), "ADR4525"),
    "TL431": (os.path.join(EBM7REF, "TI_TL431.pdf"), "TL431"),
    "ISO7141": (os.path.join(EBM7REF, "TI_ISO7141CC.pdf"), "ISO7141"),
    "MCP1824": (os.path.join(EBM7REF, "22070a.pdf"), "MCP1824"),
    "MCP3208": (os.path.join(DOWN, "21298e.pdf"), "MCP3208"),
    "AL5809": (os.path.join(DOWN, "AL5809.pdf"), "AL5809"),
    "SMA6J33A": (None, "SMA6J"),                       # Bourns_SMA6J33A-Q.pdf
    "MBR1H100SF": (os.path.join(SCR, "webfetch-1790203902626-3ncrcx.pdf"), "MBR1H100"),
    "824520361": (os.path.join(EBM7REF, "Wurth_824520361_SMBJ36A_DO-214AA.pdf"), "824520361"),
    "BAV199": (None, "BAV199"),                        # BAV199LT1-D.PDF
    "BAT46W": (os.path.join(SCR, "webfetch-1790247975568-happxg.pdf"), "BAT46W"),        # Diodes DS30044 (BAT46W-7-F)
    "KG EELP41.22": (os.path.join(DS_TMP, "KG-EELP41-22.pdf"), "EELP41"),
    "Harwin M20-782": (None, "M20-78"),                # Harwin_M20-782_plano.pdf
}
POR_NOME = {"SPX3819": "1016_SPX3819.pdf", "SMA6J33A": "Bourns_SMA6J33A-Q.pdf", "BAV199": "BAV199LT1-D.PDF",
            "Harwin M20-782": "Harwin_M20-782_plano.pdf"}

# que datasheet serve cada referencia (pelo MPN/valor da netlist)
def familia(v, mpn):
    s = (mpn or v or "").upper()
    for k, pat in (("TPS7A4001", "TPS7A4001"), ("SPX3819", "SPX3819"), ("ADR4525", "ADR4525"), ("TL431", "TL431"),
                   ("ISO7141", "ISO7141"), ("MCP1824", "MCP1824"), ("MCP3208", "MCP3208"), ("AL5809", "AL5809"),
                   ("SMA6J33A", "SMA6J33A"), ("MBR1H100SF", "MBR1H100"), ("824520361", "824520361"),
                   ("BAV199", "BAV199"), ("BAT46W", "BAT46W"), ("KG EELP41.22", "EELP41"), ("Harwin M20-782", "M20-782")):
        if pat in s:
            return k
    return None


def md5(f):
    return hashlib.md5(open(f, "rb").read()).hexdigest()[:12]


def main():
    import fitz
    os.makedirs(os.path.join(OUT, "datasheets"), exist_ok=True)
    # ---------------------------------------------------------------- datasheets, conferidos pelo conteudo
    achados = {}
    for k, (f, txt) in DS.items():
        if f is None:
            cand = [g for g in glob.glob(os.path.join(r"C:\hw", "**", POR_NOME[k]), recursive=True)]
            f = cand[0] if cand else None
        if not f or not os.path.exists(f):
            achados[k] = None; continue
        t = " ".join(fitz.open(f)[0].get_text().split())
        if txt not in t and txt.upper() not in t.upper():
            t2 = " ".join(" ".join(p.get_text() for p in list(fitz.open(f))[:3]).split())
            if txt.upper() not in t2.upper():
                sys.exit("ABORTA: %s nao contem %r: %s" % (k, txt, f))
        dst = os.path.join(OUT, "datasheets", re.sub(r"[^\w.-]", "_", k) + "__" + os.path.basename(f).replace("webfetch-", "fetch-"))
        shutil.copy2(f, dst)
        achados[k] = (os.path.basename(dst), md5(dst), fitz.open(dst).page_count, f)
    # ---------------------------------------------------------------- netlist nova, com nomes de pino
    net = os.path.join(OUT, "EBM2_V5.net")
    subprocess.run([CLI, "sch", "export", "netlist", "-o", net, os.path.join(KI, "IC2S_Extension_Board-EBM2_V5.kicad_sch")], capture_output=True)
    pdf = os.path.join(OUT, "esquematico_EBM2_V5.pdf")
    subprocess.run([CLI, "sch", "export", "pdf", "-o", pdf, os.path.join(KI, "IC2S_Extension_Board-EBM2_V5.kicad_sch")], capture_output=True)
    arv = parse(io.open(net, encoding="utf-8").read())
    comps = {}
    for sec in filhos(arv, "components"):
        for c in filhos(sec, "comp"):
            ref = val(c, "ref"); mpn = None
            for fs in filhos(c, "fields"):
                for fd in filhos(fs, "field"):
                    if val(fd, "name") == "MPN" and isinstance(fd[-1], str) and fd[-1] != "MPN": mpn = fd[-1]
            ls = filhos(c, "libsource")
            comps[ref] = dict(valor=val(c, "value"), pegada=val(c, "footprint"), mpn=mpn,
                              lib=("%s:%s" % (val(ls[0], "lib"), val(ls[0], "part"))) if ls else "?",
                              folha=(filhos(c, "sheetpath")[0][1][1] if filhos(c, "sheetpath") else "?"), pinos={})
    for sec in filhos(arv, "nets"):
        for r in filhos(sec, "net"):
            nome = val(r, "name")
            for nd in filhos(r, "node"):
                ref, pin = val(nd, "ref"), val(nd, "pin")
                if ref in comps:
                    comps[ref]["pinos"][pin] = (val(nd, "pinfunction") or "", val(nd, "pintype") or "", nome)
    alvo = sorted([r for r in comps if re.match(r"^(U|D|P)\d", r)], key=lambda z: (re.sub(r"\d", "", z), int(re.sub(r"\D", "", z))))
    # ---------------------------------------------------------------- pegadas: ilhas
    def ilhas(peg):
        lib, nome = peg.split(":")
        f = os.path.join(KI, "footprints", "EBM2_V5.pretty", nome + ".kicad_mod")
        if not os.path.exists(f): return "pegada nao encontrada em %s" % f, ""
        t = io.open(f, encoding="utf-8").read()
        d = re.search(r'\(descr "([^"]*)"', t)
        ps = re.findall(r'\(pad "([^"]+)" \w+ \w+\s+\(at ([-\d.]+) ([-\d.]+)(?: [-\d.]+)?\)\s+\(size ([\d.]+) ([\d.]+)\)', t)
        return ("; ".join("%s @(%s, %s) %sx%s" % p for p in ps), d.group(1) if d else "")
    # ---------------------------------------------------------------- inventario
    L = ["# Inventário de pinagem — EBM2 V5 (entrada da etapa 2.3)\n",
         "Gerado por `ferramentas/prepara_pacote_2_3.py` a partir da netlist exportada agora (`EBM2_V5.net`),",
         "das pegadas do projecto e dos datasheets desta pasta. **Não contém conclusões da sessão que desenhou.**\n",
         "Colunas por pino: número no símbolo → nome do pino no símbolo → tipo → rede. A verificação é conferir",
         "cada linha contra o datasheet (número, nome, função, direcção, nível) e a pegada contra o desenho do",
         "encapsulamento (ilha 1, marca de polaridade).\n"]
    grupos = {}
    for r in alvo:
        c = comps[r]
        chave = (c["lib"], c["valor"], c["pegada"], c["mpn"])
        grupos.setdefault(chave, []).append(r)
    for (lib, v, peg, mpn), refs in grupos.items():
        fam = familia(v, mpn)
        ds = achados.get(fam) if fam else None
        il, descr = ilhas(peg) if peg and ":" in peg else ("—", "")
        L.append("## %s — `%s` (%s)\n" % (", ".join(refs), mpn or v, v))
        L.append("- Símbolo: `%s` · Pegada: `%s` · Folha: `%s`" % (lib, peg, comps[refs[0]]["folha"]))
        L.append("- Datasheet: %s" % (("`datasheets/%s` (md5 %s, %d págs.)" % (ds[0], ds[1], ds[2])) if ds else "**FALTA — obter antes de concluir**"))
        L.append("- Ilhas da pegada: %s" % il)
        if descr: L.append("- Nota da pegada: %s" % descr)
        L.append("\n| Ref | Pino | Nome no símbolo | Tipo | Rede |\n|---|---|---|---|---|")
        for r in refs:
            for pin in sorted(comps[r]["pinos"], key=lambda z: (len(z), z)):
                pf, pt, nome = comps[r]["pinos"][pin]
                L.append("| %s | %s | %s | %s | `%s` |" % (r, pin, pf or "—", pt, nome))
        L.append("")
    io.open(os.path.join(OUT, "inventario_pinos_EBM2_V5.md"), "w", encoding="utf-8").write("\n".join(L) + "\n")
    # ---------------------------------------------------------------- lista de datasheets
    D = ["| Família | Ficheiro | md5 | Págs. | Origem |", "|---|---|---|---|---|"]
    for k, a in achados.items():
        D.append("| %s | %s | %s | %s | %s |" % (k, ("`%s`" % a[0]) if a else "**FALTA**", a[1] if a else "", a[2] if a else "", a[3] if a else ""))
    io.open(os.path.join(OUT, "datasheets", "LISTA.md"), "w", encoding="utf-8").write(
        "# Datasheets do pacote 2.3 — escolhidos pelo conteúdo, não pelo nome\n\n" + "\n".join(D) + "\n")
    shutil.copy2(os.path.join(RAIZ, "Documentos", "intencao_EBM2_V5.md"), os.path.join(OUT, "intencao_EBM2_V5.md"))
    print("componentes no inventario:", len(alvo), "em", len(grupos), "grupos | datasheets:",
          sum(1 for a in achados.values() if a), "de", len(achados), "| em falta:", [k for k, a in achados.items() if not a])


if __name__ == "__main__":
    main()

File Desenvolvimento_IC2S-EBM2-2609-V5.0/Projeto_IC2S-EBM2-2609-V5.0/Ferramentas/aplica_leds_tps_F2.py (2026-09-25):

# -*- coding: utf-8 -*-
"""F2 2.2b: acrescenta as pecas da intencao rev. 2 que faltam nas folhas 02 e 03.

  folha 02: T206 (+24V_ADC), T207 (+24V_REG), D203 + R207 14k7 (LED de +24V a GND_24V)
  folha 03: D204 + R208 2k2 (LED de +5V_ADC a GND_ADC)

As folhas 02 e 03 ja estao desenhadas e verificadas: aqui NAO se regeneram. Os itens
novos constroem-se com o Folha (mesmas regras de campo e de grelha) e enxertam-se
antes do fecho do ficheiro. O LED e a resistencia copiam o D630/R630 da folha 06
(mesma peca LG Q396-PS-35, mesma pegada 0603LED com pino 1 = catodo).
MPN dos passivos: os da V4.1 (R26 ERJ-3EKF1472V; R24 RC0603FR-072K2L).

Uso: python aplica_leds_tps_F2.py 02|03 [--aplicar]
"""
import io, os, re, shutil, sys
from construtor import Folha, blocos_lib_de_folha, bloco_lib_padrao, fim

P = r"C:\hw\hw-ebm2-v5\KiCad_EBM2_V5"
FICH = {"02": "02_entrada.kicad_sch", "03": "03_alimentacao.kicad_sch"}
UUID = {"02": "c2f29862-7f8d-4bfc-b53d-4b6e8f2da933"}
R, TP, LED = "Device:R", "Connector:TestPoint", "Device:LED"
UP, DOWN = "power:+24V", "power:GND"


def campos_rc(x, y):
    return dict(ref_pos=(x + 2.54, y - 1.27, 0, "left"), val_pos=(x + 2.54, y + 1.27, 0, "left"))


def tp(fo, ref, valor, x, y):
    fo.simbolo(TP, ref, valor, x, y, 0, pegada="EBM2_V5:TestPad_Via", mpn=None,
               ref_pos=(x, y - 7.62, 0, None), val_pos=(x, y - 5.08, 0, None))


def contexto(fo, pontos):
    """Pinos que JA existem na folha, so para a verificacao das ligacoes novas."""
    for i, (x, y) in enumerate(pontos):
        fo.portos.append(("existente%d" % i, x, y))


def folha02(fo):
    # T206 e T207 na ponta dos trilhos, a direita do porto e do PWR_FLAG que la estao.
    # A 151,13 o texto do ponto de prova fica fora do texto do porto (133,8-143,0 mm).
    for ref, val, y in (("T207", "TP_+24V_REG", 63.50), ("T206", "TP_+24V_ADC", 101.60)):
        contexto(fo, [(138.43, y), (138.43, y), (138.43, y)])     # fio que chega, porto, PWR_FLAG
        fo.fio((138.43, y), (151.13, y)); fo.juncao(138.43, y)
        tp(fo, ref, val, 151.13, y)
    # LED de entrada, com os seus proprios portos, no espaco livre a esquerda
    fo.porto("+24V", 33.02, 88.90, UP, base=220)
    fo.simbolo(R, "R207", "14k7", 33.02, 92.71, 0, pegada="EBM2_V5:0603R", mpn="ERJ-3EKF1472V",
               descr="LED de entrada, 1,5 mA (V4.1 R26)", **campos_rc(33.02, 92.71))
    fo.fio((33.02, 96.52), (33.02, 99.06))
    fo.rotulo("LED_24V", 33.02, 97.79)
    fo.simbolo(LED, "D203", "LG Q396-PS-35", 33.02, 102.87, 90, pegada="EBM2_V5:0603LED", mpn="LG Q396-PS-35",
               descr="Aceso = ha entrada de 24 V. Posicao fisica igual a V4.1 D25 (V11)", **campos_rc(33.02, 102.87))
    fo.porto("GND_24V", 33.02, 106.68, DOWN, base=220)


def folha03(fo):
    fo.porto("+5V_ADC", 25.40, 83.82, "power:+5V", base=320)
    fo.simbolo(R, "R208", "2k2", 25.40, 87.63, 0, pegada="EBM2_V5:0603R", mpn="RC0603FR-072K2L",
               descr="LED do +5V_ADC, 1,4 mA (V4.1 R24)", **campos_rc(25.40, 87.63))
    fo.fio((25.40, 91.44), (25.40, 93.98))
    fo.rotulo("LED_5V_ADC", 25.40, 92.71)
    fo.simbolo(LED, "D204", "LG Q396-PS-35", 25.40, 97.79, 90, pegada="EBM2_V5:0603LED", mpn="LG Q396-PS-35",
               descr="Aceso = F201 e regulador bem. Posicao fisica igual a V4.1 D18 (V11)", **campos_rc(25.40, 97.79))
    fo.porto("GND_ADC", 25.40, 101.60, DOWN, base=320)


def main():
    k = sys.argv[1]; aplicar = "--aplicar" in sys.argv
    alvo = os.path.join(P, FICH[k])
    t0 = io.open(alvo, encoding="utf-8").read()
    if "\r\n" in t0:
        sys.exit("ABORTA: o ficheiro tem CRLF; este enxerto escreve LF")
    if re.search(r'\(property "Reference" "(T206|T207|D203|R207|D204|R208)"', t0):
        sys.exit("ABORTA: a folha %s ja tem as pecas novas. Restaurar o .antes_leds antes de repetir." % k)
    fu = UUID.get(k) or re.search(r'\(path "/[^/]+/([^"]+)"', t0).group(1)
    libs = blocos_lib_de_folha(alvo)
    libs[LED] = bloco_lib_padrao("Device.kicad_sym", "LED", "Device")
    fo = Folha(alvo, fu, libs)
    (folha02 if k == "02" else folha03)(fo)
    erros = fo.verifica()
    if erros:
        print("verificacao das ligacoes novas:"); [print("   ", e) for e in erros]; sys.exit(1)

    # corpo novo: os itens que o Folha gerou, sem cabecalho nem lib_symbols
    inteiro = fo.texto_ficheiro([])
    a = inteiro.find("\n\t(lib_symbols"); b = fim(inteiro, a + 1)
    corpo = inteiro[b:inteiro.rindex("\n\t(embedded_fonts no)")]
    t = t0
    if '\t\t(symbol "Device:LED"' not in t:
        a = t.find("\n\t(lib_symbols"); b = fim(t, a + 1)
        fecho = t.rindex("\n\t)", a, b + 1)
        t = t[:fecho] + "\n" + libs[LED] + t[fecho:]
    # a folha 02 foi escrita a mao e fecha so com ")"; a 03 fecha com (embedded_fonts no)
    fecho = t.rfind("\n\t(embedded_fonts no)")
    if fecho < 0:
        fecho = t.rindex("\n)")
    t = t[:fecho] + corpo + t[fecho:]
    if k == "02":
        # notas 12,7 mm para a direita: o T207 e o T206 ocupam 144,8-157,5 mm
        t, n = re.subn(r'(\(text "[^"]*"\n\t\t\(exclude_from_sim no\)\n\t\t\(at )152\.4 ', r"\g<1>165.1 ", t)
        print("notas deslocadas:", n)
    novos = set(fo.guardas(t)) - set(fo.guardas(t0))
    if novos:
        print("GUARDAS NOVAS FALHADAS:"); [print("   ", e) for e in novos]; sys.exit(1)
    print("folha %s: %d simbolos novos, %d fios, %d juncoes, %d rotulos -> OK"
          % (k, len(fo.simbolos), len(fo.fios), len(fo.juncoes), len(fo.rotulos)))
    if aplicar:
        bak = alvo + ".antes_leds"
        if not os.path.exists(bak):
            shutil.copy2(alvo, bak)
        io.open(alvo, "w", encoding="utf-8", newline="").write(t)
        print("escrito:", FICH[k], "| backup:", os.path.basename(bak))


if __name__ == "__main__":
    main()

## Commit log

2026-09-25 EBM2 V5: projecto na organizacao de pastas de Produtos (Portao 1 aprovado, F3 em curso)
    Estrutura do modelo Axcel_Sensor / 00-TEMPLATE com o codigo IC2S-EBM2-2609-V5.0:
    projecto KiCad 10 (esquematico, PCB com contorno e placement inicial, bibliotecas proprias),
    ferramentas de verificacao, documentos da F2 e da F3, BOM preliminar e pacote do Portao 1.
    Datasheets dos fabricantes fora do repositorio publico (so a lista com md5).
    Claude-Session: https://claude.ai/code/session_01JSN664uQqiX1b8dVonNno5
    [01_conectores.kicad_sch, 02_entrada.kicad_sch, 03_alimentacao.kicad_sch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]
2026-09-28 Revisao de 28-09 (vinda da EBM7): ramo unico de 24 V, 100 nF a 50 V, um so MPN de 1 uF
    - Saem F1 (250 mA), D3 e R3: o F1 nao aguenta o arranque da placa toda e o R3
    so existia para o limitar. F2 + D4 alimentam o U1 e os lacos; +24V_REG passa
    a +24V_ADC. C1 fica (Cin do TPS7A4001). Esquematico e PCB (sem pistas).
    - 100 nF fora do 24 V -> TDK C1608X7R1H104K080AA (50 V); C29 (+24V_ADC) fica
    GRM188R72A104KA35D (100 V). 1 uF -> TDK C1608X7R1H105K080AB.
    - Folha 2 notas 3, 11, 13 e 14; BOM preliminar regenerada; README, registo e
    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
    [02_entrada.kicad_sch, 03_alimentacao.kicad_sch, 04_barreira.kicad_sch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]
2026-09-28 LDO 3,3 V do lado PLC: U5 MCP1824ST (SOT-223) -> MCP1824T-3302E/OT (SOT-23-5), mesmo MPN do U4
    - Criterio da equipa: menos MPN, mais pecas do mesmo tipo; o MCP1824ST sai.
    - SHDN a VIN, PG aberto; mesmo datasheet (DS22070A), estavel com ceramico >= 1 uF.
    - Esquematico: ERC 0; netlist so muda os pinos do U5. PCB: pegada SOT-23-5 no
    mesmo sitio; placa ainda sem pistas; nota 3 da folha 4 actualizada.
    - Registo: alteracao_LDO_3V3_lado_PLC_2026-09-28.md (comparacao, verificacao e
    riscos em aberto). BOM e PDF do esquematico regenerados.
    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
    [04_barreira.kicad_sch, IC2S_Extension_Board-EBM2_V5.kicad_pcb, bom_preliminar_EBM2_V5.csv]
2026-09-28 C10 (entrada do U5 MCP1824T) 1 uF -> 10 uF/50 V 1206, o datasheet pede 1-10 uF
    - DS22070A p.17: 'a typical input capacitance value of 1 uF to 10 uF'; o 1 uF/50 V dava
    0,80 uF a 5 V no pior caso. Novo: C3216X5R1H106K160AB, o mesmo de C4/C8/C31/C32
    (7,0 uF a 5 V). PCB: clone do C4 a 3,5 mm do U5.
    - ERC 0; DRC 0 erros, paridade 0. BOM preliminar e PDF regenerados.
    Claude-Session: https://claude.ai/code/session_01KPnkiJQKrkjgRqqw9M78ie
    [04_barreira.kicad_sch, IC2S_Extension_Board-EBM2_V5.kicad_pcb, bom_preliminar_EBM2_V5.csv]
